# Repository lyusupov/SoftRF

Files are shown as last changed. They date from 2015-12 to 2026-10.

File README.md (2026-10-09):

# SoftRF &nbsp;&nbsp;&nbsp;&nbsp;&nbsp; (https://old.mipt.ru/drec/events/radioDay)
[ ](https://github.com/lyusupov/SoftRF/releases)&nbsp;&nbsp;&nbsp;&nbsp;&nbsp;



DIY, multi-functional, compatible, sub-1 GHz ISM band radio based proximity awareness system for general aviation.

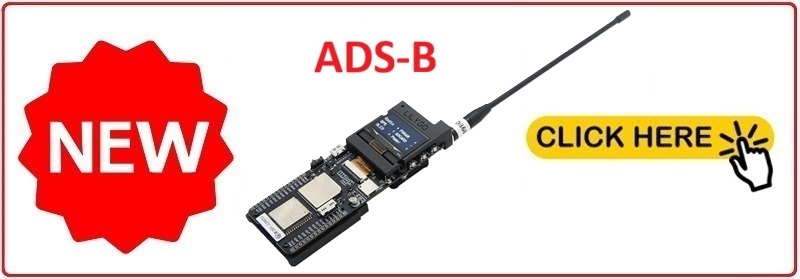
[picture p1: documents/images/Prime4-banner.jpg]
[](https://github.com/lyusupov/SoftRF/wiki/Prime-Edition-MkIV)
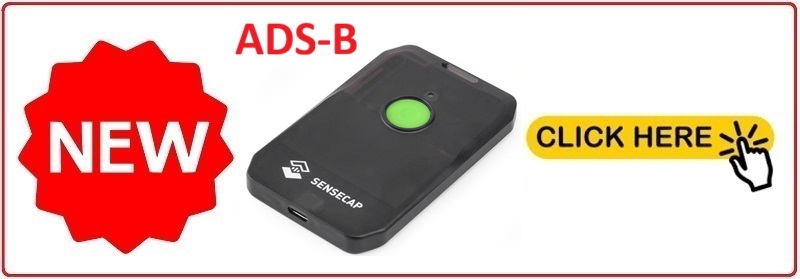
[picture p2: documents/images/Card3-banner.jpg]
[](https://github.com/lyusupov/SoftRF/wiki/Card-Edition-MkIII)
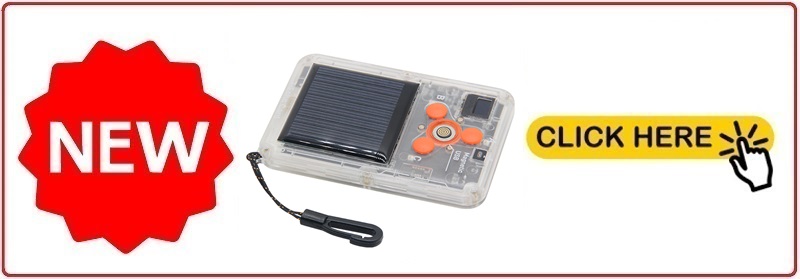
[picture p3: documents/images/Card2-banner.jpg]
[](https://github.com/lyusupov/SoftRF/wiki/Card-Edition-MkII)
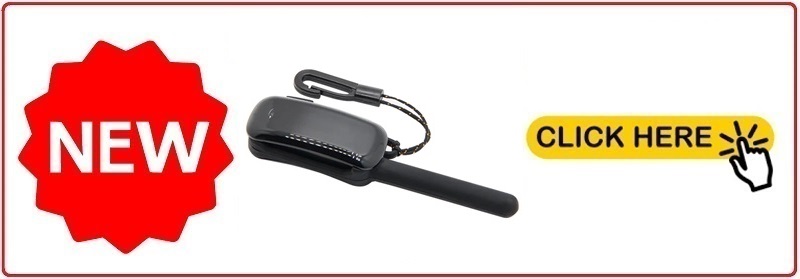
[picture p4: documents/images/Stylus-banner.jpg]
[](https://github.com/lyusupov/SoftRF/wiki/Stylus-Edition)
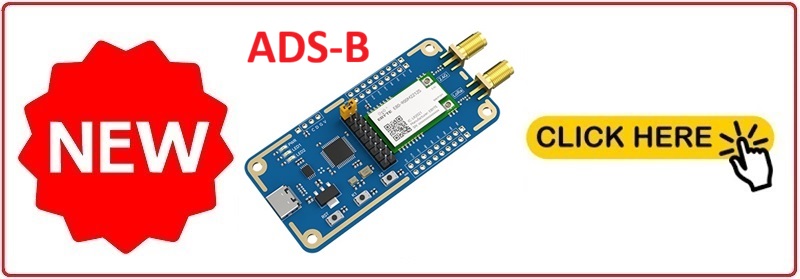
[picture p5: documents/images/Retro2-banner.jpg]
[](https://github.com/lyusupov/SoftRF/wiki/Retro-Edition-MkII)
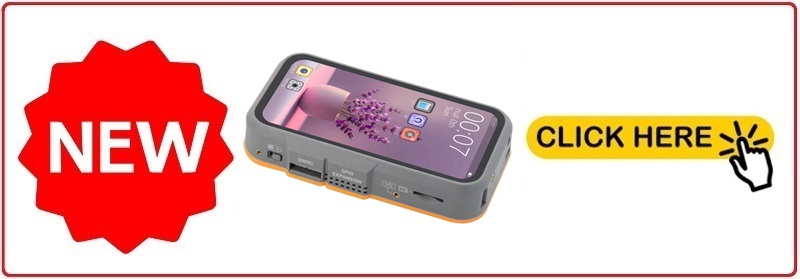
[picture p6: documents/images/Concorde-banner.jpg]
[](https://github.com/lyusupov/SoftRF/wiki/Concorde-Edition)
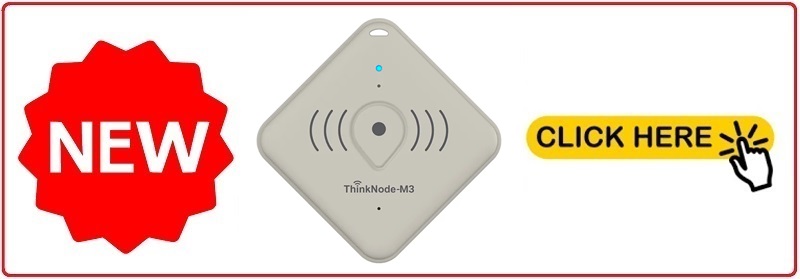
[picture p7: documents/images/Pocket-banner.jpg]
[](https://github.com/lyusupov/SoftRF/wiki/Pocket-Edition)<!--
[<img src="https://github.com/lyusupov/SoftRF/raw/master/documents/images/Airventure-banner.jpg">](https://github.com/lyusupov/SoftRF/wiki/Airventure-Edition)
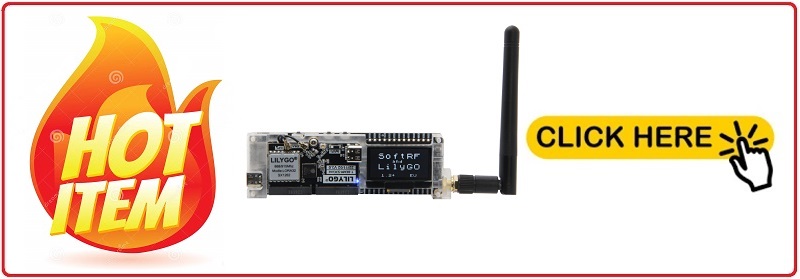
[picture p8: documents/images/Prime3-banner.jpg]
-->[](https://github.com/lyusupov/SoftRF/wiki/Prime-Edition-MkIII)
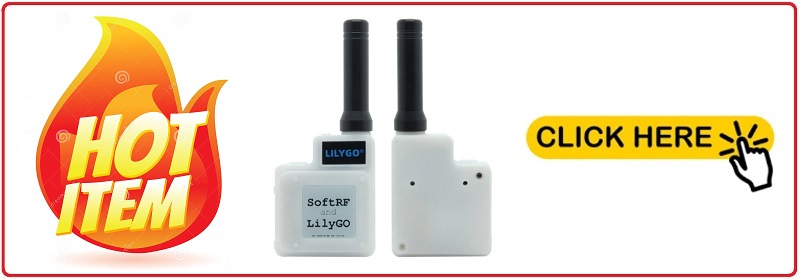
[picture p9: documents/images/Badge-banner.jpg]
[](https://github.com/lyusupov/SoftRF/wiki/Badge-Edition)<!--
[<img src="https://github.com/lyusupov/SoftRF/raw/master/documents/images/Card-banner.jpg">](https://github.com/lyusupov/SoftRF/wiki/Card-Edition)
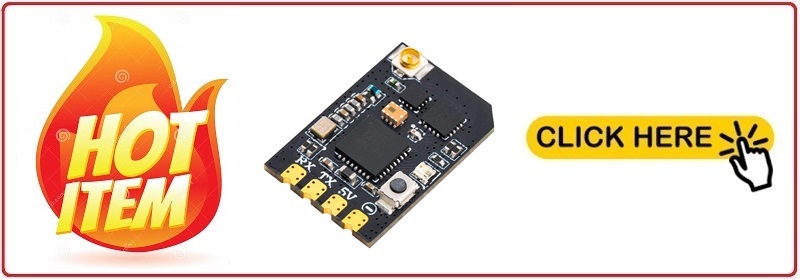
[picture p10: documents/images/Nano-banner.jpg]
-->[](https://github.com/lyusupov/SoftRF/wiki/Nano-Edition)

## Features

* **Wearable**
    * [**Badge Edition**](https://github.com/lyusupov/SoftRF/wiki/Badge-Edition)&nbsp;
    * [**Card  Mark III**](https://github.com/lyusupov/SoftRF/wiki/Card-Edition-MkIII)&nbsp;
    * [**Card  Mark II**](https://github.com/lyusupov/SoftRF/wiki/Card-Edition-MkII)&nbsp;
    * [**Card Edition**](https://github.com/lyusupov/SoftRF/wiki/Card-Edition)&nbsp;
    * [**Stylus Edition**](https://github.com/lyusupov/SoftRF/wiki/Stylus-Edition)&nbsp;
    * [**Pocket Edition**](https://github.com/lyusupov/SoftRF/wiki/Pocket-Edition)&nbsp;
    * [**Bracelet Edition**](https://github.com/lyusupov/SoftRF/wiki/Bracelet-Edition)
* **Plug-and-Play**
    * [**Dongle Edition**](https://github.com/lyusupov/SoftRF/wiki/Dongle-Edition) 
* **Portable**
    * [**Concorde Edition**](https://github.com/lyusupov/SoftRF/wiki/Concorde-Edition)&nbsp;
    * [**Airventure Edition**](https://github.com/lyusupov/SoftRF/wiki/Airventure-Edition)
    * [**Handheld Edition**](https://github.com/lyusupov/SoftRF/wiki/Handheld-Edition)
    * [**Gizmo Edition**](https://github.com/lyusupov/SoftRF/wiki/Gizmo-Edition)
    * [**Prime Mark IV**](https://github.com/lyusupov/SoftRF/wiki/Prime-Edition-MkIV) 
    * [**Prime Mark III**](https://github.com/lyusupov/SoftRF/wiki/Prime-Edition-MkIII) 
    * [**Prime Mark II**](https://github.com/lyusupov/SoftRF/wiki/Prime-Edition-MkII) 
* **Classic** 2.25 inch instrument
    * [**Standalone Edition**](https://github.com/lyusupov/SoftRF/wiki/Standalone-Edition) 
* **Wireless** 2.7 inch E-Ink **display**
    * [**SkyView Pico**](https://github.com/lyusupov/SoftRF/wiki/SkyView-Pico) 
    * [**SkyView EZ**](https://github.com/lyusupov/SoftRF/wiki/SkyView-EZ) 
* **Certified** (CE/FCC)
    * [**Badge Edition**](https://github.com/lyusupov/SoftRF/wiki/Badge-Edition)
    * [**Prime Mark III**](https://github.com/lyusupov/SoftRF/wiki/Prime-Edition-MkIII)
    * [**Card  Mark III**](https://github.com/lyusupov/SoftRF/wiki/Card-Edition-MkIII)&nbsp;
    * [**Solaris Edition**](https://github.com/lyusupov/SoftRF/wiki/Solaris-Edition)&nbsp;
    * [**Pocket Edition**](https://github.com/lyusupov/SoftRF/wiki/Pocket-Edition)&nbsp;
    * [**Handheld Edition**](https://github.com/lyusupov/SoftRF/wiki/Handheld-Edition)
    * [**Prime Mark II**](https://github.com/lyusupov/SoftRF/wiki/Prime-Edition-MkII)
    * [**Uni Edition**](https://github.com/lyusupov/SoftRF/wiki/Uni-Edition)
    * [**Mini Edition**](https://github.com/lyusupov/SoftRF/wiki/Mini-Edition)
    * [**Lego Edition**](https://github.com/lyusupov/SoftRF/wiki/Lego-Edition)
    * [**Balkan Edition**](https://github.com/lyusupov/SoftRF/wiki/Balkan-Edition)
    * [**Card Edition**](https://github.com/lyusupov/SoftRF/wiki/Card-Edition)
* can **receive ADS-B** air traffic
    * 978 UAT
        * [**Uni Edition**](https://github.com/lyusupov/SoftRF/wiki/Uni-Edition)
    * 1090 ES
        * [**ES Edition**](https://github.com/lyusupov/SoftRF/wiki/ES-Edition)
        * [**Concorde Edition**](https://github.com/lyusupov/SoftRF/wiki/Concorde-Edition)&nbsp;
        * [**Prime Mark IV**](https://github.com/lyusupov/SoftRF/wiki/Prime-Edition-MkIV) 
        * [**Card  Mark III**](https://github.com/lyusupov/SoftRF/wiki/Card-Edition-MkIII)&nbsp;
        * [**Retro Mark II**](https://github.com/lyusupov/SoftRF/wiki/Retro-Edition-MkII)&nbsp;
    * 1090 ES and/or 978 UAT
        * [**Raspberry Edition**](https://github.com/lyusupov/SoftRF/wiki/Raspberry-Edition)
* can operate **multiple protocols** at the same time
    * [**Octave Concept**](https://github.com/lyusupov/SoftRF/wiki/Octave-Concept)
    * [**Duo Concept**](https://github.com/lyusupov/SoftRF/wiki/Eco-Edition#duo-concept)
* has **flight recorder**
    * [**Prime Mark III**](https://github.com/lyusupov/SoftRF/wiki/Prime-Edition-MkIII) 
    * [**Flight Recorder**](https://github.com/lyusupov/SoftRF/wiki/Flight-Recorder)
* **Weatherproof**
    * [**Card  Mark III**](https://github.com/lyusupov/SoftRF/wiki/Card-Edition-MkIII)&nbsp; - IP66
    * [**Card  Mark II**](https://github.com/lyusupov/SoftRF/wiki/Card-Edition-MkII)&nbsp; - IP66
    * [**Card Edition**](https://github.com/lyusupov/SoftRF/wiki/Card-Edition)&nbsp; - IP65
    * [**Solaris Edition**](https://github.com/lyusupov/SoftRF/wiki/Solaris-Edition)&nbsp; - IP65
    * [**Pocket Edition**](https://github.com/lyusupov/SoftRF/wiki/Pocket-Edition)&nbsp; - IP66
    * [**Lego Edition**](https://github.com/lyusupov/SoftRF/wiki/Lego-Edition) - IP67
* **UAV** add-on
    * [**Nano Edition**](https://github.com/lyusupov/SoftRF/wiki/Nano-Edition)&nbsp;
    * [**UAV Edition**](https://github.com/lyusupov/SoftRF/wiki/UAV-Edition)
* Raspberry Pi **friendly**
    * [**Raspberry Edition**](https://github.com/lyusupov/SoftRF/wiki/Raspberry-Edition)
    * [**SkyView Pi**](https://github.com/lyusupov/SoftRF/wiki/SkyView-Pi)
* for **education** purpose
    * [**Academy Edition**](https://github.com/lyusupov/SoftRF/wiki/Academy-Edition) 
* for **amateur radio** operators
    * [**Ham Edition**](https://github.com/lyusupov/SoftRF/wiki/Ham-Edition)
* **made in** EU
    * [**Balkan Edition**](https://github.com/lyusupov/SoftRF/wiki/Balkan-Edition)

<br>

<!--
* 2-way raw data bridge between 868/915 MHz radio band and Wi-Fi ;
* standalone, battery powered, compatible proximity awareness instrument that fits typical 2.25 inches hole ;
* lightweight version to carry onboard of an UAV.
-->

<!--
[<img src="https://user-images.githubusercontent.com/5849637/128593239-cf30ef4c-1761-4dc1-874a-2be9eaacab77.jpg">](https://github.com/lyusupov/SoftRF/wiki/Badge-Edition)
-->

# Compatibility <sup>1</sup>
Type|Protocol|FLARM|OGN tracker|PilotAware|Skytraxx|SoftRF
---|---|---|---|---|---|---
Radio|FLARM AIR V7||||<p align="center"><sup>2</sup></p>|
&nbsp;|<p align="center">OGNTP</p>|||||<p align="center"><sup>3</sup></p>
&nbsp;|<p align="center">P3I</p>|||||<p align="center"><sup>3</sup></p>
&nbsp;|<p align="center">FANET+</p>|||||<p align="center"><sup>3</sup></p>
&nbsp;|<p align="center">978&nbsp;UAT<br>ADS-B</p>|||||<p align="center"><sup>4</sup></p>
&nbsp;|<p align="center">1090&nbsp;ES<br>ADS-B</p>|||<p align="center"><sup>5</sup></p>||<p align="center"><sup>5</sup></p>
&nbsp;|<p align="center">SRD&nbsp;860<br>ADS-L</p>|||||
&nbsp;|<p align="center">APRS</p>|||||<p align="center"><sup>6</sup></p>
&nbsp;|<p align="center">Remote ID</p>|||||<p align="center">
Data|FLARM NMEA|||||
&nbsp;|Garmin GDL90|||||
&nbsp;|<p align="center">MAVLINK</p>|||||
&nbsp;|<p align="center">Dump1090 &nbsp;<sup>7</sup></p>|||||

<sup>1</sup> - it is necessary for a reader to distinguish the difference between statement "**compatible**" and statement "**fully compatible**".<br>
&nbsp;&nbsp;&nbsp;&nbsp; SoftRF implements only a reasonable minimum of the protocols specs. No "bells and whistles" so far.<br>
<sup>2</sup> - FANET+ can not receive FLARM. However it is able to transmit it.<br>
<sup>3</sup> - valid for [**Prime Mark III**](https://github.com/lyusupov/SoftRF/wiki/Prime-Edition-MkIII) , [**Prime Mark II**](https://github.com/lyusupov/SoftRF/wiki/Prime-Edition-MkII) , [**Dongle**](https://github.com/lyusupov/SoftRF/wiki/Dongle-Edition) , [**Mini**](https://github.com/lyusupov/SoftRF/wiki/Mini-Edition) , [**Badge**](https://github.com/lyusupov/SoftRF/wiki/Badge-Edition) , [**Bracelet**](https://github.com/lyusupov/SoftRF/wiki/Bracelet-Edition) , [**Academy**](https://github.com/lyusupov/SoftRF/wiki/Academy-Edition) , [**Octave**](https://github.com/lyusupov/SoftRF/wiki/Octave-Concept) , [**Lego**](https://github.com/lyusupov/SoftRF/wiki/Lego-Edition) , [**Balkan**](https://github.com/lyusupov/SoftRF/wiki/Balkan-Edition) , [**Midi**](https://github.com/lyusupov/SoftRF/wiki/Midi-Edition) , [**Eco**](https://github.com/lyusupov/SoftRF/wiki/Eco-Edition) , [**Card**](https://github.com/lyusupov/SoftRF/wiki/Card-Edition) , [**Cozy**](https://github.com/lyusupov/SoftRF/wiki/Cozy-Edition) , [**Handheld**](https://github.com/lyusupov/SoftRF/wiki/Handheld-Edition) , [**Gizmo**](https://github.com/lyusupov/SoftRF/wiki/Gizmo-Edition) , [**Nano**](https://github.com/lyusupov/SoftRF/wiki/Nano-Edition) , [**Airventure**](https://github.com/lyusupov/SoftRF/wiki/Airventure-Edition) , [**Solaris**](https://github.com/lyusupov/SoftRF/wiki/Solaris-Edition) , [**Pocket**](https://github.com/lyusupov/SoftRF/wiki/Pocket-Edition) , [**Labubu**](https://github.com/lyusupov/SoftRF/wiki/Labubu-Edition) and [**Concorde**](https://github.com/lyusupov/SoftRF/wiki/Concorde-Edition) **Editions** ; valid for [**Standalone**](https://github.com/lyusupov/SoftRF/wiki/Standalone-Edition) , [**UAV**](https://github.com/lyusupov/SoftRF/wiki/UAV-Edition) and [**Uni**](https://github.com/lyusupov/SoftRF/wiki/Uni-Edition) **Editions** with optional DIY [SoftRF LoRa RF module](https://github.com/lyusupov/SoftRF/wiki/SoftRF-LoRa-module)<br>
<sup>4</sup> - [**Reception**](https://github.com/lyusupov/SoftRF/wiki/Uni-Edition#ads-b-out-remark) of traffic 'downlink' frames only. Valid for [**Uni Edition**](https://github.com/lyusupov/SoftRF/wiki/Uni-Edition) alone and for [**Standalone Edition**](https://github.com/lyusupov/SoftRF/wiki/Standalone-Edition) with optional DIY [SoftRF UAT module](https://github.com/lyusupov/UAT-test-signal#variant-2-advanced)<br>
<sup>5</sup> - Reception of traffic 'downlink' frames only. Valid for [**ES Edition**](https://github.com/lyusupov/SoftRF/wiki/ES-Edition)<br>
<sup>6</sup> - APRS is the only available with [**Ham Edition**](https://github.com/lyusupov/SoftRF/wiki/Ham-Edition)<br>
<sup>7</sup> - also known as "raw ADS-B"<br>

# Models
## By Processing Unit
Model(s)|Platform|First appearance|&nbsp;&nbsp;&nbsp;&nbsp;&nbsp;&nbsp;&nbsp;Status&nbsp;&nbsp;&nbsp;&nbsp;&nbsp;&nbsp;&nbsp;|Notes
---|:---:|:---:|:---:|---
1&nbsp;[Prime](https://github.com/lyusupov/SoftRF/wiki/Prime-Edition)<br>2&nbsp;[Standalone](https://github.com/lyusupov/SoftRF/wiki/Standalone-Edition)<br>3&nbsp;[UAV](https://github.com/lyusupov/SoftRF/wiki/UAV-Edition)<br>4&nbsp;[**WebTop&nbsp;Serial**](https://github.com/lyusupov/SoftRF/wiki/WebTop-Serial-adapter)|[Espressif<br>ESP8266](https://en.wikipedia.org/wiki/ESP8266)|Q4 2015|<!-- ![](https://via.placeholder.com/140x70/00A000/000000?text=Good) -->|[Prime](https://github.com/lyusupov/SoftRF/wiki/Prime-Edition) model is no longer supported - use [Prime MkII](https://github.com/lyusupov/SoftRF/wiki/Prime-Edition-MkII) instead.<br><!-- ESP8266 platform will be phased out through year 2020 in favour of ESP32.-->
1&nbsp;[**Prime Mark II**](https://github.com/lyusupov/SoftRF/wiki/Prime-Edition-MkII)<br>2&nbsp;[**Standalone**](https://github.com/lyusupov/SoftRF/wiki/Standalone-Edition) + [adapter](https://github.com/lyusupov/ESP32-NODEMCU-ADAPTER)<br>3&nbsp;[UAV](https://github.com/lyusupov/SoftRF/wiki/UAV-Edition)<br>4&nbsp;[**SkyView EZ**](https://github.com/lyusupov/SoftRF/wiki/SkyView-EZ)<br>5&nbsp;[Flight Recorder](https://github.com/lyusupov/SoftRF/wiki/Flight-Recorder)|[Espressif<br>ESP32](https://en.wikipedia.org/wiki/ESP32)|Q1 2018||1&nbsp;today's best platform ;<br>2&nbsp;holds [**FCC** mark](https://github.com/lyusupov/SoftRF/wiki/Prime-Edition-MkII#certificates)
1&nbsp;[**Raspberry Edition**](https://github.com/lyusupov/SoftRF/wiki/Raspberry-Edition)<br>2&nbsp;[**SkyView Pi**](https://github.com/lyusupov/SoftRF/wiki/SkyView-Pi)|[Broadcom<br>BCM283X<br>(Raspberry Pi)](https://en.wikipedia.org/wiki/Raspberry_Pi)|Q4 2018||Good for use together with RTL-SDR dongles to achieve additional 1090ES (and 978UAT) ADS-B air traffic reception.
[UAT module](https://github.com/lyusupov/UAT-test-signal#variant-2-advanced)|[Texas Instruments<br>CC1310](http://www.ti.com/product/CC1310)|Q1 2019|<!-- ![](https://via.placeholder.com/140x70/FFFF00/000000?text=In+progress) -->|Unique RF radio specs are useful for [UAT978 **ADS-B** reception](https://github.com/lyusupov/SoftRF/tree/master/software/firmware/source/UATbridge) [ [1](https://raw.githubusercontent.com/lyusupov/SoftRF/master/documents/images/uat-normal-7.jpg) , [2](https://raw.githubusercontent.com/lyusupov/SoftRF/master/documents/images/uat-normal-8.jpg) , [3](https://raw.githubusercontent.com/lyusupov/SoftRF/master/documents/images/uat-normal-6.jpg) ]
1&nbsp;[Retro](https://github.com/lyusupov/SoftRF/wiki/Retro-Edition)<br>2&nbsp;[**Dongle**](https://github.com/lyusupov/SoftRF/wiki/Dongle-Edition)<br>3&nbsp;[**Bracelet**](https://github.com/lyusupov/SoftRF/wiki/Bracelet-Edition)<br>4&nbsp;[**Retro Mark II**](https://github.com/lyusupov/SoftRF/wiki/Retro-Edition-MkII)&nbsp;|[STMicroelectronics](https://en.wikipedia.org/wiki/STMicroelectronics)<br>[STM32**F103**](https://www.st.com/en/microcontrollers-microprocessors/stm32f103.html) and<br>[STM32**L073**](https://www.st.com/en/microcontrollers-microprocessors/stm32l073rz.html)|Q3 2019|<!-- ![](https://via.placeholder.com/140x70/FFFF00/000000?text=In+progress)-->|<!-- [AcSiP **S76G**](http://www.acsip.com.tw/index.php?action=products-detail&fid1=19&fid2=&fid3=&id=41&lang=3) "3-in-1" system-in-package is doing good [ [1](https://raw.githubusercontent.com/lyusupov/SoftRF/master/documents/images/watch-1.jpg) , [2](https://raw.githubusercontent.com/lyusupov/SoftRF/master/documents/images/t-motion-4.jpg) , [3](https://raw.githubusercontent.com/lyusupov/SoftRF/master/documents/images/t-motion-5.jpg) ] .<br>As well as STM32F103C8 "**Blue Pill**" (same MCU that [STM32 OGN tracker](http://wiki.glidernet.org/stm32-ogn-tracker) uses) [ [4](https://raw.githubusercontent.com/lyusupov/SoftRF/master/documents/images/stm32_breadboard.jpg) , [5](https://raw.githubusercontent.com/lyusupov/SoftRF/master/documents/images/stm32_ognweb_1.JPG) ] . -->
[**Uni**](https://github.com/lyusupov/SoftRF/wiki/Uni-Edition)|[Texas Instruments<br>CC13x2R](http://www.ti.com/product/CC1352R)|Q2 2020|<!-- ![](https://via.placeholder.com/140x70/FFFF00/000000?text=In+progress) -->|1&nbsp;Unique RF radio specs are useful for UAT978 **ADS-B** reception ; <br>2&nbsp;holds [**FCC/CE** mark](https://github.com/lyusupov/SoftRF/wiki/Uni-Edition#certificates)
[**Mini**](https://github.com/lyusupov/SoftRF/wiki/Mini-Edition)|[Cypress<br>PSoC 4100**S**](https://en.wikipedia.org/wiki/Cypress_PSoC)|Q3 2020|<!-- ![](https://via.placeholder.com/140x40/c5f015/000000?text=May+need)<br>![](https://via.placeholder.com/140x40/c5f015/000000?text=improvements) -->|1&nbsp;good add-on candidate for modded Kobo e-Readers ;<br>2&nbsp;holds [**FCC/CE** mark](https://github.com/lyusupov/SoftRF/wiki/Mini-Edition#certificates)
1&nbsp;[**Badge**](https://github.com/lyusupov/SoftRF/wiki/Badge-Edition)<br>2&nbsp;[**Card**](https://github.com/lyusupov/SoftRF/wiki/Card-Edition)&nbsp;<br>3&nbsp;[**Cozy**](https://github.com/lyusupov/SoftRF/wiki/Cozy-Edition)<br>4&nbsp;[**Handheld**](https://github.com/lyusupov/SoftRF/wiki/Handheld-Edition)<br>5&nbsp;[**Solaris**](https://github.com/lyusupov/SoftRF/wiki/Solaris-Edition)&nbsp;<br>6&nbsp;[**Pocket**](https://github.com/lyusupov/SoftRF/wiki/Pocket-Edition)&nbsp;<br>7&nbsp;[**Card  Mark II**](https://github.com/lyusupov/SoftRF/wiki/Card-Edition-MkII)&nbsp;<br>8&nbsp;[**Card  Mark III**](https://github.com/lyusupov/SoftRF/wiki/Card-Edition-MkIII)&nbsp;<br>9&nbsp;[**Stylus**](https://github.com/lyusupov/SoftRF/wiki/Stylus-Edition)&nbsp;|[Nordic Semiconductor<br>nRF52840](https://www.nordicsemi.com/Products/Low-power-short-range-wireless/nRF52840)|Q4 2020||&nbsp;holds [**FCC/CE** mark](https://github.com/lyusupov/SoftRF/wiki/Badge-Edition#certificates)
[**ES**](https://github.com/lyusupov/SoftRF/wiki/ES-Edition)|[NXP Semiconductors<br>LPC4320](https://en.wikipedia.org/wiki/NXP_LPC#LPC4000_series)|Q2 2021||Unique RF radio specs are useful for 1090ES **ADS-B** reception [ [1](https://user-images.githubusercontent.com/5849637/140610617-7c74582e-b0d7-4610-8ac2-d51f55c9086d.png) , [2](https://raw.githubusercontent.com/lyusupov/SoftRF/master/documents/images/ES-1.jpg) ]
1&nbsp;[**Academy**](https://github.com/lyusupov/SoftRF/wiki/Academy-Edition)<br>2&nbsp;[USB2BT](https://github.com/lyusupov/SoftRF/wiki/USB-to-Bluetooth-adapter)|[Microchip&nbsp;(Atmel)<br>SAM&nbsp;D21](https://www.microchip.com/en-us/products/microcontrollers-and-microprocessors/32-bit-mcus/sam-32-bit-mcus/sam-d) <!-- and [ATmega2560](https://www.microchip.com/en-us/product/ATmega2560) -->|Q4 2021| <!-- ![](https://via.placeholder.com/140x40/c5f015/000000?text=May+need)<br>![](https://via.placeholder.com/140x40/c5f015/000000?text=improvements) -->|good for teaching students of air traffic proximity awareness
[**Octave**](https://github.com/lyusupov/SoftRF/wiki/Octave-Concept)|[ASR Microelectronics<br>ASR6601](https://asriot.readthedocs.io/en/latest/ASR6601/index.html)|Q1 2022|| **the best 'price per radio protocol' ratio** on the market
1&nbsp;[**Lego**](https://github.com/lyusupov/SoftRF/wiki/Lego-Edition)<br>2&nbsp;[**SkyView Pico**](https://github.com/lyusupov/SoftRF/wiki/SkyView-Pico)|[Raspberry Pi<br>Foundation<br>**RP2040**](https://en.wikipedia.org/wiki/RP2040)|Q1 2022||&nbsp;holds [**FCC/CE** mark](https://github.com/lyusupov/SoftRF/wiki/Lego-Edition#certificates)
[**Balkan**](https://github.com/lyusupov/SoftRF/wiki/Balkan-Edition)|[STMicroelectronics](https://en.wikipedia.org/wiki/STMicroelectronics)<br>[STM32**WLE5**](https://www.st.com/en/microcontrollers-microprocessors/stm32wle5cc.html)|Q3 2022||&nbsp;holds [**CE** mark](https://github.com/lyusupov/SoftRF/wiki/Balkan-Edition#certificates)
[**WebTop USB**](https://github.com/lyusupov/SoftRF/wiki/WebTop-USB)|[Espressif<br>ESP32-S2](https://en.wikipedia.org/wiki/ESP32#ESP32-S2)|Q4 2022||
1&nbsp;[**Standalone**](https://github.com/lyusupov/SoftRF/wiki/Standalone-Edition)&nbsp;**upgrade**<br>2&nbsp;[**Nano**](https://github.com/lyusupov/SoftRF/wiki/Nano-Edition)&nbsp;|[Espressif<br>ESP32-C3](https://en.wikipedia.org/wiki/ESP32#ESP32-C3)|Q1 2023||[RISC-V](https://en.wikipedia.org/wiki/RISC-V)
1&nbsp;[**Prime Mark III**](https://github.com/lyusupov/SoftRF/wiki/Prime-Edition-MkIII)&nbsp;<br>2&nbsp;[**SkyView Pico**](https://github.com/lyusupov/SoftRF/wiki/SkyView-Pico#alternative-hardware-option)<br>3&nbsp;[**Ham**](https://github.com/lyusupov/SoftRF/wiki/Ham-Edition)<br>4&nbsp;[**Midi**](https://github.com/lyusupov/SoftRF/wiki/Midi-Edition)<br>5&nbsp;[**Gizmo**](https://github.com/lyusupov/SoftRF/wiki/Gizmo-Edition)<br>6&nbsp;[**Airventure**](https://github.com/lyusupov/SoftRF/wiki/Airventure-Edition)<br>7&nbsp;[**Prime Mark IV**](https://github.com/lyusupov/SoftRF/wiki/Prime-Edition-MkIV)&nbsp;|[Espressif<br>ESP32-S3](https://en.wikipedia.org/wiki/ESP32#ESP32-S3)|Q1 2023||
1&nbsp;[**Standalone**](https://github.com/lyusupov/SoftRF/wiki/Standalone-Edition)&nbsp;**upgrade**<br>2&nbsp;[**Eco**](https://github.com/lyusupov/SoftRF/wiki/Eco-Edition)<br>3&nbsp;[**Duo**](https://github.com/lyusupov/SoftRF/wiki/Eco-Edition#duo-concept)|[Espressif<br>ESP32-C6](https://en.wikipedia.org/wiki/ESP32#ESP32-C6)|Q1 2024||2 [RISC-V](https://en.wikipedia.org/wiki/RISC-V) cores<br>big.LITTLE
[**Academy**](https://github.com/lyusupov/SoftRF/wiki/Academy-Edition)&nbsp; **upgrade**|[Renesas<br>RA4M1](https://en.wikipedia.org/wiki/Renesas_Electronics#The_RA_MCU_family)|Q1 2024||
Academy|[Silicon Labs](https://en.wikipedia.org/wiki/Silicon_Labs)<br>[EFx32](https://en.wikipedia.org/wiki/EFM32)|Q3 2024||
Academy|[Nanjing Qinheng Microelectronics](https://www.wch-ic.com/)<br>[CH32V307](https://www.wch-ic.com/products/CH32V307.html)|Q3 2024||[RISC-V](https://en.wikipedia.org/wiki/RISC-V)<br>IMAFC
1&nbsp;[**Standalone**](https://github.com/lyusupov/SoftRF/wiki/Standalone-Edition)&nbsp;**upgrade**<br>2&nbsp;[**SkyView Pico**](https://github.com/lyusupov/SoftRF/wiki/SkyView-Pico)&nbsp;|[Raspberry Pi<br>Foundation<br>**RP2350**](https://en.wikipedia.org/wiki/RP2350)|Q1 2025||
1&nbsp;[**Standalone**](https://github.com/lyusupov/SoftRF/wiki/Standalone-Edition)&nbsp;**upgrade**<br>2&nbsp;[**Lyra**](https://github.com/lyusupov/SoftRF/wiki/Lyra-Edition)&nbsp;|[Rockchip](https://en.wikipedia.org/wiki/Rockchip)<br>RK3506|Q3 2025||
[**Concorde**](https://github.com/lyusupov/SoftRF/wiki/Concorde-Edition)&nbsp;|[Espressif<br>ESP32-P4](https://en.wikipedia.org/wiki/ESP32#ESP32-P4)|Q3 2025||
**Academy**|[Espressif<br>ESP32-C5](https://en.wikipedia.org/wiki/ESP32#ESP32-C5)|Q3 2025||
[**Labubu**](https://github.com/lyusupov/SoftRF/wiki/Labubu-Edition)|[STMicroelectronics](https://en.wikipedia.org/wiki/STMicroelectronics)<br>[STM32**WL55**](https://www.st.com/en/microcontrollers-microprocessors/stm32wl55cc.html)|Q4 2025||
**Academy**|[Nordic Semiconductor<br>nRF54L15](https://www.nordicsemi.com/Products/nRF54L15)|Q1 2026||

## By sub-1 GHz radio
Radio|Model(s)|First appearance|&nbsp;&nbsp;&nbsp;&nbsp;&nbsp;&nbsp;&nbsp;Status&nbsp;&nbsp;&nbsp;&nbsp;&nbsp;&nbsp;&nbsp;|Notes
---|:---:|:---:|:---:|---
[Nordic Semiconductor<br>nRF905](https://infocenter.nordicsemi.com/pdf/nRF905_PS_v1.5.pdf)|1&nbsp;[Prime](https://github.com/lyusupov/SoftRF/wiki/Prime-Edition)<br>2&nbsp;[Standalone](https://github.com/lyusupov/SoftRF/wiki/Standalone-Edition)<br>3&nbsp;[UAV](https://github.com/lyusupov/SoftRF/wiki/UAV-Edition)|Q4 2015||&nbsp;
[Semtech<br>SX1276](https://www.semtech.com/products/wireless-rf/lora-transceivers/sx1276)|1&nbsp;[LoRa module](https://github.com/lyusupov/SoftRF/wiki/SoftRF-LoRa-module)<br>2&nbsp;[**Prime Mark II**](https://github.com/lyusupov/SoftRF/wiki/Prime-Edition-MkII)<br>3&nbsp;[**Raspberry Edition**](https://github.com/lyusupov/SoftRF/wiki/Raspberry-Edition)<br>4&nbsp;[**Dongle**](https://github.com/lyusupov/SoftRF/wiki/Dongle-Edition)<br>5&nbsp;[**Academy**](https://github.com/lyusupov/SoftRF/wiki/Academy-Edition)<!-- <br>5&nbsp;[**Bracelet**](https://github.com/lyusupov/SoftRF/wiki/Bracelet-Edition) -->|Q4 2017||&nbsp;
[Texas Instruments<br>CC1310](http://www.ti.com/product/CC1310)|[UAT module](https://github.com/lyusupov/UAT-test-signal#variant-2-advanced)|Q1 2019||&nbsp;
[Semtech<br>SX1231](https://www.semtech.com/products/wireless-rf/fsk-transceivers/sx1231)|[Retro](https://github.com/lyusupov/SoftRF/wiki/Retro-Edition)|Q3 2019||operates through OGN driver with OGNTP protocol only
[Semtech<br>SX1262](https://www.semtech.com/products/wireless-rf/lora-transceivers/sx1262)|1&nbsp;[**Prime Mark II**](https://github.com/lyusupov/SoftRF/wiki/Prime-Edition-MkII)<br>2&nbsp;[**Mini**](https://github.com/lyusupov/SoftRF/wiki/Mini-Edition)<br>3&nbsp;[**Badge**](https://github.com/lyusupov/SoftRF/wiki/Badge-Edition)<br>4&nbsp;[**Lego**](https://github.com/lyusupov/SoftRF/wiki/Lego-Edition)<br>5&nbsp;[**Balkan**](https://github.com/lyusupov/SoftRF/wiki/Balkan-Edition)<br>6&nbsp;[**Prime Mark III**](https://github.com/lyusupov/SoftRF/wiki/Prime-Edition-MkIII)<br>7&nbsp;[**Midi**](https://github.com/lyusupov/SoftRF/wiki/Midi-Edition)<br>8&nbsp;[**Cozy**](https://github.com/lyusupov/SoftRF/wiki/Cozy-Edition)<br>9&nbsp;[**Handheld**](https://github.com/lyusupov/SoftRF/wiki/Handheld-Edition)<br>10&nbsp;[**Gizmo**](https://github.com/lyusupov/SoftRF/wiki/Gizmo-Edition)<br>11&nbsp;[**Airventure**](https://github.com/lyusupov/SoftRF/wiki/Airventure-Edition)<br>12&nbsp;[**Lyra**](https://github.com/lyusupov/SoftRF/wiki/Lyra-Edition)&nbsp;<br>13&nbsp;[**Solaris**](https://github.com/lyusupov/SoftRF/wiki/Solaris-Edition)&nbsp;<br>14&nbsp;[**Concorde**](https://github.com/lyusupov/SoftRF/wiki/Concorde-Edition)&nbsp;<br>15&nbsp;[**Stylus**](https://github.com/lyusupov/SoftRF/wiki/Stylus-Edition)&nbsp;<br>16&nbsp;[**Card  Mark II**](https://github.com/lyusupov/SoftRF/wiki/Card-Edition-MkII)&nbsp;|Q1 2020||&nbsp;
[Texas Instruments<br>CC13x2R](http://www.ti.com/product/CC1352R)|[**Uni Edition**](https://github.com/lyusupov/SoftRF/wiki/Uni-Edition)|Q2 2020||&nbsp;
[Maxim Integrated](https://en.wikipedia.org/wiki/Maxim_Integrated)<br>[MAX2837](https://www.maximintegrated.com/en/products/comms/wireless-rf/MAX2837.html)&nbsp;and<br>[MAX5864](https://www.maximintegrated.com/en/products/analog/data-converters/analog-front-end-ics/MAX5864.html)|[**ES Edition**](https://github.com/lyusupov/SoftRF/wiki/ES-Edition)|Q2 2021||**S**oftware<br>**D**efined<br>**R**adio
[NiceRF](https://www.nicerf.com)<br>[SA868](https://www.nicerf.com/item/2w-embedded-walkie-talkie-module-sa868)|[**Ham Edition**](https://github.com/lyusupov/SoftRF/wiki/Ham-Edition)|Q3 2023||VHF or UHF "Ham Radio" bands
[Semtech<br>LR1110](https://www.semtech.com/products/wireless-rf/lora-edge/lr1110)|1&nbsp;[**Card**](https://github.com/lyusupov/SoftRF/wiki/Card-Edition)&nbsp;<br>2&nbsp;[**Pocket**](https://github.com/lyusupov/SoftRF/wiki/Pocket-Edition)&nbsp;|Q3 2024||&nbsp;
[Semtech<br>LR1121](https://www.semtech.com/products/wireless-rf/lora-connect/lr1121)&nbsp;|1&nbsp;[**Standalone**](https://github.com/lyusupov/SoftRF/wiki/Standalone-Edition)<br>2&nbsp;[**Prime Mark III**](https://github.com/lyusupov/SoftRF/wiki/Prime-Edition-MkIII)<br>3&nbsp;[**Nano**](https://github.com/lyusupov/SoftRF/wiki/Nano-Edition)&nbsp;|Q4 2024||2.1&nbsp;GHz&nbsp;S-band<br>2.4&nbsp;GHz&nbsp;ISM
Semtech&nbsp;SX1231<br><!--Semtech&nbsp;SX1280<br>-->TI&nbsp;CC1101<br>Silicon&nbsp;Labs&nbsp;Si4432<br>Silicon&nbsp;Labs&nbsp;Si4463|[**Standalone**](https://github.com/lyusupov/SoftRF/wiki/Standalone-Edition)|Q1 2025||&nbsp;
[Semtech<br>LR2021](https://www.semtech.com/products/wireless-rf/lora-plus/lr2021)&nbsp;|1&nbsp;[**Standalone**](https://github.com/lyusupov/SoftRF/wiki/Standalone-Edition)<br>2&nbsp;[**Retro Mark II**](https://github.com/lyusupov/SoftRF/wiki/Retro-Edition-MkII)&nbsp;<br>3&nbsp;[**Card  Mark III**](https://github.com/lyusupov/SoftRF/wiki/Card-Edition-MkIII)&nbsp;<br>4&nbsp;[**Prime Mark IV**](https://github.com/lyusupov/SoftRF/wiki/Prime-Edition-MkIV)&nbsp;|Q1 2026||[the radio can receive ADS-B @ 1090 MHz](https://github.com/lyusupov/SoftRF/wiki/SoftRF-LoRa-module#upgrade-with-most-recent-semtech-lr2021-radio)&nbsp;

## By GNSS chip
GNSS|Model(s)|First appearance|&nbsp;&nbsp;&nbsp;&nbsp;&nbsp;&nbsp;&nbsp;Status&nbsp;&nbsp;&nbsp;&nbsp;&nbsp;&nbsp;&nbsp;|Notes
---|:---:|:---:|:---:|---
Generic<br>NMEA|[Standalone](https://github.com/lyusupov/SoftRF/wiki/Standalone-Edition)|Q4 2016||&nbsp;
[U-blox](https://en.wikipedia.org/wiki/U-blox)<br>6/7/8/9/10|1&nbsp;[**Prime Mark II**](https://github.com/lyusupov/SoftRF/wiki/Prime-Edition-MkII)<br>2&nbsp;[Retro](https://github.com/lyusupov/SoftRF/wiki/Retro-Edition)<br>3&nbsp;[**Uni**](https://github.com/lyusupov/SoftRF/wiki/Uni-Edition)<br>4&nbsp;[**Lego**](https://github.com/lyusupov/SoftRF/wiki/Lego-Edition)<br>5&nbsp;[**Balkan**](https://github.com/lyusupov/SoftRF/wiki/Balkan-Edition)<br>6&nbsp;[**Prime Mark III**](https://github.com/lyusupov/SoftRF/wiki/Prime-Edition-MkIII)<br>7&nbsp;[**Stylus**](https://github.com/lyusupov/SoftRF/wiki/Stylus-Edition)&nbsp;|Q2 2018||&nbsp;
[Hangzhou ZhongKe](http://www.icofchina.com/)<br>AT6558|1&nbsp;[**Prime Mark II**](https://github.com/lyusupov/SoftRF/wiki/Prime-Edition-MkII)<br>2&nbsp;[**Mini**](https://github.com/lyusupov/SoftRF/wiki/Mini-Edition)<br>3&nbsp;[**Badge**](https://github.com/lyusupov/SoftRF/wiki/Badge-Edition)<br>4&nbsp;[**Prime Mark III**](https://github.com/lyusupov/SoftRF/wiki/Prime-Edition-MkIII)<br>5&nbsp;[**Ham**](https://github.com/lyusupov/SoftRF/wiki/Ham-Edition)<br>6&nbsp;[**Cozy**](https://github.com/lyusupov/SoftRF/wiki/Cozy-Edition)<br>7&nbsp;[**Handheld**](https://github.com/lyusupov/SoftRF/wiki/Handheld-Edition)<br>8&nbsp;[**Airventure**](https://github.com/lyusupov/SoftRF/wiki/Airventure-Edition)<br>9&nbsp;[**Lyra**](https://github.com/lyusupov/SoftRF/wiki/Lyra-Edition)&nbsp;<br>10&nbsp;[**Solaris**](https://github.com/lyusupov/SoftRF/wiki/Solaris-Edition)&nbsp;<br>11&nbsp;[**Pocket**](https://github.com/lyusupov/SoftRF/wiki/Pocket-Edition)&nbsp;<br>12&nbsp;[**Concorde**](https://github.com/lyusupov/SoftRF/wiki/Concorde-Edition)&nbsp;<br>13&nbsp;[**Card  Mark II**](https://github.com/lyusupov/SoftRF/wiki/Card-Edition-MkII)&nbsp;<br>14&nbsp;[**Prime Mark IV**](https://github.com/lyusupov/SoftRF/wiki/Prime-Edition-MkIV)&nbsp;|Q2 2019||&nbsp;
[Sony<br>CXD5603GF](https://www.sony-semicon.co.jp/e/products/lsi/gps/product.html)|1&nbsp;[**Dongle**](https://github.com/lyusupov/SoftRF/wiki/Dongle-Edition)<!-- <br>2&nbsp;[**Bracelet**](https://github.com/lyusupov/SoftRF/wiki/Bracelet-Edition) -->|Q4 2019||&nbsp;
[MediaTek](https://en.wikipedia.org/wiki/MediaTek)<br>MT3339|1&nbsp;[**Raspberry**](https://github.com/lyusupov/SoftRF/wiki/Raspberry-Edition)<br>2&nbsp;[**Uni**](https://github.com/lyusupov/SoftRF/wiki/Uni-Edition)<br>3&nbsp;[**Academy**](https://github.com/lyusupov/SoftRF/wiki/Academy-Edition)<br>4&nbsp;[**Lego**](https://github.com/lyusupov/SoftRF/wiki/Lego-Edition)|Q3 2020||&nbsp;
[GOKE](http://www.goke.com/en/)<br>GK9501|[**Mini**](https://github.com/lyusupov/SoftRF/wiki/Mini-Edition)|Q3 2020||&nbsp;
[UniCore](https://en.unicorecomm.com/)<br>[UC6580](https://en.unicorecomm.com/products/detail/34)|[**Midi**](https://github.com/lyusupov/SoftRF/wiki/Midi-Edition)|Q3 2023||&nbsp;
[Airoha](https://www.airoha.com/about)<br>[AG3335](https://www.airoha.com/products/p/A0Dmm0pijWW3MScb)|1&nbsp;[**Card**](https://github.com/lyusupov/SoftRF/wiki/Card-Edition)&nbsp;<br>2&nbsp;[**Card  Mark III**](https://github.com/lyusupov/SoftRF/wiki/Card-Edition-MkIII)&nbsp;|Q3 2024||&nbsp;

## By OEM
OEM|Model(s)
:---:|:---:
[LilyGO / TTGO](https://lilygo.cc/)|1&nbsp;[**Prime Mark II**](https://github.com/lyusupov/SoftRF/wiki/Prime-Edition-MkII)<br>2&nbsp;[**Prime Mark III**](https://github.com/lyusupov/SoftRF/wiki/Prime-Edition-MkIII)<br>3&nbsp;[**Dongle**](https://github.com/lyusupov/SoftRF/wiki/Dongle-Edition)<br>4&nbsp;[**SkyView EZ**](https://github.com/lyusupov/SoftRF/wiki/SkyView-EZ)<br>5&nbsp;[**Bracelet**](https://github.com/lyusupov/SoftRF/wiki/Bracelet-Edition)<br>6&nbsp;[**Badge**](https://github.com/lyusupov/SoftRF/wiki/Badge-Edition)<br>7&nbsp;[**WebTop USB**](https://github.com/lyusupov/SoftRF/wiki/WebTop-USB)<br>8&nbsp;[**Ham**](https://github.com/lyusupov/SoftRF/wiki/Ham-Edition)<br>9&nbsp;[**Eco**](https://github.com/lyusupov/SoftRF/wiki/Eco-Edition)<br>10&nbsp;[**Labubu**](https://github.com/lyusupov/SoftRF/wiki/Labubu-Edition)<br>11&nbsp;[**Concorde**](https://github.com/lyusupov/SoftRF/wiki/Concorde-Edition)<br>12&nbsp;[**Stylus**](https://github.com/lyusupov/SoftRF/wiki/Stylus-Edition)<br>13&nbsp;[**Card  Mark II**](https://github.com/lyusupov/SoftRF/wiki/Card-Edition-MkII)<br>14&nbsp;[**Prime Mark IV**](https://github.com/lyusupov/SoftRF/wiki/Prime-Edition-MkIV)
[Elecrow](http://www.elecrow.com/)|1&nbsp;[**Handheld**](https://github.com/lyusupov/SoftRF/wiki/Handheld-Edition)<br>2&nbsp;[**Gizmo**](https://github.com/lyusupov/SoftRF/wiki/Gizmo-Edition)<br>3&nbsp;[**Airventure**](https://github.com/lyusupov/SoftRF/wiki/Airventure-Edition)<br>4&nbsp;[**Solaris**](https://github.com/lyusupov/SoftRF/wiki/Solaris-Edition)<br>5&nbsp;[**Pocket**](https://github.com/lyusupov/SoftRF/wiki/Pocket-Edition)
[Heltec Automation](https://heltec.org/)|1&nbsp;[**Mini**](https://github.com/lyusupov/SoftRF/wiki/Mini-Edition)<br>2&nbsp;[**Midi**](https://github.com/lyusupov/SoftRF/wiki/Midi-Edition)<br>3&nbsp;[**Cozy**](https://github.com/lyusupov/SoftRF/wiki/Cozy-Edition)
[Waveshare Electronics](https://www.waveshare.com/)|1&nbsp;[**SkyView Pi**](https://github.com/lyusupov/SoftRF/wiki/SkyView-Pi)<br>2&nbsp;[**SkyView Pico**](https://github.com/lyusupov/SoftRF/wiki/SkyView-Pico)
[Seeed Studio](https://www.seeedstudio.com/)|1&nbsp;[**USB to Bluetooth**](https://github.com/lyusupov/SoftRF/wiki/USB-to-Bluetooth-adapter)<br>2&nbsp;[**Card**](https://github.com/lyusupov/SoftRF/wiki/Card-Edition)<br>3&nbsp;[**Card  Mark III**](https://github.com/lyusupov/SoftRF/wiki/Card-Edition-MkIII)
[Texas Instruments](http://www.ti.com)|[**Uni**](https://github.com/lyusupov/SoftRF/wiki/Uni-Edition)
[Great Scott Gadgets](https://greatscottgadgets.com/)|[**ES**](https://github.com/lyusupov/SoftRF/wiki/ES-Edition)
[Rak Wireless](https://www.rakwireless.com/en-us)|[**Lego**](https://github.com/lyusupov/SoftRF/wiki/Lego-Edition)
[Olimex](https://www.olimex.com)|[**Balkan**](https://github.com/lyusupov/SoftRF/wiki/Balkan-Edition)
[RadioMaster RC](https://radiomasterrc.com/)|[**Nano**](https://github.com/lyusupov/SoftRF/wiki/Nano-Edition)
[Ebyte](https://ebyteiot.com/)|[**Retro Mark II**](https://github.com/lyusupov/SoftRF/wiki/Retro-Edition-MkII)

<br>

# Documentation

* SoftRF overview
    * [Part 1](https://github.com/lyusupov/SoftRF/blob/master/documents/SoftRF-release-1.pdf) (PDF, December 2015)
    * [Part 2](https://github.com/lyusupov/SoftRF/raw/master/documents/SoftRF-release-2.pdf) (PDF, March 2017)
* [Prime Edition MkIII](https://github.com/lyusupov/SoftRF/wiki/Prime-Edition-MkIII) 
    * [Quick start](https://github.com/lyusupov/SoftRF/wiki/Prime-Edition-MkIII.-Quick-start)
    * [Screen pages](https://github.com/lyusupov/SoftRF/wiki/Prime-Edition-MkIII.-Screen-pages)
    * [Aircrafts database](https://github.com/lyusupov/SoftRF/wiki/Prime-Edition-MkIII.-Aircrafts-database)
    * [GNSS access](https://github.com/lyusupov/SoftRF/wiki/Prime-Edition-MkIII.-GNSS-troubleshooting)
* [Badge Edition](https://github.com/lyusupov/SoftRF/wiki/Badge-Edition) 
    * [Quick start](https://github.com/lyusupov/SoftRF/wiki/Badge-Edition.-Quick-start)
    * [Screen pages](https://github.com/lyusupov/SoftRF/wiki/Badge-Edition.-Screen-pages)
    * [Bluetooth LE](https://github.com/lyusupov/SoftRF/wiki/Badge-Edition.-Bluetooth-LE)
    * [Aircrafts database](https://github.com/lyusupov/SoftRF/wiki/Badge-Edition.-Aircrafts-database)
    * [Enclosure](https://github.com/lyusupov/SoftRF/tree/master/case/Badge)
    * [Display care](https://github.com/lyusupov/SoftRF/wiki/Badge-Edition.-Display-care)
    * [Expansion module](https://github.com/lyusupov/SoftRF/wiki/Badge-Edition.-Expansion-module)
<!-- * [Bracelet Edition](https://github.com/lyusupov/SoftRF/wiki/Bracelet-Edition) -->
* [Prime Edition MkII](https://github.com/lyusupov/SoftRF/wiki/Prime-Edition-MkII)
    * [Quick start](https://github.com/lyusupov/SoftRF/wiki/Prime-Edition-MkII.-Quick-start)
    * [Enclosure](https://github.com/lyusupov/SoftRF/tree/master/case/v5)
    * Firmware update
        * [USB](https://github.com/lyusupov/SoftRF/tree/master/software/firmware/binaries#esp32)
        * [webUI](https://github.com/lyusupov/SoftRF/wiki/Firmware-update-%28Web-method%29#esp32)
        * [programming device](https://github.com/lyusupov/SoftRF/wiki/Firmware-update-%28hardware-method%29)
* [Standalone Edition](https://github.com/lyusupov/SoftRF/wiki/Standalone-Edition) 
    * [Specifications](https://github.com/lyusupov/SoftRF/wiki/Standalone-Specifications)
    * [Shield](https://github.com/lyusupov/SoftRF/wiki/Standalone-Shield)
    * [Modules](https://github.com/lyusupov/SoftRF/wiki/Standalone-Modules)
    * [Assembly](https://github.com/lyusupov/SoftRF/tree/master/hardware)
    * [Enclosure](https://github.com/lyusupov/SoftRF/tree/master/case/v4)
    * [ESP32 adapter](https://github.com/lyusupov/ESP32-NODEMCU-ADAPTER)
    * [ESP32-C3 upgrade](https://github.com/lyusupov/SoftRF/wiki/ESP32%E2%80%90C3-upgrade-for-Standalone-Edition) 
    * [ESP32-C6 upgrade](https://github.com/lyusupov/SoftRF/wiki/ESP32%E2%80%90C6-upgrade-for-Standalone-Edition) 
* [Card Edition](https://github.com/lyusupov/SoftRF/wiki/Card-Edition)&nbsp;
    * [Quick start](https://github.com/lyusupov/SoftRF/wiki/Card-Edition.-Quick-start)
* [Ham Edition](https://github.com/lyusupov/SoftRF/wiki/Ham-Edition)
    * [Quick start](https://github.com/lyusupov/SoftRF/wiki/Ham-Edition.-Quick-start)
* [ES Edition](https://github.com/lyusupov/SoftRF/wiki/ES-Edition)
* [Eco Edition](https://github.com/lyusupov/SoftRF/wiki/Eco-Edition)
* [Duo Concept](https://github.com/lyusupov/SoftRF/wiki/Eco-Edition#duo-concept)
* [Octave Concept](https://github.com/lyusupov/SoftRF/wiki/Octave-Concept)
* [Uni Edition](https://github.com/lyusupov/SoftRF/wiki/Uni-Edition)
    * [Firmware installation](https://github.com/lyusupov/SoftRF/wiki/Uni-Edition.-Firmware-maintenance-procedures)
    * [Enclosure](https://github.com/lyusupov/SoftRF/tree/master/case/Uni)
* [Cozy Edition](https://github.com/lyusupov/SoftRF/wiki/Cozy-Edition)
    * [Quick start](https://github.com/lyusupov/SoftRF/wiki/Cozy-Edition.-Quick-start)
* [Midi Edition](https://github.com/lyusupov/SoftRF/wiki/Midi-Edition)
    * [Quick start](https://github.com/lyusupov/SoftRF/wiki/Midi-Edition.-Quick-start)
* [Mini Edition](https://github.com/lyusupov/SoftRF/wiki/Mini-Edition)
    * [Firmware installation](https://github.com/lyusupov/SoftRF/tree/master/software/firmware/binaries#cubecell)
    * [Quick start](https://github.com/lyusupov/SoftRF/wiki/Mini-Edition.-Quick-start)
    * [Enclosure](https://github.com/lyusupov/SoftRF/tree/master/case/Mini)
* [Dongle Edition](https://github.com/lyusupov/SoftRF/wiki/Dongle-Edition) 
    * [Firmware installation](https://github.com/lyusupov/SoftRF/wiki/AcSiP-S7xG-flashing-instructions)
    * [Quick start](https://github.com/lyusupov/SoftRF/wiki/Dongle-Edition.-Quick-start)
    * [Settings](https://github.com/lyusupov/SoftRF/wiki/Dongle-settings)
    * [Enclosure](https://github.com/lyusupov/SoftRF/tree/master/case/Dongle)
* [Lego Edition](https://github.com/lyusupov/SoftRF/wiki/Lego-Edition)
* [Balkan Edition](https://github.com/lyusupov/SoftRF/wiki/Balkan-Edition)
* [Academy Edition](https://github.com/lyusupov/SoftRF/wiki/Academy-Edition) 
* [UAV Edition](https://github.com/lyusupov/SoftRF/wiki/UAV-Edition)
    * [Bill of materials](https://github.com/lyusupov/SoftRF/wiki/UAV-BOM)
    * [Wiring and pin-out](https://github.com/lyusupov/ESP32-NODEMCU-ADAPTER)
    * [Enclosure](https://github.com/lyusupov/SoftRF/tree/master/case/UAV)
* [Raspberry Edition](https://github.com/lyusupov/SoftRF/wiki/Raspberry-Edition)

* SkyView
    * [EZ](https://github.com/lyusupov/SoftRF/wiki/SkyView-EZ) 
        * [Quick start](https://github.com/lyusupov/SoftRF/wiki/SkyView.-Quick-start)
        * [Settings](https://github.com/lyusupov/SoftRF/wiki/SkyView-settings)
        * [Enclosure](https://github.com/lyusupov/SoftRF/tree/master/case/SkyView)
        * [Dual boot](https://github.com/lyusupov/SoftRF/wiki/SkyView.-Dual-boot)
    * [Pi](https://github.com/lyusupov/SoftRF/wiki/SkyView-Pi)

* [WebTop USB](https://github.com/lyusupov/SoftRF/wiki/WebTop-USB)
* [WebTop Serial](https://github.com/lyusupov/SoftRF/wiki/WebTop-Serial-adapter)
    * [Quick start](https://github.com/lyusupov/SoftRF/wiki/WebTop-Serial.-Quick-Start)
* [Flight Recorder](https://github.com/lyusupov/SoftRF/wiki/Flight-Recorder)
    * [Quick start](https://github.com/lyusupov/SoftRF/wiki/Flight-Recorder.-Quick-Start)

* Software
    * Firmware
        * [Release information](https://github.com/lyusupov/SoftRF/releases) 
        * [Binary](https://github.com/lyusupov/SoftRF/tree/master/software/firmware/binaries)
        * [Settings](https://github.com/lyusupov/SoftRF/wiki/Settings)
        * [Update](https://github.com/lyusupov/SoftRF/wiki/Firmware-update-(Web-method)) (Web method)
        * [Source](https://github.com/lyusupov/SoftRF/tree/master/software/firmware/source)
* Extras
    * [Long range (LoRa) RF module](https://github.com/lyusupov/SoftRF/wiki/SoftRF-LoRa-module)
        * [Frequency deviation](https://github.com/lyusupov/SoftRF/wiki/Frequency-deviation)
    * Protocols
        * [UAT](https://github.com/lyusupov/SoftRF/tree/master/software/firmware/source/UATbridge)    
        * [OGNTP](https://github.com/lyusupov/SoftRF/wiki/OGNTP-compatibility)
        * [P3I Open (PilotAware)](https://github.com/lyusupov/SoftRF/wiki/PilotAware-compatibility)
        * [FANET (Skytraxx)](https://github.com/lyusupov/SoftRF/wiki/FANET-compatibility)
    * [Garmin GDL90 datalink](https://github.com/lyusupov/SoftRF/wiki/Garmin-GDL90-compatibility)
        * [SkyDemon](https://github.com/lyusupov/SoftRF/wiki/Garmin-GDL90-compatibility#skydemon)
        * [Avare](https://github.com/lyusupov/SoftRF/wiki/Garmin-GDL90-compatibility#avare)
        * [ForeFlight](https://github.com/lyusupov/SoftRF/wiki/Garmin-GDL90-compatibility#foreflight)
    * [Integration with airborne (Stratux, PilotAware,...) and groundstation (FlightRadar24, FlightAware,...) ADS-B receivers](https://github.com/lyusupov/SoftRF/wiki/Integration-with-RTL%E2%80%90SDR-based-ADS%E2%80%90B-receivers)
    * [Combined use of multiple SoftRF units](https://github.com/lyusupov/SoftRF/wiki/Combined-use-of-multiple-SoftRF-units) 
* Archive
    * [Prime Edition](https://github.com/lyusupov/SoftRF/wiki/Prime-Edition)
        * [Bill of materials](https://github.com/lyusupov/SoftRF/wiki/Prime-BOM)
        * [Wiring](https://github.com/lyusupov/SoftRF/wiki/Prime-Wiring)
        * [Enclosure](https://github.com/lyusupov/SoftRF/tree/master/case/v1)
    * [Retro Edition](https://github.com/lyusupov/SoftRF/wiki/Retro-Edition)
    * Applications
        * [Emulator](https://github.com/lyusupov/SoftRF/tree/master/software/app/Emulator)

# Highlights

* [**Badge Edition**](https://github.com/lyusupov/SoftRF/wiki/Badge-Edition) 



* [**Prime Edition Mark III**](https://github.com/lyusupov/SoftRF/wiki/Prime-Edition-MkIII) 



* [**Prime Edition Mark II**](https://github.com/lyusupov/SoftRF/wiki/Prime-Edition-MkII)

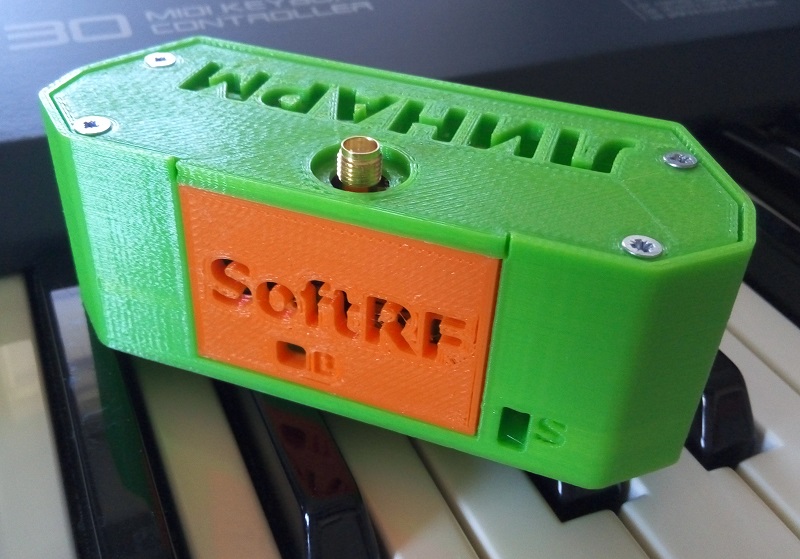
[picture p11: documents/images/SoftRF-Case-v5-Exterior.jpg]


* [**Airventure Edition**](https://github.com/lyusupov/SoftRF/wiki/Airventure-Edition)



* [**Concorde Edition**](https://github.com/lyusupov/SoftRF/wiki/Concorde-Edition)&nbsp;



* [**Card Edition Mark III**](https://github.com/lyusupov/SoftRF/wiki/Card-Edition-MkIII) 



* [**Retro Edition Mark II**](https://github.com/lyusupov/SoftRF/wiki/Retro-Edition-MkII)&nbsp;



* [**Solaris Edition**](https://github.com/lyusupov/SoftRF/wiki/Solaris-Edition)&nbsp;



* [**Pocket Edition**](https://github.com/lyusupov/SoftRF/wiki/Pocket-Edition)&nbsp;



* [**Nano Edition**](https://github.com/lyusupov/SoftRF/wiki/Nano-Edition) 



* [**Gizmo Edition**](https://github.com/lyusupov/SoftRF/wiki/Gizmo-Edition)



* [**ES Edition**](https://github.com/lyusupov/SoftRF/wiki/ES-Edition)


<!-- * [**Bracelet Edition**](https://github.com/lyusupov/SoftRF/wiki/Bracelet-Edition)

![](https://github.com/lyusupov/SoftRF/raw/master/documents/images/Bracelet-2.jpg) -->

* [**SoftRF Tool**](https://github.com/lyusupov/SoftRF/wiki/SoftRF-Configuration-Tool)



* [**Standalone Edition**](https://github.com/lyusupov/SoftRF/wiki/Standalone-Edition)





* [**Uni Edition**](https://github.com/lyusupov/SoftRF/wiki/Uni-Edition)

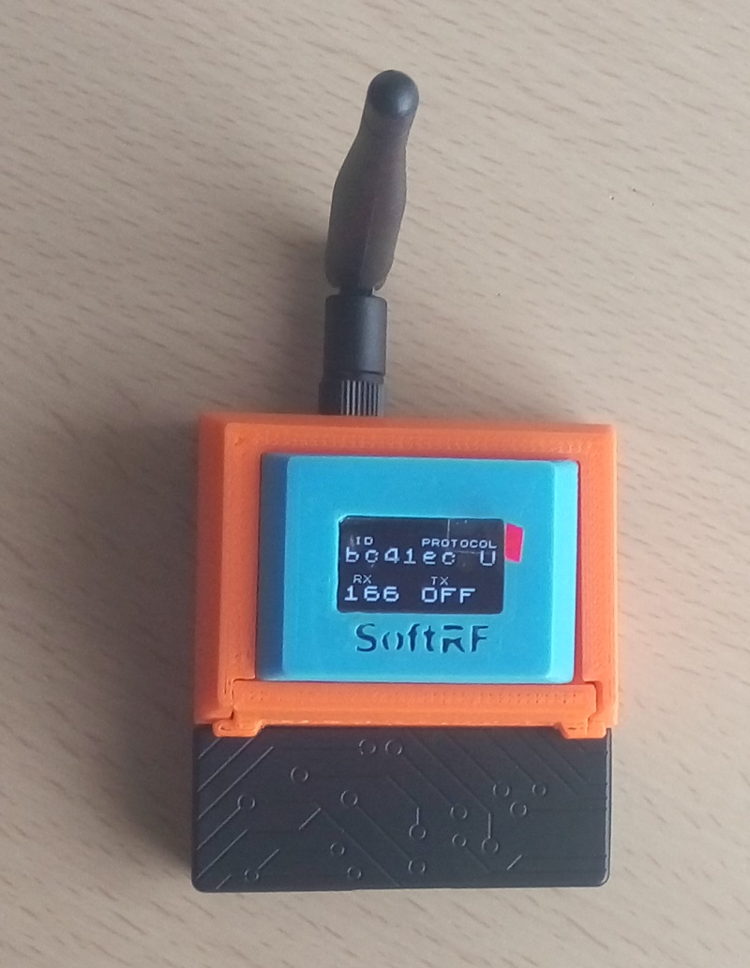
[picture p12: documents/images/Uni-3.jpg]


* [**Dongle Edition**](https://github.com/lyusupov/SoftRF/wiki/Dongle-Edition) 

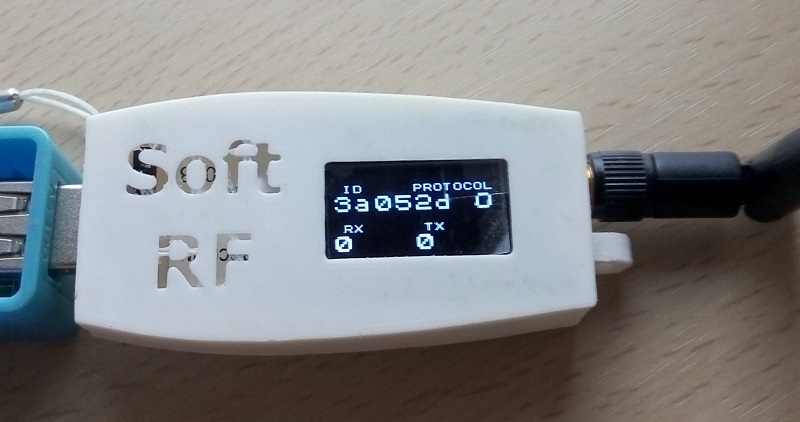
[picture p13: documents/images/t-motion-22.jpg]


* [**Ham Edition**](https://github.com/lyusupov/SoftRF/wiki/Ham-Edition)



* [**Cozy Edition**](https://github.com/lyusupov/SoftRF/wiki/Cozy-Edition)



* [**Midi Edition**](https://github.com/lyusupov/SoftRF/wiki/Midi-Edition)



* [**Mini Edition**](https://github.com/lyusupov/SoftRF/wiki/Mini-Edition)



* [**SkyView EZ**](https://github.com/lyusupov/SoftRF/wiki/SkyView-EZ) 



* [**Lego Edition**](https://github.com/lyusupov/SoftRF/wiki/Lego-Edition)



* [**Balkan Edition**](https://github.com/lyusupov/SoftRF/wiki/Balkan-Edition)



* [**Academy Edition**](https://github.com/lyusupov/SoftRF/wiki/Academy-Edition)



* [**Octave Concept**](https://github.com/lyusupov/SoftRF/wiki/Octave-Concept)



* [**UAV appliance**](https://github.com/lyusupov/SoftRF/wiki/UAV-Edition)



* [**Raspberry Edition**](https://github.com/lyusupov/SoftRF/wiki/Raspberry-Edition)



* [**Flight Recorder**](https://github.com/lyusupov/SoftRF/wiki/Flight-Recorder)

<p>&nbsp;</p>

<!--
* [**Software driven emulation**](https://github.com/lyusupov/SoftRF/wiki/Prime-Edition)

![](https://github.com/lyusupov/SoftRF/raw/master/documents/images/softrf-emulation.jpg)

![](https://github.com/lyusupov/SoftRF/raw/master/documents/images/LK8000-emu.jpg)

![](https://github.com/lyusupov/SoftRF/blob/master/case/v1/SoftRF-Case-v1-Exterior.jpg)
-->

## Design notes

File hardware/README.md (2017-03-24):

# Schematics

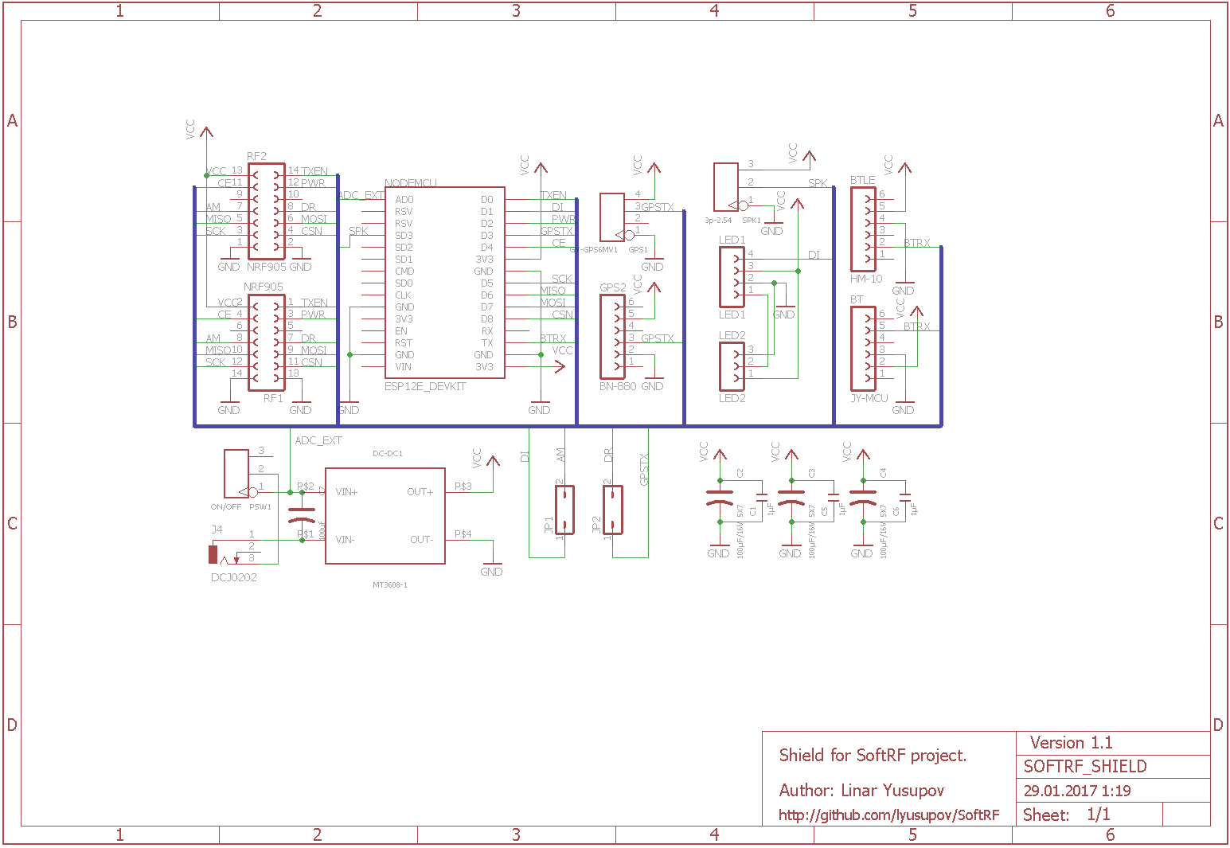
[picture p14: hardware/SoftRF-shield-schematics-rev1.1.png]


If you would like to print the schematics I would suggest to use [this PDF file](https://github.com/lyusupov/SoftRF/blob/master/hardware/SoftRF-shield-schematics-rev1.1.pdf). 

# PCB layout

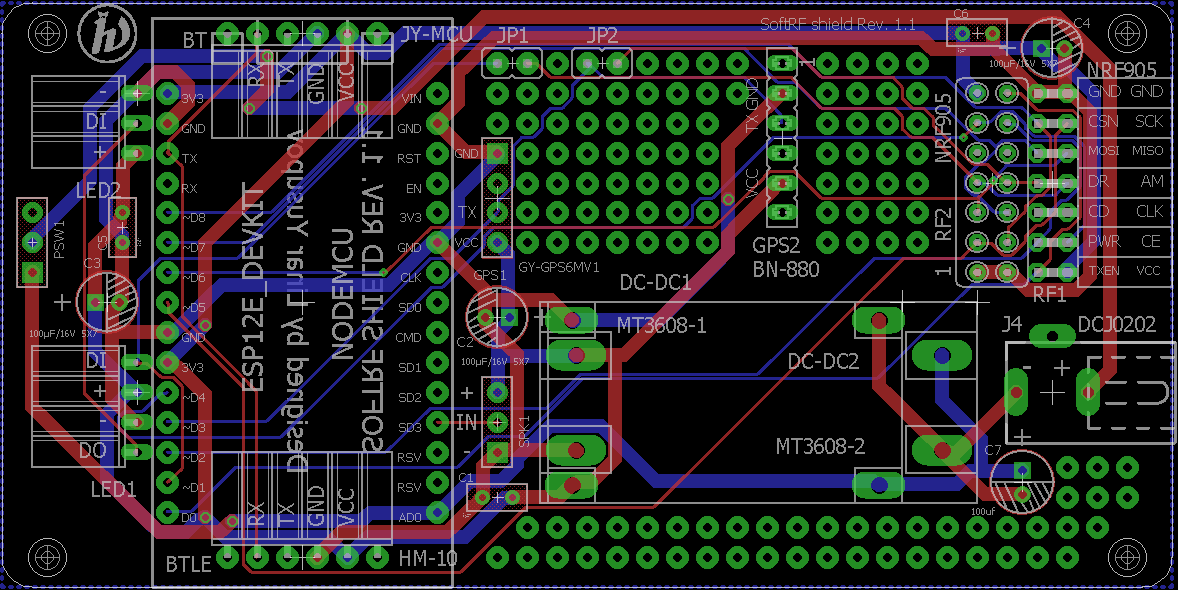
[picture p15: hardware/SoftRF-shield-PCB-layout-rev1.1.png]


# Manufacturing

Grab [this ZIP archive](https://github.com/lyusupov/SoftRF/blob/master/hardware/SoftRF-shield-PCB-Gerber-rev1.1.zip) with Gerber files then place an order for a "PCB service".
I've used [ShenZhen2U](http://www.shenzhen2u.com/) and is pretty much satisfied with price, quality and turnaroud time.

An example of PCB service order:
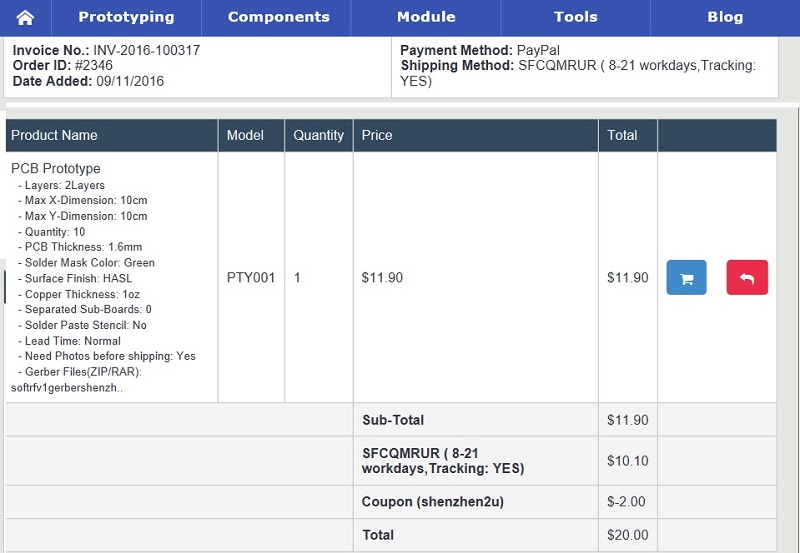
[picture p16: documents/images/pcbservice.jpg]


# Photo of the unpopulated PCB.  Top:

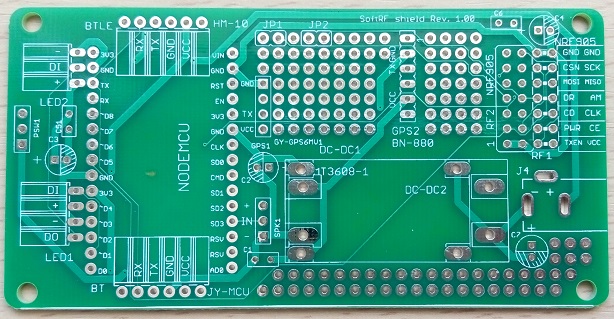
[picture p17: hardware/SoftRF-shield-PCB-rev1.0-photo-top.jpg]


# Bottom:

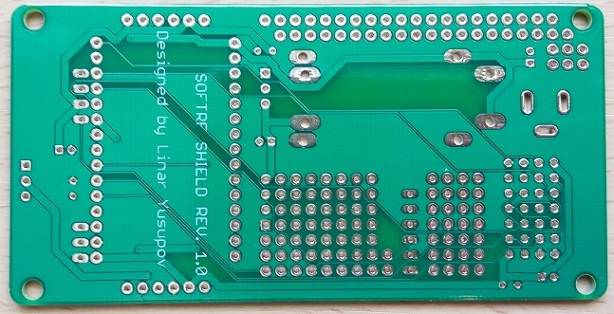
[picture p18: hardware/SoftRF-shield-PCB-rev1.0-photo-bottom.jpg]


# Soldered shield

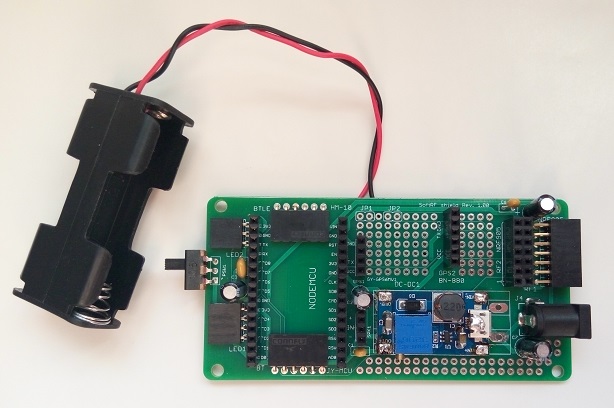
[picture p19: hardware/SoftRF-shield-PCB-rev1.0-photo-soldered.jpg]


# Partially assembled

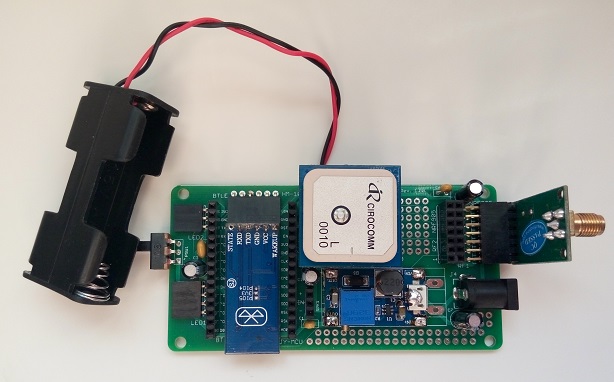
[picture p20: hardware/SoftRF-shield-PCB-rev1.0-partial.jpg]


# Complete

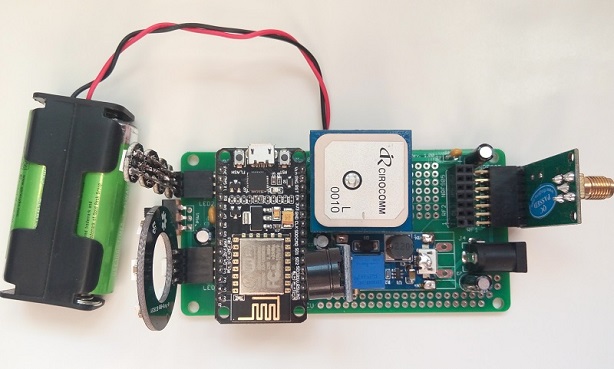
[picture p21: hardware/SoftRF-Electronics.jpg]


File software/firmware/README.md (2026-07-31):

## WebUI

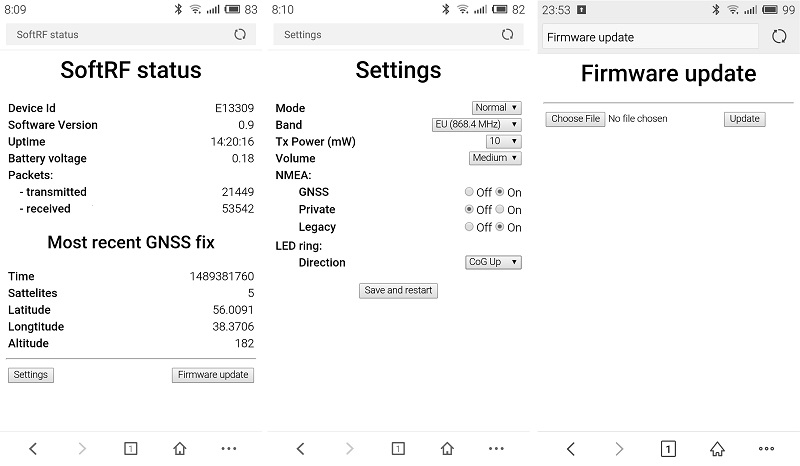
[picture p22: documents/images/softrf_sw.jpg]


## License

Copyright (C) 2016-2026 Linar Yusupov <linar.r.yusupov@gmail.com>

This program is free software: you can redistribute it and/or modify
it under the terms of the GNU General Public License as published by
the Free Software Foundation, either version 3 of the License, or
(at your option) any later version.

This program is distributed in the hope that it will be useful,
but WITHOUT ANY WARRANTY; without even the implied warranty of
MERCHANTABILITY or FITNESS FOR A PARTICULAR PURPOSE.  See the
GNU General Public License for more details.

You should have received a copy of the GNU General Public License
along with this program.  If not, see <http://www.gnu.org/licenses/>.

## Credits

 * Arduino Core for ESP8266 is developed/supported by **ESP8266 Community** (support-esp8266@esp8266.com)
 * AVR/Arduino nRF905 Library/Driver is developed by **Zak Kemble**, contact@zakkemble.co.uk
 * flarm_decode is developed by **Stanislaw Pusep**, http://github.com/creaktive
 * Arduino Time Library is developed by **Paul Stoffregen**, http://github.com/PaulStoffregen
 * "Aircraft" and MAVLink Libraries are developed by **Andy Little**
 * TinyGPS++ and PString Libraries are developed by **Mikal Hart**
 * Adafruit NeoPixel Library is developed by **Phil Burgess**, **Michael Miller** and others
 * TrueRandom Library is developed by **Peter Knight**
 * IBM LMIC framework is maintained by **Matthijs Kooijman**
 * ESP8266FtpServer is developed by **David Paiva**
 * Lib_crc is developed by **Lammert Bies**
 * OGN/ADS-L library is developed by **Pawel Jalocha**
 * NMEA library is developed by **Timur Sinitsyn**, **Tobias Simon**, **Ferry Huberts**
 * ADS-B encoder C++ library is developed by **yangbinbin** (yangbinbin_ytu@163.com)
 * Arduino Core for ESP32 is developed by **Hristo Gochkov**
 * Adafruit BMP085 library is developed by **Limor Fried** ( **Ladyada** )
 * Adafruit BMP280 library is developed by **Kevin Townsend**
 * Adafruit MPL3115A2 and LIS3DH libraries are developed by **Limor Fried** and **Kevin Townsend**
 * U8g2 monochrome LCD, OLED and eInk library is developed by **Oliver Kraus**
 * NeoPixelBus library is developed by **Michael Miller**
 * jQuery library is developed by **JS Foundation**
 * EGM96 data is developed by **XCSoar team**
 * BCM2835 and RadioHead libraries are developed by **Mike McCauley**
 * SimpleNetwork library is developed by **Dario Longobardi**
 * ArduinoJson library is developed by **Benoit Blanchon**
 * Flashrom library is part of the **flashrom.org project**
 * Arduino Core for TI CC13X0 is developed by **Energia team**
 * EasyLink library is developed by **Robert Wessels** and **Tony Cave**
 * Dump978 library is developed by **Oliver Jowett**
 * FEC library is developed by **Phil Karn**
 * AXP20X, XPowersLib, BMA423, FT5206, PCF8563 and SensorLib libraries are developed by **Lewis He**
 * GxEPD2 library is developed by **Jean-Marc Zingg**
 * Adafruit SSD1306, GFX, BusIO, INA219 and BME680 libraries are developed by **Adafruit Industries**
 * GDL90 decoder is developed by **Ryan David**
 * Sqlite3 Arduino library for ESP32 is developed by **Arundale Ramanathan**
 * FLN/OGN aircrafts data is courtesy of **FlarmNet/GliderNet**
 * ESP32 I2S WAV player example is developed by **Tuan Nha**
 * AceButton library is developed by **Brian Park**
 * Arduino Core for STM32 is developed by **Frederic Pillon**
 * Python IGC format encoder is developed by **Tobias Bieniek**
 * port of MicroPython for ESP32 is developed by **Boris Lovosevic**
 * ESP32 BT SPP library is developed by **Evandro Copercini**
 * TFT library is developed by **Bodmer**
 * STM32duino Low Power and RTC libraries are developed by **Wi6Labs**
 * Basic MAC library is developed by **Michael Kuyper**
 * LowPowerLab SPIFlash library is maintained by **Felix Rusu**
 * Arduino Core for ASR6x0x is developed by **Aaron Lee**
 * ADXL362 library is developed by **Klaas-Jan Winkel**
 * Arduino Core for nRF52 and TinyUSB library are developed by **Ha Thach**
 * Arduino-NVM library is developed by **Frank Holtz**
 * U8g2 fonts for Adafruit GFX are developed by **Oliver Kraus**
 * Adafruit SPIFlash and SleepyDog libraries are developed by **Adafruit Industries**
 * SdFat library is developed by **Bill Greiman**
 * Arduino MIDI library is developed by **Francois Best**
 * Arduino uCDB library is developed by **Ioulianos Kakoulidis**
 * libmodes library is developed by **Salvatore Sanfilippo** and **Thomas Watson**
 * Arduino Cores for Atmel SAMD and Renesas RA4 are developed by **Arduino LLC**
 * FlashStorage and ArduinoBLE libraries are developed by **Arduino LLC**
 * USB host library 2.0 for Zero/M0/SAMD is developed by **gdsports625@gmail.com**
 * Arduino Core for Raspberry Pi RP2XXX and ESP8266Audio library are developed by **Earle Philhower**
 * MPU-9250 9 DoF sensor library is developed by **Kris Winer** and **Hideaki Tai**
 * Pico PIO USB library is developed by **sekigon-gonnoc**
 * IniFile library is developed by **Steve Marple**
 * MD5 library is developed by **Vasilis Georgitzikis**
 * LibAPRS-ESP32 library is developed by **Evan Krall** and **Somkiat Nakhonthai**
 * SA818 library is developed by **Gibbon Zen**
 * OpenDroneID library is developed by **Steve Jack**
 * WiFiWebServer and Functional-Vlpp libraries are developed by **Khoi Hoang**
 * RadioLib library is developed by **Jan Gromes**
 * Arduino Core for EFR32 Series 2 is developed by **Tamas Jozsi**
 * Arduino Core for CH32 is developed by **Tianpei Lee**
 * QMA6100P library is developed by **Tristan Alderson**
 * Arduino Core for nRF54L15 is developed by **Loren Bufanu**
 * Arduino EEPROM library is developed by **Jack Christensen**
 * Adafruit SPA06-003 library is developed by **Limor Fried**

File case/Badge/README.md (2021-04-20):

# Badge enclosure 

This type of enclosure is built around **LilyGO&#174;** **T-Echo** board.<br>

**NOTICE**: This design is applicable for pre-production sample of the **T-Echo**. Other revisions may or may not match.

# Exterior

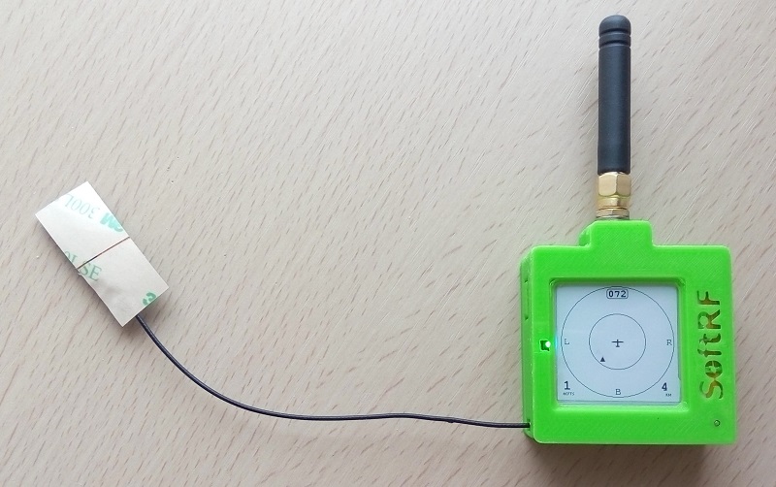
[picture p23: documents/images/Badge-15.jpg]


<br>

# Components

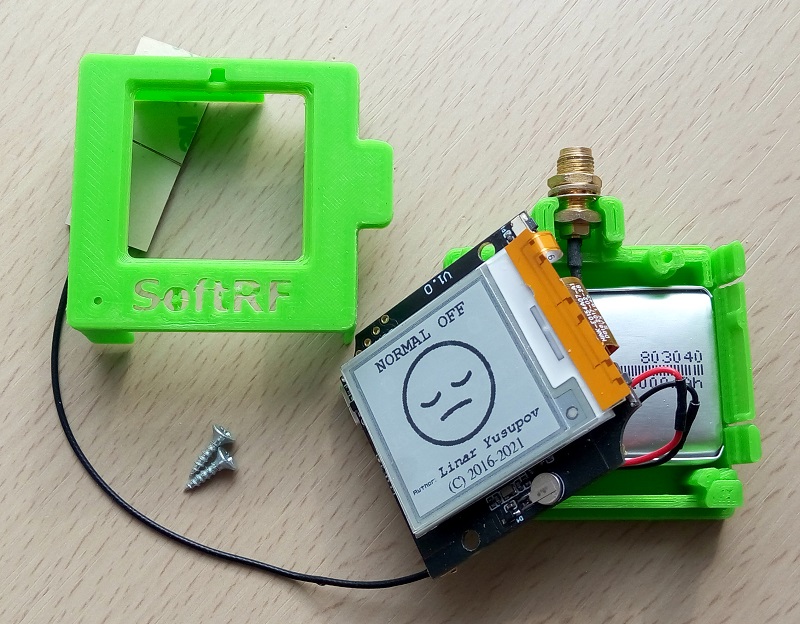
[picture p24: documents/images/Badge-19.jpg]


<br>

The enclosure is designed to fit for a 40 x 30 x 8 mm 1000 mAh Li-Po battery.

# Instructions

3D print two STL files from this folder: **Body** and **Face**. You may pick some printing advisories on [my Thingiverse page](https://www.thingiverse.com/thing:4639183).<br>
If you are unable to print the parts by yourself - you may consider to find an appropriate local 3D service provider and place an order with assistance of [Treatstock](http://www.treatstock.com) or [3DHubs](http://www.3dhubs.com/) portals.

## Assembly procedure

1) connect GNSS antenna to the board ;
2) connect SMA pigtail to the board ;
3) connect battery to the board with JST 1.25mm 2pin female plug ;
4) place the battery first ;
5) then place T-Echo board into the enclosure's main body ;
6) fasten the board with two 2.5x10 mm screws.
7) put lid on top of the assembly.

<br>

# Strap mount option

This variant of the **Body** part is designed to fit for a 20 mm wrist or neck strap.

<br>

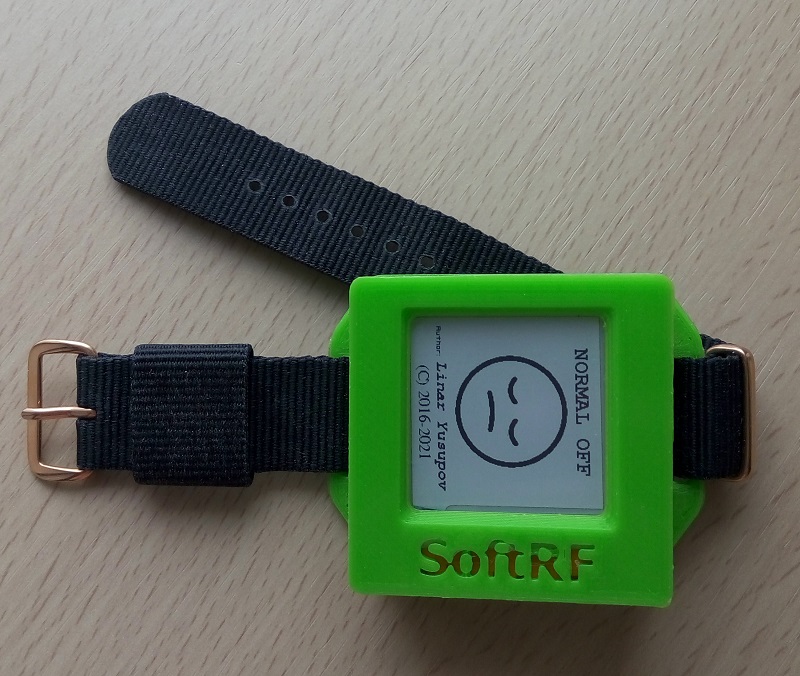
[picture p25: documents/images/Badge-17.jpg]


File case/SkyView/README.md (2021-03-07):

# SkyView enclosure 

This type of enclosure is built around [TTGO T5S](http://s.click.aliexpress.com/e/Zp4ygfQ) board.<br>

<!-- **NOTICE**: This design is applicable for revision V1.9 of T5S. Other revisions may not match. -->

# Exterior

<p>
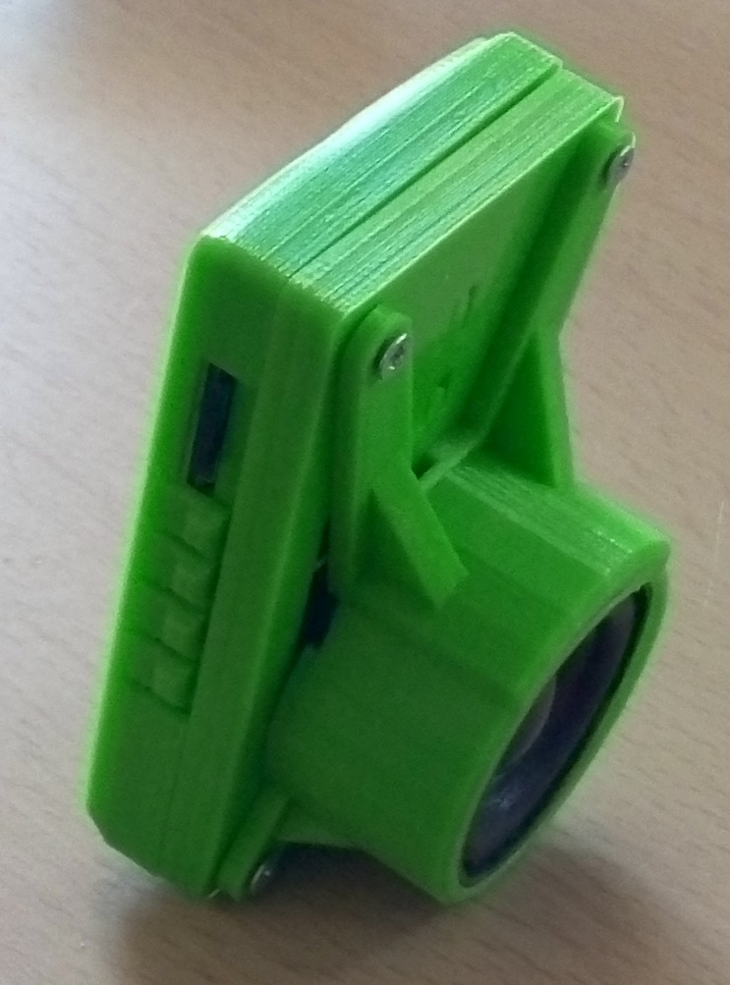
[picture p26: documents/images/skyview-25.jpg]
&nbsp;
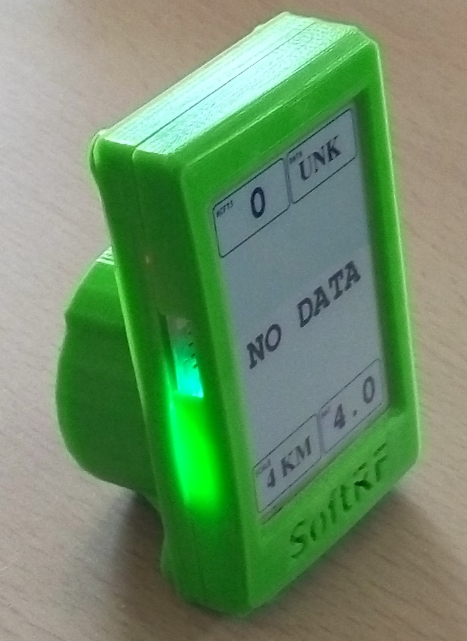
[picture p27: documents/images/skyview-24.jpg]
&nbsp;</p>

<br>

# Components

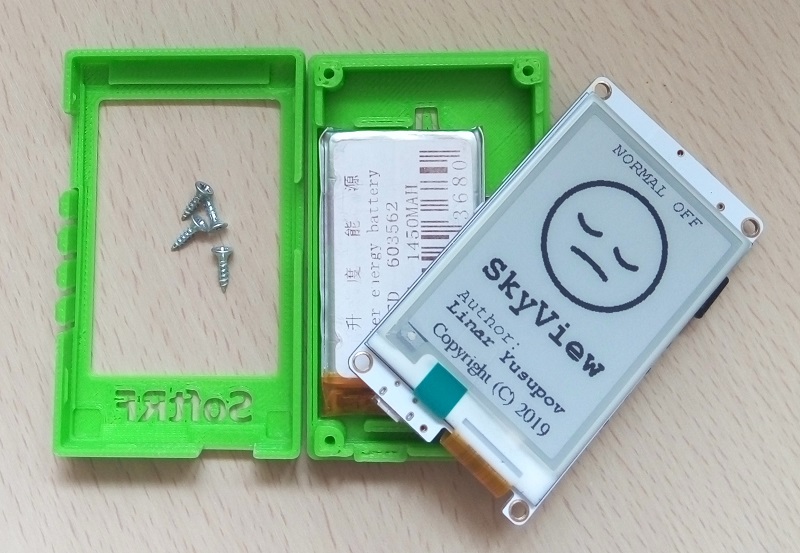
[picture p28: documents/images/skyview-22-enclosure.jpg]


<br>

# Instructions

Choose an appropriate **Body** STL file based upon your measured battery dimensions:
* **Body** is to fit for reference 62x35x6 mm battery, or
* **Body-plus** - it has +1 mm increase for height and width of battery compartment.

3D print two STL files from this folder: **Body**(-plus) and **Face**. You may pick some printing advisories on [my Thingiverse page](http://www.thingiverse.com/thing:3702447).<br>
If you are unable to print the parts by yourself - you may consider to find an appropriate local 3D service provider and place an order with assistance of [Treatstock](http://www.treatstock.com) or [3DHubs](http://www.3dhubs.com/) portals.

Fasten the T5S board to the enclosure's main body with four 2.5x10 mm screws.
Put face plate on top of the assembly.

# Speaker mount option

3D print **Speaker** STL file from this folder.<br>

Put 40 mm speaker inside the printed mount.<br>
Fasten the mount to the enclosure's main body with four 2.5x8 mm screws.

<br>

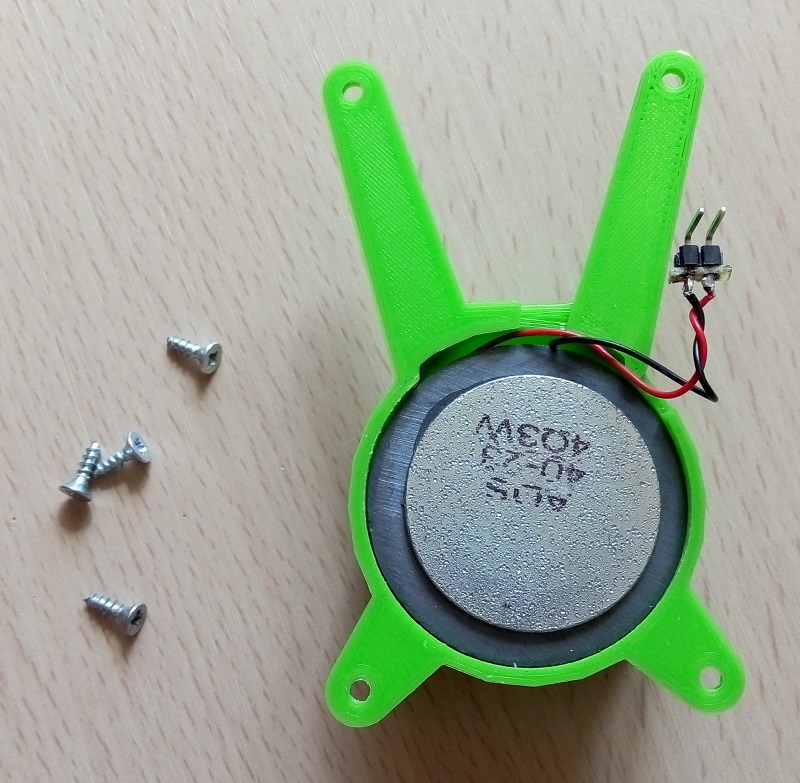
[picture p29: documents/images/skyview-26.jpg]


<br>

# Holder

<br>

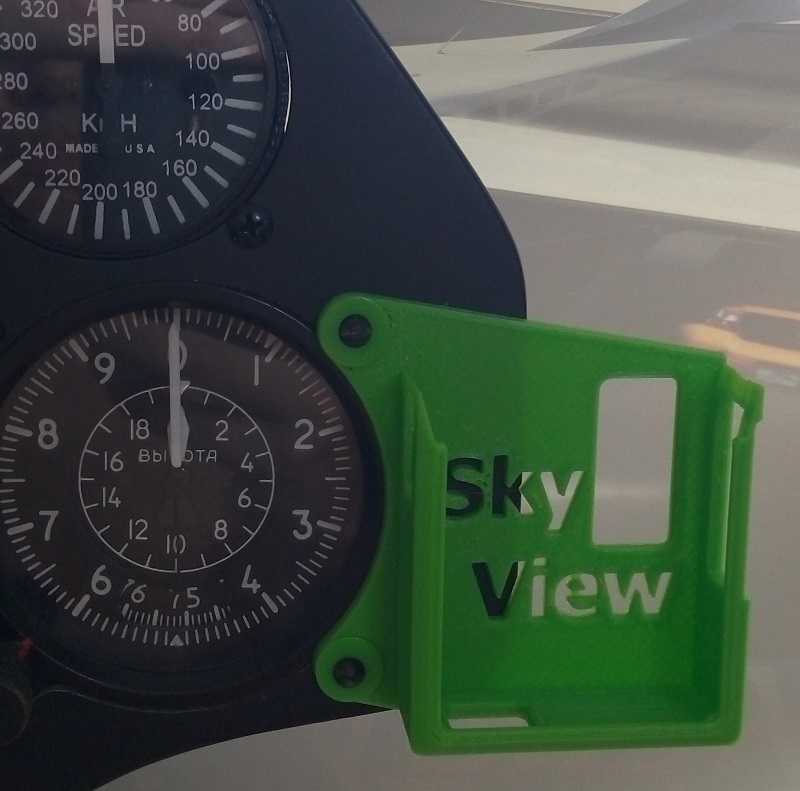
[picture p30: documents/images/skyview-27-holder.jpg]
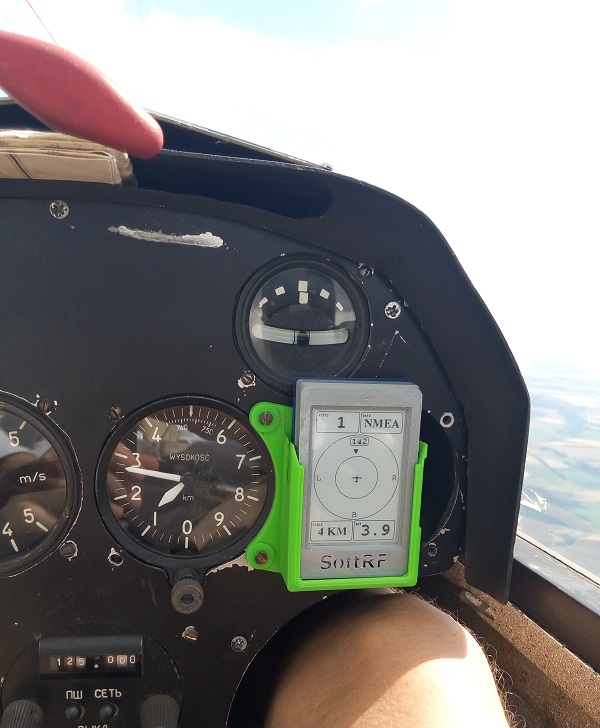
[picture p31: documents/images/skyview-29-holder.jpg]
<p>&nbsp;&nbsp;&nbsp;</p>

<br>

# GoPro mount option

3D print **GoPro** STL file from this folder.<br>
Fasten the mount to the enclosure's main body with four 2.5x8 mm screws.

<br>

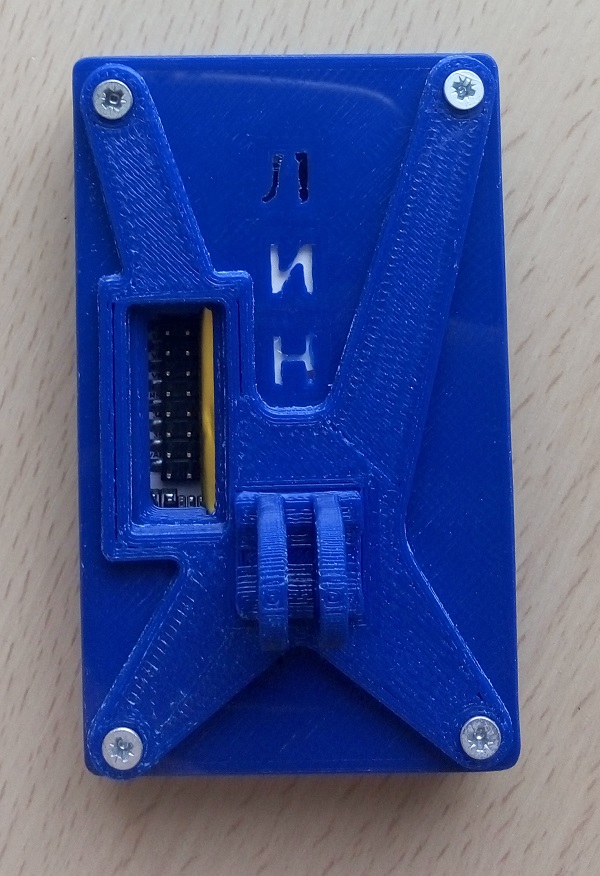
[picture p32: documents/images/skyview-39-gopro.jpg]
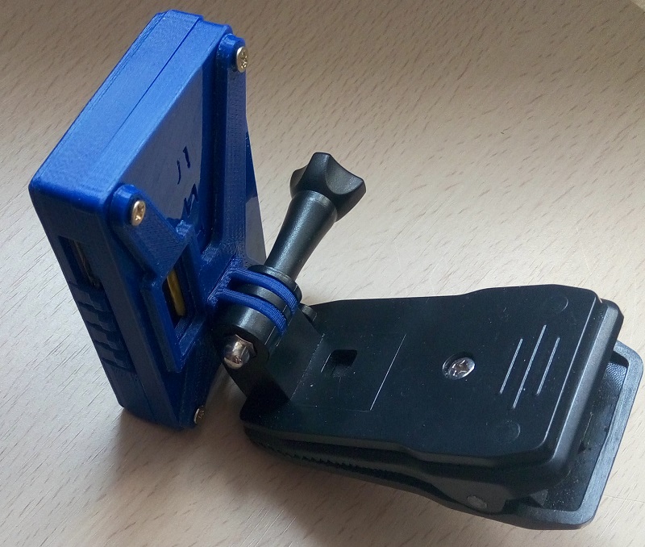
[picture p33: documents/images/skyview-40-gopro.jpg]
<p>&nbsp;&nbsp;&nbsp;</p>

<br>

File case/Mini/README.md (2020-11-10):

# Mini enclosure 

This type of enclosure is built around [Heltec CubeCell-GPS](https://s.click.aliexpress.com/e/_AaoUDH) LoRaWAN GNSS tracker board.<br>

# Exterior

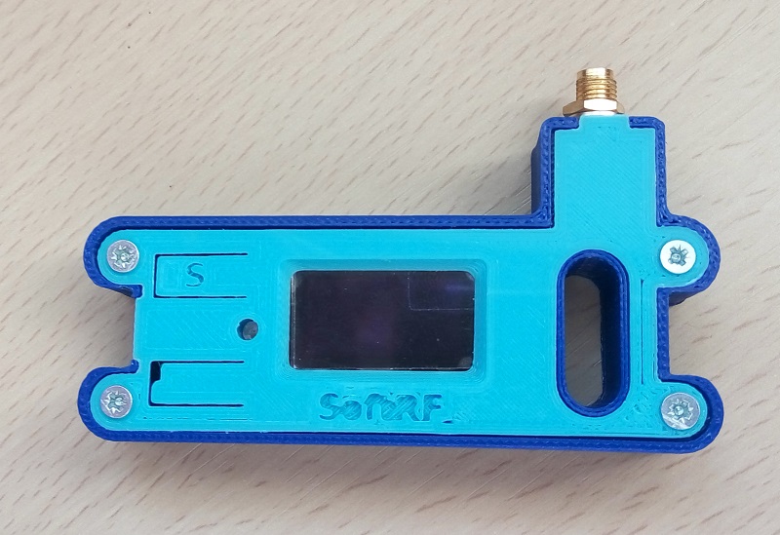
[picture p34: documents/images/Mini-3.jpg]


<br>

# Components

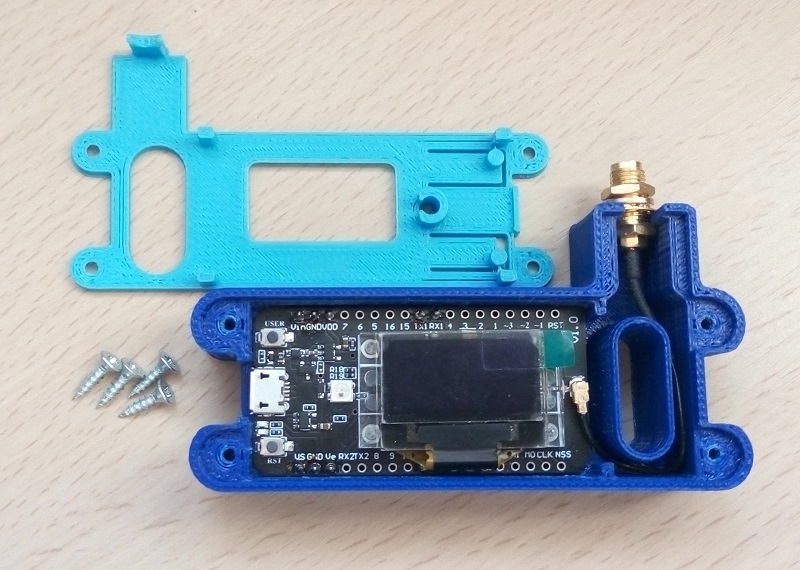
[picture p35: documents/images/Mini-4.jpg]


There are three variants of main **Body** part:
- with no pin header access (-NPH file name suffix)
- with partial pin header access (-PPH suffix)
- with full pin header access (-FPH)

The enclosure is designed to fit a 44 x 22 x 6 mm 600 mAh Li-Po battery.

# Instructions

3D print two STL files from this folder: **Body** and **Lid**. You may pick some printing advisories on [my Thingiverse page](https://www.thingiverse.com/thing:4649316).<br>
If you are unable to print the parts by yourself - you may consider to find an appropriate local 3D service provider and place an order with assistance of [Treatstock](http://www.treatstock.com) or [3DHubs](http://www.3dhubs.com/) portals.

## Assembly procedure

1) connect battery to the board with JST 1.25mm 2pin female plug ;
2) place HTCC-AB02S board into the enclosure's main body ;
3) connect with SMA pigtail ;
4) put lid on top of the assembly ;
5) fasten the lid with four 2.5x10 mm screws.

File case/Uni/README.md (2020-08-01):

# Uni enclosure 

This type of enclosure is built around [Ti SensorTag LPSTK-CC1352R](https://www.ti.com/tool/LPSTK-CC1352R) development kit.<br>

# Exterior

<!--
<p>
&nbsp;<img src="https://github.com/lyusupov/SoftRF/raw/master/documents/images/skyview-25.jpg" height="460" width="340">
&nbsp;<img src="https://github.com/lyusupov/SoftRF/raw/master/documents/images/skyview-24.jpg" height="460" width="334"></p>
-->


<br>

# Components

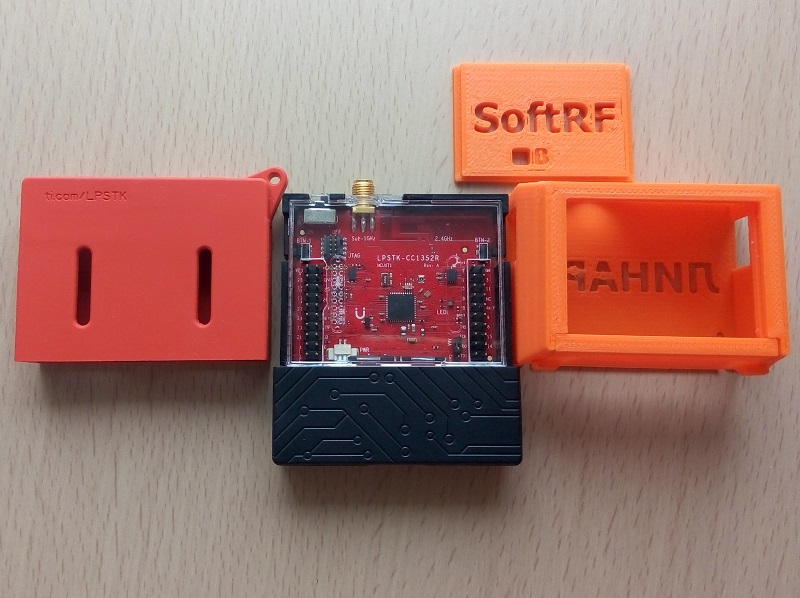
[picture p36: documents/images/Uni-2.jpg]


<br>

# Instructions

3D print two STL files from this folder: **Sleeve** and **Wall**. You may pick some printing advisories on [my Thingiverse page](https://www.thingiverse.com/thing:4558442).<br>
If you are unable to print the parts by yourself - you may consider to find an appropriate local 3D service provider and place an order with assistance of [Treatstock](http://www.treatstock.com) or [3DHubs](http://www.3dhubs.com/) portals.

Both regular and OLED faceplates for the enclosure has been borrowed from [SoftRF Prime MkII case](https://github.com/lyusupov/SoftRF/tree/master/case/v5). Use **Face** and **OLED Front** STL files from that folder.

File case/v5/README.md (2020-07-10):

# Enclosure version 5.0

This type of enclosure is built around [TTGO T-Beam](https://www.aliexpress.com/store/product/TTGO-T-Beam-ESP32-Wi-Fi-Bluetooth-ESP-32-gps-NEO/2090076_32875743018.html) LoRaWAN GNSS tracker board.

# Exterior



# Components

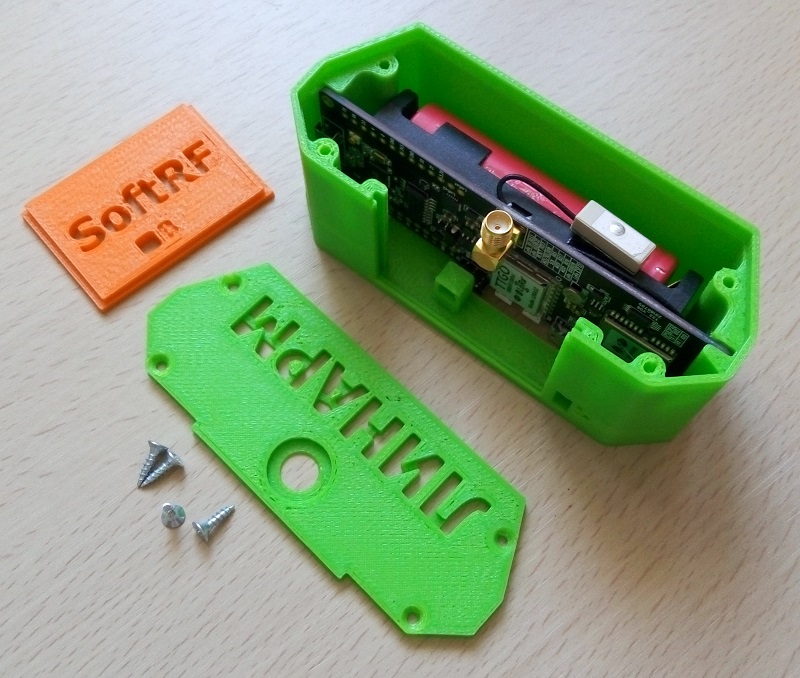
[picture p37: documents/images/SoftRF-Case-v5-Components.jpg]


# Instructions

3D print three STL files from this folder: **Body**, **Lid** and **Face**. You may pick some printing advisories on [my Thingiverse page](http://www.thingiverse.com/thing:3041339).<br>
Files that have:
* no suffix are either universal or best suited for older **V02-V07** revisions of the TTGO T-Beam board ;
* **-V08** suffix are best suited for revisions **V08** (20190423) and **V10** (20190612) of the T-Beam ;
* **-V11** suffix are best suited for most recent **V11** (20191212) revision of this board ;

If you are unable to print the parts by yourself - you may consider to find an appropriate local 3D service provider and place an order with assistance of [Treatstock](http://www.treatstock.com) or [3DHubs](http://www.3dhubs.com/) portals.

At first, insert printed face panel into front rails. Place T-Beam board into the enclosure's main body. Put lid on top of the assembly. Fasten the lid with four 2.5x10 mm screws.

# Options

## GoPro mount

Two variants of main body are available. One is with GoPro mount and another one is without it.



<br>

## Antenna protector

If you, by any reason, keep using your small T-Beam 'stock' 868 MHz antenna - you may think about to 3D print an alternative lid that has a cone 'bumper'.<br>
This little 'feature' may help for the antenna to survive if the device will experience an upside down free fall.<br> 
And it looks nicer, isn't it?



<br>

## OLED display

You may opt for 0.96" front I2C OLED display panel.<br>
Be aware that average 0.96" OLED does not perform well against sun light.<br>
Two variants of the panel are available: 
- the first design is for generic 0.96" OLED ;
- the other one is for [TTGO version](https://www.aliexpress.com/item/32922106384.html) of the display.



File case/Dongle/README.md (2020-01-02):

# Dongle enclosure 

This type of enclosure is built around LilyGO&#174; & SoftRF [**T-Motion**](https://github.com/lyusupov/SoftRF/wiki/Dongle-Edition#required) LoRaWAN GNSS tracker board.<br>

**NOTICE**: This design is applicable for revision V1.1 (pre-production sample) of the T-Motion. Other revisions may or may not match.

# Exterior

It is recommended to start with 'Slim' variant of the design.<br>
It has almost no space for 'extras'. However it gives an access to the board pin headers and BOOT button.<br>



<br>

There is an alternative design for the lid of this enclosure to fit for [0.96" OLED I<sup>2</sup>C display](https://www.aliexpress.com/item/32922106384.html)<br>



<br>

and an alternative design for main 'body' to give some space for:

- [402030 Li-Ion battery](https://www.aliexpress.com/item/32909694329.html) and/or
- [I<sup>2</sup>C BMP280 barometric pressure sensor](https://www.aliexpress.com/item/32680504702.html).



<br>

# Instructions

3D print three STL files from this folder: **Body**, **Lid** and **Cap**. You may pick some printing advisories on [my Thingiverse page](https://www.thingiverse.com/thing:4033445).<br>
If you are unable to print the parts by yourself - you may consider to find an appropriate local 3D service provider and place an order with assistance of [Treatstock](http://www.treatstock.com) or [3DHubs](http://www.3dhubs.com/) portals.

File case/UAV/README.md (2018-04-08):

# UAV enclosure

This type of enclosure is designed to match dimensions and layout of UAV version of SoftRF.



# Instructions

3D print four STL files from this folder. You may pick some printing advisories on [my Thingiverse page](http://www.thingiverse.com/thing:2121817).



At first plug your RF module into the PCB and fasten the board to bottom of the enclosure with two 2.5x6 mm screws.



Plug NodeMCU or ESP32 DevKit into the board's socket. 



Fasten cover of the enclosure with four 2.5x10 mm screws.



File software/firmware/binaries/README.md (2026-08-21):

# First-time firmware installation procedure

- [NodeMCU](https://github.com/lyusupov/SoftRF/blob/master/software/firmware/binaries/README.md#nodemcu) (ESP8266)
- [ESP32](https://github.com/lyusupov/SoftRF/blob/master/software/firmware/binaries/README.md#esp32)
- [ESP32-S3](https://github.com/lyusupov/SoftRF/blob/master/software/firmware/binaries/README.md#esp32-s3)
- [ESP32-S2](https://github.com/lyusupov/SoftRF/blob/master/software/firmware/binaries/README.md#esp32-s2)
- [ESP32-C3](https://github.com/lyusupov/SoftRF/blob/master/software/firmware/binaries/README.md#esp32-c3)
- [ESP32-C6](https://github.com/lyusupov/SoftRF/blob/master/software/firmware/binaries/README.md#esp32-c6)
- [ESP32-P4](https://github.com/lyusupov/SoftRF/blob/master/software/firmware/binaries/README.md#esp32-p4)
- [S76G](https://github.com/lyusupov/SoftRF/wiki/AcSiP-S7xG-flashing-instructions#s76g) (STM32L073)
- [CC1352R](https://github.com/lyusupov/SoftRF/wiki/Uni-Edition.-Firmware-maintenance-procedures#initial-installation)
- [CubeCell](https://github.com/lyusupov/SoftRF/blob/master/software/firmware/binaries/README.md#cubecell) (ASR650x)
- [nRF52840](https://github.com/lyusupov/SoftRF/blob/master/software/firmware/binaries/README.md#nrf52840)
- [LPC4320](https://github.com/lyusupov/SoftRF/blob/master/software/firmware/binaries/README.md#lpc4320)
- [ASR6601](https://github.com/lyusupov/SoftRF/blob/master/software/firmware/binaries/README.md#asr6601)
- [RP2040](https://github.com/lyusupov/SoftRF/blob/master/software/firmware/binaries/README.md#rp2040)
- [RP2350](https://github.com/lyusupov/SoftRF/blob/master/software/firmware/binaries/README.md#rp2350)
- [STM32WLE5](https://github.com/lyusupov/SoftRF/blob/master/software/firmware/binaries/README.md#stm32wle5)
- [STM32WL55](https://github.com/lyusupov/SoftRF/blob/master/software/firmware/binaries/README.md#stm32wl55)
- [CH32](https://github.com/lyusupov/SoftRF/blob/master/software/firmware/binaries/README.md#ch32)
- [nRF54L15](https://github.com/lyusupov/SoftRF/blob/master/software/firmware/binaries/README.md#nrf54l15)
- [E80-900MBL](https://github.com/lyusupov/SoftRF/blob/master/software/firmware/binaries/README.md#e80-900mbl) (STM32F103)

## List by Model

Model|Instructions|Firmware folder
---|:---:|:---:
[Standalone Edition](https://github.com/lyusupov/SoftRF/wiki/Standalone-Edition)|[NodeMCU](https://github.com/lyusupov/SoftRF/blob/master/software/firmware/binaries/README.md#nodemcu)<br>[ESP32-C3](https://github.com/lyusupov/SoftRF/blob/master/software/firmware/binaries/README.md#esp32-c3)<br>[ESP32-C6](https://github.com/lyusupov/SoftRF/blob/master/software/firmware/binaries/README.md#esp32-c6)<br>[RP2350](https://github.com/lyusupov/SoftRF/blob/master/software/firmware/binaries/README.md#rp2350)|[NodeMCU](https://github.com/lyusupov/SoftRF/tree/master/software/firmware/binaries/NodeMCU/SoftRF)<br>[ESP32C3](https://github.com/lyusupov/SoftRF/tree/master/software/firmware/binaries/ESP32C3/SoftRF)<br>[ESP32C6](https://github.com/lyusupov/SoftRF/tree/master/software/firmware/binaries/ESP32C6/SoftRF)<br>[RP2350](https://github.com/lyusupov/SoftRF/tree/master/software/firmware/binaries/RP2350/SoftRF)
[Prime Edition Mk3](https://github.com/lyusupov/SoftRF/wiki/Prime-Edition-MkIII)|[ESP32-S3](https://github.com/lyusupov/SoftRF/blob/master/software/firmware/binaries/README.md#esp32-s3)|[ESP32S3](https://github.com/lyusupov/SoftRF/tree/master/software/firmware/binaries/ESP32S3/SoftRF/MassStorage)
[Prime Edition Mk2](https://github.com/lyusupov/SoftRF/wiki/Prime-Edition-MkII)|[ESP32](https://github.com/lyusupov/SoftRF/blob/master/software/firmware/binaries/README.md#esp32)|[ESP32](https://github.com/lyusupov/SoftRF/tree/master/software/firmware/binaries/ESP32/SoftRF/)
[Ham Edition](https://github.com/lyusupov/SoftRF/wiki/Ham-Edition)|[ESP32-S3](https://github.com/lyusupov/SoftRF/blob/master/software/firmware/binaries/README.md#esp32-s3)|[ESP32S3](https://github.com/lyusupov/SoftRF/tree/master/software/firmware/binaries/ESP32S3/SoftRF/MassStorage)
[Midi Edition](https://github.com/lyusupov/SoftRF/wiki/Midi-Edition)|[ESP32-S3](https://github.com/lyusupov/SoftRF/blob/master/software/firmware/binaries/README.md#esp32-s3)|[ESP32S3](https://github.com/lyusupov/SoftRF/tree/master/software/firmware/binaries/ESP32S3/SoftRF/MassStorage)
[Gizmo Edition](https://github.com/lyusupov/SoftRF/wiki/Gizmo-Edition)|[Web Flasher](https://github.com/lyusupov/SoftRF/wiki/Gizmo-Edition#quick-start)|[ESP32S3](https://github.com/lyusupov/SoftRF/tree/master/software/firmware/binaries/ESP32S3/SoftRF/OTA)
[Airventure Edition](https://github.com/lyusupov/SoftRF/wiki/Airventure-Edition)&nbsp;|[Web Flasher](https://github.com/lyusupov/SoftRF/wiki/Airventure-Edition#quick-start)|[ESP32S3](https://github.com/lyusupov/SoftRF/tree/master/software/firmware/binaries/ESP32S3/SoftRF/OTA)
[Concorde Edition](https://github.com/lyusupov/SoftRF/wiki/Concorde-Edition)&nbsp;|[ESP32-P4](https://github.com/lyusupov/SoftRF/blob/master/software/firmware/binaries/README.md#esp32-p4)|[ESP32P4](https://github.com/user-attachments/files/27507018/SoftRF-P4_merged.zip) <!-- (https://github.com/lyusupov/SoftRF/tree/master/software/firmware/binaries/ESP32P4/SoftRF/Merged) -->
[Nano Edition](https://github.com/lyusupov/SoftRF/wiki/Nano-Edition)|[ESP32-C3](https://github.com/lyusupov/SoftRF/blob/master/software/firmware/binaries/README.md#esp32-c3)|[ESP32C3](https://github.com/lyusupov/SoftRF/tree/master/software/firmware/binaries/ESP32C3/SoftRF)
[Badge Edition](https://github.com/lyusupov/SoftRF/wiki/Badge-Edition)|[nRF52840](https://github.com/lyusupov/SoftRF/blob/master/software/firmware/binaries/README.md#nrf52840)|[nRF52840](https://github.com/lyusupov/SoftRF/tree/master/software/firmware/binaries/nRF52840)
[Handheld Edition](https://github.com/lyusupov/SoftRF/wiki/Handheld-Edition)|[nRF52840](https://github.com/lyusupov/SoftRF/blob/master/software/firmware/binaries/README.md#nrf52840)|[nRF52840](https://github.com/lyusupov/SoftRF/tree/master/software/firmware/binaries/nRF52840)
[Stylus Edition](https://github.com/lyusupov/SoftRF/wiki/Stylus-Edition)&nbsp;|[nRF52840](https://github.com/lyusupov/SoftRF/blob/master/software/firmware/binaries/README.md#nrf52840)|[nRF52840](https://github.com/lyusupov/SoftRF/tree/master/software/firmware/binaries/nRF52840)
[Card Edition Mk3](https://github.com/lyusupov/SoftRF/wiki/Card-Edition-MkIII)&nbsp;|[nRF52840](https://github.com/lyusupov/SoftRF/blob/master/software/firmware/binaries/README.md#nrf52840)|[nRF52840](https://github.com/lyusupov/SoftRF/tree/master/software/firmware/binaries/nRF52840)
[Card Edition Mk2](https://github.com/lyusupov/SoftRF/wiki/Card-Edition-MkII)&nbsp;|[nRF52840](https://github.com/lyusupov/SoftRF/blob/master/software/firmware/binaries/README.md#nrf52840)|[nRF52840](https://github.com/lyusupov/SoftRF/tree/master/software/firmware/binaries/nRF52840)
[Card Edition](https://github.com/lyusupov/SoftRF/wiki/Card-Edition)|[nRF52840](https://github.com/lyusupov/SoftRF/blob/master/software/firmware/binaries/README.md#nrf52840)|[nRF52840](https://github.com/lyusupov/SoftRF/tree/master/software/firmware/binaries/nRF52840)
[Cozy Edition](https://github.com/lyusupov/SoftRF/wiki/Cozy-Edition)|[nRF52840](https://github.com/lyusupov/SoftRF/blob/master/software/firmware/binaries/README.md#nrf52840)|[nRF52840](https://github.com/lyusupov/SoftRF/tree/master/software/firmware/binaries/nRF52840)
[Solaris Edition](https://github.com/lyusupov/SoftRF/wiki/Solaris-Edition)&nbsp;|[nRF52840](https://github.com/lyusupov/SoftRF/blob/master/software/firmware/binaries/README.md#nrf52840)|[nRF52840](https://github.com/lyusupov/SoftRF/tree/master/software/firmware/binaries/nRF52840)
[Pocket Edition](https://github.com/lyusupov/SoftRF/wiki/Pocket-Edition)&nbsp;|[nRF52840](https://github.com/lyusupov/SoftRF/blob/master/software/firmware/binaries/README.md#nrf52840)|[nRF52840](https://github.com/lyusupov/SoftRF/tree/master/software/firmware/binaries/nRF52840)
[Dongle Edition](https://github.com/lyusupov/SoftRF/wiki/Dongle-Edition)|[S76G](https://github.com/lyusupov/SoftRF/wiki/AcSiP-S7xG-flashing-instructions#s76g)|[S76G](https://github.com/lyusupov/SoftRF/tree/master/software/firmware/binaries/STM32/S76G)
[ES Edition](https://github.com/lyusupov/SoftRF/wiki/ES-Edition)|[LPC4320](https://github.com/lyusupov/SoftRF/blob/master/software/firmware/binaries/README.md#lpc4320)|[LPC4320](https://github.com/lyusupov/SoftRF/tree/master/software/firmware/binaries/LPC4320)
[Lego Edition](https://github.com/lyusupov/SoftRF/wiki/Lego-Edition)|[RP2040](https://github.com/lyusupov/SoftRF/blob/master/software/firmware/binaries/README.md#rp2040)|[RP2040](https://github.com/lyusupov/SoftRF/tree/master/software/firmware/binaries/RP2040/SoftRF)
[Balkan Edition](https://github.com/lyusupov/SoftRF/wiki/Balkan-Edition)|[STM32WLE5](https://github.com/lyusupov/SoftRF/blob/master/software/firmware/binaries/README.md#stm32wle5)|[STM32WLE5](https://github.com/lyusupov/SoftRF/tree/master/software/firmware/binaries/STM32/WLE5)
[Labubu Edition](https://github.com/lyusupov/SoftRF/wiki/Labubu-Edition)&nbsp;|[STM32WL55](https://github.com/lyusupov/SoftRF/blob/master/software/firmware/binaries/README.md#stm32wl55)|[STM32WL55](https://github.com/lyusupov/SoftRF/tree/master/software/firmware/binaries/STM32/WL55)
[Retro Edition MkII](https://github.com/lyusupov/SoftRF/wiki/Retro-Edition-MkII)&nbsp;|[E80-900MBL](https://github.com/lyusupov/SoftRF/blob/master/software/firmware/binaries/README.md#e80-900mbl)|[E80-900MBL](https://github.com/lyusupov/SoftRF/tree/master/software/firmware/binaries/STM32/E80)
[Uni Edition](https://github.com/lyusupov/SoftRF/wiki/Uni-Edition)|[CC1352R](https://github.com/lyusupov/SoftRF/wiki/Uni-Edition.-Firmware-maintenance-procedures#initial-installation)|[CC1352](https://github.com/lyusupov/SoftRF/tree/master/software/firmware/binaries/CC13XX/CC1352)
[Mini Edition](https://github.com/lyusupov/SoftRF/wiki/Mini-Edition)|[CubeCell](https://github.com/lyusupov/SoftRF/blob/master/software/firmware/binaries/README.md#cubecell)|[ASR650x](https://github.com/lyusupov/SoftRF/tree/master/software/firmware/binaries/ASR650x)
[Octave Concept](https://github.com/lyusupov/SoftRF/wiki/Octave-Concept)|[ASR6601](https://github.com/lyusupov/SoftRF/blob/master/software/firmware/binaries/README.md#asr6601)|[ASR6601](https://github.com/lyusupov/SoftRF/tree/master/software/firmware/binaries/ASR6601)
[Raspberry Edition](https://github.com/lyusupov/SoftRF/wiki/Raspberry-Edition)||[RaspberryPi](https://github.com/lyusupov/SoftRF/tree/master/software/firmware/binaries/RaspberryPi)
[UAV Edition](https://github.com/lyusupov/SoftRF/wiki/UAV-Edition)|[NodeMCU](https://github.com/lyusupov/SoftRF/blob/master/software/firmware/binaries/README.md#nodemcu)|[NodeMCU](https://github.com/lyusupov/SoftRF/tree/master/software/firmware/binaries/NodeMCU/SoftRF)
[Academy Edition](https://github.com/lyusupov/SoftRF/wiki/Academy-Edition)|N/A<sup>1</sup>|N/A<sup>1</sup>
[Eco Edition](https://github.com/lyusupov/SoftRF/wiki/Eco-Edition)|N/A<sup>2</sup>|N/A<sup>2</sup>

<sup>1</sup> - since primary purpose of the **Academy Edition** is education - we do not provide firmware binaries for this model. Students and a teacher are responsible to [build and install the SoftRF firmware](https://github.com/lyusupov/SoftRF/blob/master/software/firmware/source/README.md) ( [SAMD21](https://github.com/lyusupov/SoftRF/tree/master/software/firmware/source#samd21) or [RA4M1](https://github.com/lyusupov/SoftRF/edit/master/software/firmware/source#ra4m1) ) from source code by themselves ;<br>
<sup>2</sup> - users of **Eco Edition** should build and install the SoftRF firmware from source code as well.<br>
<br>

Model|Instructions|Firmware folder
---|:---:|:---:
[SkyView EZ](https://github.com/lyusupov/SoftRF/wiki/SkyView-EZ)|[ESP32](https://github.com/lyusupov/SoftRF/wiki/SkyView.-Quick-start)|[ESP32](https://github.com/lyusupov/SoftRF/tree/master/software/firmware/binaries/ESP32/SkyView)
[SkyView Pico](https://github.com/lyusupov/SoftRF/wiki/SkyView-Pico)|[RP2040](https://github.com/lyusupov/SoftRF/wiki/SkyView-Pico.-Quick-start#raspberry-pico-w)<br>[RP2350](https://github.com/lyusupov/SoftRF/wiki/SkyView-Pico.-Quick-start#raspberry-pico-w)<br>[ESP32-S3](https://github.com/lyusupov/SoftRF/wiki/SkyView-Pico.-Quick-start#banana-bpi-picow-s3)|[RP2040](https://github.com/lyusupov/SoftRF/tree/master/software/firmware/binaries/RP2040/SkyView)<br>[RP2350](https://github.com/lyusupov/SoftRF/tree/master/software/firmware/binaries/RP2350/SkyView)<br>[ESP32S3](https://github.com/lyusupov/SoftRF/tree/master/software/firmware/binaries/ESP32S3/SkyView)
[WebTop Serial](https://github.com/lyusupov/SoftRF/wiki/WebTop-Serial-adapter)|[NodeMCU](https://github.com/lyusupov/SoftRF/tree/master/software/firmware/binaries#nodemcu)|[NodeMCU](https://github.com/lyusupov/SoftRF/tree/master/software/firmware/binaries/NodeMCU/WebTop)
[WebTop USB](https://github.com/lyusupov/SoftRF/wiki/WebTop-USB)|[ESP32-S2](https://github.com/lyusupov/SoftRF/blob/master/software/firmware/binaries/README.md#esp32-s2)|[ESP32S2](https://github.com/lyusupov/SoftRF/tree/master/software/firmware/binaries/ESP32S2/WebTop)
[USB to Bluetooth](https://github.com/lyusupov/SoftRF/wiki/USB-to-Bluetooth-adapter)|[XIAO](https://github.com/lyusupov/SoftRF/wiki/USB-to-Bluetooth-adapter#quick-start)|[SAMD21](https://github.com/lyusupov/SoftRF/tree/master/software/firmware/binaries/SAMD21/USB_Bluetooth)
<br>

## NodeMCU

### Select NodeMCU COM port



### Select firmware file



### Start flashing cycle



### Wait for completion



## ESP32

1. Take ESP32 flash download tool from this location: http://www.espressif.com/en/support/download/other-tools <br>
You might also need to install:
* a [driver for the CP210X USB to UART bridge from Silicon Labs](https://www.silabs.com/products/development-tools/software/usb-to-uart-bridge-vcp-drivers) or
* [CH9102F driver](https://github.com/Xinyuan-LilyGO/CH9102_Driver)<br>
prior to first use of the ESP32 tool ;
2. Download an appropriate version of SoftRF firmware from [this location](https://github.com/lyusupov/SoftRF/tree/master/software/firmware/binaries/ESP32) and unzip the archive ;

3. Select COM port, enter partition files and addresses, select options ;<br>

   Here is an example:<br>



4. Press **START** button and wait for completion.

For some boards you may need to push **BOOT** button in order to activate flash download mode.<br>
"Stock" modules may also require to apply full flash memory erase (use **ERASE** UI "button") prior to first flashing with SoftRF's firmware.<br>
One may need to reduce BAUD rate down to 115200 bps.

<br>

## CubeCell

1. Take **CubeCellflash** for Windows <sub>_(Linux and MacOS variants are also available there)_</sub> download tool from this location: https://resource.heltec.cn/download/<br>
You might also need to install a [driver for the CP210X USB to UART bridge from Silicon Labs](https://www.silabs.com/products/development-tools/software/usb-to-uart-bridge-vcp-drivers) prior to first use of the CubeCellflash tool ;
2. Download an appropriate version of SoftRF firmware from [this location](https://github.com/lyusupov/SoftRF/tree/master/software/firmware/binaries/ASR650x) and unzip the archive ;



3. Use Windows command line tool to execute firmware flashing procedure as follows:



<br>

## nRF52840

The T-Echo board typically comes with factory pre-installed [Adafruit_nRF52_Bootloader](https://github.com/adafruit/Adafruit_nRF52_Bootloader).<br>
The Bootloader is capable to self-program an application firmware into the device. In order to simplify the firmware transfer, the bootloader emulates a "USB Mass Storage" interface.

1. Download an appropriate version of SoftRF firmware from [this location](https://github.com/lyusupov/SoftRF/tree/master/software/firmware/binaries/nRF52840/SoftRF/MassStorage) ;

2. Connect the SoftRF Badge Edition device to your PC by means of a USB cable (Type-A <-> Type-C) ;

3. Enter into Adafruit bootloader USB Mass Storage mode
   Device|Action
   ---|---
   LilyGO T-Echo<br>LilyGO T-Echo Card<br>LilyGO T-Impulse Plus<br>Heltec T114<br>Elecrow M1 and M6|double click (within 0.5 seconds) onto the SoftRF device RESET button
   Seeed T1000-E<br>Seeed X1|connect twice (within 0.5 seconds) the USB cable while holding the device button been pressed
   Elecrow M3|press and keep holding the device button for more than 20 seconds

&nbsp;&nbsp;&nbsp;&nbsp;&nbsp;&nbsp;&nbsp;&nbsp;A virtual disk with a device specific label should appear in your "File manager" afterwards.<br>

&nbsp;&nbsp;&nbsp;&nbsp;&nbsp;&nbsp;&nbsp;&nbsp;For **LilyGO T-Echo** the label is &nbsp; **TECHOBOOT** (or **NRF52BOOT**)<br>
&nbsp;&nbsp;&nbsp;&nbsp;&nbsp;&nbsp;&nbsp;&nbsp;For **LilyGO T-Echo Card**  &nbsp;&nbsp;&nbsp;&nbsp;&nbsp;&nbsp;&nbsp;&nbsp;&nbsp;&nbsp;&nbsp; **NRF52BOOT**<br>
&nbsp;&nbsp;&nbsp;&nbsp;&nbsp;&nbsp;&nbsp;&nbsp;For **LilyGO T-Impulse Plus**  &nbsp;&nbsp;&nbsp;&nbsp;&nbsp;&nbsp;&nbsp; **NRF52BOOT**<br>
&nbsp;&nbsp;&nbsp;&nbsp;&nbsp;&nbsp;&nbsp;&nbsp;For **Seeed T1000-E** &nbsp;&nbsp;&nbsp;&nbsp;&nbsp;&nbsp;&nbsp;&nbsp;&nbsp;&nbsp;&nbsp;&nbsp;&nbsp;&nbsp;&nbsp;&nbsp;&nbsp;&nbsp;&nbsp; **T1000-E**<br>
&nbsp;&nbsp;&nbsp;&nbsp;&nbsp;&nbsp;&nbsp;&nbsp;For **Seeed X1** &nbsp;&nbsp;&nbsp;&nbsp;&nbsp;&nbsp;&nbsp;&nbsp;&nbsp;&nbsp;&nbsp;&nbsp;&nbsp;&nbsp;&nbsp;&nbsp;&nbsp;&nbsp;&nbsp;&nbsp;&nbsp;&nbsp;&nbsp;&nbsp;&nbsp;&nbsp;&nbsp;&nbsp; **X1**<br>
&nbsp;&nbsp;&nbsp;&nbsp;&nbsp;&nbsp;&nbsp;&nbsp;For **Heltec T114** &nbsp;&nbsp;&nbsp;&nbsp;&nbsp;&nbsp;&nbsp;&nbsp;&nbsp;&nbsp;&nbsp;&nbsp;&nbsp;&nbsp;&nbsp;&nbsp;&nbsp;&nbsp;&nbsp;&nbsp;&nbsp;&nbsp;&nbsp;&nbsp;&nbsp; **HT-n5262**<br>
&nbsp;&nbsp;&nbsp;&nbsp;&nbsp;&nbsp;&nbsp;&nbsp;For **Elecrow M1**&nbsp;&nbsp;&nbsp;&nbsp;&nbsp;&nbsp;&nbsp;&nbsp;&nbsp;&nbsp;&nbsp;&nbsp;&nbsp;&nbsp;&nbsp;&nbsp;&nbsp;&nbsp;&nbsp;&nbsp;&nbsp;&nbsp;&nbsp;&nbsp;&nbsp;&nbsp; **ELECROWBOOT**<br>
&nbsp;&nbsp;&nbsp;&nbsp;&nbsp;&nbsp;&nbsp;&nbsp;For **Elecrow M3**&nbsp;&nbsp;&nbsp;&nbsp;&nbsp;&nbsp;&nbsp;&nbsp;&nbsp;&nbsp;&nbsp;&nbsp;&nbsp;&nbsp;&nbsp;&nbsp;&nbsp;&nbsp;&nbsp;&nbsp;&nbsp;&nbsp;&nbsp;&nbsp;&nbsp; **ELECROWBOOT** (or **ThinkNodeM3**)<br>
&nbsp;&nbsp;&nbsp;&nbsp;&nbsp;&nbsp;&nbsp;&nbsp;For **Elecrow M6** &nbsp;&nbsp;&nbsp;&nbsp;&nbsp;&nbsp;&nbsp;&nbsp;&nbsp;&nbsp;&nbsp;&nbsp;&nbsp;&nbsp;&nbsp;&nbsp;&nbsp;&nbsp;&nbsp;&nbsp;&nbsp;&nbsp;&nbsp;&nbsp; **ThinkNodeM6**<br>

4. Drag the downloaded firmware file by your pointing device (mouse, trackball,...) , then drop it into **TECHOBOOT** / **NRF52BOOT** / **T1000-E** / **X1** / **HT-n5262** / **ELECROWBOOT**  / **ThinkNodeM3** / **ThinkNodeM6** disk. Wait until the file transfer is complete.

<br>



<br>

## LPC4320

For Linux and Mac OS X users, you will need a few tools installed on your computer before you begin:

* [dfu-util](http://dfu-util.sourceforge.net/) 0.8 or newer - Used to load and run the stock HackRF One firmware from RAM. dfu-util 0.8 is recommended, as it is the most extensively tested with the HackRF One hardware and build software.
* [hackrf](https://github.com/greatscottgadgets/hackrf) - All you need is the host tools, specifically, hackrf_spiflash.

### Backup of factory firmware

```
$ hackrf_spiflash -v -r HackRF_One_factory_firmware.bin
Reading 256 bytes from 0x000000.
Reading 256 bytes from 0x000100.

< ... skipped ... >

$ ls -la HackRF_One_factory_firmware.bin
-rw-r--r-- 1 pi pi 1048576 Nov  4 10:18 HackRF_One_factory_firmware.bin
```

### Flashing

1. Download an appropriate version of SoftRF firmware from [this location](https://github.com/lyusupov/SoftRF/tree/master/software/firmware/binaries/LPC4320) ;
2. Plug the HackRF One into a PC USB slot while holding down DFU button (the button closer to antenna jack). Release the DFU button, then execute:

```
$ dfu-util -D hackrf_one_usb.dfu --reset
$ hackrf_spiflash -v -w SoftRF-firmware-v1.1-LPC4320.bin
```

### Restore of HackRF One firmware

Plug the HackRF One into a PC USB slot while holding down DFU button (the button closer to antenna jack). Release the DFU button, then execute:

```
$ dfu-util -D hackrf_one_usb.dfu --reset
$ hackrf_spiflash -v -w HackRF_One_factory_firmware.bin
```

<br>

## ASR6601

1. Download an appropriate version of SoftRF firmware from [this location](https://github.com/lyusupov/SoftRF/tree/master/software/firmware/binaries/ASR6601) ;
2. Take a copy of **tremo_loader.py** script from [ASR SDK](https://github.com/asrlora/asr_lora_6601/raw/master/build/scripts/tremo_loader.py) ;
3. Connect an appropriate USB-Serial adapter to ASR6601 MCU pins as follows:

Adapter|MCU
---|---
GND|GND
3V3|VCC
TX|GPIO16
RX|GPIO17
DTR&nbsp;<sup>3</sup>|GPIO2
RTS|RESET

<sup>3</sup> - certain USB-Serial adapters may require to **invert DTR** signal either in hardware or in the Python script.<br>

4. Plug the USB-Serial adapter into spare USB slot of your PC ;
5. Use the loader tool to read the serial number of the MCU. This is a safety action to make sure that all the connections are good ;

```
$ python tremo_loader.py --port /dev/ttyUSB0 read_sn
Connecting...
Connected
The SN is: 0c15458cc5fb3201
```

6. Write the SoftRF firmware binary into flash memory of the ASR6601.

```
$ python tremo_loader.py --port /dev/ttyUSB0 flash 0x08000000 SoftRF-firmware-v1.1-ASR6601.bin
Connecting...
Connected
('send: ', 512)
('send: ', 1024)
('send: ', 1536)
('send: ', 2048)
('send: ', 2560)
('send: ', 3072)

< ... skipped ... >

('send: ', 102400)
('send: ', 102912)
('send: ', 103228)
Download files successfully
```
<br>

## RP2040

Every RAK11310 WisBlock Core module has built-in (ROM) bootloader.<br>
The bootloader is capable to self-program an application firmware into the device. In order to simplify the firmware transfer, the bootloader emulates a "USB Mass Storage" interface.

1. Download an appropriate version of SoftRF firmware from [this location](https://github.com/lyusupov/SoftRF/tree/master/software/firmware/binaries/RP2040/SoftRF) ;

2. Plug RAK11310 WisBlock Core module into RAK5005-O WisBlock Base ;

3. Connect the RAK5005-O to your PC by means of a USB cable (Type-A <-> micro Type-B) ;

4. Press and keep holding BOOT button of RAK11310 Core module ;

5. Press and release RESET button on RAK5005-O Base ;

6. Release BOOT button of RAK11310 module. A virtual disk with **RPI-RP2** label should appear in your "File manager" afterwards ;

7. Drag the downloaded firmware file by your pointing device (mouse, trackball,...) , then drop it into **RPI-RP2** disk. Wait until the file transfer is complete.

<br>



<br>

## RP2350

1. Take an appropriate version of the SoftRF firmware from [this location](https://github.com/lyusupov/SoftRF/tree/master/software/firmware/binaries/RP2350/SoftRF) ;

2. Un-zip the firmware file been downloaded ;

3. Press and keep holding BOOT button of the Raspberry **Pico 2W** ;

4. Connect the **Pico 2W** to your PC by means of a USB cable (Type-A <-> micro Type-B) ;

5. Release BOOT button of **Pico 2W**. A virtual disk with **RPI-RP2** label should appear in your "File manager" afterwards ;

6. Drag the downloaded firmware file by your pointing device (mouse, trackball,...) , then drop it into **RPI-RP2** disk. Wait until the file transfer is complete ;



<br>

## ESP32-S2

1. Take **esptool-v4.4-win64.zip** flash tool for Windows from this location: [https://github.com/espressif/esptool/releases/tag/v4.4](https://github.com/espressif/esptool/releases/tag/v4.4) and unzip the archive ;
2. Download an appropriate version of WebTop firmware from [this location](https://github.com/lyusupov/SoftRF/tree/master/software/firmware/binaries/ESP32S2/WebTop) and unzip the archive ;
3. Connect the ESP32-S2 board into spare USB slot of your Windows PC ;
4. Press and keep holding BOOT button of the ESP32-S2 board ;
5. Press and release RESET button on the ESP32-S2 board ;
6. Release BOOT button of the ESP32-S2 board. A virtual COM port should appear in "Device Manager" afterwards ;
7. Execute **essptool.exe** utility as folows :

<br>



<br>

## STM32WLE5

1. Take pre-built **OpenOCD** tool for Windows from this location: https://gnutoolchains.com/arm-eabi/openocd/ and extract the archive ;
2. Download an appropriate version of SoftRF firmware from [this location](https://github.com/lyusupov/SoftRF/tree/master/software/firmware/binaries/STM32/WLE5) ;
3. Connect the SoftRF Balkan Edition device to your PC by means of a USB cable ;
4. Use Windows command line tool to execute firmware flashing procedure as follows:

```
C:\OpenOCD-20211118-0.11.0>.\bin\openocd.exe -f interface/cmsis-dap.cfg -c "cmsis_dap_vid_pid 0x15ba 0x0044" -c "transport select swd" -c "adapter speed 4000" -f "target/stm32wlx.cfg" -c "program SoftRF-firmware-v1.2-WLE5.bin 0x08000000"
```

Example:<br>



<br>

## STM32WL55

1. Download and install **STM32CubeProgrammer** tool for Windows from this location: https://www.st.com/en/development-tools/stm32cubeprog.html ;
2. Download an appropriate version of SoftRF firmware from [this location](https://github.com/lyusupov/SoftRF/tree/master/software/firmware/binaries/STM32/WL55) ;
3. Connect the SoftRF Labubu Edition device to your PC by means of a USB cable ;
4. Enter into Device Firmware Update (DFU) mode by
    * press device `BOOT` button ,
    * press `RST`button ,
    * release `RST`button ,
    * release `BOOT`button
6. Open up  **STM32CubeProgrammer** application
    * Select UART download mode
    * Select COM port the device is connected to
    * Select Negative pulse mode for RTS and DTR
    * Clock onto `Connect` button



<br>

7. When the device gets connectected successfully - click on the `+` sign to add the firmware binary been downloaded at Step 2



<br>

8. Click `Download` to start the device firmware update
   


<br>

## ESP32-S3

The T-Beam Supreme board typically comes with factory pre-installed [**TinyUF2** bootloader](https://github.com/adafruit/tinyuf2/tree/master/ports/espressif#readme).<br>
The Bootloader is capable to self-program an application firmware into the device. In order to simplify the firmware transfer, the bootloader emulates a "USB Mass Storage" interface.

1. Download an appropriate version of SoftRF firmware from [this location](https://github.com/lyusupov/SoftRF/tree/master/software/firmware/binaries/ESP32S3/SoftRF/MassStorage) and extract the archive ;

2. Connect the SoftRF device to your PC by means of a USB cable (Type-A <-> Type-C) ;

3. Press and release RESET button of the SoftRF device. Immediately (within 1 second) press and release the BOOT button. One should see this message on the OLED display.

&nbsp;&nbsp;&nbsp;&nbsp; For **T-Beam Supreme**:



&nbsp;&nbsp;&nbsp;&nbsp; For **T-TWR Plus**:



&nbsp;&nbsp;&nbsp;&nbsp; This white LED on the **Heltec Tracker** will start to flicker:



<br>

&nbsp;&nbsp;&nbsp;&nbsp;&nbsp;&nbsp;&nbsp;&nbsp;A virtual disk with a device specific label should appear in your "File manager" afterwards.<br>

&nbsp;&nbsp;&nbsp;&nbsp;&nbsp;&nbsp;&nbsp;&nbsp;For **T-Beam Supreme** the label is &nbsp; **TBEAMBOOT**<br>
&nbsp;&nbsp;&nbsp;&nbsp;&nbsp;&nbsp;&nbsp;&nbsp;For **T-TWR Plus** &nbsp;&nbsp;&nbsp;&nbsp;&nbsp;&nbsp;&nbsp;&nbsp;&nbsp;&nbsp;&nbsp;&nbsp;&nbsp;&nbsp;&nbsp;&nbsp;&nbsp;&nbsp;&nbsp;&nbsp;&nbsp;&nbsp;&nbsp;&nbsp;&nbsp;&nbsp;&nbsp;&nbsp;&nbsp; **TWRBOOT**<br>
&nbsp;&nbsp;&nbsp;&nbsp;&nbsp;&nbsp;&nbsp;&nbsp;For **Heltec Tracker** &nbsp;&nbsp;&nbsp;&nbsp;&nbsp;&nbsp;&nbsp;&nbsp;&nbsp;&nbsp;&nbsp;&nbsp;&nbsp;&nbsp;&nbsp;&nbsp;&nbsp;&nbsp;&nbsp;&nbsp;&nbsp;&nbsp;&nbsp;&nbsp;&nbsp; **HTBOOT**<br>

4. Drag the downloaded .uf2 firmware file by your pointing device (mouse, trackball,...) , then drop it into **TBEAMBOOT** / **TWRBOOT** / **HTBOOT** disk. Wait until the file transfer is complete.

<br>



<br>

## ESP32-C3

1. Take ESP32 flash download tool from this location: http://www.espressif.com/en/support/download/other-tools <br>

2. Download an appropriate version of SoftRF firmware from [this location](https://github.com/lyusupov/SoftRF/tree/master/software/firmware/binaries/ESP32C3/SoftRF) and unzip the archive ; <br>

3. Connect the ESP32-C3 based device to your PC by means of a USB cable ;

4. Execute the tool; Select **ESP32-C3** Chip Type, **Develop** WorkMode and **UART** LoadMode ; <br>

5. Select COM port, enter partition files and addresses, select options ; <br>

   Here is an example:<br>



6. Press **START** button and wait for completion.

"Stock" devices may also require to apply full flash memory erase (use **ERASE** UI "button") prior to first flashing with SoftRF's firmware.

<br>

## ESP32-C6

1. Take ESP32 flash download tool from this location: http://www.espressif.com/en/support/download/other-tools <br>

2. Download an appropriate version of SoftRF firmware from [this location](https://github.com/lyusupov/SoftRF/tree/master/software/firmware/binaries/ESP32C6/SoftRF) and unzip the archive ; <br>

3. Connect the ESP32-C6 based device to your PC by means of a USB cable ;

4. Execute the tool; Select **ESP32-C6** Chip Type, **Develop** WorkMode and **UART** LoadMode ; <br>

5. Select COM port, enter partition files and addresses, select options ; <br>

   Here is an example:<br>



6. Press **START** button and wait for completion.

"Stock" devices may also require to apply full flash memory erase (use **ERASE** UI "button") prior to first flashing with SoftRF's firmware.

<br>

## ESP32-P4
<!--
1. Take ESP32 flash download tool from this location: http://www.espressif.com/en/support/download/other-tools <br>

2. Download an appropriate version of SoftRF firmware from [this location](https://github.com/lyusupov/SoftRF/tree/master/software/firmware/binaries/ESP32P4/SoftRF) and unzip the archive ; <br>

3. Connect the ESP32-P4 based device to your PC by means of a USB cable ;

4. Execute the tool; Select **ESP32-P4** Chip Type, **Develop** WorkMode and **UART** LoadMode ; <br>

5. Select COM port, enter partition files and addresses, select options ; <br>

   Here is an example:<br>

![](https://github.com/lyusupov/SoftRF/raw/master/documents/images/Standalone-ESP32P4-2.jpg)

6. Press **START** button and wait for completion.

"Stock" devices may also require to apply full flash memory erase (use **ERASE** UI "button") prior to first flashing with SoftRF's firmware.  -->

1. Download an appropriate version of SoftRF firmware from [this location](https://github.com/user-attachments/files/27507018/SoftRF-P4_merged.zip) <!--(https://github.com/lyusupov/SoftRF/tree/master/software/firmware/binaries/ESP32P4/SoftRF) --> and unzip the archive ; <br>
2. Connect the ESP32-P4 based device to your PC by means of a USB cable ; <br>
3. Open up this website in Chrome or Edge browser: https://espressif.github.io/esptool-js/ ; <br>
4. Install SoftRF firmware BIN file into your ESP32-P4 device. Use this picture as an illustration.



<br>
<br>

## CH32

1. Take **WCHISPStudio** tool from [this location](https://www.wch-ic.com/downloads/WCHISPTool_Setup_exe.html) ;
2. Install the **WCHISPStudio** tool ;
3. Download an appropriate version of SoftRF firmware from [this location](https://github.com/lyusupov/SoftRF/tree/master/software/firmware/binaries/CH32/SoftRF) ;
4. Connect the CH32 based device to your PC by means of a USB cable ;
5. Press and hold **RESET** button, press and hold **BOOT0** button, release **RESET**, release **BOOT0** ;
6. Follow instructions in the operating manual for **WCHISPStudio** tool to complete the firmware installation procedure. Use this picture as an illustration.



<br>

## nRF54L15

1. Download an appropriate version of SoftRF firmware from [this location](https://github.com/lyusupov/SoftRF/tree/master/software/firmware/binaries/nRF54L15/SoftRF) and unzip the archive ;
2. Connect the nRF54L15 based device to your PC by means of a USB cable ;
3. Open up this website in Chrome or Edge browser: https://freeocd.org/ and launch the **FreeOCD WebDebugger** app ;
4. Install SoftRF firmware HEX file into your nRF54L15 device. Use this picture as an illustration.



<br>
<br>

## E80-900MBL

1. Take pre-built **OpenOCD** tool for Windows from this location: https://gnutoolchains.com/arm-eabi/openocd/ and extract the archive ;
2. Download an appropriate version of SoftRF firmware from [this location](https://github.com/lyusupov/SoftRF/tree/master/software/firmware/binaries/STM32/E80) ;
3. Connect the SoftRF Retro Edition Mark II device to your CMSIS-DAP ( "DAPLINK" ) adapter ;



4. Connect the DAPLINK adapter to your PC by means of a USB cable ;
5. Use Windows command line tool to execute firmware flashing procedure as follows:

```
C:\OpenOCD-20211118-0.11.0>.\bin\openocd.exe -f interface\cmsis-dap.cfg -f board\stm32f103c8_blue_pill.cfg -c "program SoftRF-firmware-v1.9.1-E80.bin 0x08000000 verify reset exit"
```

Example:<br>



<br>

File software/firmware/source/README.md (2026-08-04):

# SoftRF firmware build instructions

* [NodeMCU](https://github.com/lyusupov/SoftRF/tree/master/software/firmware/source#nodemcu)<br>
* [ESP32](https://github.com/lyusupov/SoftRF/tree/master/software/firmware/source#esp32)<br>
* [Raspberry Pi](https://github.com/lyusupov/SoftRF/tree/master/software/firmware/source#raspberry-pi)<br>
* [CC13X0](https://github.com/lyusupov/SoftRF/tree/master/software/firmware/source#cc13x0)<br>
* [STM32](https://github.com/lyusupov/SoftRF/tree/master/software/firmware/source#stm32)<br>
* [ASR650x](https://github.com/lyusupov/SoftRF/tree/master/software/firmware/source#asr650x)<br>
* [nRF52840](https://github.com/lyusupov/SoftRF/tree/master/software/firmware/source#nrf52840)<br>
* [SAMD21](https://github.com/lyusupov/SoftRF/tree/master/software/firmware/source#samd21)<br>
* [RP2040](https://github.com/lyusupov/SoftRF/tree/master/software/firmware/source#rp2040)<br>
* [RA4M1](https://github.com/lyusupov/SoftRF/edit/master/software/firmware/source#ra4m1)<br>
* [RP2350](https://github.com/lyusupov/SoftRF/tree/master/software/firmware/source#rp2350)<br>
* [Luckfox Lyra](https://github.com/lyusupov/SoftRF/tree/master/software/firmware/source#luckfox-lyra)<br>
* [nRF54L15](https://github.com/lyusupov/SoftRF/tree/master/software/firmware/source#nrf54l15)<br>

<br>

## NodeMCU

1. Follow [these official instructions](https://github.com/esp8266/Arduino#installing-with-boards-manager)
  to install Arduino IDE and latest Arduino ESP8266 Core
2. Become familiar with IDE and **NodeMCU** by building and uploading of a basic **Blink** sketch:<br>

    _File_ -> _Examples_ -> _ESP8266_ -> _Blink_ <br>

    then<br>

    _Sketch_ -> _Upload_

3. When you are done with the lesson, close your **Arduino** application
4. open ``<My Documents>`` (Windows) , ``<Home>`` (Linux) or ``<Documents>`` (MacOS) directory
5. create **Arduino** sub-directory
6. transfer full content of **SoftRF** and **libraries** GitHub folders into the sub-directory:

    [SoftRF](https://github.com/lyusupov/SoftRF/tree/master/software/firmware/source/SoftRF) &nbsp;&nbsp;**-->** ``<My Documents>``/Arduino/SoftRF <br>
    [libraries](https://github.com/lyusupov/SoftRF/tree/master/software/firmware/source/libraries) **-->** ``<My Documents>``/Arduino/libraries <br>

7. start **Arduino** application again
8. open **SoftRF** sketch from _File_ -> _Open_ menu
9. Select _Tools_ -> _Board_ -> _NodeMCU_ _1.0_
10. in _Tools_ -> _lwIP Variant_  -> _v2 Higher Bandwidth_
11. _Sketch_ -> _Upload_

<br>

## ESP32

1. Follow [these official instructions](https://github.com/espressif/arduino-esp32/blob/master/docs/source/installing.rst)
  to install Arduino IDE and a **certain version** of Arduino ESP32 Core<!--[**stable** Arduino ESP32 Core](https://github.com/espressif/arduino-esp32/releases/tag/1.0.5) (1.0.5)--><br>
    For **ESP32**:&nbsp;&nbsp;&nbsp;&nbsp;&nbsp;&nbsp;&nbsp;&nbsp;&nbsp;&nbsp;&nbsp;&nbsp;&nbsp;&nbsp;&nbsp;&nbsp;&nbsp;[**1.0.5**](https://github.com/espressif/arduino-esp32/releases/tag/1.0.5)<br>
    For **ESP32-S2**:&nbsp;&nbsp;&nbsp;&nbsp;&nbsp;&nbsp;&nbsp;&nbsp;&nbsp;&nbsp;&nbsp;[**2.0.9**](https://github.com/espressif/arduino-esp32/releases/tag/2.0.9)<br>
    For **ESP32-S3**:&nbsp;&nbsp;&nbsp;&nbsp;&nbsp;&nbsp;&nbsp;&nbsp;&nbsp;&nbsp;&nbsp;[**2.0.9**](https://github.com/espressif/arduino-esp32/releases/tag/2.0.9)<br>
    For **ESP32-C3**:&nbsp;&nbsp;&nbsp;&nbsp;&nbsp;&nbsp;&nbsp;&nbsp;&nbsp;&nbsp;&nbsp;[**2.0.9**](https://github.com/espressif/arduino-esp32/releases/tag/2.0.9)<br>
    For **ESP32-C6**:&nbsp;&nbsp;&nbsp;&nbsp;&nbsp;&nbsp;&nbsp;&nbsp;&nbsp;&nbsp;&nbsp;[**3.0.7**](https://github.com/espressif/arduino-esp32/releases/tag/3.0.7)<br>
    For **ESP32-P4**:&nbsp;&nbsp;&nbsp;&nbsp;&nbsp;&nbsp;&nbsp;&nbsp;&nbsp;&nbsp;&nbsp;[**3.3.8**](https://github.com/espressif/arduino-esp32/releases/tag/3.3.8)<br>
    For **ESP32-C5**:&nbsp;&nbsp;&nbsp;&nbsp;&nbsp;&nbsp;&nbsp;&nbsp;&nbsp;&nbsp;&nbsp;[**3.3.8**](https://github.com/espressif/arduino-esp32/releases/tag/3.3.8)<br>

2. Become familiar with IDE and **DoIt ESP32 DevKit** by building and uploading of a basic **Blink** sketch:<br>
```
int ledPin = 2; // use pin 14 for TTGO T-Beam rev.05 or higher   

void setup()
{
    pinMode(ledPin, OUTPUT);
    Serial.begin(115200);
}

void loop()
{
    Serial.println("Hello, world!");
    digitalWrite(ledPin, HIGH);
    delay(500);
    digitalWrite(ledPin, LOW);
    delay(500);
}
```

3. When you are done with the lesson, close your **Arduino** application
4. open ``<My Documents>`` (Windows) , ``<Home>`` (Linux) or ``<Documents>`` (MacOS) directory
5. create **Arduino** sub-directory
6. transfer full content of **SoftRF** and **libraries** GitHub folders into the sub-directory:

    [SoftRF](https://github.com/lyusupov/SoftRF/tree/master/software/firmware/source/SoftRF) &nbsp;&nbsp;**-->** ``<My Documents>``/Arduino/SoftRF <br>
    [libraries](https://github.com/lyusupov/SoftRF/tree/master/software/firmware/source/libraries) **-->** ``<My Documents>``/Arduino/libraries <br>

7. start **Arduino** application again
8. open **SoftRF** sketch from _File_ -> _Open_ menu
9. For **ESP32**:<br>
    &nbsp;&nbsp;&nbsp;&nbsp;&nbsp;&nbsp;Select _Tools_ -> _Board_ ->  _ESP32_ _Dev_ _Module_<br>
    For **ESP32-S2**:<br>
    &nbsp;&nbsp;&nbsp;&nbsp;&nbsp;&nbsp;Select _Tools_ -> _Board_ ->  _ESP32-S2_ _Dev_ _Module_<br>
    For **ESP32-S3**:<br>
    &nbsp;&nbsp;&nbsp;&nbsp;&nbsp;&nbsp;Select _Tools_ -> _Board_ ->  _ESP32-S3_ _Dev_ _Module_<br>
    For **ESP32-C3**:<br>
    &nbsp;&nbsp;&nbsp;&nbsp;&nbsp;&nbsp;Select _Tools_ -> _Board_ ->  _ESP32-C3_ _Dev_ _Module_<br>
    For **ESP32-C5**:<br>
    &nbsp;&nbsp;&nbsp;&nbsp;&nbsp;&nbsp;Select _Tools_ -> _Board_ ->  _ESP32-C5_ _Dev_ _Module_<br>
    For **ESP32-C6**:<br>
    &nbsp;&nbsp;&nbsp;&nbsp;&nbsp;&nbsp;Select _Tools_ -> _Board_ ->  _ESP32-C6_ _Dev_ _Module_<br>
    For **ESP32-P4**:<br>
    &nbsp;&nbsp;&nbsp;&nbsp;&nbsp;&nbsp;Select _Tools_ -> _Board_ ->  _ESP32-P4_ _Dev_ _Module_<br>
10. Select _Tools_ -> _Flash_ _Mode_ ->  _DIO_
11. For **ESP32**:<br>
    For **ESP32-S2**:<br>
    For **ESP32-S3**:<br>
    For **ESP32-C3**:<br>
    For **ESP32-C6**:<br>
    &nbsp;&nbsp;&nbsp;&nbsp;&nbsp;&nbsp;Select _Tools_ -> _Flash_ _Size_ ->  _4MB_<br>
    For **ESP32-C5**:<br>
    &nbsp;&nbsp;&nbsp;&nbsp;&nbsp;&nbsp;Select _Tools_ -> _Flash_ _Size_ ->  _8MB_<br>
    For **ESP32-P4**:<br>
    &nbsp;&nbsp;&nbsp;&nbsp;&nbsp;&nbsp;Select _Tools_ -> _Flash_ _Size_ ->  _16MB_<br>
12. For **ESP32**:<br>
    For **ESP32-S2**:<br>
    For **ESP32-S3**:<br>
    For **ESP32-C3**:<br>
    &nbsp;&nbsp;&nbsp;&nbsp;&nbsp;&nbsp;Select _Tools_ -> _Partition_ _Scheme_ ->  _Minimal_ _SPIFFS_<br>
    For **ESP32-C5**:<br>
    For **ESP32-C6**:<br>
    For **ESP32-P4**:<br>
    &nbsp;&nbsp;&nbsp;&nbsp;&nbsp;&nbsp;Select _Tools_ -> _Partition_ _Scheme_ ->  _No_ _FS_ _4MB_ _(2MB_ _APP_ _x2)_<br>
13. For **ESP32**:<br>
    For **ESP32-S2**:<br>
    For **ESP32-S3**:<br>
    For **ESP32-C3**:<br>
    For **ESP32-C5**:<br>
    For **ESP32-C6**:<br>
    &nbsp;&nbsp;&nbsp;&nbsp;&nbsp;&nbsp;Select _Tools_ -> _Flash_ _Frequency_ ->  _80MHz_<br>
    For **ESP32-P4**:<br>
    &nbsp;&nbsp;&nbsp;&nbsp;&nbsp;&nbsp;Select _Tools_ -> _Flash_ _Frequency_ ->  _40MHz_<br>
14. For **ESP32**:<br>
    For **ESP32-S2**:<br>
    For **ESP32-S3**:<br>
    For **ESP32-C3**:<br>
    For **ESP32-C5**:<br>
    For **ESP32-C6**:<br>
    &nbsp;&nbsp;&nbsp;&nbsp;&nbsp;&nbsp;Select _Tools_ -> _CPU_ _Frequency_ ->  _80MHz_<br>
    For **ESP32-P4**:<br>
    &nbsp;&nbsp;&nbsp;&nbsp;&nbsp;&nbsp;Select _Tools_ -> _CPU_ _Frequency_ ->  _40MHz_<br>
15. Select _Tools_ -> _PSRAM_ ->  _Enabled_
16. _Sketch_ -> _Upload_

<br>

## Raspberry Pi

Although CLI application's source code for Raspberry Edition is located [at the same place](https://github.com/lyusupov/SoftRF/tree/master/software/firmware/source)<br>
and is shared with other SoftRF platforms - build instructions for the code are different.

This build has to be done on a Raspberry Pi host.<br>
A known good Raspbian OS version that fits for this purpose is "Stretch".<br>
Make sure that basic development packages (such as: binutils, g++, GNU make & etc) are installed.<br>

1. transfer full content of **SoftRF** and **libraries** GitHub folders into a temporary build directory:

    [SoftRF](https://github.com/lyusupov/SoftRF/tree/master/software/firmware/source/SoftRF) &nbsp;&nbsp;**-->** ``<your path>``/SoftRF <br>
    [libraries](https://github.com/lyusupov/SoftRF/tree/master/software/firmware/source/libraries) **-->** ``<your path>``/libraries <br>

2. change directory on ``<your path>``/SoftRF and execute **make** as follows:<br>

```
pi@raspberrypi: $ make pi
(cd ../libraries/bcm2835/src/../ ; ./configure ; make)
checking for a BSD-compatible install... /usr/bin/install -c
checking whether build environment is sane... yes
checking for a thread-safe mkdir -p... /bin/mkdir -p
checking for gawk... no

< ... skipped ... >
```

As a result of the build, two program binaries will become created:
- **SoftRF** - the program code designed to work with Raspberry Pi's primary SPI bus (SPI 0);
- **SoftRF-aux** - the same program but to run over auxiliary SPI bus (SPI 1).

<br>

## CC13X0

[Energia](http://energia.nu/download/) IDE has to be pre-installed first.<br>

1. open ``<Home>`` directory
2. create **Energia** sub-directory
3. transfer full content of **SoftRF** and **libraries** GitHub folders into the sub-directory:

    [SoftRF](https://github.com/lyusupov/SoftRF/tree/master/software/firmware/source/SoftRF) &nbsp;&nbsp;**-->** ``<My Documents>``/Energia/SoftRF <br>
    [libraries](https://github.com/lyusupov/SoftRF/tree/master/software/firmware/source/libraries) **-->** ``<My Documents>``/Energia/libraries <br>

4. start **Energia** application
5. open **SoftRF** sketch from _File_ -> _Open_ menu
6. [install support](http://energia.nu/guide/boards/) for TI CC13XX familiy with _Tools_ -> _Board_ ->  _Boards_ _Manager..._
7. Select _Tools_ -> _Board_ ->  _LaunchPad_ _w/_ _CC1310_ _EMT_ _(48MHz)_
8. Select _Tools_ -> _Port_ ->  ``<your XDS110 port device name>``
9. Select _Tools_ -> _Programmer_ ->  _dslite_
10. try to build and upload using _Sketch_ -> _Upload_

10a. or, to build the firmware using shell prompt, do:

```
$ make cc
energia --verify --verbose-build SoftRF.ino
Picked up JAVA_TOOL_OPTIONS:
Loading configuration...
Initializing packages...
Preparing boards...
Verifying...

< ... skipped ... >
```

11a. inspect **/tmp** directory and sub-folders, take **SoftRF.ino.elf** file and use it with TI's **Uniflash** or **Flash Programmer 2**.<br>

12a. (Optional) if you want to use [**cc2538-bsl.py**](https://github.com/JelmerT/cc2538-bsl) tool to put the firmware into flash memory of CC1310 IC via **boot loader**, run **make ihex**:

```
$ make ihex

< ... skipped ... >
``` 

<br>

## STM32

You will need to have an ST-LINK/V2 USB adapter connected in order to put the firmware into your hardware's flash memory.<br>

1. Follow these official instructions [Version 1.x](https://github.com/stm32duino/Arduino_Core_STM32/tree/1.9.0#getting-started) or [Version 2.x](https://github.com/stm32duino/Arduino_Core_STM32/tree/2.4.0#getting-started)
  to install Arduino IDE and **certain version** of Arduino STM32 Core -<!-- [latest **stable** Arduino STM32 Core](https://github.com/stm32duino/Arduino_Core_STM32/releases/tag/1.9.0) (1.9.0) --><br>
    For **S76G**:&nbsp;&nbsp;&nbsp;&nbsp;&nbsp;&nbsp;&nbsp;&nbsp;&nbsp;&nbsp;&nbsp;&nbsp;&nbsp;&nbsp;&nbsp;&nbsp;&nbsp;&nbsp;&nbsp;&nbsp;&nbsp;&nbsp;&nbsp;&nbsp;&nbsp;&nbsp;&nbsp;&nbsp;&nbsp;&nbsp;&nbsp;&nbsp;&nbsp;&nbsp;[**1.9.0**](https://github.com/stm32duino/Arduino_Core_STM32/releases/tag/1.9.0)<br>
    For **STM32F103C8** "Blue Pill":&nbsp;&nbsp;&nbsp;[**1.9.0**](https://github.com/stm32duino/Arduino_Core_STM32/releases/tag/1.9.0)<br>
    For **STM32F103C8** Ebyte E80:&nbsp;&nbsp;&nbsp;[**1.9.0**](https://github.com/stm32duino/Arduino_Core_STM32/releases/tag/1.9.0)<br>
    For **STM32WLE5**:&nbsp;&nbsp;&nbsp;&nbsp;&nbsp;&nbsp;&nbsp;&nbsp;&nbsp;&nbsp;&nbsp;&nbsp;&nbsp;&nbsp;&nbsp;&nbsp;&nbsp;&nbsp;&nbsp;&nbsp;&nbsp;&nbsp;[**2.4.0**](https://github.com/stm32duino/Arduino_Core_STM32/releases/tag/2.4.0)<br>
    For **STM32WL55**:&nbsp;&nbsp;&nbsp;&nbsp;&nbsp;&nbsp;&nbsp;&nbsp;&nbsp;&nbsp;&nbsp;&nbsp;&nbsp;&nbsp;&nbsp;&nbsp;&nbsp;&nbsp;&nbsp;&nbsp;&nbsp;&nbsp;[**2.4.0**](https://github.com/stm32duino/Arduino_Core_STM32/releases/tag/2.4.0)<br>

2. open ``<My Documents>`` (Windows) , ``<Home>`` (Linux) or ``<Documents>`` (MacOS) directory
3. create **Arduino** sub-directory
4. transfer full content of **SoftRF** and **libraries** GitHub folders into the sub-directory:

    [SoftRF](https://github.com/lyusupov/SoftRF/tree/master/software/firmware/source/SoftRF) &nbsp;&nbsp;**-->** ``<My Documents>``/Arduino/SoftRF <br>
    [libraries](https://github.com/lyusupov/SoftRF/tree/master/software/firmware/source/libraries) **-->** ``<My Documents>``/Arduino/libraries <br>

5. start **Arduino** application
6. open **SoftRF** sketch from _File_ -> _Open_ menu
7. For **S76G**:<br>
    &nbsp;&nbsp;&nbsp;&nbsp;&nbsp;&nbsp;Select _Tools_ -> _Board_ ->  _Nucleo_64_<br>
    &nbsp;&nbsp;&nbsp;&nbsp;&nbsp;&nbsp;Select _Tools_ -> _Board_ _part_ _number_ ->  _Nucleo_ _L073RZ_<br>
    &nbsp;&nbsp;&nbsp;&nbsp;&nbsp;&nbsp;Select _Tools_ -> _U(S)ART_ _support_ ->  _Enabled_ _(no_ _generic_ _'Serial')_<br>
    &nbsp;&nbsp;&nbsp;&nbsp;&nbsp;&nbsp;Select _Tools_ -> _USB_ _support_ _(if available)_ ->  _CDC_ _(generic_ _'Serial'_ _supersede_ _U(S)ART)_<br>
    &nbsp;&nbsp;&nbsp;&nbsp;&nbsp;&nbsp;Select _Tools_ -> _USB_ _speed_ _(if available)_ ->  _Low/Full_ _Speed_<br>
    For **STM32WLE5**:<br>
    &nbsp;&nbsp;&nbsp;&nbsp;&nbsp;&nbsp;Select _Tools_ -> _Board_ ->  _Generic_ _STM32WL_ _series_<br>
    &nbsp;&nbsp;&nbsp;&nbsp;&nbsp;&nbsp;Select _Tools_ -> _Board_ _part_ _number_ ->  _Generic_ _WLE5CCUx_<br>
    &nbsp;&nbsp;&nbsp;&nbsp;&nbsp;&nbsp;Select _Tools_ -> _U(S)ART_ _support_ ->  _Enabled_ _(generic_ _'Serial')_<br>
    For **STM32WL55**:<br>
    &nbsp;&nbsp;&nbsp;&nbsp;&nbsp;&nbsp;Select _Tools_ -> _Board_ ->  _Generic_ _STM32WL_ _series_<br>
    &nbsp;&nbsp;&nbsp;&nbsp;&nbsp;&nbsp;Select _Tools_ -> _Board_ _part_ _number_ ->  _Generic_ _WL55CCUx_<br>
    &nbsp;&nbsp;&nbsp;&nbsp;&nbsp;&nbsp;Select _Tools_ -> _U(S)ART_ _support_ ->  _Enabled_ _(generic_ _'Serial')_<br>
    For **STM32F103C8** "Blue Pill":<br>
    &nbsp;&nbsp;&nbsp;&nbsp;&nbsp;&nbsp;Select _Tools_ -> _Board_ ->  _Generic_ _STM32F1_ _series_<br>
    &nbsp;&nbsp;&nbsp;&nbsp;&nbsp;&nbsp;Select _Tools_ -> _Board_ _part_ _number_ ->  _BluePill_ _F103CB_ _(or_ _C8_ _with_ _128k)_<br>
    &nbsp;&nbsp;&nbsp;&nbsp;&nbsp;&nbsp;Select _Tools_ -> _U(S)ART_ _support_ ->  _Enabled_ _(generic_ _'Serial')_<br>
    &nbsp;&nbsp;&nbsp;&nbsp;&nbsp;&nbsp;Select _Tools_ -> _USB_ _support_ _(if available)_ ->  _CDC_ _(no_ _generic_ _'Serial')_<br>
    &nbsp;&nbsp;&nbsp;&nbsp;&nbsp;&nbsp;Select _Tools_ -> _USB_ _speed_ _(if available)_ ->  _Low/Full_ _Speed_<br>
    For **STM32F103C8** Ebyte E80:<br>
    &nbsp;&nbsp;&nbsp;&nbsp;&nbsp;&nbsp;Select _Tools_ -> _Board_ ->  _Generic_ _STM32F1_ _series_<br>
    &nbsp;&nbsp;&nbsp;&nbsp;&nbsp;&nbsp;Select _Tools_ -> _Board_ _part_ _number_ ->  _BluePill_ _F103CB_ _(or_ _C8_ _with_ _128k)_<br>
    &nbsp;&nbsp;&nbsp;&nbsp;&nbsp;&nbsp;Select _Tools_ -> _U(S)ART_ _support_ ->  _Enabled_ _(generic_ _'Serial')_<br>
    &nbsp;&nbsp;&nbsp;&nbsp;&nbsp;&nbsp;Select _Tools_ -> _USB_ _support_ _(if available)_ ->  _None_<br>
8. Select _Tools_ -> _Optimize_ ->  _Smallest_ _(-Os_ _default)_<br>
9. Select _Tools_ -> _C_ _Runtime_ _library_ ->  _Newlib_ _Nano_ _(default)_
10. For **S76G "Dongle"**:<br>
    &nbsp;&nbsp;&nbsp;&nbsp;&nbsp;&nbsp;Select _Tools_ -> _Upload_ _method_ ->  _STM32CubeProgrammer_ _(DFU)_<br>
    &nbsp;&nbsp;&nbsp;&nbsp;&nbsp;&nbsp;Select _Tools_ -> _Port_ ->  ``<your Dongle's DFU device name>``<br>
    For **STM32WLE5**:<br>
    &nbsp;&nbsp;&nbsp;&nbsp;&nbsp;&nbsp;Select _Tools_ -> _Upload_ _method_ ->  _STM32CubeProgrammer_ _(SWD)_<br>
    &nbsp;&nbsp;&nbsp;&nbsp;&nbsp;&nbsp;Select _Tools_ -> _Port_ ->  ``<your ST-LINK/V2 port device name>``<br>
    For **STM32WL55**:<br>
    &nbsp;&nbsp;&nbsp;&nbsp;&nbsp;&nbsp;Select _Tools_ -> _Upload_ _method_ ->  _STM32CubeProgrammer_ _(Serial)_<br>
    &nbsp;&nbsp;&nbsp;&nbsp;&nbsp;&nbsp;Select _Tools_ -> _Port_ ->  ``<your Serial port device name>``<br>
    For **S76G "SkyWatch"** or **STM32F103C8** "Blue Pill" or **STM32F103C8** Ebyte E80:<br>
    &nbsp;&nbsp;&nbsp;&nbsp;&nbsp;&nbsp;Select _Tools_ -> _Upload_ _method_ ->  _STM32CubeProgrammer_ _(SWD)_<br>
    &nbsp;&nbsp;&nbsp;&nbsp;&nbsp;&nbsp;Select _Tools_ -> _Port_ ->  ``<your ST-LINK/V2 port device name>``<br>
11. try to build and upload using _Sketch_ -> _Upload_

<br>

## ASR650x

1. Follow [these official instructions](https://heltec-automation-docs.readthedocs.io/en/latest/cubecell/quick_start.html)
  to install Arduino IDE and [latest **stable** Heltec CubeCell (ASR650X) Arduino Support](https://github.com/HelTecAutomation/ASR650x-Arduino/releases/tag/V1.4.0) (1.4.0)
2. open ``<My Documents>`` (Windows) , ``<Home>`` (Linux) or ``<Documents>`` (MacOS) directory
3. create **Arduino** sub-directory
4. transfer full content of **SoftRF** and **libraries** GitHub folders into the sub-directory:

    [SoftRF](https://github.com/lyusupov/SoftRF/tree/master/software/firmware/source/SoftRF) &nbsp;&nbsp;**-->** ``<My Documents>``/Arduino/SoftRF <br>
    [libraries](https://github.com/lyusupov/SoftRF/tree/master/software/firmware/source/libraries) **-->** ``<My Documents>``/Arduino/libraries <br>

5. start **Arduino** application
6. open **SoftRF** sketch from _File_ -> _Open_ menu
7. Select _Tools_ -> _Board_ ->  _CubeCell-GPS_ _(_ _HTC-AB02S_ _)_
8. Select _Tools_ -> _LORAWAN_AT_SUPPORT_ ->  _OFF_
9. Select _Tools_ -> _LORAWAN_RGB_ ->  _DEACTIVE_
10. Select _Tools_ -> _LORAWAN_CLASS_ ->  _CLASS_A_
11. Select _Tools_ -> _LORAWAN_ADR_ ->  _OFF_
12. Select _Tools_ -> _LORAWAN_NETMODE_ ->  _ABP_
13. Select _Tools_ -> _LORAWAN_Net_Reservation_ ->  _OFF_
14. Select _Tools_ -> _LORAWAN_UPLINKMODE_ ->  _UNCONFIRMED_
15. Select _Tools_ -> _LoRaWan_ _Debug_ _Level_ ->  _None_
16. Select _Tools_ -> _LORAWAN_REGION_ ->  _REGION_EU433_
17. Select _Tools_ -> _Port_ ->  ``<your CubeCell port device name>``
18. try to build and upload using _Sketch_ -> _Upload_

<br>

## nRF52840

1. Follow [these official instructions](https://github.com/adafruit/Adafruit_nRF52_Arduino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)
  to install Arduino IDE and [latest **stable** Arduino Core for Adafruit Bluefruit nRF52 Boards](https://github.com/adafruit/Adafruit_nRF52_Arduino/releases/tag/1.3.0) (1.3.0)
2. open ``<My Documents>`` (Windows) , ``<Home>`` (Linux) or ``<Documents>`` (MacOS) directory
3. create **Arduino** sub-directory
4. transfer full content of **SoftRF** and **libraries** GitHub folders into the sub-directory:

    [SoftRF](https://github.com/lyusupov/SoftRF/tree/master/software/firmware/source/SoftRF) &nbsp;&nbsp;**-->** ``<My Documents>``/Arduino/SoftRF <br>
    [libraries](https://github.com/lyusupov/SoftRF/tree/master/software/firmware/source/libraries) **-->** ``<My Documents>``/Arduino/libraries <br>

5. start **Arduino** application
6. open **SoftRF** sketch from _File_ -> _Open_ menu
7. Select _Tools_ -> _Board_ ->  _Nordic_ _nRF52840DK_ _(PCA10056)_
8. Select _Tools_ -> _Bootloader_ ->  _0.3.2_  _SoftDevice_  _s140_  _6.1.1_
9. Select _Tools_ -> _Debug_ ->   _Level_ _0_  _(Release)_
10. Select _Tools_ -> _Port_ ->  ``<your nRF52840 port device name>``
11. try to build and upload using _Sketch_ -> _Upload_

<br>

## SAMD21

1. Follow [these official instructions](https://www.arduino.cc/en/Guide/ArduinoM0)
  to install Arduino IDE and latest Atmel SAMD Core
2. Become familiar with IDE and **Arduino M0** or **Zero** by building and uploading of a basic **Blink** sketch:<br>

    _File_ -> _Examples_ -> _01.Basics_ -> _Blink_ <br>

    then<br>

    _Sketch_ -> _Upload_

3. When you are done with the lesson, close your **Arduino** application
4. open ``<My Documents>`` (Windows) , ``<Home>`` (Linux) or ``<Documents>`` (MacOS) directory
5. create **Arduino** sub-directory
6. transfer full content of **SoftRF** and **libraries** GitHub folders into the sub-directory:

    [SoftRF](https://github.com/lyusupov/SoftRF/tree/master/software/firmware/source/SoftRF) &nbsp;&nbsp;**-->** ``<My Documents>``/Arduino/SoftRF <br>
    [libraries](https://github.com/lyusupov/SoftRF/tree/master/software/firmware/source/libraries) **-->** ``<My Documents>``/Arduino/libraries <br>

7. start **Arduino** application again
8. open **SoftRF** sketch from _File_ -> _Open_ menu
9. _Sketch_ -> _Upload_

<br>

## RP2040

1. Follow [these official instructions](https://github.com/earlephilhower/arduino-pico#installing-via-arduino-boards-manager)
  to install Arduino IDE and [latest **stable** Raspberry Pi Pico Arduino core, for all RP2040 boards](https://github.com/earlephilhower/arduino-pico/releases/tag/3.8.0) (3.8.0)
2. open ``<My Documents>`` (Windows) , ``<Home>`` (Linux) or ``<Documents>`` (MacOS) directory
3. create **Arduino** sub-directory
4. transfer full content of **SoftRF** and **libraries** GitHub folders into the sub-directory:

    [SoftRF](https://github.com/lyusupov/SoftRF/tree/master/software/firmware/source/SoftRF) &nbsp;&nbsp;**-->** ``<My Documents>``/Arduino/SoftRF <br>
    [libraries](https://github.com/lyusupov/SoftRF/tree/master/software/firmware/source/libraries) **-->** ``<My Documents>``/Arduino/libraries <br>

5. start **Arduino** application
6. open **SoftRF** sketch from _File_ -> _Open_ menu
7. For RAK11310 WisBlock Core:<br>
   &nbsp;&nbsp;&nbsp;&nbsp;&nbsp;&nbsp;Select _Tools_ -> _Board_ -> _Generic_ _RP2040_<br>
   For Raspberry Pi Pico with Waveshare modules:<br>
   &nbsp;&nbsp;&nbsp;&nbsp;&nbsp;&nbsp;Select _Tools_ -> _Board_ -> _Raspberry_ _Pi_ _Pico_<br>
8. Select _Tools_ -> _Flash_ _Size_ -> _2MB_ _(Sketch:_ _1MB,_ _FS:_ _1MB)_
9. Select _Tools_ -> _USB_ _Stack_ -> _Adafruit_ _TinyUSB_
10. try to build and upload using _Sketch_ -> _Upload_

<br>

## RA4M1

1. Follow [these official instructions](https://docs.arduino.cc/tutorials/uno-r4-wifi/r4-wifi-getting-started/)
  to install Arduino IDE and latest Renesas Core
2. Become familiar with IDE and **Arduino Uno R4 WiFi** by building and uploading of a basic **Blink** sketch:<br>

    _File_ -> _Examples_ -> _01.Basics_ -> _Blink_ <br>

    then<br>

    _Sketch_ -> _Upload_

3. When you are done with the lesson, close your **Arduino** application
4. open ``<My Documents>`` (Windows) , ``<Home>`` (Linux) or ``<Documents>`` (MacOS) directory
5. create **Arduino** sub-directory
6. transfer full content of **SoftRF** and **libraries** GitHub folders into the sub-directory:

    [SoftRF](https://github.com/lyusupov/SoftRF/tree/master/software/firmware/source/SoftRF) &nbsp;&nbsp;**-->** ``<My Documents>``/Arduino/SoftRF <br>
    [libraries](https://github.com/lyusupov/SoftRF/tree/master/software/firmware/source/libraries) **-->** ``<My Documents>``/Arduino/libraries <br>

7. start **Arduino** application again
8. open **SoftRF** sketch from _File_ -> _Open_ menu
9. _Sketch_ -> _Upload_

<br>

## RP2350

1. Follow [these official instructions](https://github.com/earlephilhower/arduino-pico#installing-via-arduino-boards-manager)
  to install Arduino IDE and [latest **stable** Raspberry Pi Pico Arduino core, for all RP2XXX boards](https://github.com/earlephilhower/arduino-pico/releases/tag/4.5.1) (4.5.1)
2. open ``<My Documents>`` (Windows) , ``<Home>`` (Linux) or ``<Documents>`` (MacOS) directory
3. create **Arduino** sub-directory
4. transfer full content of **SoftRF** and **libraries** GitHub folders into the sub-directory:

    [SoftRF](https://github.com/lyusupov/SoftRF/tree/master/software/firmware/source/SoftRF) &nbsp;&nbsp;**-->** ``<My Documents>``/Arduino/SoftRF <br>
    [libraries](https://github.com/lyusupov/SoftRF/tree/master/software/firmware/source/libraries) **-->** ``<My Documents>``/Arduino/libraries <br>

5. start **Arduino** application
6. open **SoftRF** sketch from _File_ -> _Open_ menu
7. For Raspberry Pi Pico 2W:<br>
   &nbsp;&nbsp;&nbsp;&nbsp;&nbsp;&nbsp;Select _Tools_ -> _Board_ -> _Raspberry_ _Pi_ _Pico_ _2W_<br>
8. Select _Tools_ -> _Flash_ _Size_ -> _4MB_ _(Sketch:_ _1MB,_ _FS:_ _3MB)_
9. Select _Tools_ -> _USB_ _Stack_ -> _Adafruit_ _TinyUSB_
10. Select _Tools_ -> _IP/Bluetooth_ _Stack_ -> _IPv4_ _+_ _Bluetooth_
11. try to build and upload using _Sketch_ -> _Upload_

<br>

## Luckfox Lyra

Although CLI application's source code for Lyra Edition is located [at the same place](https://github.com/lyusupov/SoftRF/tree/master/software/firmware/source)<br>
and is shared with other SoftRF platforms - build instructions for the code are different.

This build has to be done on a Luckfox Lyra host.<br>
Make sure that basic development packages (such as: binutils, g++, GNU make & etc) are installed.<br>

1. transfer full content of **SoftRF** and **libraries** GitHub folders into a temporary build directory:

    [SoftRF](https://github.com/lyusupov/SoftRF/tree/master/software/firmware/source/SoftRF) &nbsp;&nbsp;**-->** ``<your path>``/SoftRF <br>
    [libraries](https://github.com/lyusupov/SoftRF/tree/master/software/firmware/source/libraries) **-->** ``<your path>``/libraries <br>

2. change directory on ``<your path>``/SoftRF and execute **make** as follows:<br>

```
pi@raspberrypi: $ make lyra
(cd ../libraries/bcm2835/src/../ ; ./configure ; make)
checking for a BSD-compatible install... /usr/bin/install -c
checking whether build environment is sane... yes
checking for a thread-safe mkdir -p... /bin/mkdir -p
checking for gawk... no

< ... skipped ... >
```

As a result of the build, one program binary will become created:
- **SoftRF** - the program code designed to work with Luckfox Lyra's primary SPI bus;

<br>

## nRF54L15

1. Follow [these instructions](https://github.com/lolren/nrf54-arduino-core?tab=readme-ov-file#-quick-install)
  to install Arduino IDE and [nRF54L Arduino Core](https://github.com/lolren/nrf54-arduino-core/releases) (0.9.167)
2. open ``<My Documents>`` (Windows) , ``<Home>`` (Linux) or ``<Documents>`` (MacOS) directory
3. create **Arduino** sub-directory
4. transfer full content of **SoftRF** and **libraries** GitHub folders into the sub-directory:

    [SoftRF](https://github.com/lyusupov/SoftRF/tree/master/software/firmware/source/SoftRF) &nbsp;&nbsp;**-->** ``<My Documents>``/Arduino/SoftRF <br>
    [libraries](https://github.com/lyusupov/SoftRF/tree/master/software/firmware/source/libraries) **-->** ``<My Documents>``/Arduino/libraries <br>

5. start **Arduino** application
6. open **SoftRF** sketch from _File_ -> _Open_ menu
7. Select _Tools_ -> _Board_ ->  _XIAO_ _nRF54L15_ _(Nrf54L15-Clean-Implementation)_
8. Select _Tools_ -> _Upload Method_ ->  _pyOCD_ _(CMSIS-DAP)_
9. try to build and upload using _Sketch_ -> _Upload_

<br>

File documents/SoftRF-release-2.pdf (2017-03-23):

# SoftRF


# Part 2

# Multifunctional DIY IoT-based general aviation proximity awareness

system.

Linar Yusupov (linar.r.yusupov@gmail.com). March, 2017.

Revision: 2.0

# Intro

## This document is the SoftRF project development update

of the progress been made in year 2016.

## Author is taking assumption that you are already familiar

ith last release of the projet’s hite paper.

## If not, please, read this document first:

SoftRF (https://github.com/lyusupov/SoftRF/raw/master/documents/SoftRF-release-1.pdf) overview. Part 1. (https://github.com/lyusupov/SoftRF/raw/master/documents/SoftRF-release-1.pdf)

## At the end of the previous story a prototype unit were

created to pass through preliminary field testing.

# First SofRF concept Outdoor test result


Distance 100 meters

100

Packets
pass
ratio, %

0

The test was performed between two instances of SoftRF hardware.
One were acting as a transmitter and another one – as a receiver.
Received data packets were accounted toward total packets been sent.
It was revealed that there were no reception any more beyond 100 meters.
When carrier frequency was reduced from 868 MHz down to 433 MHz then the range has become better.

868 MHz

433 MHz

# First SofRF concept Signal spectrum at 868 band

## Back in the lab it was revealed that high gain of analyzer is required to achieve good signal shape at 868 MHz:

# First SofRF concept Signal spectrum at 433 band

## And low gain is sufficient at 433 MHz:


# Generic NRF905 module

## Most of these modules are targeted for domestic China market. While 433 MHz band is legal in this country but the

868/915 MHz band is not (yet).


Generic NRF905 module.
Issue #1.


There are 2 reference designs from Nordic Semiconductors specified in NRF905 datasheet. First one is for 433 MHz band and another one is for 868/915 MHz band.

Values for inductors (L) and capacitors
(C) are widely different in these designs.

## MHz referee desig is

implemented in the domestic China NRF905 module.

Generic NRF905 module.
Issue #2.


Least expensive 16 MHz crystals are in use in these modules. The crystal may have as much as 100+ PPM resonance frequency offset range.

This means that when the module is set by software to operate at 868.4 MHz – it may actually operate at 868.5 MHz.

When two modules are communicating to each other, one is on 868.4 and the partner is on 868.5 – they typically still able to talk, but the maximum operating range is deteriorating as much as twice.

Generic NRF905 module.
Issue #3.

These modules are typically shipped with low quality, ineffective, short rubber duck antenna.

Think to substitute it with a good one as soon as practicable.

Solution 1 for issues #1 and #2. Re-soldering.


## MHz referee desig a e oerted ito / MHz oe

by re-soldering of all dependent SMD components.

To get appropriate L and C values, please, refer to this Nordic
“eiodutor’s datasheet (http://infocenter.nordicsemi.com/pdf/nRF905_PS_v1.5.pdf) .
Figure 15 on page 37.

Solution 2 for issues #1 and #2. 868/915 version of NRF905 module.


## Fortuately, I’e foud out that soe

Chinese manufactures produce an export version of the module targeted for EU and US markets. A known good example is this one. (http://www.aliexpress.com/item/915M-wireless-module-NRF905-wireless-transceiver-module-including-the-antenna-to-provide-routine/32438352870.html)


As an alternative source, one may consider to use nRF905-C868 module from Montar Manufacturing, South Africa.

# Solution for issue #3 Better antenna choice


VS | or

# SoftRF Prime Edition

A Prime Edition of SoftRF
hardware is a direct successor of

## SoftRF oept that as

presented in Part 1.
It has exactly the same electrical components that the concept had, but the issues with NRF905 modules were resolved by re-soldering.
A variety of 868 MHz antennas were also purchased to
determine which one is the best.

# SoftRF Prime Edition


The Prime has also retained PCB-

## less desig ad o solderig

rule as much as possible.

A custom 3D printable plastic shell was developed to protect the electronics from environment factors.
The 3D model of this enclosure is shared at Thingiverse. (http://www.thingiverse.com/thing:2075669)

# Performance

# Operating range


### 1 Distance, km

100

Packets
pass
ratio, %

0

The test was performed between two instances of SoftRF Prime units. Power supply voltage is 3.5V. 3dB antennas are in use.
One unit is near ground, another one is elevated. Both are on line of sight.

2

50

75

# NRF905 vs RTL-SDR Rx performance


One of the test goals was to compare SoftRF receive
performance with some other of open source RF solutions.

One of these, RTL-SDR was
tested in factory configuration
ith stok atea.

## RTL-“DR as drie y Flare (https://github.com/creaktive/flare)

NRF905 software decoder
developed by Stanislaw Pusep.

Preamp gain was set at 49.6 dB.

# NRF905 vs RTL-SDR Rx performance


### 1 Distance, km

100

Packets
pass
ratio, %

0

First Prime unit was acting as a transmitter.
Second Prime and RTL-SDR were acting as receivers.

2

50

75

NRF905

RTL-SDR

# Compatibility

# Radio

SofRF does ipleet a fratio of losed FLARM™ radio protool ersio .
On the picture below you can see a field test when SoftRF Prime and LX9000/FLARM units are able to see each other.


# Radio

It was also verified that SoftRF can operate with Open Glider Network.
On this screenshot you may see that infra of OGN can receive signal from a SoftRF unit located near city of Moscow.

# Data

SofRF does ipleet a fratio of ope FLARM™ DATA protool ersio .
It is known to work with XCSoar, Cumulus, LK8000, SeeYou Mobile.


# Hardware

# Standalone Edition

Based on successful tests of the Prime and taking into account expected demands of soaring and GA societies it was decided to develop autonomous,
standalone version of SoftRF.

Standalone Edition:
- has own GNSS receiver ;
- has sart firare ;
- gives traffic alerts with LEDs and audio ;
- supplies NMEA data to
onboard flight computer by Bluetooth or Wi-Fi ;
- is self-powered.


For more detailed specifications, please, read this wiki page. (https://github.com/lyusupov/SoftRF/wiki/Standalone-Specifications)

# Shield

To keep it simple for volunteers to reproduce, it was decided to create a shield (https://github.com/lyusupov/SoftRF/wiki/Standalone-Shield) for all the electronic components. You may already know, this
approah is kid of typial for ost DIY Arduio orld solutios.

# Modules

Complete board of electronics consists of the shield itself been stuffed with numerous modules and components that are pretty cheap and easily available for purchase from different sources.
For the list of pluggable parts, please, visit this page. (https://github.com/lyusupov/SoftRF/wiki/Standalone-Modules)


# Enclosure


All the electronics is protected by a custom designed case.

Genuine design of this
enclosure is shared as well and available for download from this page on (http://www.thingiverse.com/thing:2075683) Thingiverse. (http://www.thingiverse.com/thing:2075683)

# UAV Edition

A version of SoftRF that is targeted for UAV use had also substantial progress of development through year 2016. The unit shown below is to be connected to

## UAV’s autopilot. MAVLINK . ouiatio protool is supported. At this oet, the deie is trasit-oly, ut this is ostly oly urret

firare’s liitatio.


# Firmware

# License

## Source code of SoftRF firmware was released and still maintained under GNU General Public License

version 3.

## It is distributed in the hope that it will be useful, but

WITHOUT ANY WARRANTY.

### A friendly reminder for authors who has created derivatives of SoftRF firmware since date of the first publication:

## In accordance with GNU GPL you have to keep your source code open!

# Interface

Since the SoftRF is running on a popular IoT platform, it uses pretty recent human interface method – Web over Wi-Fi. No knobs, no buttons any more. Your smartphone is the primary monitoring and configuration tool.


# Interface

The firmware is unified across all the SoftRF hardware editions.
Curret role of the uit a e seleted i “ettigs eu.
You should also set operating frequency onto which one is legal for your country.

# Software

# Emulator

While Standalone Edition is a self-contained unit which needs no support from outside, but Prime and UAV, to be effective, both need at least a trustworthy external GNSS source. Software emulator for traffic proximity alerts was developed as an alternative to firmware-based approach.
Emulator is running on an
Android tablet as a Python script and is using a built-in GNSS source to get location data and time stamp. Then it

## eulates FLARM™ radio ad

data protocols. SoftRF unit is acting as a raw data bridge

## etee the talet ad RF

Air.
On the left photo an XCSoar for Android is showing a traffic alert with assistance of SoftRF.


# Emulator

Navigation software is running on the same tablet/smartphone and is communicating to the Emulator with local UDP network packets.
No alteration of navigation software is necessary.
Recently released LK8000 for Android is also known to work with the Emulator.


# Test drive

# Test drive


At this moment five
Standalone units were
manufactured and are
currently available for
regional soaring and GA
pilots in Russia who want
to participate in free

## eeks Test Drie

program.

I plan to test-fly soon all these units by myself as
well.

# Thank you for your attention!

# Development page of this project is located at GitHub: http://github.com/lyusupov/SoftRF

# Welcome to build!

# Welcome to contribute!

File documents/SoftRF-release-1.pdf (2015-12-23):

# SoftRF

## An IoT bridge between popular radio-based general aviation proximity awareness system and Wi-Fi consumer

devices.

Linar Yusupov (linar.r.yusupov@gmail.com). December, 2015.

Revision: 1.0

# Table of contents

(Click on a link to proceed directly to this section)

## - Designs by 2015 - Concept - Areas of application - Hardware - Software

## 1) Alarm 2) Receiver 3) Transmitter 4) Cloud

# List of designs by 2015

- ADS (https://en.wikipedia.org/wiki/Automatic_dependent_surveillance_%E2%80%93_broadcast)- (https://en.wikipedia.org/wiki/Automatic_dependent_surveillance_%E2%80%93_broadcast)B (https://en.wikipedia.org/wiki/Automatic_dependent_surveillance_%E2%80%93_broadcast) - upcoming world-wide aviation industry standard.

## Operates at specific frequency 1090 MHz dedicated to

aviation ;

## - FLARM (http://flarm.com/) – most popular collision avoidance system for gliders and some powered GA aircrafts. It utilizes ISM 868/915 MHz

RF band ;
- Argus (http://github.com/lyusupov/Argus) – an open source DIY project. ISM 2.4 GHz Wi-Fi band is in use ;
- OGN Tracker (http://wiki.glidernet.org/ogn-tracker) – open project for monitoring of glider’s traffic. Operates at ISM 868 MHz band ;
- PilotAware (http://www.pilotaware.com/) – recent high range open hardware / closed source proximity awareness project. Operating band is ISM 868 MHz.

# Concept

## Idea is to:

1) Receive data packets on RF ISM 868/915 band from nearby FLARM transmitters with minimal hardware ;
2) Take raw (encrypted) payload from each packet and convert it into plain-text representation (hexadecimal) ;
3) Forward the text string to a nearby mobile device by Wi-Fi (TCP/IP) for further processing ;

## and vice versa:

1) Receive an appropriate hexadecimal text string from mobile device by Wi-Fi ;
2) Convert it into RF raw data packet ;
3) Transmit the packet on 868/915 MHz for a nearby FLARM device(s).

# Data flow

PREAMBLE | ADDRESS | PAYLOAD | CHECKSUM
01 | 12 | 23 | 34 | 45 | 56 | 67 | 78 | 89 | 9A | AB | | | 78
0x31 | 0xfa | 0xb6 | PAYLOAD | .. | ..

NRF905 frame

FLARM packet

24 bytes | 2 bytes

SoftRF hex string

“ | “
TCP/IP packet | CONTROL BLOCK | “01122334455667….78” | CHECKSUM

# Areas of application

## - A two-way bridge between FLARM and other traffic

awareness designs ;

## - Alternative to Raspberry Pi based Open Glider

Network (OGN) receiver ;

## - Wireless adapter for a smartphone or tablet to

receive (transmit) FLARM traffic information ;

## - Lightweight traffic awareness transceiver to carry

onboard an UAV.

# Bridge

## When an aircraft has both SoftRF and other design onboard – it


SoftRF

can interchange of positional data between the systems by Wi-Fi.

# OGN receiver

Generic OGN receiver does capture of radio signals from nearby flying FLARM traffic by USB DVB-T card. Upon completion of processing it sends APRS formatted messages to an OGN server by internet for visualization.

SoftRF

SoftRF is also capable to act as an OGN receiver. It delivers raw (encrypted) FLARM data to an upper-layer server by built-in Wi-Fi adapter through a nearby Wi-Fi hotspot.

# OGN receiver (cont.)


Typical OGN receiver is built from:

- specific model of USB DVB-T adapter ;
- Raspberry Pi or Pi2 microcomputer ;
- flash memory card ;
- optional Wi-Fi adapter.

and costs around 50+ € (excluding antenna).


SoftRF is also easy to build from parts. Firmware can be updated “Over-The-Air”. SoftRF based OGN receiver has very similar functionality to the Raspberry Pi ‘s one but 2-3 times less expensive.

# Wireless adapter


It this case a mobile device such as smartphone or SoftRF tablet is connected to the SoftRF by Wi-Fi.

SoftRF relays raw packets between a FLARM
equipped aircraft and the mobile device, forth
and back.

Processing and visualization of the FLARM data on the mobile device is performed entirely by software (an Android or/and iOS app).

# UAV transceiver

SoftRF may complement UAV’s built-in autopilot to add proximity awareness functionality.

One known good example of such autopilot is very popular ArduPilot (http://en.wikipedia.org/wiki/Ardupilot) open source platform. Most recent version does already have preliminary support for ADS-B.

To reduce radio interference on 2.4 GHz band with other control interfaces it makes sense to disable SoftRF’s Wi-Fi and communicate with autopilot only by wires.


My testbed for this winter season: SoftRF prototype been mounted underneath 350-class quadcopter is shown on this picture.

# Hardware

# NRF905 module


- This module is signal-level compatible with FLARM due to that they both use the same radio silicon - Nordic Semiconductor’s NRF905 ;
- It can receive and transmit on 868 MHz (Europe) and 915 MHz (North America) bands ;
- Maximum transmit power is 10 dBm (10 mW) which is compliant with both ETSI and FCC limitations.

# NodeMCU v1.0 IoT module


- NodeMCU is recent and popular open source “Internet of Things” (IoT) platform ;
- Key hardware features are:
1. built-in IEEE 802.11 b/g/n Wi-Fi ;
2. 4 Mbytes of flash memory ;
3. 13 active GPIO pins.
- Key advantages over competitors are:
1. wide open software support, to be specific: “Arduino (http://github.com/esp8266/Arduino) ESP8266 IDE”; (http://github.com/esp8266/Arduino)
2. low cost.

# Power and connectors


Power bank provides electricity to NodeMCU module through its micro-USB port.
Capacity of the bank is not a critical factor – power consumption by the SoftRF is about 0.7 Watt.


10 jumper wires are connecting NodeMCU to NRF905 module.

# Bill of materials

Item № | Item description | QTY. | Est. price per unit, € | Source(s)
1 | NRF905 module (PTR8000/8000+) | 1 | 4-5 | A, (http://www.aliexpress.com/item/NRF905-Wireless-Module-PTR8000-Wireless-Transmission-433-486-915MHz-NF905S-Fast-Shipping-Dropshipping/32487867008.html) B, (http://www.banggood.com/NRF905-NF905SE-Wireless-Transmission-Module-Compatible-PTR8000-p-950831.html) E (http://www.ebay.com/itm/NEW-NRF905-wireless-module-PTR8000-wireless-transmission-433-486-915MHz-/191177438259)
2 | NodeMCU v1.0 | 1 | 4-7 | A, (http://www.aliexpress.com/item/2015-New-product-Wireless-module-NodeMcu-Lua-Wifi-Nodemcu-WIFI-Network-Development-Board-Based-ESP8266-High/32341789414.html) E (http://www.ebay.com/itm/NodeMcu-Lua-WIFI-Internet-of-Things-Development-Board-Based-ESP8266-Module-FOZ-/151833512666)
3 | Power bank (5 Volts) and USB<->microUSB cable | 1 | 5-10 | ANY
4 | 40 pcs. female DuPont jumper wires | 1 | 1-2 | A, (http://www.aliexpress.com/item/Free-Shipping-1lot-40pcs-lot-10cm-2-54mm-1pin-femal-to-femal-jumper-wire-Dupont-cable/32329983091.html) B, (http://www.banggood.com/40-x-10cm-Female-To-Female-Dupont-Jumper-Wires-Cable-p-89717.html) E (http://www.ebay.com/itm/40pcs-10cm-2-54mm-Female-to-Female-Dupont-Wire-Jumper-Cable-1P-1P-For-Arduino-SC-/221949738581)
Total | | 4 | 14-24

# Wiring


Wire Num. | NodeMCU pin | NRF905 module
1 | D0 | TXEN
2 | D1 | DR
3 | D2 | PWR
4 | D4 | CE
5 | D5 | SCK
6 | D6 | MISO
7 | D7 | MOSI
8 | D8 | CSN
9 | 3V3 | VCC
10 | GND | GND

# Prototype


My proto is built around a GoPro action camera’s clip.

This allows me to mount the prototype
- inside a sailplane’s cockpit ;
- onto a car’s dashboard ;
- underneath a quadcopter.

Total weight is 41 gram.

# Software

# At first I would like to express my appreciation to the following people whose open source projects are in use by my SoftRF demo sketches:

- Arduino (http://github.com/esp8266/Arduino) ESP8266 IDE (http://github.com/esp8266/Arduino) from a team led by Ivan Grokhotkov ;
- Arduino (http://github.com/zkemble/nRF905/tree/master/arduino/nRF905) nRF905 (http://github.com/zkemble/nRF905/tree/master/arduino/nRF905) by Zak Kemble ;
- flarm_decode (http://github.com/creaktive/flare) by Stanislaw Pusep ;
- Arduino (http://github.com/bblanchon/ArduinoJson) JSON (http://github.com/bblanchon/ArduinoJson) by Benoit Blanchon ;
- Arduino (http://github.com/PaulStoffregen/Time) Time (http://github.com/PaulStoffregen/Time) by Paul Stoffregen ;

# Intro

# Intro (cont.)

All the following demo examples are to:

- be built on a PC together with Arduino IDE (ver. 1.6.7 is recommended) ;
- run on the SoftRF hardware specified earlier ;


- and visualized on a Wi-Fi connected Android or iOS smartphone/tablet by means of a web browser.

# Intro (cont.)

To provide adequate UI and functionality each of SoftRF demo sketches is running auxiliary services in background, such as:


☐ Wi-Fi Access point (except Demo4)
SSID: SoftRF
Password: 123456123456

☐ Web server
IP: | 192.168.4.1
Hostname: soft.local
Port: 80

☐ Network time sync (NTP) client

☐ “Over-the-air” firmware update service

Demo 1: FLARM detector.

Demo1_Alert_868.ino sketch does implement very basic traffic alert algorithm.


SoftRF is listening to the air for any valid
FLARM transmission session.

A packet is considered to be “valid” if:
1) it has specific values in “address” field ;
2) 24 bytes of payload size ;
3) valid checksum.


Reception of at least one valid FLARM packet will trigger red alarm screen.

Demo 2: Receiver.

Primarily Demo2_RX_868.ino sketch displays most; when the packet was captured.; and displays the result.; by Hiram Yaeger in 2008. In 2015 unknown author has revealed the algorithm of FLARM V6. Clayton Smith and Stanislaw Pusep have; decoder is in use by this sketch.

recently received FLARM packet in plain text hexadecimal format. It also shows time stamp

Secondarily the sketch makes an attempt to decode content of the FLARM packet’s payload

Algorithm of FLARM V4 decryption was revealed

developed implementation of the decoder for GNU Radio and Linux. Source code of Stanislaw’s

# Demo 2 (cont.)


In addition to visualization of incoming data in text representation the Demo2_RX_868.ino sketch does also supply traffic information to external hardware/software clients, namely:
1) Argus ;
2) XCSoar.

specified in Demo2_RX_868.h file.; As an example, when an XCSoar client is configured like this

IP address/port pairs of these clients are

and “FLARM View” window is opened you will be able to see a traffic map

Demo 3: Transmitter.


Demo3_TX_868.ino sketch gives an opportunity to emit user-defined data into the radio space on 868.4 MHz.

SoftRF’s web page has an input field to fill it with arbitrary hexadecimal data of 24 bytes in size.

In order to submit the data, please, press “TRANSMIT” button.

Demo 4: Put into a cloud.


Demo4_Cloud_868.ino sketch is doing simulation of OGN receiver’s behavior.

In this case SoftRF is connected to local Wi-Fi network as a client. SSID and password of the network has to be specified in Demo4_Cloud_868.h file before the sketch is being built:

#define MY_ACCESSPOINT_SSID <Your SSID>

#define MY_ACCESSPOINT_PSK <Your PASSWORD>

This demo open and maintain connection with a cloud server. When a FLARM packet is received it becomes converted into APRS format then sent to the cloud.

# Thank you for your attention!

To visit home page of this project,

# please, come to:

# http://github.com/lyusupov/SoftRF

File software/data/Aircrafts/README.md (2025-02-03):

# Aircrafts data

The data files are currently generated two times a day at 3 and 15 UTC.

Follow [**this link**](https://github.com/lyusupov/SoftRF/actions/workflows/adb.yml) to download a ZIP with these data files.

<br>



<br>

The file is located in '**Artifacts**' section.

> [!IMPORTANT]
> [Artifact download](https://docs.github.com/en/actions/writing-workflows/choosing-what-your-workflow-does/storing-and-sharing-data-from-a-workflow) is only available for registered GitHub users. Read [this ticket](https://github.com/actions/upload-artifact/issues/51) for more details.

<br>



<br>

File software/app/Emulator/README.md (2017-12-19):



<br>

Emulator is currently implemented as a background Python process being running
on an Android or Raspberry Pi host.

## List of functions:

1) The emulator takes current GNSS position, time stamp and ID to encode them into raw data packet.
Then it gives the outbound packet via Wi-Fi to SoftRF Prime for actual transmittion into air.

2) The emulator also 
 - receives inbound raw data packets from SoftRF Prime;
 - applies decoding algorithm ;
 - converts decoded data into a fraction of FLARM datalink format ; 
 - delivers the NMEA datalink strings to localy running XCSoar or LK8000 app via UDP stream.

## Prerequisites:

1) have "QPython - Python for Android" App installed from Google Play Market ;
2) "numpy" Python library has to be installed over QPython ;



3) SoftRF-Emu .py files from here: https://github.com/lyusupov/SoftRF/tree/master/software/app/Emulator
   has to be transferred into QPython scripts 'home' directory of your Tablet/Cellphone ;



4) configure your XCSoar or LK8000 data source onto UDP port number 10110.   



## Instructions:

1) set the prerequisites above up ;
2) enable your Tablet/Cellphone GNSS ;
3) connect your Tablet/Cellphone to SoftRF Wi-Fi Access Point. <br>
   Default SSID: SoftRF-XXXXXX . Default password: 12345678 . URL: http://192.168.1.1/ ;
4) put your "Prime" into "Bridge" mode ;



5) execute "Emulator.py" within QPython ;
6) if no errors appeared at step 5, launch your XCSoar or LK8000 app.

## Optional:

In addition to traditional NMEA data protocol the Emulator is able to speak in Garmin GDL90 language as well.<br>
One known good example of compatible EFB applications is "Avare".

At first, you will need to install and set up an "Avare plug-in" as follows:



"Avare" app will show the FLARM traffic on a moving map:



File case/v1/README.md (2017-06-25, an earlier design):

# Enclosure version 1.0

This type of enclosure was designed to protect PCB-less assembly of minimal SoftRF hardware
that was presented in December 2015.

# Exterior



# Interior



# Instructions

3D print three STL files from this folder then stick them together with M4 screws.
You may pick some printing advisories on [my Thingiverse page](http://www.thingiverse.com/thing:2075669).

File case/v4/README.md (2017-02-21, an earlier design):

# Enclosure version 4.0

This type of enclosure is built around "SoftRF Shield Rev.1" and fits typical 2.25 inch (58 mm) hole of an aircraft instrument panel.

# Exterior



# Instructions

3D print four STL files from this folder. You may pick some printing advisories on [my Thingiverse page](http://www.thingiverse.com/thing:2075683).

Fasten printed parts with eight 2.5x10 mm screws. PCB is secured to the shell with M3 screws and nuts. 
Battery compartment is attached to rear panel with a plastic glue. Cover keeps battery from falling out.

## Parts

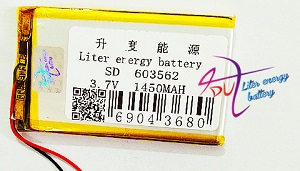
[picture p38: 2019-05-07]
documents/images/bom/lipo-1450.jpg

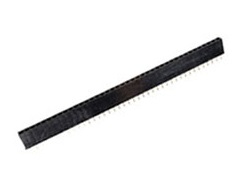
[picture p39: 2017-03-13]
documents/images/bom/f1x40.jpg

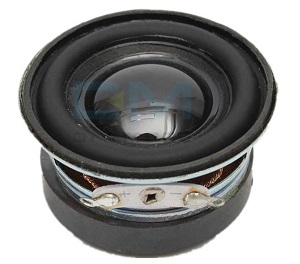
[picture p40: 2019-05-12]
documents/images/bom/speaker.jpg

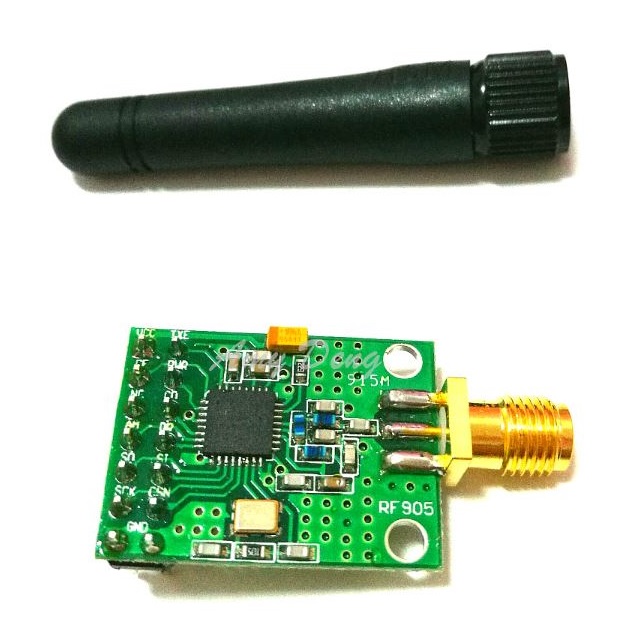
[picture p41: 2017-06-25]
documents/images/bom/nrf905.jpg

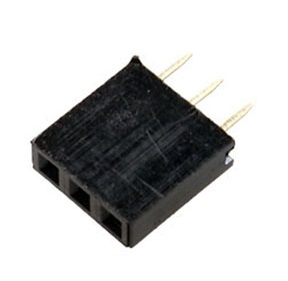
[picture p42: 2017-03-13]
documents/images/bom/f1x3.jpg

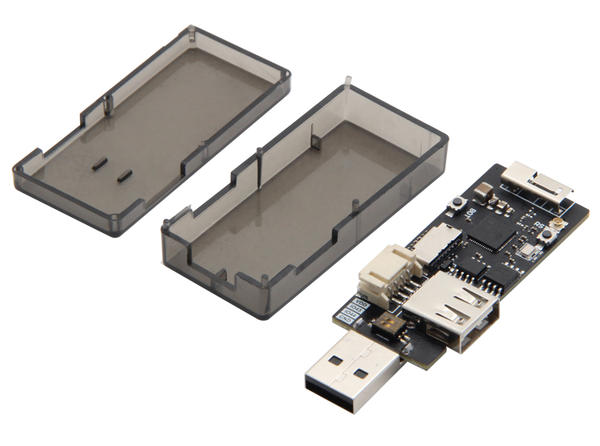
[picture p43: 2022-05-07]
documents/images/bom/t-dongle-3.jpg

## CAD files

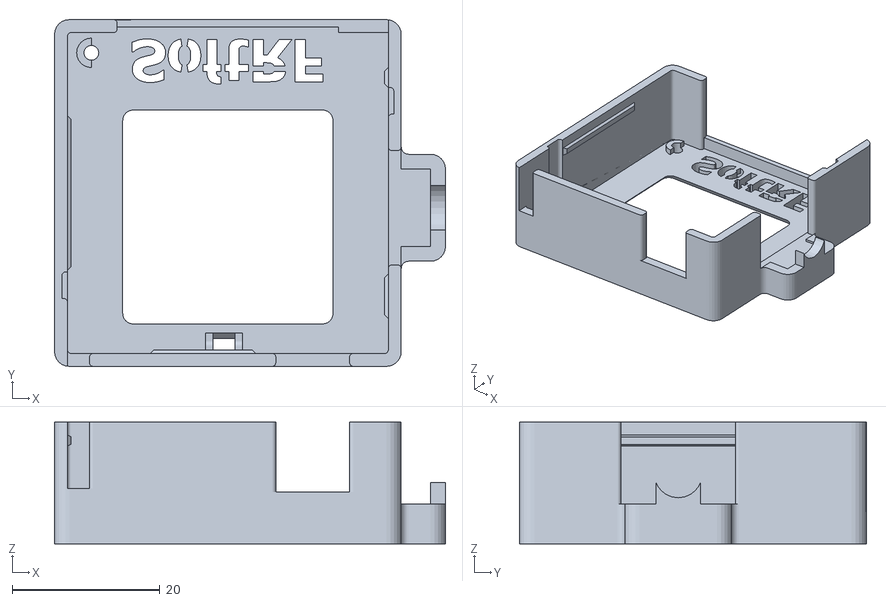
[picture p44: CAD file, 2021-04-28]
case/Badge/SoftRF-Case-Badge-Face.stl
53.0 x 47.0 x 16.5

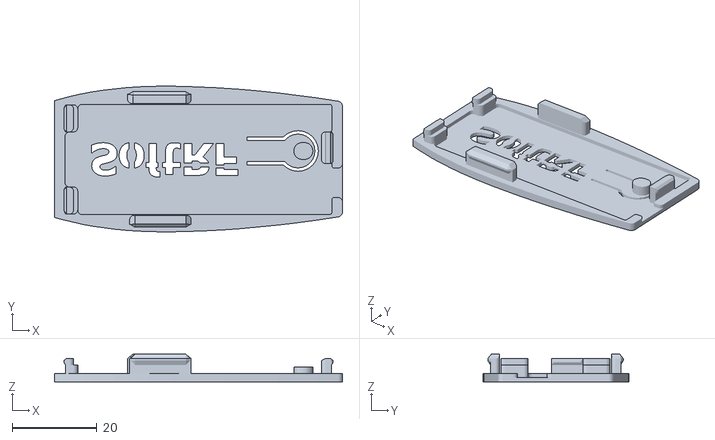
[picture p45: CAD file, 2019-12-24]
case/Dongle/SoftRF-Case-Dongle-Slim-Lid-NoPinHead.stl
68.0 x 34.4 x 6.50

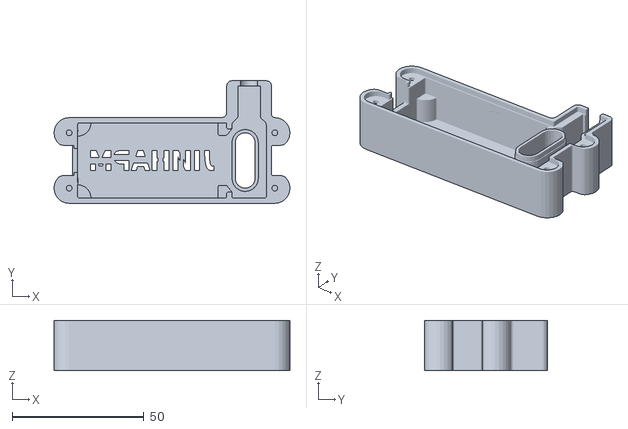
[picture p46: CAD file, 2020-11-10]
case/Mini/SoftRF-Case-Mini-Body-NPH.stl
89.5 x 46.5 x 19.0

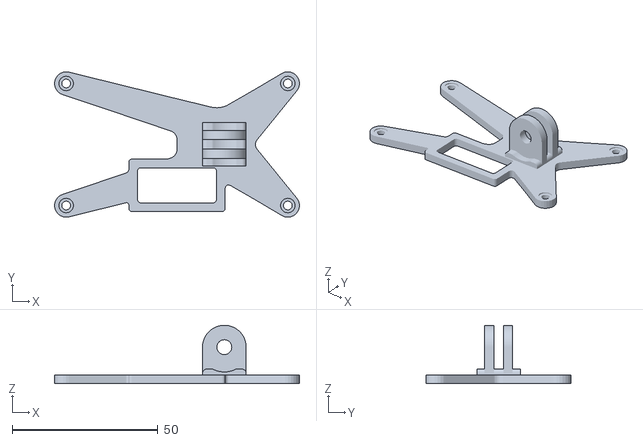
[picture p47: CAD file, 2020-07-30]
case/SkyView/SkyView-Case-EZ-GoPro.stl
84.0 x 49.8 x 20.0

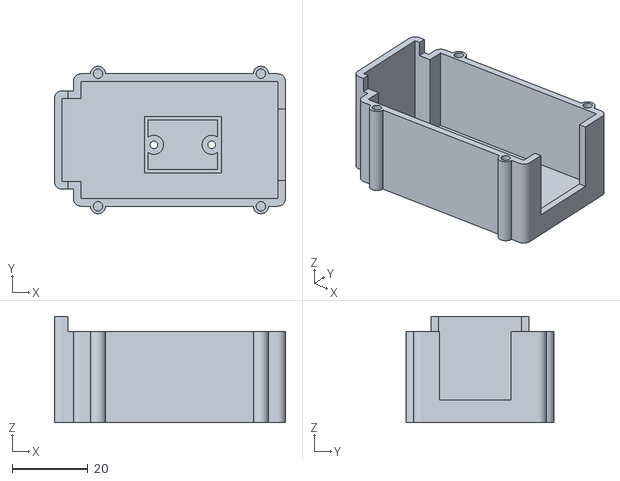
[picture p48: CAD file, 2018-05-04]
case/UAV/SoftRF-Case-UAV-Body.stl
61.0 x 39.0 x 28.0

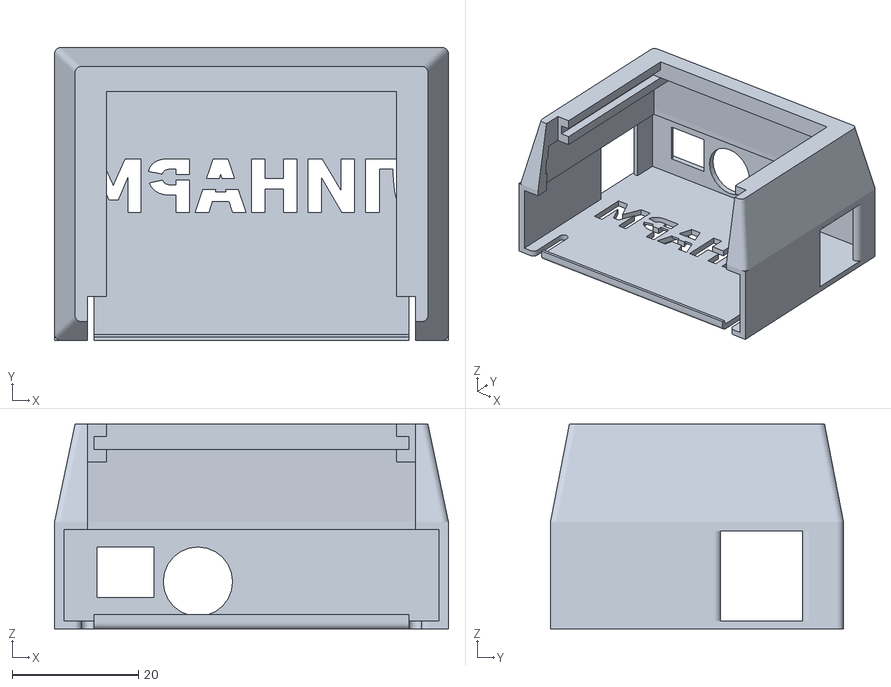
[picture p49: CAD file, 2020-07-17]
case/Uni/SoftRF-Case-Uni-Sleeve.stl
62.5 x 46.5 x 32.5

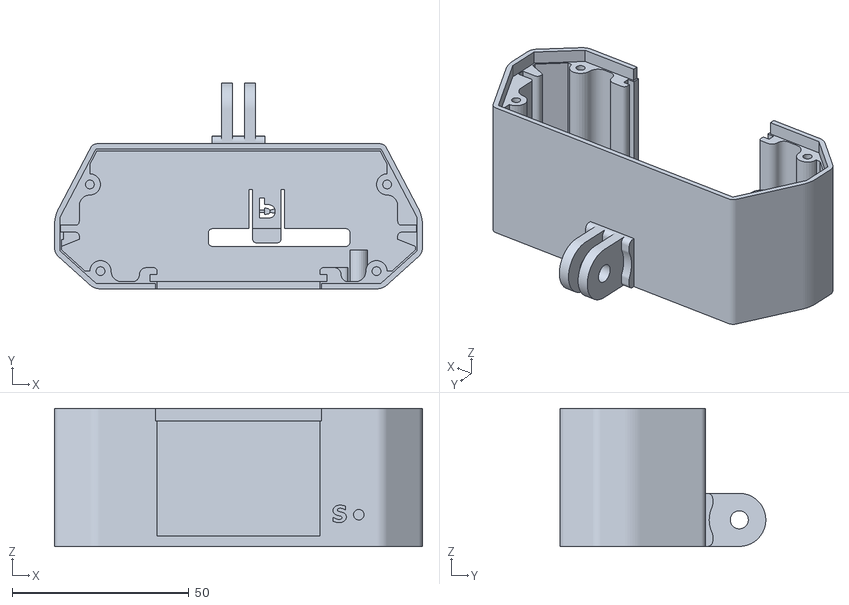
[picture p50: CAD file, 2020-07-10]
case/v5/SoftRF-Case-Prime2-Body-V11-GoPro.stl
104.0 x 58.1 x 39.0

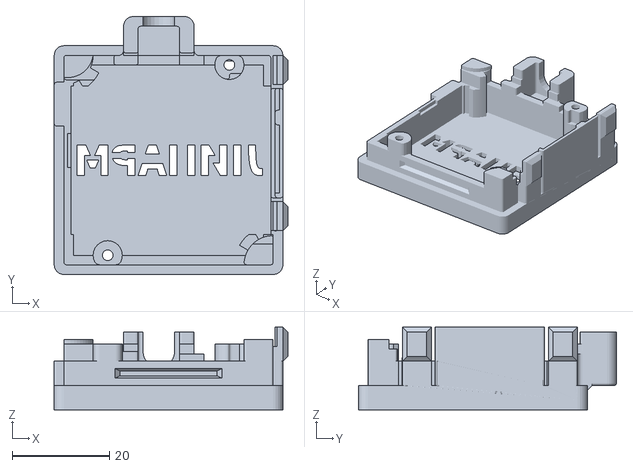
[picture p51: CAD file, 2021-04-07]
case/Badge/SoftRF-Case-Badge-Body.stl
48.0 x 53.0 x 17.0

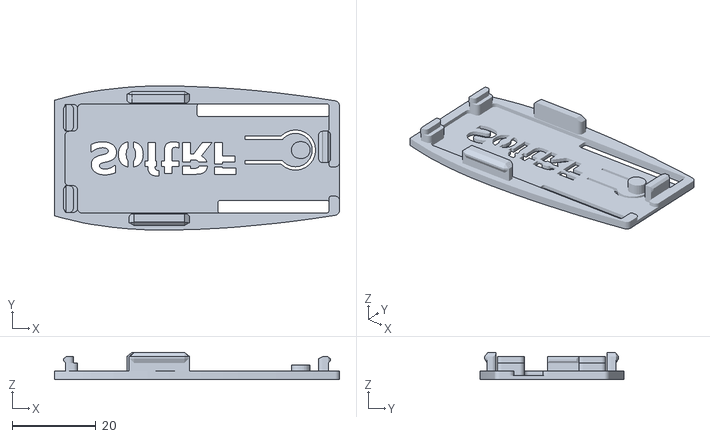
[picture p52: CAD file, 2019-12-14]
case/Dongle/SoftRF-Case-Dongle-Slim-Lid.stl
68.0 x 34.4 x 6.50

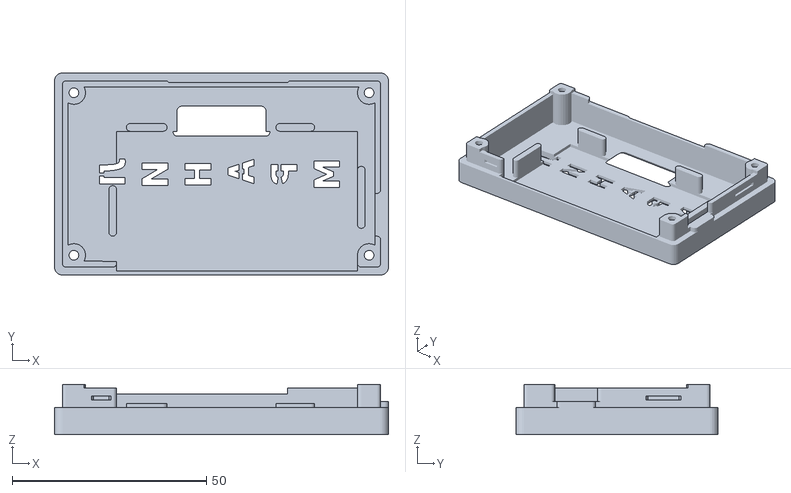
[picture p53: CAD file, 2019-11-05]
case/SkyView/SkyView-Case-EZ-Body-plus.stl
86.0 x 52.0 x 13.0

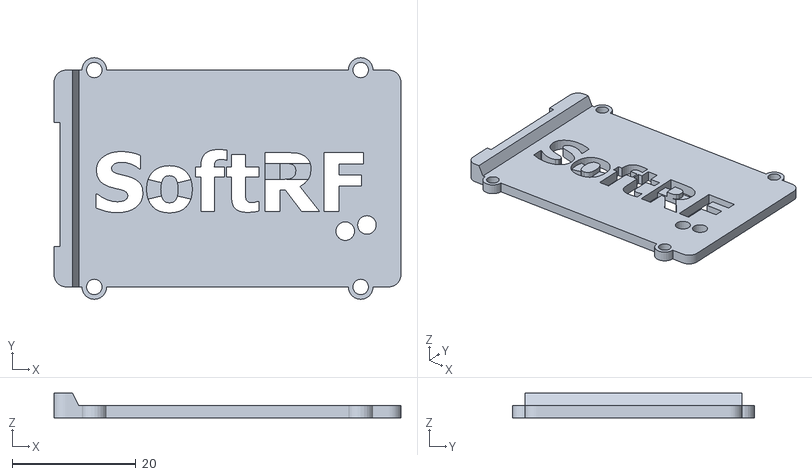
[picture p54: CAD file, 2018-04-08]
case/UAV/SoftRF-Case-UAV-Cover.stl
56.0 x 39.0 x 4.00

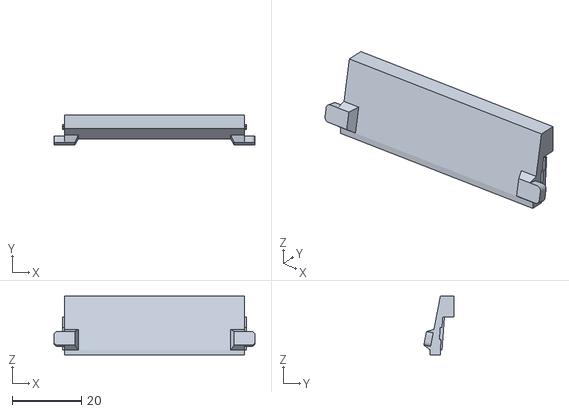
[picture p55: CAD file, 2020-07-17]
case/Uni/SoftRF-Case-Uni-Wall.stl
58.0 x 8.77 x 17.0

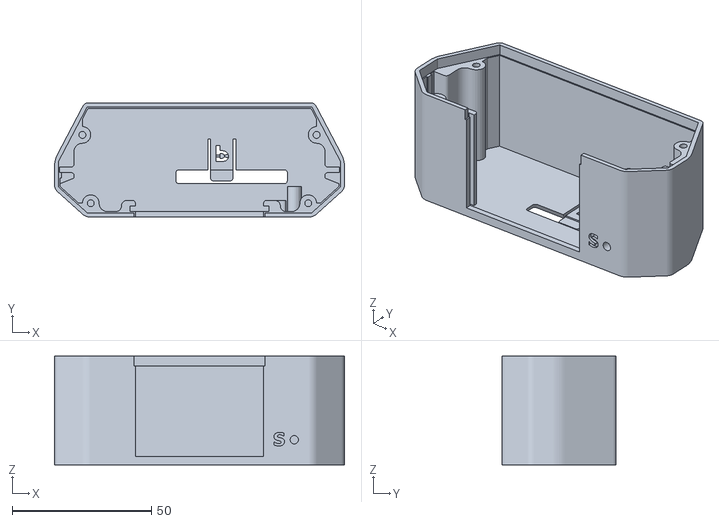
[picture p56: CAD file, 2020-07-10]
case/v5/SoftRF-Case-Prime2-Body-V11.stl
104.0 x 41.0 x 39.0

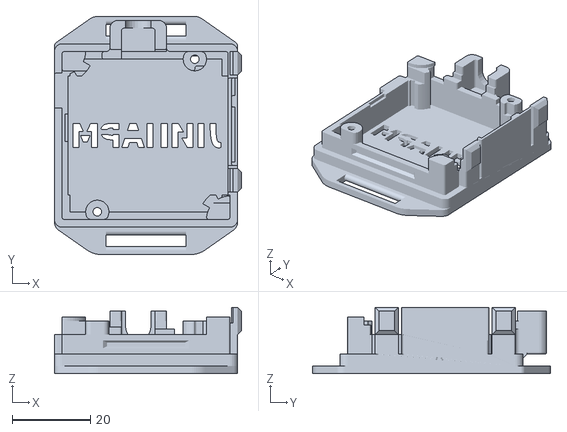
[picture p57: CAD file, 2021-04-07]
case/Badge/SoftRF-Case-Badge-Body-belt.stl
48.0 x 61.0 x 17.0

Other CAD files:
case/Mini/SoftRF-Case-Mini-Body-FPH.stl
case/Dongle/SoftRF-Case-Dongle-Cap-16mm.stl
case/Mini/SoftRF-Case-Mini-Lid.stl
case/SkyView/SkyView-Case-EZ-Body.stl
case/Dongle/SoftRF-Case-Dongle-Battery-Body.stl
case/Dongle/SoftRF-Case-Dongle-OLED-Lid.stl
case/Dongle/SoftRF-Case-Dongle-Slim-Body.stl
case/Dongle/SoftRF-Case-Dongle-Slim-Cap.stl
case/Mini/SoftRF-Case-Mini-Body-PPH.stl
case/SkyView/SkyView-Case-EZ-Face.stl
case/SkyView/SkyView-Case-EZ-Holder.stl
case/SkyView/SkyView-Case-EZ-Speaker-40mm.stl
case/v1/SoftRF-Case-v1-Face-Amica.stl
case/v1/SoftRF-Case-v1-Mid-Section.stl
case/v1/SoftRF-Case-v1-Rear-Section.stl
case/v4/SoftRF-Case-v4-Ant-Clip.stl
case/v4/SoftRF-Case-v4-Battery-Compartment.stl
case/v4/SoftRF-Case-v4-Battery-Cover.stl
case/v4/SoftRF-Case-v4-Body.stl
case/v4/SoftRF-Case-v4-Face-Plate.stl
case/v4/SoftRF-Case-v4-NRF905-A-Clip.stl
case/v4/SoftRF-Case-v4-NRF905-P-Clip.stl
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

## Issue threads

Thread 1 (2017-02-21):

garbage in GPS data

biturbo, 2017-02-21:
Hi I was just checking your code and I was not able to get a clean NMEA data out on TX (GPIO1), do you have any idea why, NMEA sentence are correct on D3 (GPIO0), I reduced the baud to 9600 on both GPIOs

here an example of data with garbage:

$GPGSV,3,2,12,02,30,309,,03,26,110,45,40,19,1¦ i’bŠÊb‚ÊŽIš²bšŠRºÊj
$GPGGA,081102.000,4735.0051,N,00NM&é’‚¢b*±1,08,1.25,430.4,M,48.0,M,,*68 $GPRMC,081118.000,A,4735.0051,N,00852.7203,EKr‚‚b‚r‚‚b’Š‚’Šîbbb
$GPGSV,æIbŠ’b‚’bš‚bš‚ÊbŽ	šb’²bŠŠ‚b¢ªb¢‚Ž)ÊbŠ’ªbš’bŠÊb‚ÊŽIš²bš‚RºÂj
$GPVTG,$PFLAU,1,1,2,1,3,-102,2,44,4*4A

lyusupov, 2017-02-21:
Due to hardware restrictions I had to use SoftwareSerial to pick data from ublox.
I suspect that SwSerial is affected by external activity such as Wi-Fi traffic.
My current choice is to limit NMEA sentences to a minimum - GxRMC and GxGGA only.
I've used "U-center" to get rid of other messages (as well as to set up "Aircraft-2g" kinematic model).

I estimate that loss of NMEA input to about not more 10%.  Which is acceptable for this moment.

biturbo, 2017-02-26:
Would it not be better to use Serial1 (GPIO2/D4) as the TX for BTRX and the Serial (GPIO3/RX) for GPSTX so you would not use SoftwareSerial, just an idea.

lyusupov, 2017-02-26:
This is the ESP8266  GPIO pins allocation map that I've taken into account:

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

With NodeMCU I am unable to manage GPIO3 for hardware serial input because this pin is connected to CP2102 through  470 Ohm resistor. See this schematic for details: https://github.com/nodemcu/nodemcu-devkit-v1.0/blob/master/NODEMCU_DEVKIT_V1.0.PDF

I saw no information on how to put CP2102 into off mode or any other mode which would leave this Tx line into 'free' state. When t is not free - 470 Ohm is too heavy load for GPS module to override.

If you suffering a lot from this "garbage" you may consider to solder yourself ESP-12 onto a PCB which would have same form factor and pinout as NodeMCU.

I earlier decided to leave this issue "AS IS" as a known compromise.

lyusupov, 2017-02-28:
An illustration that reduction of NMEA input to a minimum does help.
Ublox "factory" settings:
```
$GPGLL,,,,,155832.00,V,N*42`
$GPRMC,15583&   ▒b
                  ▒5600.54310,N,822.22946,E,155833.00,A,A*60
,10,215,20,17,47,063,*7A
$GPGSV,5,3,17,19,64,087,,22,05,025,,24,68,240,29,25,07,271,32*7E
$GPGSV,5,4,17,28,06,087,,32,19,323,,37,24,200,27,39,25,196,27*75
$GPGSV,5,5,17,42,,,▒▒▒5
                       $GPGLL,,,,,155834.00,V,N*44
$GPRMC,155835.00,V,,,,,,,280217,,,N*7C
$GPVTG,,,,,,,,,N*30
$GPGGA,155835.00,,,,,0,03,5.63,,,,,,*5A
$GPGSA,A,1,15,25,12,,,,,,,,,,5.72,5.63,1.00*01
$GPGSV,5,1,17,01,05,018,,02,7C
$GPGLL,,,,,155835.00,V,N*45
0,215,20,17,47,063,*74
$GPGSV,5,3,17,19,64,087,,22,05,025,,24,68,240,31,25,07,271,33*76
$GPGSV,5,4,17,28,06,087,,32,19,323,,37,24,200,27,39,25,196,27*75
$GPGSV,5,5,17,42,,,27*7C
$GPGLL,,,,,155836.00,V,N*46

$GPGLL,5600.54121,N,03822.22841,E,155837.00)▒A*62
$GPRMC,155838.00,A,5600.54078,N,03822.22691,E,1.194,,280217,,,A*79
$GPVTG,,T,,M,1.194,N,2.211,K,A*2E
$GPGGA,155838.00,5600.54078,N,03822.22691,E,1,03,5.62,187.5,M,12.5,M,,*59
$GPGSA,A,2,15,25,12,,,,,,,,,,5.71,5$PFLAU,1,1,2,1,1,-64,2,251,778*43
$PFLAA,1,341,-699,251,2,FCA567,,,,,1*2F
3,27,37,24,200,29,39,25,196,29*79
$GPGLL,5600.54078,N,03822.22691,E,155838.00,A,A*63
41,27,15,10,215,21*7C
$GPGSV,5,3,17,17,47,063,16,19,64,087,,22,05,025,18,24,68,240,32*7F
$GPGSV,5,4,17,25,07,271,33,28,06,087,,32,19,323,,37,24,200,28*78
$GPGSV,5,5,17,39,25,196,28*46
$GPGLL,,,,,155839.00,V,N*49
$PFLAU,1,1,2,1,1,-66,2,251,831*43
$PFLAA,1,338,-759,251,2,FCA567,,,,,1*2C
,26,15,10,215,20*7C
$GPGSV,5,3,17,17,47,063,12,19,64,087,,22,05,025,,24,68,240,31*71
$G▒▒eŪb▒b▒▒b▒▒b▒▒b▒▒▒b▒▒b▒▒b▒▒b▒ºbb▒▒b▒▒b▒▒▒bb▒▒b▒▒b▒▒▒b▒▒R▒▒j
                                                              $GPGSV,5,5,17,39,25,196,27*49
$GPGLL,,,,,155840.00,V,N*47
$GPRMC,155841.00,V,,,,,,,280217,,,N*7F
$GPVTG,,,,,,,,,N*30
$GPGGA,155841.00,,,,,0,00,99.99,,,,,,*6A
$GPGSA,A,1,,,,,,,,,,,,,99.99,99.99,99.99*30
$GPGSV,4,1,16,01,05,018,,02,09,160,,03,02,045,22,04,,,,,,,,280217,,,N*7C
!▒u025,,24,68,240,31*72
$GPGSV,4,4,16,25,07,271,32,28,06,087,,32,19,323,,39,25,196,27*75
$GPGLL,,,,,155842.00,V,N*45
,155843.00,A,A*66
,155844.00,A,A*60
2,02,09,160,,03,02,045,,04,,,25*49
$GPGSV,4,2,15,06,28,127,,12,47,270,40,14,05,341,25,15,10,215,20*72
$GPGSV,4,3,15,17,47,063,,19,64,087,5600.53860,N,03822.22878,E,1,04,11.48,189.6,M,12.5,M,,*68
$G▒▒▒,07,271,31,28,06,087,18,32,19,323,27*4F
$GPGLL,5600.53860,N,03822.22878,E,155846.00,A,A*65
00,E,155847.00,A,A*6D
```
GxGSV, GxVTG, GxGLL GxGSA are disabled. ( TinyGPS+ ignores them anyway ):

```
$GPRMC,174308.00,A,5600.56151,N,03822.26892,E,1.357,,280217,,,A*7E
$GPGGA,174308.00,5600.56151,N,03822.26892,E,1,04,4.73,151.0,M,12.5,M,,*5B
$PFLAU,1,1,2,1,1,-61,2,287,1074*77
$PFLAA,1,520,-939,287,2,FCA567,,,,,1*20
$GPRMC,174309.00,A,5600.56125,N,03822.26864,E,1.804,,280217,,,A*78
$GPGGA,174309.00,5600.56125,N,03822.26864,E,1,04,4.73,150.8,M,12.5,M,,*59
$GPRMC,174310.00,A,5600.56107,N,03822.26918,E,1.552,,280217,,,A*74
$GPGGA,174310.00,5600.56107,N,03822.26918,E,1,04,4.73,149.8,M,12.5,M,,*53
$PFLAU,1,1,2,1,1,-63,2,289,1036*7D
$PFLAA,1,470,-923,289,2,FCA567,,,,,1*21
$GPRMC,174311.00,A,5600.56106,N,03822.26912,E,1.231,,280217,,,A*7C
$GPGGA,174311.00,5600.56106,N,03822.26912,E,1,04,4.73,150.3,M,12.5,M,,*5A
$GPRMC,174312.00,A,5600.56097,N,03822.26857,E,0.800,,280217,,,A*7F
$GPGGA,174312.00,5600.56097,N,03822.26857,E,1,04,4.72,150.4,M,12.5,M,,*56
$PFLAU,1,1,2,1,1,-63,2,288,1035*7F
$PFLAA,1,470,-922,288,2,FCA567,,,,,1*21
$GPRMC,174313.00,A,5600.56029,N,03822.26670,E,0.986,,280217,,,A*7F
$GPGGA,174313.00,5600.56029,N,03822.26670,E,1,04,4.72,152.0,M,12.5,M,,*5F
$PFLAU,1,1,2,1,1,-66,2,286,1019*7A
$PFLAA,1,414,-931,286,2,FCA567,,,,,1*2F
$GPRMC,174314.00,A,5600.55992,N,03822.26567,E,1.653,,280217,,,A*71
$GPGGA,174314.00,5600.55992,N,03822.26567,E,1,04,4.72,153.0,M,12.5,M,,*56
$GPRMC,174315.00,A,5600.5597$PFLAU,1,1,2,1,1,-66,2,285,1019*79
$PFLAA,1,414,-931,285,2,FCA567,,,,,1*2C
8,N,03822.26510,E,0.968,,280217,,,A*72
$GPGGA,174315.00,5600.55978,N,03822.26510,E,1,04,4.72,154.1,M,12.5,M,,*55
$GPRMC,174316.00,A,5600.55981,N,03822.26513,E,0.772,,280217,,,A*71
$GPGGA,174316.00,5600.55981,N,03822.26513,E,1,04,4.72,153.6,M,12.5,M,,*53
$PFLAU,1,1,2,1,1,-69,2,285,1051*7A
$PFLAA,1,376,-981,285,2,FCA567,,,,,1*24
$GPRMC,174317.00,A,5600.55967,N,03822.26476,E,0.939,,280217,,,A*7B
$GPGGA,174317.00,5600.55967,N,03822.26476,E,1,04,4.72,154.2,M,12.5,M,,*5B
$GPRMC,174318.00,A,5600.55938,N,03822.26404,E,1.029,,280217,,,A*72
$GPGGA,174318.00,5600.55938,N,03822.26404,E,1,04,4.72,154.7,M,12.5,M,,*5E
$PFLAU,1,1,2,1,1,-69,2,284,1050*7A
$PFLAA,1,376,-980,284,2,FCA567,,,,,1*24
$GPRMC,174319.00,A,5600.55908,N,03822.26415,E,1.247,,280217,,,A*7A
$GPGGA,174319.00,5600.55908,N,03822.26415,E,1,04,4.71,153.6,M,12.5,M,,*59
$PFLAU,1,1,2,1,1,-69,2,285,1051*7A
$PFLAA,1,376,-981,285,2,FCA567,,,,,1*24
$GPRMC,174320.00,A,5600.55886,N,03822.26385,E,0.483,,280217,,,A*76
$GPGGA,174320.00,5600.55886,N,03822.26385,E,1,04,4.71,153.3,M,12.5,M,,*5F
$PFLAU,1,1,2,1,1,-72,2,285,1093*7E
$PFLAA,1,337,-1039,285,2,FCA567,,,,,1*1A
$GPRMC,174321.00,A,5600.55882,N,03822.26405,E,0.464,,280217,,,A*75
$GPGGA,174321.00,5600.55882,N,03822.26405,E,1,04,4.71,152.6,M,12.5,M,,*51
$GPRMC,174322.00,A,5600.55887,N,03822.26453,E,1.466,,280217,,,A*73
$GPGGA,174322.00,5600.55887,N,03822.26453,E,1,04,4.71,151.9,M,12.5,M,,*58
$PFLAU,1,1,2,1,1,-72,2,287,1093*7C
$PFLAA,1,338,-1040,287,2,FCA567,,,,,1*19
$GPRMC,174323.00,A,5600.55896,N,03822.26494,E,1.254,,280217,,,A*7E
$GPGGA,174323.00,5600.55896,N,03822.26494,E,1,04,4.71)▒▒r▒bj▒12.5,M,,*5C
$GPRMC,174324.00,A,5600.55906,N,03822.26528,E,0.804,,280217,,,A*79
$GPGGA,174324.00,5600.55906,N,03822.26528,E,1,0$PFLAU,1,1,2,1,1,-72,2,287,1094*7B
$PFLAA,1,338,-1040,287,2,FCA567,,,,,1*19
4,4.71,151.8,M,12.5,M,,*5A
$GPRMC,174325.00,A,5600.55900,N,03822.26489,E,0.684,,280217,,,A*72
$GPGGA,174325.00,5600.55900,N,03822.26489,E,1,04,4.71,152.4,M,12.5,M,,*58
$PFLAU,1,1,2,1,1,-74,2,286,1116*77
$PFLAA,1,307,-1073,286,2,FCA567,,,,,1*14
$GPRMC,174326.00,A,5600.55889,N,03822.26455,E,0.948,,280217,,,A*7F
$GPGGA,174326.00,5600.55889,N,03822.26455,E,1,04,4.71,152.5,M,12.5,M,,*5B
$GPRMC,174327.00,A,5600.55849,N,03822.26306,E,0.948,,280217,,,A*73
$GPGGA,174327.00,5600.55849,N,03822.26306,E,1,04,4.70,154.1,M,12.5,M,,*54
$PFLAU,1,1,2,1,1,-74,2,284,1115*76
$PFLAA,1,307,-1072,284,2,FCA567,,,,,1*17
$GPRMC,174328.00,A,5600.55857,N,03822.26318,E,0.694,,280217,,,A*72
$GPGGA,174328.00,5600.55857,N,03822.26318,E,1,04,4.70,154.5,M,12.5,M,,*5F
$PFLAU,1,1,2,1,1,-76,2,284,1131*72
$PFLAA,1,273,-1098,284,2,FCA567,,,,,1*11
```

lyusupov, 2017-03-02:
Fixed in https://github.com/lyusupov/SoftRF/commit/c57a812f7b8df99402bc9689fd88598591123adc

Closed 2017-03-02.

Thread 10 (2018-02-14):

Software Compile Fails

kinnonk, 2018-02-14:
Hi

Trying to compile the latest source - but getting the following errors - any ideas ?

Arduino: 1.8.5 (Windows 10), Board: "NodeMCU 1.0 (ESP-12E Module), 80 MHz, 4M (1M SPIFFS), v2 Prebuilt (MSS=536), Disabled, None, 115200"

Protocol_FANET.cpp:60: error: 'const rf_proto_desc_t {aka const RF_PROTOCOL}' has no non-static data member named 'tx_interval_min'

 };

 ^

exit status 1
'const rf_proto_desc_t {aka const RF_PROTOCOL}' has no non-static data member named 'tx_interval_min'

lyusupov, 2018-02-14:
Build options: Arduino Core for ESP8266 v2.4.0 , **lwIP v1.4 prebuilt**

lyusupov, 2018-02-14:
With Arduino 1.8.5 on **Debian** I am unable to confirm any build issues-
current build works fine to me both for NodeMCU and ESP32.

Resolution: **Unable to reproduce**.

Closed 2018-02-14.

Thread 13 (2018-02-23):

Wi-Fi stability issues when GPS module connected

ljozsa, 2018-02-23:
Hi,

I'm suffering with random Wi-Fi AP crashes when GPS module is connected. The Wi-Fi hotspot just dies within a minute or so. I don't see anything suspicious on console. I see data flowing over Bluetooth so the CPU is alive. When GPS is disconnected Wi-Fi connection seems to be much more stable.

Thanks,
L.

lyusupov, 2018-02-24:
Stand by. Advisory will follow.

lyusupov, 2018-02-24:
Some of the SoftRF builders had reported that was affected by this (or similar) issue, some - did not report...

**Abstract**: it is known fact that current Wi-Fi stack on ESP8266 is not "interrupt friendly".
This is an issue of Espressif 8266 SDK + Core (+SoftwareSerial library)

I have 4 workarounds and solutions against this to reduce the impact of this issue on the SoftRF project.
I will not give all of them right now. Let's start from intial, "least actions" approach:

Use  any USB-to-RS232 adapter and re-configure your GNSS module to supply minimum required NMEA messages. For SoftRF it is sufficient to input $GxRMC and $GxGGA only.
For reference NMEA (+"Legacy") output use my logs mentioned in this ticket:  https://github.com/lyusupov/SoftRF/issues/1

The name of the configuration utility for uBlox-8 based BN-880 modules (referenced in Standalone's BOM ) is **uCenter**. Use google for the configuration instructions. Don't forget to strore settings into GNSS's NVRAM.

Report if you still suffering of the issue when you are done.

The ticket is re-assigned back to you.

ljozsa, 2018-02-25:
Thanks for your suggestion. I have reconfigured the GPS module as you proposed and the stability is a little bit better in terms of how long's Wi-Fi alive. The hotspot no longer disappear while other communication goes on but I'm observing much higher frequency of CPU reboots. It keeps rebooting roughly every 10 minutes if the client is associated with the AP. It seems to be more stable without client connection. For the reference I'm using the V.KEL VK2828U7G5LF GPS module but this should not matter as it's the same uBlox-8 hardware.

lyusupov, 2018-02-25:
Check your NodeMCU and PCB soldering quality. Any small invisible "solder bridge" may cause increased current drain which, reported, leads to reduced stability of the NodeMCU board. Try to use another instance of the NodeMCU.

Please, provide:
- boot log taken over USB cable
- screenshot of settings
- screenshot of status

Typical use case of Standalone is:
- minimal use of Wi-Fi: few, rare sessions for configuration purpose only
- watch LED ring for warnings
- feed FLARM NMEA data wirelessly over Bluetooth for a Glide Computer

Brief list of all known workarounds and solutions for "ESP8266 Soft AP issue":
1) Wireless client mode
2) AP, Software serial, reduced NMEA input, increased baud rate
3) AP, Hardware serial
4) ESP32

You are currently using partial 2) workaround.
Solutions/workarounds 1)-3) - all of them have  some compromises.

The only currently known "no compromise" solution is to migrate onto ESP32.
But it needs more builder's actions and time spent.
So if you need "no compromises" - we may close this ticket and you proceed into transition onto ESP32.
Expect to wait until April'18 when I'll publish "gerber" files of adapter for ESP32 to sit into NodeMCU's slot.

***U7** in the  product name VK2828**U7**G5LF means - it is uBlox-7 based. You may test it by doing UBX -> MON -> VER in u-Center.

True uBlox-8 module is VK2828**U8**G5LF.
This is an example of such module: https://www.aliexpress.com/item/VK2828U8G5LF-GPS-GLONASS-UBLOX-NEO-M8N-model-aircraft-flight-control-module-compass/32647315738.html

ljozsa, 2018-02-25:
So after changing the NodeMCU board system doesn't reboot anymore, that's good. So it seems there was some hardware issue, I'll inspect the board for solder bridges. The WiFi AP crashes after longer time than before, so hypothesis with interrupt problems seems to be correct.

I'd like to try option 1). Does it require recompilation of the source code? Or is it possible to set it up somehow?

It's true that once I setup the module over WiFi for the first time there wouldn't be much use cases for the WiFi so it's not so critical. I'm using it more this time since I'm playing with the various options.

BTW I tried to switch the protocol to Legacy and my OGN receiver doesn't see it. I'm quite far away from it, so it's possible that if the OGNTP uses a different modulation, the problem can be too weak signal. Did I understand it correctly that Legacy protocol should be compatible with current FLARM's so the FLARM should see it? I haven't got a chance yet to try it against FLARM.

I'd like to also ask about FANET - is this compatible with OGN receiver? The cool feature that I like there is retransmission of the packets by participating nodes.

Thanks for info about chipsets in GPS module. Yep, you're right it's uBlox-7.

Also, please note that if the troubleshooting is too time consuming, I'd rather wait for ESP32 solution and not waste your time on ESP8266 that you'll deprecate soon.

lyusupov, 2018-02-26:
> I'd like to try option 1). Does it require recompilation of the source code?

1. follow this guidance first: https://github.com/lyusupov/SoftRF/tree/master/software/firmware/source
2. then edit https://github.com/lyusupov/SoftRF/blob/master/software/firmware/source/SoftRF/SoftRF.h
    with your SSID/PSK and re-build

> BTW I tried to switch the protocol to Legacy and my OGN receiver doesn't see it.

Update your firmware onto RC2. Release notes: https://github.com/lyusupov/SoftRF/releases

> I'd like to also ask about FANET - is this compatible with OGN receiver?

I think - no, but you'd better ask OGN guys.

> The cool feature that I like there is retransmission of the packets by participating nodes.

OGN tracker (OGNTP) does also have "retransmission".
I think it is more "marketing feature" than reality because, when:
- following "1% duty cycle rule" on 868 MHz band and
- 1 packet per second transmit rate and
- "time in the air" of every protocol

there is no a timeslot to legally transmit anything except own position.
OGN guys are using freq. hopping and interleaving to achieve retransmission,
but anyway it likely works good only for a low-scale (1-3 units flying around)

And significant remark on compatibility of SoftRF with other protocols:
It is necessary for a reader to distinguish the difference between statement "**compatible**"
and statement "**fully compatible**".
SoftRF implements only a "minimum" or "close to minimum" protocol support.
No "bells and whistles" so far.

> on ESP8266 that you'll deprecate soon.

No. There are reasons to maintain both ESP8266 and ESP32 platforms at least
until the end of year 2018.

ljozsa, 2018-03-04:
Linar, thanks a lot for all your help and explanations. I tried to compile the code myself and everything's work as expected. I think we're good to close this issue.

I'm close to completion of 5 trackers that will be put into our aeroclub's gliders so we'll see how it goes in practice.

lyusupov, 2018-04-24:
Ladislav,

If you've recently ordered some PCBs of  NODEMCU-ESP32-ADAPTER and current status is "panelization" - try (if possible) to postpone transition into "fabrication" for couple days.
There is a minor issue which affects only ESP32 I2C operations over upcoming SoftRF LoRa I2C port.

If unable - it's Ok , I will issue an errata for revision 1.0 of the adapter on how to fix it.

I will likely update gerber files on pcbs.io with revision 1.1 tomorrow or next day after tomorrow.

Drop me your e-mail address for direct feedback.

lyusupov, 2018-06-03:
Recent improvements of SoftwareSerial library give us a chance for this issue to become at least partially fixed. Coming soon...

lyusupov, 2018-06-12:
This issue have become rare but still exists.

Closed 2018-07-12.

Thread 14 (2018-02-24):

Question about LED indicators

ljozsa, 2018-02-24:
Hi,

when I power up the device I see a self test of the LED's and it seems to be working well for the LED ring. However, LED's in vertical LED bar are blinking synchronously all the time and when the test finishes, all LED's are lit with red color. How are the LED's supposed to be interconnected? Right now I have connected all plus inputs on one wire, all ground inputs on another wire and all DIN inputs on the last wire. Is that correct?

Also, after self test, the LED's in the LED ring are illuminated a little bit by RGB colors. Is it correct behavior?

What is the purpose of the LED bar? What should it indicate?

Many thanks,
L.

lyusupov, 2018-02-24:
vertical LED strip is extension of the ring.
each DO is connected to DI of the next one in sequence.

They are status LEDs. Purpose of each is indicated on the faceplate: https://github.com/lyusupov/SoftRF/blob/master/case/v4/SoftRF-Case-v4-Face-Plate.stl
Order is the same or close to that the FLARM has.

lyusupov, 2018-02-24:
> LED's in the LED ring are illuminated a little bit by RGB colors

Yes, this is intentional backlit for dark daytime or shade when it is hard to see the arrow on faceplate.

Closed 2018-02-24.

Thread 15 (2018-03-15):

No FLARM sentences

kinnonk, 2018-03-15:
Hi,

This may be an issue with the settings I am using but when connected to the Soft-RF module I get what seems to be normal NMEA sentences, but no FLARM sentences.    Consequently when I check the status of the device I see GPS fix rather than GPS fix; FLARM in XCSoar.     Am I doing something wrong - using XCSoar with GNSS and Legacy protocols switched on with Legacy/Normal mode ?

Thanks in advance for help !

Regards,

Kenny

lyusupov, 2018-03-16:
When submitting an issue, please, supply screenshots of SoftRF's:
-  status page ;
- settings page;

$PFLAU and $PFLAA FLARM NMEA sentencies are being emitted over UART/BT only when:
- SoftRF has valid GNSS fix, and
- "NMEA legacy" is enabled in settings, and
- SoftRF is receiving valid RF packets of selected radio protocol from a neighbour proximity awareness unit.

kinnonk, 2018-03-16:
Thanks Linar !

Got it sorted now - great little project by the way !

Thanks

Kenny

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

ZaxCZ, 2018-07-11:
What are the correct/recommended XCSoar settings (i.e. what driver should I use)? I keep getting "no data" in device manager, but I can see it's receiving - looks like [this](https://i.imgur.com/5fNKcUN.png) (might be a wrong baud rate, I'm not sure what format to expect, this one looked closest to something readable).

As you said, this might be caused by not having another awareness device nearby. In the next few days, I will hopefully test it with FLARM and also OGN receiver.

_I thought this was kinda related and not worth opening another ticket for, so I ask this here. Awesome work, Linar! _

lyusupov, 2018-07-11:
your report looks like a  duplicate of this https://github.com/lyusupov/SoftRF/issues/11

ZaxCZ, 2018-07-12:
Thank you, you are correct. I have set the baud rate to 38400, one stop bit, no parity bits, now I'm getting FLARM and GPS in XCSoar, however, I'm getting multiple `bad parity of decoded packet: 1` and some NMEA sentences, including my location (I have left out the GNGLL sentence in the screenshot for obvious reasons). Looks like [this](https://i.imgur.com/uqK1nxx.png).

lyusupov, 2018-07-12:
"bad parity of decoded packet" typically happens with "Legacy" protocol when SoftRF is out of time sync with GNSS date & time.

For information on GNSS module set-up read:
1. [this](https://github.com/lyusupov/SoftRF/issues/13#issuecomment-368247525)
2. and [this](https://github.com/lyusupov/SoftRF/issues/1#issuecomment-281290554)

What particular MCU do you use? and what particular GNSS module?

lyusupov, 2018-07-13:
Ok,

1. You'd better open  a separate GitHub ticket rather than re-using this one
2.  With your report I am uncertain do you test it against a FLARM or another SOFTRF unit?
If this is the second case - you have to be 100% sure that the partner instance has valid and accurate GNSS time & date. Check it"s status WebUI page. If any of partner's is more than 64 seconds out of sync - "legacy" encryption/decryption will not work properly.
3. SoftRF ignores most of NMEA sentencies except GxRMC and GxGGA. **These two are mandatory**. Use U-center and get rid of all other sentencies except these two.
4. There were no reports to me about non-compliance with V6 after this update: https://github.com/lyusupov/SoftRF/commit/2491a808dfc8ac92e9dc24fbd9012559ba30d926
5. There are plenty of active SoftRF builders/users in Czech Republic. At least two of them are GitHub users ( https://github.com/ljozsa https://github.com/jharting ) . Why don't you ask them if they have same issues you are sufferng from, directly and in your native language?

lyusupov, 2018-07-13:
Ok. Thanks! Now it makes more sense...

So,  you have NRF module plugged in, no any FLARM sources around, GNSS module got a fix, and just after that it stats to emit "bad parity" messages, right?

Ok. Check WebUI status page. See if the Radio is detected as NRF905. If not - check every soldering work you did and replace NodeMCU with another one. Same thing with the NRF module.

If WebUI says - the module is in, go to to the Settings, enable Private messages, save and restart.
Capture output of $PSRFI messages (raw packet's hexadecimal data) and copy it here in the thread, or send to me by e-mail.

Closed 2018-03-16.

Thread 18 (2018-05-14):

Size issue on ESP32 with RC3 - 102% on Heltec ESP32

GithubReinart, 2018-05-14:
Hello Linar,

thanks for your great work.

Trying out SoftRF on ESP8266 and ESP32 HW since April.
WIth RC3 I am observing size issues now when building in Arduino environment following Instruction concerning board setup and the specific libraries.
While RC2 consumed only about 86% of the maximum space for Heltec ESP32 board RC3 now uses 1337326 Bytes (102%) ... Maximum is 1310720 Bytes.

Do you have hint for basic Arduino setup or other libraries?

KInd Regards
Manfred

lyusupov, 2018-05-14:
Manfred,

Keep monitoring [official build instructions](https://github.com/lyusupov/SoftRF/tree/master/software/firmware/source) - they are typically become updated with each significant change of the procedure.
You need to switch onto "Minimal SPIFFS" partition scheme.

A warning at build time may still appear. It can be safely ignored.
For details, read [this](https://github.com/espressif/arduino-esp32/pull/1302) and [that](https://github.com/espressif/arduino-esp32/issues/1378)
In order to get rid of the annoying warning, fix your local Arduino ESP32 Core's **boards.txt** using
my [Travis CI](https://github.com/lyusupov/SoftRF/blob/master/.travis.yml) script as an example.

GithubReinart, 2018-05-14:
Hello Linar,

Thanks for the quick reply - I already set „Minimal SPIFFS“ partition scheme before sending the message.
Will also check the other information provided.

Many Thanks
Manfred

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

lyusupov, 2018-05-14:
One more comment regarding Heltec:
you will not get a picture on the Heltec's OLED until your ESP32 Core's I2C will not be updated onto "experimental" version been developed by Chuck Todd.
 Follow [these instuctions]( https://desire.giesecke.tk/index.php/2018/04/20/how-to-use-stickbreakers-i2c-improved-code/ ).

Closed 2018-05-14.

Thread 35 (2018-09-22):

No valid GNSS fix

chestnutbraun, 2018-09-22:
## Hardware

- [X]   Prime Mark II
- [ ]   Standalone
- [ ]   UAV

< photo of your hardware > (optional)
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

TTGO T-Beam Version: T22_V07 20180711

## Firmware version
1.0-rc4+ ESP32
<  screenshot of WebUI status page > (**required**)
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

## Firmware settings
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

<  screenshot of WebUI settings page > (**required**)

## Describe the bug (or ask a question)
In SoftRF I can not get a valid GNSS fix although the red LED on the board indicates GPS reception.
I then tried to update the firmware to 1.0-rc5 but the update failed. 1.0-rc4+ shows to be still the valid software version on the TTGO T-Beam
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
How can I get a valid GNSS fix in SoftRF?

## To Reproduce

## Expected behavior

lyusupov, 2018-09-22:
I see this information in your status screenshot:

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

For me it means that the firmware does not see any NMEA sentences that should normally come out of T-Beam's GNSS module.

I don't know you skills level, so I assume that it is zero. It this case I would recommend you to work with your seller of the T-Beam board. Reminder, that my firmware is not responsible for any hardware issues with particular TTGO board, see [this disclaimer](https://github.com/lyusupov/SoftRF/wiki/Prime-Edition-MkII#disclaimer) for more details.

chestnutbraun, 2018-09-22:
Dear Linar, thank you for your time looking into this. Skills level is zero, I can measure voltage with a voltmeter and can solder. I was sure that it was not your firmware and I suspected that there is no original NEO-6M installed, I have read your disclaimer before ordering the board and hoped for the best...

lyusupov, 2018-09-23:
If you need some arguments prior to asking your seller for re-send or refund, try out either of those:

1) connect T-Beam with SoftRF to a PC and TTY terminal emulation software (PuTTY, HyperTerminal for Windows or minicom for Linux). Settings are 38400, 8N1

Regular boot log should look like this:

```
Reset reason: 0
No reset reason.
Free heap size: 4349856
No reset information available.
EEPROM version: 91
SX1276 RFIC is detected.
WARNING! Barometric pressure sensor is NOT detected.
INFO: TTGO T-Beam GPS module is detected.
WiFi config changed.
new SSID:
Hostname: SoftRF-c5d804
Wait for WiFi connection.
....................
Can not connect to WiFi station. Go into AP mode.
Setting soft-AP configuration ... Ready
Setting soft-AP ... Ready
IP address: 192.168.1.1
UDP server has started at port: 12389
HTTP server has started at port: 80
$GPRMC,042829.99,V,,,,,,,220818,,,N*79
$GPGGA,042829.99,,,,,0,00,99.99,,,,,,*63
$GPRMC,042831.00,V,,,,,,,220818,,,N*70
$GPGGA,042831.00,,,,,0,00,99.99,,,,,,*6A
$GPRMC,042832.00,V,,,,,,,220818,,,N*73
$GPGGA,042832.00,,,,,0,00,99.99,,,,,,*69
$GPRMC,042843.00,V,,,,,,,220818,,,N*75
$GPGGA,042843.00,,,,,0,00,99.99,,,,,,*6F

```

2)  Go onto TTGO's GitHub pages and use their GPS.ino sketch to test your T-Beam onto basic GNSS module operation:
 https://github.com/LilyGO/TTGO-T-Beam/tree/master/GPS

3) The onboard board GNSS module delivers serial data to GPIO12 pin of the ESP32. Unfortunately, GPIO12 is not available on PCB's pads for pin header.
If you want, you may try to test if proper signals are available on Tx pad (No. 20) of the "NEO" module.
And you may trace if the signal is delivered to GPIO12 pin of the ESP32.
Use [this schematics](http://ttgobbs.com/viewthread.php?tid=17131) (not up to date but still Ok) as a reference.

lyusupov, 2018-09-23:
Regarding to failure of updating the firmware over web:

As [it was written there](https://github.com/lyusupov/SoftRF/wiki/Firmware-update-(Web-method)#esp32), if you have not succeed with web firmware update method - proceed to [first-time firmware installation procedure](https://github.com/lyusupov/SoftRF/tree/master/software/firmware/binaries#esp32).

chestnutbraun, 2018-09-23:
The boot is as attached and it ends with the line: "HTTP server has started at port: 80"

Reset reason: 0
No reset reason.
Free heap size: 4350240
No reset information available.

EEPROM version: 91
SX1276 RFIC is detected.
Hostname: SoftRF-88bd74
Wait for WiFi connection.
....................
Can not connect to WiFi station. Go into AP mode.
Setting soft-AP configuration ... Ready
Setting soft-AP ... Ready
IP address: 192.168.1.1
UDP server has started at port: 12389
HTTP server has started at port: 80

Thank you again for all your help.

lyusupov, 2018-09-23:
Ok. This is an extra confirmation of [the statement](https://github.com/lyusupov/SoftRF/issues/35#issuecomment-423763102).

The NEO module is either:
1) does not emit NMEA sentences ;
2) emits them, but on baud rate other than 9600 ;
3) emits NMEA, but they are not delivered to ESP32's GPIO12.

If I would have issue like your do, I would connect analog or DS oscilloscope to pin 20 (Tx) of "NEO" module.
If you are unable - work with LilyGO to send you a replacement board.

chestnutbraun, 2018-09-23:
Dear Linar,
now I was able to update to the latest firmware version 1.0-rc5 and now it is working!
Again thank you very much for your support!

lyusupov, 2018-09-23:
If the ticket is not pertinent any more - please, close it.

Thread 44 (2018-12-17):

RESET anomaly with ESP32 + RFM95W

bnsearle, 2018-12-17:
**ATTENTION** !

- Use this form to report bugs in released SoftRF firmware, hardware and web pages only ;
- Prior to asking a question, look into ["Closed issues"](https://github.com/lyusupov/SoftRF/issues?q=is%3Aissue+is%3Aclosed) area to see if it was answered before ;
- No any "ideas" or new feature requests, please ! New feature requests do not subject for taking into consideration unless they come from co-developers ;
- "Enhancements" of existing features are allowed only when you are ready to implement them by yourself ;

Recommended:
- screenshot or photo width - from 600 to 800 pixels ;
- aspect ratio - 4:3, 3:4, 16:9 or 9:16.
- substitute 'space' by 'x' character to mark a hardware checkbox

--------------------

## Hardware

- [ ]   Prime Mark II
- [ x]   Standalone
- [ ]   UAV

< photo of your hardware > (optional)

## Firmware version

<  screenshot of WebUI status page > (**required**)

/home/bryan/Pictures/Screenshot from 2018-12-17 17-25-38.png

## Firmware settings

<  screenshot of WebUI settings page > (**required**)
/home/bryan/Pictures/Screenshot from 2018-12-17 17-26-34.png

## Describe the bug (or ask a question)
Hardware:
ESP32 Development Board, DOIT layout, wired to Hope RFM95W. Software latest SoftRF release 1.0-rc5, date 10/12/18, compiled on Arduino 1.8.5, settings as per instructions. Normal and Legacy mode settings.

Problem:
If the RFM95W RESET is connected to the ESP32 GPIO-14 (as in Platform _ESP32.h) then after a power-up or EN button press then Radio = NONE and there are no RF traffic packets. If you then do a ‘soft’ restart i.e ‘settings/save and restart’ then we get Radio = SX1276 and packets are Tx and Rx, operation OK. However if I disconnect the RESET link then a power up or EN press work as expected.

Comments:
I would like to have the RESET connected on the PCB that I am designing that will use the WROVER module, because then there is the opportunity of introducing a protocol change ‘on the fly’ and/or the use of the watchdog feature  of the ESP32 which would enhance reliability (I think I may have seen hang-ups while soak testing, but I cannot be certain!).

## To Reproduce
see above

## Expected behavior
see above

bnsearle, 2018-12-21:
I have tried the latest version dated 20th, but it did not fix the issue for me. However I have made a fairly crude fix by inserting the following snippet in SoftRF.ino after line 164:

// crude fix for 'sx1276 not detected' issue
  if (resetInfo->reason == 0) {
     RF_Shutdown();
     delay(1000);
     ESP.restart();
  }

  /* expedite restart on WDT reset */
.
.
...... etc

This reports a detected sx1276 (on the serial monitor and web app) after the unsuccessful detection on first power-up or EN button press.

Now I have 2 units that always power-up correctly and communicate as expected - now at the full 20dBm level I see!   I have read that technically the EU limit is less than this (15?), but after antenna losses etc....

As an aside - it would be easier to debug if the NMEA stream came from the unused UART output i.e.  the UART that receives from the GPS module on GPIO22 ? I will attempt that in due course, so I can make that connection on the pcb,....

lyusupov, 2018-12-30:
The issue reported is **NOT CONFIRMED** on Standalone neither with:
* "stock" RC5 firmware binaries, nor
* firmware been built from most recent git source code.

Recommendations:
1) inspect your power and reset circits wiring ;
2) inspect your SPI bus wiring ;

**Resolution**: unable to reproduce.

Closed 2018-12-30.

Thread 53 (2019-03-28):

FEATURE-Request: Type 4 (Groundstation) FANET frames

commander-chris, 2019-03-28:
Hi,

Thank you for the terrific work!

Is it possible to implement Type 4 FANET frames ("Service", see excerpts below, from [FANET Protocol](https://github.com/3s1d/fanet-stm32/blob/master/Src/fanet/radio/protocol.txt)) into SoftRF to run a FANET groundstation (on the paragliding landing site) on a TTGO T-Beam? Would be awesome to TX current measured weather/wind conditions to the pilots in the air...

Thinking of connecting a BMP280 (or preferably a GY-91 to be able to calibrate the wind direction using a tilt compensated compass reading) and a TX-20 to the TTGO via the TTGO's I2C buses, reading the data from the sensors, and transmitting them to the pilots via FANET type 4 frames.

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

Thanks, best regards,
Chris

lyusupov, 2019-03-28:
Ticket is filed not in compliance with [the template](https://github.com/lyusupov/SoftRF/blob/master/.github/ISSUE_TEMPLATE/softrf-issue-template.md).

**Resolution**: invalid.

Closed 2019-03-28.

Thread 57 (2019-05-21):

PCB Sourcefiles

datamann, 2019-05-21:
Hi,

Is it possible to get the source files for the PCB?
I would like to make some modification to it and it would be nice to not have to redraw all from scratch.

Regards
Stig

lyusupov, 2019-05-21:
There are at least 4 different PCB design files in this project: Shield, LoRa, Adapter/UAV, UAT.
Which one?

datamann, 2019-05-22:
Hi lyusupov,

I was thinking of the PCB for the LoRa Module
https://github.com/lyusupov/SoftRF/wiki/SoftRF-LoRa-module

Regards
Stig

lyusupov, 2019-05-22:
Negative.
Your [own project](https://github.com/datamann/LoRaGPS) has nothing related to this one.
To state that it is 'all yours' you have to design your PCB from scratch.
I believe that it is fair enough.

datamann, 2019-05-22:
You're right my project is not related to SoftRf but still your PCB is great work and I will of course share my changes (if I'm able to do the changes. I am a newbie.) with you if you are intrested. I do not recall that I've stated anywhere that is't "all mine", basically nothing is mine, there are always someone who have done all I do before, in some way or another. All I do is to package all the pieces in a different way : https://aconfluence.no/display/SS/LoRaGPS

All I wanted to do was to add a 5v to 3.3v regulator. I burned out one LoRa module because my arduino nano didn't output 3.3v put 3.9v and I didn't checked it before use... bummer...

Well if I have to redraw, I will and I will send you the files anyway so you can deside for your self if you want them or not...

I have printed and bought all SoftRf parts and will build your project later. My project actually started with SoftRF but then I got sidetracked...

Regards
Stig

Closed 2019-05-22.

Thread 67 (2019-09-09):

RasPi 3 with Dragino Lora/GPS hat - SX1276 RFIC detected but no data received

mreinart, 2019-09-09:
Dear Linar,

slightly adapted template for Raspberry issue

## Hardware

- [ ]   Prime Mark II
- [ ]   Standalone
- [ ]   UAV
- [ ]   UAT module
- [ ]   SkyView
- [ ]   Flight Recorder
- [X] Raspberry PI 3
- [x] Dragino Lora/GPS HAT for RPi v1.0

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

## Firmware version

<  screenshot of WebUI status page > (**required**)
- N/A as Raspberry PI version

## Firmware settings

```
mode: normal
protocol: FANET or OGNTP
band: EU
```

<  screenshot of WebUI settings page > (**required**) - N/A as Raspberry PI version

## Describe the bug (or ask a question)

GPS data are received from Dragino hat - "`cat /dev/ttyAMA0`" or `cat /dev/ttys0` produces expected output: `$GPxxx` sentences

Receiver gets detected upon start of "`sudo ./SoftRF`" (`SX1276 RFIC detected`)

No signals received from TTGO based SoftRF device with FANET or OGNTP setting.
Same device is 'seen' by RTL-SDR based OGN receiver

## To Reproduce
start "`sudo ./SoftRF`" or commands as document in PI Examples.

## Expected behavior
`$PFLAA` and `$PFLAU` sentences for received signals

Do I miss some wiring or configuration setting?

lyusupov, 2019-09-09:
You have to manually 'pipe' Dragino's GPS standard output onto SoftRF program's standard input
**as written in [Example 1](https://github.com/lyusupov/SoftRF/wiki/Raspberry-Edition#example-1-basic-operation)**.

**Resolution:** invalid

mreinart, 2019-09-09:
Dear Linar,

thanks for the quick reply - but have done this too - this is what I meant with
> ... or commands as document in PI Examples

and how I also controlled `protocol` (`FANET/OGNT`P) and `band` settings.

e.g. `{ echo "{class:SOFTRF,protocol:FANET}" ; cat /dev/ttyS0 ; } | sudo ./SoftRF`
or `{ echo "{class:SOFTRF,protocol:OGNTP}" ; cat /dev/ttyS0 ; } | sudo ./SoftRF`
which is currently running.

recent output:
```
pi@pi0:~/srf/SoftRF/software/firmware/source/SoftRF $ { echo "{class:SOFTRF,protocol:OGNTP}" ; cat /dev/ttyS0 ; } | sudo ./SoftRF
SX1276 RFIC is detected.
$GPGGA,155142.000,4913.1702,N,00822.4818,E,1,10,0.79,105.8,M,47.9,M,,*65
$GPGLL,4913.1702,N,00822.4818,E,155142.000,A,A*59
$GPGSA,A,3,03,23,02,01,22,06,17,31,07,09,,,1.06,0.79,0.71*00
$GPGSV,3,1,12,23,75,072,24,09,64,229,37,06,55,290,26,03,44,097,37*7E
$GPGSV,3,2,12,22,25,105,11,19,23,247,,02,16,318,27,17,16,234,25*79
$GPGSV,3,3,12,07,13,176,16,01,06,154,22,31,05,029,21,26,05,065,16*75
$GPRMC,155142.000,A,4913.1702,N,00822.4818,E,0.14,18.24,090919,,,A*5C
$GPVTG,18.24,T,,M,0.14,N,0.25,K,A*00
$GPGLL,4913.1702,N,00822.4818,E,155142.000,A,A*59
$GPGSA,A,3,03,23,02,01,22,06,17,31,07,09,,,1.06,0.79,0.71*00
$GPGGA,155142.000,4913.1702,N,00822.4818,E,1,10,0.79,105.8,M,47.9,M,,*65
$GPGSV,3,1,12,23,75,072,24,09,64,229,37,06,55,290,26,03,44,097,37*7E
$GPGSV,3,2,12,22,25,105,11,19,23,247,,02,16,318,27,17,16,234,25*79
$GPGSV,3,3,12,07,13,176,16,01,06,154,22,31,05,029,21,26,05,065,16*75
$GPRMC,155142.000,A,4913.1702,N,00822.4818,E,0.14,18.24,090919,,,A*5C
```

after the initial message `SX1276 RFIC is detected.` only lines from GPS are seen.

Best regards
Manfred

lyusupov, 2019-09-09:
There were **no** reports from numerous builders of Raspberry Edition that they had any issues with bringing it up, provided that the Dragino board and Raspberry itself are fully functional.
See #60 as an example.

Inspect your hardware and work with your seller if it is defective.

mreinart, 2019-09-09:
Dear Linar,

again thanks for the quick reply.
Effectively I have 2x the same Dragino HAT and also was testing on a PI-0 - in parallel and also Hats interchanged - same behaviour.
Thus I am ruling out a basic defect of the RasPi(s) or the Draginos.
Nevertheless I will try to find in Dragino forums what might cause Lora reception issues.

Would be thankful for any hint on where in the SoftRF source I might place additional debugging to track potential issues down.

Thanks&Regards
Manfred

TexasUK, 2019-09-09:
I have exactly the same problem.

I am using a pi3 b+. To get the dragino to work required substitution of
the ttyAMA0 to ttyS0, as specified in the dragino 'how to get the board
working on a pi3' on their website.
With this change it provides the GPS sentences and works with XCSoar as a
device on the ttyS0 port, but trying to use the command '( echo
"(class:SOFTRF,protocol:LEGACY,band:EU)" ; cat /dev/ttyS0 ; ) /
sudo./SoftRF' doesn't appear to work. There are certainly no sentences
added with the SoftRF data.
(This is written on my mobile phone so some of the characters in that
command scentence aren't correct)
Hope this helps.
Daren

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

lyusupov, 2019-09-10:
Manfred,
several prerequisites must be met for the SoftRF program to start emitting $PFLAx messages.

If I would have the situation like you do, I would:

1) enable SoftRF 'private' messages:

```
pi@raspberrypi:/run/tmp/SoftRF/SoftRF $ { echo "{class:SOFTRF,nmea:{private:true}}" ; cat /dev/ttyAMA0 ; } | sudo ./SoftRF
SX1276 RFIC is detected.
$GPRMC,093352.073,A,XXXX.XXXX,N,0XXXX.v,E,000.0,237.3,250100,,,A*6D
$GPVTG,237.3,T,,M,000.0,N,000.0,K,A*08
$GPGGA,093353.073,XXXX.XXXX,N,0XXXX.XXXX,E,1,06,2.4,166.3,M,13.1,M,,0000*5C
$PSRFO,948792832,01017F0BF6E71BFB5886D9513345116DE7CC1FBC
$GPGSA,A,3,27,16,08,10,32,18,,,,,,,3.1,2.4,1.9*3D
$GPGSV,3,1,12,10,75,178,43,27,65,235,48,20,64,083,,04,55,205,42*72
$GPGSV,3,2,12,08,42,299,41,21,37,106,12,15,23,046,,32,14,165,32*71
$PSRFI,948792832,04D8C503B18300F12804FC2B071054EEF0D44433,0
$GPGSV,3,3,12,18,13,282,35,16,11,220,34,24,02,083,,11,01,298,*72
$GPRMC,093353.073,A,XXXX.XXXX,N,0XXXX.XXXX,E,000.0,237.3,250100,,,A*6C
$PFLAA,3,-19,-23,17,3,C5D804!OGN_C5D804,341,,0,00000.0,1*58
$PFLAU,1,1,2,1,3,-129,2,17,30*72
```

where each:
* **$PSRFI** message indicates data packet been received from SX1276 radio ,
* **$PSRFO** message indicates data packet been sent to SX1276 radio

2) then I would use an SDR  receiver with SDRSharp or similar software from aside to monitor frequency, spectrum and quality of transmitted frames
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
lyusupov, 2019-09-10:
SoftRF in 'normal' (default) mode generates :
* $PFLAU  on every second and
* $PSRFO on every \<RF Tx interval\> second(s)

\- but this is valid only when **SoftRF's internal NMEA/JSON parser has got a GNSS fix**.

Your GGA and RMC sentences are looking Ok for my eyes, but I suspect that SoftRF's parser doesn't think so.

You say that '_have recognized some gabled characters in the output stream.._.'
I suspect you have a conflicting process in your Raspberry system that competes for your GNSS input (/dev/ttyS0) with SoftRF.
Typically it is the built-in 'GPSD service'. But it can be some other application as well.

You have to provide **clean NMEA, '\<CR\>\<NL\>'-terminated  stream** to your SoftRF program input.
It will not operate properly otherwise.

lyusupov, 2019-09-10:
**Resolution**: unable to reproduce

mreinart, 2019-09-10:
Hello Linar,
not sure why you are so fast in declaring a reported issue close ;-).
Reproduced on
- freshly installed RaspPi Zero with Dragino LoRa/GPS hat
- freshly downloaded and compiled SoftRF sources

Will analyze tty output and NMEA parser behaviour more deeply.

Raw NMEA output from GPS:
```
$GPGLL,4913.1693,N,00822.4774,E,190042.000,A,A*5D

$GPGSA,A,3,05,30,07,09,13,02,,,,,,,2.74,1.92,1.95*0C

$GPGSV,2,1,08,30,74,177,43,07,62,068,30,05,56,292,34,09,30,090,24*77

$GPGSV,2,2,08,13,26,273,24,02,22,240,24,28,11,157,,06,03,198,*79

$GPRMC,190042.000,A,4913.1693,N,00822.4774,E,0.23,101.89,100919,,,A*6A

$GPVTG,101.89,T,,M,0.23,N,0.42,K,A*3B

$GPGGA,190043.000,4913.1693,N,00822.4775,E,1,6,1.92,124.0,M,47.9,M,,*59

$GPGLL,4913.1693,N,00822.4775,E,190043.000,A,A*5D

$GPGSA,A,3,05,30,07,09,13,02,,,,,,,2.74,1.92,1.95*0C
```
Could well be line endings are just `<LF>`s (`0x0a`) as we are on a IX platform.

Best regards
Manfred

mreinart, 2019-09-10:
Hello Linar and other participants,

digged a bit deeper and just want to communicate the solution to the question on my Raspis
In the fresh installed setup the tty GPS output contains bare Unix `\n` line endings with empty lines inbetween - meaning double `\n` (\n\n).
By placing corresponding `sed` command to generate the `<CR><LF>` (`\r\n`) sequences expected prior to piping the stream to SoftRF the desired result is achieved.

Many thanks again for swift replies.
Manfred

```
{ echo "{class:SOFTRF,protocol:FANET,band:EU,nmea:{private:true}}" ; sudo cat /dev/ttyS0 ; }  | sed "s/\$/$CR/" | sudo ./SoftRF
SX1276 RFIC is detected.
$GPGGA,192231.000,4913.1734,N,00822.4854,E,1,7,1.46,111.8,M,47.9,M,,*5A
...
$PSRFO,946668151,4107010126004691F4056FC001000300
$PFLAU,0,1,2,1,0,0,2,0,2147483647*68
$GPVTG,4.95,T,,M,0.20,N,0.36,K,A*32
$GPGGA,192232.000,4913.1734,N,00822.4854,E,1,7,1.46,111.8,M,47.9,M,,*59
...
$GPGSV,3,2,09,09,22,096,21,28,20,153,28,02,15,233,17,27,03,037,*71
$PSRFI,946668151,41071CB52E004688F40561B00300E000,-32
$PFLAA,3,8,-13,-14,3,07B51C!FAN_07B51C,315,,0,00000.0,11*57
$PFLAU,1,1,2,1,3,-58,2,-14,16*6F
$PFLAA,3,8,-13,-14,3,07B51C!FAN_07B51C,315,,0,00000.0,11*57
$PFLAU,1,1,2,1,3,-58,2,-14,16*6F
$PSRFO,946668153,4107010127004691F4056FC001000300
$PFLAA,3,8,-13,-14,3,07B51C!FAN_07B51C,315,,0,00000.0,11*57
$PFLAU,1,1,2,1,3,-58,2,-14,16*6F
```

lyusupov, 2019-09-11:
'sed' ???

Manfred,
your TTY device settings are not appropriate.

These are known good **defaults**:

```
pi@raspberrypi:/run/tmp/SoftRF/SoftRF $ stty -F /dev/ttyAMA0
speed 9600 baud; line = 0;
intr = <undef>; quit = <undef>; erase = <undef>; kill = <undef>; eof = <undef>; start = <undef>; stop = <undef>; susp = <undef>; rprnt = <undef>;
werase = <undef>; lnext = <undef>; discard = <undef>; min = 1; time = 5;
ignbrk -brkint -icrnl -imaxbel
-opost -onlcr
-isig -icanon -iexten -echo -echoe -echok -echoctl -echoke
```

mreinart, 2019-09-11:
Dear Linar,
of course you are right.
Using `sed` inbetween is/was just a quick way of massaging the NMEA stream which just differs in line separators to the expectations of the NMEA parser.
In a RasPi-Installation the problem should be fixed at the source, of course.
Thanks again
Manfred

lyusupov, 2019-09-11:
&nbsp;&nbsp;&nbsp;&nbsp;Manfred,

I've spent my own time to process your request. And it that was not a **bug** of SoftRF or it's documentation.
I believe that it is fair enough that I would expect to take your time as a compensation.

This is the list of [CONTRIBUTIONS](https://github.com/lyusupov/SoftRF/blob/master/CONTRIBUTING.md) wanted.
It would be nice if you could spend your time on 2.3 and 1.2

&nbsp;&nbsp;&nbsp;&nbsp;Regards,
&nbsp;&nbsp;&nbsp;&nbsp;Linar.

mreinart, 2019-09-11:
Dear LInra,
fair enough - will invest time in these areas.
Thanks again
Manfred

Closed 2019-09-10.

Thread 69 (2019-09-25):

EEPROM magic mismatch!

zodiac-maniac, 2019-09-25:
## Hardware

- [x]   Prime Mark II
- [x]   Standalone
- [ ]   UAV
- [ ]   Raspberry Edition
- [ ]   UAT module
- [ ]   SkyView
- [ ]   Flight Recorder

< photo of your hardware > (**required**)

## Firmware version
softRF Firmware v1.0 RC6+
<  screenshot of WebUI status page > (**required**)
Impossible
## Firmware settings
nothing special
<  screenshot of WebUI settings page > (**required**)
Impossible
## Describe the bug (or ask a question)
The t-beam Version 20190612 creates a WiFi spot.
It is possible to connect to softRF WiFi but the 192.168.1.1 is not working. Seems that a Gateway/Server does not work.
The difference to other t-beams is the magic mismatch report and I guess thats why softRF does not run. Is it possible to "repair" the eeprom?
When powering up the t-beam by USB Power and reading the serial port with serial port utility it says:
Reset reason: 0

POWERON_RESET

Free heap size: 202160

Vbat power on reset

Warning! EEPROM magic mismatch! Loading defaults...

SX1276 RFIC is detected.

WARNING! Barometric pressure sensor is NOT detected.

INFO: TTGO T-Beam GPS module (rev. 08) is detected.

Flash memory ID: EF4016

INFO: GNSS module HW version: 00040007

INFO: GNSS module FW version: 7.03 (45969)

Hostname: SoftRF-d44404

Wait for WiFi connection.

....................

Can not connect to WiFi station. Go into AP mode.

Setting soft-AP configuration ... Ready

Setting soft-AP ... Ready

IP address: 192.168.1.1

UDP server has started at port: 12389

HTTP server has started at port: 80

After that it shows the data of the GPS Module.
## To Reproduce

## Expected behavior
Normal softRF behavior...

lyusupov, 2019-09-25:
There is **NO EEPROM** in ESP32.
It is emulated by SPI flash memory area (address and size are specified in partition table)

EEPROM magic mismatch! Loading defaults.. - **is just a warning** .
It indicates that flash memory area assigned for EEPROM emulation is not initialized yet.
It is Ok because factory (or user) pre-installed firmware does not contain definitions for this memory region.

It will become initialized normally when a user will make very first 'Save and restart' operation in 'Settings' menu.

Closed 2019-09-25.

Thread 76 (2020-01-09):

SoftRF show its own deviceID as traffic

8lazo8, 2020-01-09:
## Hardware

- [ ]   Standalone
- [x]   Prime Mark II
- [ ]   Dongle
- [ ]   SkyView EZ
- [ ]   Raspberry Edition
- [ ]   UAV
- [ ]   UAT978 module
- [ ]   Flight Recorder

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

## Firmware version

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

## Firmware settings

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

## Describe the bug (or ask a question)

I am a new SoftRF user, today I went out for a test on the ground.
Next week I plan to make an in flight test.

When the Prime MKII is near to an aircraft - 2-300 meters or closer - equiped with OGN tracker periodically it seems to "receive" its own tracker ID as foreign tracker and it is listed as traffic in the Skyview and in xcsoar as well.  The phenomenon is intermittent.
It tested this with two different aircrafts.

After the aircrafts departured the "self reflection" disappeared only the real aircraft was seen on the screen.

## To Reproduce

Te be close to an OGN tracker equipped aircraft, maximum 2-300 meters.

## Expected behavior

To receive/display only the foreign aircraft deviceID but not itself.

Ben64Smith, 2020-01-09:
From memory I think paweł added rebroadcast functionality in the later versions of the OGN tracker, this is probably the cause of your issue.

8lazo8, 2020-01-09:
>
>
> From memory I think paweł added rebroadcast functionality in the later versions of the OGN tracker, this is probably the cause of your issue.

This means that the foreign aircraft rebroadcasted my deviceID?  I am pretty sure it was not SoftRF device inside.

Does this rebroadcast function has anything to do to proximity of the trackers? So its not active on larger distances? I mean I should have to receive it all the time. And it also would cause alerts.
Or in this case the self deviceID should be filtered?

lyusupov, 2020-01-09:
@Ben64Smith
Correct. I also expect that this likely happens due to re-broadcast feature of OGN tracker.
I don't remember if I have seen this with my build of STM32 OGN tracker on a breadboard.
It probably depends on particular revision of OGN firmware, settings and certain conditions to be met.

@8lazo8
Could you connect your Prime Mk2 to a PC and **capture a NMEA log on 38400,8*N1** ?
If the is a 'ghosting traffic' - we will likely see it in a PFLAA sentence.

8lazo8, 2020-01-09:
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

Yes I can do that. You need the capture when "ghosting" can be seen on the screen?

I have two Mk2-s but between them this never happened. To reproduce the phenomenon I will need to go for another field trip.
I will capture the log ASAP whichever is needed.

lyusupov, 2020-01-09:
No rush. Take it when able. ZIP , then drag and drop here.

> You need the capture when "ghosting" can be seen on the screen?

Yes.

8lazo8, 2020-01-11:
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

Hi,
Today I managed to collect logs.  After all I could not take it from the serial but I hope xcsoar NMEA dump will be good as well.
There were lots of "ghostings".
[2020-01-11_10-53.zip](https://github.com/lyusupov/SoftRF/files/4049437/2020-01-11_10-53.zip)

lyusupov, 2020-01-11:
Thanks!

I've committed https://github.com/lyusupov/SoftRF/commit/b0ddbac7e7af06a9929581df677d2e3aefa4477a and https://github.com/lyusupov/SoftRF/commit/6e4e9bb6ee95fe397c8b22baf141dc555ef2e9b2

[Build](https://github.com/lyusupov/SoftRF/tree/master/software/firmware/source#esp32) and update your **Prime MkII**(s).

Those 2 commits above should fix this issue. Please, test and confirm.

8lazo8, 2020-01-11:
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

Update has been done, will test it soon.

8lazo8, 2020-01-17:
There is IMC in the area since a week, hopefully next week it will good enough for a test.

lyusupov, 2020-01-27:
**Resolution:** fixed in https://github.com/lyusupov/SoftRF/commit/b0ddbac7e7af06a9929581df677d2e3aefa4477a and https://github.com/lyusupov/SoftRF/commit/6e4e9bb6ee95fe397c8b22baf141dc555ef2e9b2

Closed 2020-01-27.

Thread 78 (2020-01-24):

Retro STM32F1 compile error - region `FLASH' overflowed by 268 bytes

ezfox, 2020-01-24:
While following https://github.com/lyusupov/SoftRF/wiki/Retro-Edition#firmware to the letter,
to compile the Retro version for BluePill with Arduino IDE 1.8.10, i get following warning & error:

Arduino: 1.8.10 (Linux), Board: "Generic STM32F1 series, BluePill F103C8 (128k), STM32CubeProgrammer (SWD), Enabled (generic 'Serial'), CDC (no generic 'Serial'), Low/Full Speed, Smallest (-Os default), Newlib Nano (default)"

**WARNING: library nRF905 claims to run on avr, esp8266, esp32 architecture(s) and may be incompatible with your current board which runs on stm32 architecture(s).**
Multiple libraries were found for "WiFiUdp.h"
 Used: /home/user/Apps/arduino-1.8.10/libraries/WiFi
Multiple libraries were found for "SrcWrapper.h"
 Used: /home/user/.arduino15/packages/STM32/hardware/stm32/1.8.0/libraries/SrcWrapper
Multiple libraries were found for "TimeLib.h"
 Used: /home/user/Arduino/libraries/Time
Multiple libraries were found for "EEPROM.h"
 Used: /home/user/.arduino15/packages/STM32/hardware/stm32/1.8.0/libraries/EEPROM
Multiple libraries were found for "Adafruit_NeoPixel.h"
 Used: /home/user/Arduino/libraries/Adafruit_NeoPixel
Multiple libraries were found for "lib_crc.h"
 Used: /home/user/Arduino/libraries/CRC
Multiple libraries were found for "uat.h"
 Used: /home/user/Arduino/libraries/dump978
Multiple libraries were found for "aircraft.h"
 Used: /home/user/Arduino/libraries/aircraft
Multiple libraries were found for "Wire.h"
**/home/user/.arduino15/packages/STM32/tools/xpack-arm-none-eabi-gcc/9.2.1-1.1/bin/../lib/gcc/arm-none-eabi/9.2.1/../../../../arm-none-eabi/bin/ld: Retro.ino.elf section `.data' will not fit in region `FLASH'
/home/user/.arduino15/packages/STM32/tools/xpack-arm-none-eabi-gcc/9.2.1-1.1/bin/../lib/gcc/arm-none-eabi/9.2.1/../../../../arm-none-eabi/bin/ld: region `FLASH' overflowed by 268 bytes
collect2: error: ld returned 1 exit status**
 Used: /home/user/.arduino15/packages/STM32/hardware/stm32/1.8.0/libraries/Wire
Multiple libraries were found for "Adafruit_MPL3115A2.h"
 Used: /home/user/Arduino/libraries/Adafruit_MPL3115A2_Library
Multiple libraries were found for "TinyGPS++.h"
 Used: /home/user/Arduino/libraries/TinyGPSPlus
Multiple libraries were found for "ArduinoJson.h"
 Used: /home/user/Arduino/libraries/ArduinoJson
Multiple libraries were found for "IWatchdog.h"
 Used: /home/user/.arduino15/packages/STM32/hardware/stm32/1.8.0/libraries/IWatchdog
Multiple libraries were found for "adsb_encoder.h"
 Used: /home/user/Arduino/libraries/adsb_encoder
Multiple libraries were found for "lmic.h"
 Used: /home/user/Arduino/libraries/arduino-lmic
Multiple libraries were found for "mavlink.h"
 Used: /home/user/Arduino/libraries/mavlink
Multiple libraries were found for "Adafruit_BMP085.h"
 Used: /home/user/Arduino/libraries/Adafruit-BMP085-Library
Multiple libraries were found for "Adafruit_BMP280.h"
 Used: /home/user/Arduino/libraries/Adafruit_BMP280_Library
Multiple libraries were found for "SPI.h"
 Used: /home/user/.arduino15/packages/STM32/hardware/stm32/1.8.0/libraries/SPI
Multiple libraries were found for "nRF905.h"
 Used: /home/user/Arduino/libraries/nRF905
Multiple libraries were found for "egm96s.h"
 Used: /home/user/Arduino/libraries/Geoid
Multiple libraries were found for "U8x8lib.h"
 Used: /home/user/Arduino/libraries/U8g2
Multiple libraries were found for "freqplan.h"
 Used: /home/user/Arduino/libraries/OGN
**exit status 1
Error compiling for board Generic STM32F1 series.**

The more verbose output i attached here as a text file:
[verbose.txt](https://github.com/lyusupov/SoftRF/files/4108800/verbose.txt)

lyusupov, 2020-01-24:
Report is filed not in compliance with the [template](https://github.com/lyusupov/SoftRF/blob/master/.github/ISSUE_TEMPLATE/softrf-issue-template.md).

**Resolution**: invalid.

Closed 2020-01-24.

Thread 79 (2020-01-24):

Retro STM32F1 compile error - region `FLASH' overflowed by 268 bytes

ezfox, 2020-01-24:
**ATTENTION** !

- Use this form to report bugs in released SoftRF firmware, hardware and web pages only ;
- Issue reports from anonymous users will be most likely invalidated. Reasons for that are well explained [here](https://berthub.eu/articles/posts/anonymous-help/) ;
- Prior to asking a question, look into ["Closed issues"](https://github.com/lyusupov/SoftRF/issues?q=is%3Aissue+is%3Aclosed) area to see if it was answered before ;
- No any "ideas" or new feature requests, please ! New feature requests do not subject for taking into consideration unless they come from co-developers ;
- "Enhancements" of existing features are allowed only when you are ready to implement them by yourself ;

Recommended:
- screenshot or photo width - from 600 to 800 pixels ;
- aspect ratio - 4:3, 3:4, 16:9 or 9:16.
- substitute 'space' by 'x' character to mark a hardware checkbox

--------------------

## Hardware

- [ ]   Standalone
- [ ]   Prime Mark II
- [ ]   Dongle
- [ ]   SkyView EZ
- [ ]   Raspberry Edition
- [ ]   UAV
- [ ]   UAT978 module
- [ ]   Flight Recorder
- [X] Retro (STM32F103C8T6 & RFM95W)

< photo of your hardware > (**required**)
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

## Firmware version
STM32 1.8.0
(https://github.com/stm32duino/Arduino_Core_STM32/releases/tag/1.8.0)

<  screenshot of WebUI status page > (**required**)
N/A (Compile Fails, so no WebUI available)

## Firmware settings
N/A

<  screenshot of WebUI settings page > (**required**)
N/A (Compile Fails, so no WebUI available)

## Describe the bug (or ask a question)
While following https://github.com/lyusupov/SoftRF/wiki/Retro-Edition#firmware to the letter,
to compile the Retro version for BluePill with Arduino IDE 1.8.10, i get following warning & error:

Arduino: 1.8.10 (Linux), Board: "Generic STM32F1 series, BluePill F103C8 (128k), STM32CubeProgrammer (SWD), Enabled (generic 'Serial'), CDC (no generic 'Serial'), Low/Full Speed, Smallest (-Os default), Newlib Nano (default)"

**WARNING: library nRF905 claims to run on avr, esp8266, esp32 architecture(s) and may be incompatible with your current board which runs on stm32 architecture(s).**
Multiple libraries were found for "WiFiUdp.h"
 Used: /home/user/Apps/arduino-1.8.10/libraries/WiFi
Multiple libraries were found for "SrcWrapper.h"
 Used: /home/user/.arduino15/packages/STM32/hardware/stm32/1.8.0/libraries/SrcWrapper
Multiple libraries were found for "TimeLib.h"
 Used: /home/user/Arduino/libraries/Time
Multiple libraries were found for "EEPROM.h"
 Used: /home/user/.arduino15/packages/STM32/hardware/stm32/1.8.0/libraries/EEPROM
Multiple libraries were found for "Adafruit_NeoPixel.h"
 Used: /home/user/Arduino/libraries/Adafruit_NeoPixel
Multiple libraries were found for "lib_crc.h"
 Used: /home/user/Arduino/libraries/CRC
Multiple libraries were found for "uat.h"
 Used: /home/user/Arduino/libraries/dump978
Multiple libraries were found for "aircraft.h"
 Used: /home/user/Arduino/libraries/aircraft
Multiple libraries were found for "Wire.h"
**/home/user/.arduino15/packages/STM32/tools/xpack-arm-none-eabi-gcc/9.2.1-1.1/bin/../lib/gcc/arm-none-eabi/9.2.1/../../../../arm-none-eabi/bin/ld: Retro.ino.elf section `.data' will not fit in region `FLASH'
/home/user/.arduino15/packages/STM32/tools/xpack-arm-none-eabi-gcc/9.2.1-1.1/bin/../lib/gcc/arm-none-eabi/9.2.1/../../../../arm-none-eabi/bin/ld: region `FLASH' overflowed by 268 bytes
collect2: error: ld returned 1 exit status**
 Used: /home/user/.arduino15/packages/STM32/hardware/stm32/1.8.0/libraries/Wire
Multiple libraries were found for "Adafruit_MPL3115A2.h"
 Used: /home/user/Arduino/libraries/Adafruit_MPL3115A2_Library
Multiple libraries were found for "TinyGPS++.h"
 Used: /home/user/Arduino/libraries/TinyGPSPlus
Multiple libraries were found for "ArduinoJson.h"
 Used: /home/user/Arduino/libraries/ArduinoJson
Multiple libraries were found for "IWatchdog.h"
 Used: /home/user/.arduino15/packages/STM32/hardware/stm32/1.8.0/libraries/IWatchdog
Multiple libraries were found for "adsb_encoder.h"
 Used: /home/user/Arduino/libraries/adsb_encoder
Multiple libraries were found for "lmic.h"
 Used: /home/user/Arduino/libraries/arduino-lmic
Multiple libraries were found for "mavlink.h"
 Used: /home/user/Arduino/libraries/mavlink
Multiple libraries were found for "Adafruit_BMP085.h"
 Used: /home/user/Arduino/libraries/Adafruit-BMP085-Library
Multiple libraries were found for "Adafruit_BMP280.h"
 Used: /home/user/Arduino/libraries/Adafruit_BMP280_Library
Multiple libraries were found for "SPI.h"
 Used: /home/user/.arduino15/packages/STM32/hardware/stm32/1.8.0/libraries/SPI
Multiple libraries were found for "nRF905.h"
 Used: /home/user/Arduino/libraries/nRF905
Multiple libraries were found for "egm96s.h"
 Used: /home/user/Arduino/libraries/Geoid
Multiple libraries were found for "U8x8lib.h"
 Used: /home/user/Arduino/libraries/U8g2
Multiple libraries were found for "freqplan.h"
 Used: /home/user/Arduino/libraries/OGN
**exit status 1
Error compiling for board Generic STM32F1 series.**

The more verbose output i attached here as a text file:
[verbose.txt](https://github.com/lyusupov/SoftRF/files/4109510/verbose.txt)

## To Reproduce
- Follow the Guide from https://github.com/lyusupov/SoftRF/tree/master/software/firmware/source#stm32
- Watch compile process failing with above error

## Expected behavior
- Compile should finish sucessfully

lyusupov, 2020-01-24:
Your report is generally not applicable, because:
1) issues has to be filed against [**released SoftRF firmware** source code](https://github.com/lyusupov/SoftRF/releases/tag/1.0-rc7).
RC7 is known to be fine when built against AC/STM32 [1.7.0](https://github.com/stm32duino/Arduino_Core_STM32/releases/tag/1.7.0)
2) **I no longer process issues that comes from anonymous GitHub users**:
https://berthub.eu/articles/posts/anonymous-help/

Build of **development version** of source code is not guaranteed at any particular time, see this: https://github.com/lyusupov/SoftRF/issues/29#issuecomment-419092549

So, to save some flash memory space, either:
- build RC7 against AC 1.7.0 (or 1.6.1) , and/or
- disable USB CDC in Arduino build options, and/or
- disable pressure sensor that you don't have. Example: https://github.com/lyusupov/SoftRF/blob/master/software/firmware/source/SoftRF/Platform_STM32.h#L222

**Resolution:** invalid

Closed 2020-01-24.

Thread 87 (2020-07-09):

Prime Mark II,  1.0-rc8 , GNSS not detected when OLED attached

bluefix, 2020-07-09:
--------------------

## Hardware

- [ ]   Standalone
- [x]   Prime Mark II
- [ ]   Dongle
- [ ]   SkyView EZ
- [ ]   Raspberry Edition
- [ ]   UAV
- [ ]   UAT978 module
- [ ]   Flight Recorder

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

## Firmware version
SoftRF-ESP32 FW.REV: 1.0-rc8

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

## PROBLEM

**when OLED (21, 22) is attached, GNSS is not detected during boot**

**power button cannot suspend or shut down**

**no change if BMP280 (pins 2, 13) is attached, or not**

**without OLED boot is successful and device is sending proper legacy packages.**

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

## boot log with OLED and BMP280

SoftRF-ESP32 FW.REV: 1.0-rc8 DEV.ID: b582f404
Copyright (C) 2015-2020 Linar Yusupov. All rights reserved.

Reset reason: 0
POWERON_RESET
Free heap size: 210784
Vbat power on reset

EEPROM version: 94
SX1276 RFIC is detected.
BMP280 barometric pressure sensor is detected.
Temperature = 25.58 *C
Pressure = 100387.64 Pa
Approx altitude = 78.34 m

INFO: TTGO T-Beam rev. 016 is detected.
Flash memory ID: 684016
Hostname: SoftRF-82f404
Wait for WiFi connection.
....................
Can not connect to WiFi station. Go into AP mode.
Setting soft-AP configuration ... Ready
Setting soft-AP ... Ready
IP address: 192.168.1.1
UDP server has started at port: 12389
HTTP server has started at port: 80
$PFLAU,0,0,0,1,0,,0,,,*4F
$PGRMZ,256,f,3*1A
$PFLAU,0,0,0,1,0,,0,,,*4F
$PGRMZ,255,f,3*19
$PFLAU,0,0,0,1,0,,0,,,*4F
$PGRMZ,255,f,3*19
$PFLAU,0,0,0,1,0,,0,,,*4F
$PGRMZ,256,f,3*1A
$PFLAU,0,0,0,1,0,,0,,,*4F
$PGRMZ,255,f,3*19
$PFLAU,0,0,0,1,0,,0,,,*4F
$PGRMZ,255,f,3*19
$PFLAU,0,0,0,1,0,,0,,,*4F
$PGRMZ,256,f,3*1A
$PGRMZ,254,f,3*18
$PFLAU,0,0,0,1,0,,0,,,*4

## boot log with BMP280 only

SoftRF-ESP32 FW.REV: 1.0-rc8 DEV.ID: b582f404
Copyright (C) 2015-2020 Linar Yusupov. All rights reserved.

Reset reason: 0
POWERON_RESET
Free heap size: 210784
Vbat power on reset

EEPROM version: 94
SX1276 RFIC is detected.
BMP280 barometric pressure sensor is detected.
Temperature = 25.97 *C
Pressure = 100382.73 Pa
Approx altitude = 78.75 m

INFO: TTGO T-Beam rev. 08 is detected.
Flash memory ID: 684016
INFO: GNSS module HW version: 00040007
INFO: GNSS module FW version: 7.03 (45969)
Hostname: SoftRF-82f404
Wait for WiFi connection.
....................
Can not connect to WiFi station. Go into AP mode.
Setting soft-AP configuration ... Ready
Setting soft-AP ... Ready
IP address: 192.168.1.1
UDP server has started at port: 12389
HTTP server has started at port: 80
$GPRMC,142858.00,A,5230.38022,N,01314.25021,E,2.366,,090720,,,A*73
$GPGGA,142858.00,5230.38022,N,01314.25021,E,1,06,2.06,72.2,M,42.4,M,,*65
$GPGSA,A,3,11,08,32,10,22,27,,,,,,,3.86,2.06,3.27*00
$PFLAU,0,1,2,1,0,,0,,,*4C
$PGRMZ,257,f,3*1B
$GPRMC,142910.00,A,5230.37194,N,01314.25861,E,1.083,,090720,,,A*7A
$GPGGA,142910.00,5230.37194,N,01314.25861,E,1,06,1.66,72.5,M,42.4,M,,*65
$GPGSA,A,3,11,08,32,10,22,27,,,,,,,3.35,1.66,2.90*00
$GPRMC,142911.00,A,5230.37097,N,01314.25885,E,1.460,,090720,,,A*7A
$PFLAU,0,1,2,1,0,,0,,,*4C
$PGRMZ,257,f,3*1B

lyusupov, 2020-07-09:
> INFO: TTGO T-Beam rev. 016 is detected.

There is **NO** such thing as T-Beam rev 16, but there **IS** TTGO LoRa that has rev 16.

Your board is misdetected so incorrect GNSS Rx/Tx pins have been selected.

The reason for that is likely that you've eneterd SLEEP mode proir to this boot.
NEVER user SLEEP when OLED is connected - **'Noname' OLED has known hardware issue that it blocks I2C bus access when switched into 'power save' mode**.

T-Beam V10 does not function properly when access to AXP192 over I2C is blocked.
And we see this happened in your log.

**Solution**: NEVER use SLEEP mode with your Prime Mk2 with OLED. Use full POWER OFF instead.
Be patient to keep holding power button AT LEAST 7 SECONDS to execute 'power off' sequence.

lyusupov, 2020-07-09:
**Known issues** section of [**Release notes**](https://github.com/lyusupov/SoftRF/releases/tag/1.0-rc8) has been updated.

**Resolution**: deferred

lyusupov, 2020-07-09:
And one more notice for you to concern:

Neither BMP280 nor OLED are offically supported components of [**Prime Mk II**](https://github.com/lyusupov/SoftRF/wiki/Prime-Edition-MkII).
 I<sup>2</sup>C bus feature is a 'privilege' of [**Standalone Edition**](https://github.com/lyusupov/SoftRF/wiki/Standalone-Edition) & [**LoRa**](https://github.com/lyusupov/SoftRF/wiki/SoftRF-LoRa-module) builders.

So filing of an  I<sup>2</sup>C device issue onto a **Prime Mk II** is not allowed here.

Closed 2020-08-02.

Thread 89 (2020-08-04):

SoftRF show its own deviceID as traffic - this time Legacy protocol

BeenThereScrewedUp, 2020-08-04:
## Hardware

- [ ]   Standalone
- [x]   Prime Mark II
- [ ]   Dongle
- [ ]   SkyView EZ
- [ ]   Raspberry Edition
- [ ]   UAV
- [ ]   UAT978 module
- [ ]   Flight Recorder

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

## Firmware version

Firmware SoftRF-firmware-v1.0-rc8-ESP32 after critical fix is used.

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

## Firmware settings

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

## Describe the bug (or ask a question)

During flight and on the ground, the unit picks up its own device ID as traffic. This happened without the unsupported TTGO OLED display as well.
I have no idea how the device can pick up its own radio transmission - i got this behaviour at 5000' AGL as well as during approaches and on the ground. If it picks up its own ID this continues for a minute or two and the stops for some time. Inside my office this does not occur. I even got a warning with the device sitting on my porch (lat/long substituted by 1234) - see serial log below:

SoftRF-ESP32 FW.REV: 1.0-rc8 DEV.ID: b224821c
Copyright (C) 2015-2020 Linar Yusupov. All rights reserved.

Reset reason: 0
POWERON_RESET
Free heap size: 210596
Vbat power on reset

EEPROM version: 94
SX1276 RFIC is detected.
WARNING! Barometric pressure sensor is NOT detected.
INFO: TTGO T-Beam rev. 08 is detected.
Flash memory ID: 684016
INFO: GNSS module HW version: 00040007
INFO: GNSS module FW version: 7.03 (45969)
Hostname: SoftRF-24821c
Wait for WiFi connection.
....................
Can not connect to WiFi station. Go into AP mode.
Setting soft-AP configuration ... Ready
Setting soft-AP ... Ready
IP address: 192.168.1.1
UDP server has started at port: 12389
HTTP server has started at port: 80
...
$GPRMC,132506.00,A,1234.93358,N,01234.80473,E,0.121,,040820,,,A*7F
$GPGGA,132506.00,1234.93358,N,01234.80473,E,1,09,1.07,0.9,M,45.7,M,,*5F
$GPGSA,A,3,11,01,22,32,08,03,28,21,27,,,,1.70,1.07,1.32*05
$PFLAU,0,1,2,1,0,,0,,,*4C
$GPRMC,132507.00,A,1234.93362,N,01234.80473,E,0.217,,040820,,,A*71
$GPGGA,132507.00,1234.93362,N,01234.80473,E,1,09,1.07,0.8,M,45.7,M,,*56
$GPGSA,A,3,11,01,22,32,08,03,28,21,27,,,,1.70,1.07,1.32*05
$PFLAA,3,0,0,0,2,24821C!FLR_24821C,0,,0,0.0,8*77
$PFLAU,1,1,2,1,3,-122,2,0,0,24821C*2E
$GPRMC,132508.00,A,1234.93369,N,01234.80472,E,0.267,,040820,,,A*73
$GPGGA,132508.00,1234.93369,N,01234.80472,E,1,09,1.07,0.8,M,45.7,M,,*53
$GPGSA,A,3,11,01,22,32,08,03,28,21,27,,,,1.70,1.07,1.32*05
$PFLAA,3,0,0,0,2,24821C!FLR_24821C,0,,0,0.0,8*77
$PFLAU,1,1,2,1,3,-122,2,0,0,24821C*2E
$GPRMC,132509.00,A,1234.93379,N,01234.80481,E,0.504,,040820,,,A*7D
$GPGGA,132509.00,1234.93379,N,01234.80481,E,1,09,1.07,0.7,M,45.7,M,,*50
$GPGSA,A,3,11,01,22,32,08,03,28,21,27,,,,1.70,1.07,1.32*05
$PFLAA,3,0,0,0,2,24821C!FLR_24821C,0,,0,0.0,8*77
...

## To Reproduce

For me - just use the device outside or in the aircraft.

## Expected behavior

The device ID should be filtered out just like in closed issue #76 were the handling was fixed in Protocol_OGNTP.cpp

JEK58, 2020-08-04:
I had the same problem a few times but could not reproduce it.

lyusupov, 2020-08-04:
Report from anonymous user.

**Resolution**: invalid

BeenThereScrewedUp, 2020-08-04:
You can close it - but the error persists. Too bad for all the other users.  I will fix it myself.

Closed 2020-08-04.

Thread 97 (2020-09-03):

BME280 connected to pins 21/22 block AXP192 chip communication

OskarPepryk, 2020-09-03:
## Hardware

- [ ]   Standalone
- [x]   Prime Mark II
- [ ]   Dongle
- [ ]   SkyView EZ
- [ ]   Raspberry Edition
- [ ]   UAV
- [ ]   UAT978 module
- [ ]   Flight Recorder

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

## Firmware version

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

## Firmware settings

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

## Describe the bug (or ask a question)

When I connect the BME280 to pins 21/22 it is detected correctly but there is no voltage (0 volts) in status page and the device is impossible to shutdown using the soft power button.

## To Reproduce

Connect BME280 to gpio 21/22. Turn on the device. Note the incorrect voltage and that you can't turn the board off no matter how long you press the power button.

## Expected behavior

The AXP192 should continue to work. I know that the baros aren't 'officially' supported but this seems like an oversight.

## Proposed solution

I worked out the solution. During ESP32 baro setup routine Wire was called with pins 21/22. It collides with Wire1 already running on those pins and breaks any devices (AXP192) that worked with Wire1.

I fixed this issue in [my fork ](https://github.com/OskarPepryk/SoftRF/tree/bmp280_fix) by changing BMP280 library to a newer one that supports custom Wire addresses but works with either BMP280 or BME280. I went with BME280 because that's my sensor. Unfortunately I cannot test the issue with other barometric sensors. Probably all of them need a library that can be called with Wire1.

lyusupov, 2020-09-03:
Show me a sentence in [**Prime Mark II**](https://github.com/lyusupov/SoftRF/wiki/Prime-Edition-MkII) description or BOM where it is written that it has support for BME280 sensor.

Neither barometric pressure sensor nor OLED are offically supported components of [**Prime Mk II**](https://github.com/lyusupov/SoftRF/wiki/Prime-Edition-MkII).
Utilizing of I<sup>2</sup>C bus feature is a 'privilege' of [**Standalone Edition**](https://github.com/lyusupov/SoftRF/wiki/Standalone-Edition) & [**LoRa**](https://github.com/lyusupov/SoftRF/wiki/SoftRF-LoRa-module) builders.

So filing of an  I<sup>2</sup>C device issue onto the **Prime Mk II** is not allowed here.

**Resolution**: invalid

Closed 2020-09-03.

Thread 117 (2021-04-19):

Flattened battery and bricked T-Beam

freedomfpv, 2021-04-19:
## Hardware

- [ ]   Standalone
- [x]   Prime Mark II
- [ ]   Uni
- [ ]   Dongle
- [ ]   Mini
- [ ]   SkyView EZ
- [ ]   Raspberry Edition
- [ ]   UAV
- [ ]   UAT978 module
- [ ]   Flight Recorder

< photo of your hardware > (**required**)
Unable, as has been thrown away

## Firmware version
RC-9
<  screenshot of WebUI status page > (**required*)

## Firmware settings
Unable, as has been thrown away
<  screenshot of WebUI settings page > (**required**)

## Describe the bug
TTGO T-Beam V1.1 was accidentally left switched on for about a day, this brought the battery voltage down to 1 volt, and bricked the T-Beam. It was still recognised when plugged into a computer, but no lights came on when plugged in or a charged battery was inserted. It also did not emit a WiFi signal.

## To Reproduce
Leave a T-Beam v1.1 running on battery power with firmware version RC9

## Expected behavior
Device auto power off once a minimum voltage was reached.

lyusupov, 2021-04-19:
* incomplete issue report ;
* anonymous user ;
* [disclaimer](https://github.com/lyusupov/SoftRF/wiki/Prime-Edition-MkII#disclaimer)

**Resolution**: unable to reproduce

Closed 2021-04-19.

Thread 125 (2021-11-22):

wrong chip id 0xafd8

kolod1am, 2021-11-22:
## Hardware

- [ ]   Standalone
- [ ]   Badge
- [x]   Prime Mark II
- [ ]   Dongle
- [ ]   Bracelet
- [ ]   Uni
- [ ]   Mini
- [ ]   SkyView EZ
- [ ]   Raspberry Edition
- [ ]   UAV
- [ ]   UAT978 module
- [ ]   Flight Recorder

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

```
~/.local/bin/esptool.py --chip esp32 -p /dev/ttyUSB0 flash_id
esptool.py v3.2
Serial port /dev/ttyUSB0
Connecting....
Chip is ESP32-D0WDQ6-V3 (revision 3)
Features: WiFi, BT, Dual Core, 240MHz, VRef calibration in efuse, Coding Scheme None
Crystal is 40MHz
MAC: 24:0a:c4:f7:e8:80
Uploading stub...
Running stub...
Stub running...
Manufacturer: 68
Device: 4016
Detected flash size: 4MB
Hard resetting via RTS pin...
```

## Firmware version

SoftRF-firmware-v1.0.bin

## Firmware settings

Does not apply.

## Describe the bug

After writing SoftRF to the board, no WiFi SSID appears, no bluetooth device can be scanned. No wonder, as reading from ttyUSB0 gains:
```
rst:0x10 (RTCWDT_RTC_RESET),boot:0x13 (SPI_FAST_FLASH_BOOT)
wrong chip id 0xafd8
wrong chip id 0xafd8
wrong chip id 0xafd8
wrong chip id 0xafd8
wrong chip id 0xafd8
wrong chip id 0xafd8
wrong chip id 0xafd8
wrong ch�ets Jul 29 2019 12:21:46
```
and running.

The board came with Meshtastic. It boots and the bluetooth device appears in smartphone. So I know that the board is operational. I wonder where message "wrong chip id" comes from as I cannot find it in SoftRF source code nor in the binary.

## To Reproduce
~/.local/bin/esptool.py --chip esp32 -p /dev/ttyUSB0  write_flash 0x00000 ESP32/SoftRF-firmware-v1.0.bin

This is what esptool reported:
```
~/.local/bin/esptool.py --chip esp32 -p /dev/ttyUSB0  write_flash 0x00000 ESP32/SoftRF-firmware-v1.0.bin
flash 0x00000 ESP32/SoftRF-firmware-v1.0.bin
esptool.py v3.2
Serial port /dev/ttyUSB0
Connecting....
Chip is ESP32-D0WDQ6-V3 (revision 3)
Features: WiFi, BT, Dual Core, 240MHz, VRef calibration in efuse, Coding Scheme None
Crystal is 40MHz
MAC: 24:0a:c4:f7:e8:80
Uploading stub...
Running stub...
Stub running...
Configuring flash size...
Flash will be erased from 0x00000000 to 0x00085fff...
Compressed 548672 bytes to 394555...
Wrote 548672 bytes (394555 compressed) at 0x00000000 in 34.8 seconds (effective 126.0 kbit/s)...
Hash of data verified.
```

## Expected behavior
SoftRF boots to operational state.

lyusupov, 2021-11-22:
Reporter is trying to flash **ESP32** SoC with firmware binary been built for **ESP8266** SoC.
* [ESP32 binaries location](https://github.com/lyusupov/SoftRF/tree/master/software/firmware/binaries/ESP32/SoftRF)
* [ESP32 firmware installation instructions](https://github.com/lyusupov/SoftRF/blob/master/software/firmware/binaries/README.md#esp32)

**Resolution:** invalid

kolod1am, 2021-11-22:
Many thanks for your guidance. I have got ESP32 binary from [ESP32 binaries location](https://github.com/lyusupov/SoftRF/tree/master/software/firmware/binaries/ESP32/SoftRF), unzipped the archive and did separate esptool write_flash command for each line in firmware.txt. In my case it was:
```
~/.local/bin/esptool.py --chip esp32 -p /dev/ttyUSB0  write_flash 0xe000  boot_app0.bin
~/.local/bin/esptool.py --chip esp32 -p /dev/ttyUSB0  write_flash 0x1000  bootloader_dio_80m.bin
~/.local/bin/esptool.py --chip esp32 -p /dev/ttyUSB0  write_flash 0x8000  SoftRF.ino.partitions.bin
~/.local/bin/esptool.py --chip esp32 -p /dev/ttyUSB0  write_flash 0x10000 SoftRF.ino.bin
```

Now SoftRF is up and running. I can see its WiFi ESSID.

Closed 2021-11-22.

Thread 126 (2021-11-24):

Very fast battery drain when powered off - LilyGO® T-Echo Badge Version

b8fly, 2021-11-24:
**ATTENTION** !

- Use this form to report bugs in released SoftRF firmware, hardware and web pages only ;
- Issue reports from anonymous users will be most likely invalidated. Reasons for that are well explained [here](https://berthub.eu/articles/posts/anonymous-help/) ;
- Prior to asking a question, look into ["Closed issues"](https://github.com/lyusupov/SoftRF/issues?q=is%3Aissue+is%3Aclosed) area to see if it was answered before ;
- No any "ideas" or new feature requests, please ! New feature requests do not subject for taking into consideration unless they come from co-developers ;
- "Enhancements" of existing features are allowed only when you are ready to implement them by yourself ;

Recommended:
- screenshot or photo width - from 600 to 800 pixels ;
- aspect ratio - 4:3, 3:4, 16:9 or 9:16.
- substitute 'space' by 'x' character to mark a hardware checkbox

--------------------

## Hardware

- [ ]   Standalone
- [x]   Badge
- [ ]   Prime Mark II
- [ ]   Dongle
- [ ]   Bracelet
- [ ]   Uni
- [ ]   Mini
- [ ]   SkyView EZ
- [ ]   Raspberry Edition
- [ ]   UAV
- [ ]   UAT978 module
- [ ]   Flight Recorder

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

## Firmware version

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

## Firmware settings

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

## Describe the bug
When powered off (Normal Off Screen) the T-Echo completely drains battery very fast (in days).
(Is this normal and expected behavior? If I do not use the fully charged device for a few days the battery is drained totally and I have first to recharge it before use.)

## To Reproduce
Fully charge the device. Shut off and wait a few days.

## Expected behavior
With a sleep current as documented of 0.25mA the expected discharging time of the powered off device should be around 140 days (850mAh battery). So the drawn current of the device seems to be much higher (maybe around 5mA did not measure it precisely).

lyusupov, 2021-11-28:
Inspect, if this resistor is soldered on your particular T-Echo board.

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

b8fly, 2021-11-28:
Thanks for coming back to me. On my T-Echo board there seems to be no such resistor..
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
.

lyusupov, 2021-11-28:
Your board has Rw missing but R37 is installed.

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

You can try to fix your issue with soldering a 'bridge' over Rw pads.

b8fly, 2021-11-28:
Thank you for your research.
A normal bridge (simple wire - no resistor) will solve the problem? Did I understand that correctly? I don't know if I can do this without destroying the board.
I will probably simply put a switch between the battery and the board.
Thanks again for solving the problem an keep up the great work!

lyusupov, 2021-12-05:
T-Echo with Zetta Device ZD25WQ16B flash memory chip are the only affected.

**Resolution:** fixed

T-Echo firmware binaries were updated in this commit: https://github.com/lyusupov/SoftRF/commit/97fe84ade91bdd47c4ef62efd31fb4731fe61832

Closed 2021-11-24.

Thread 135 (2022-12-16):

T-Beam Turns On When Connecting Charger

micheal813, 2022-12-16:
I'm powering the T-Beam with a 18650 lipo. I turn off the device and connect a charger via usb. When I do, the device powers back on.

Can you make it so that if the power is off, and a battery is inserted, that it does not turn back on when connecting power via usb to charge?

Thank you.

cdeerinck, 2022-12-16:
After you connect to USB, just hold down the power button to turn the software off.  I have no idea if the charging will continue to occur at that point.  If it does, you have your solution.  If it does not, then the controller is being used to assist in the recharge, so your answer would be that it can't happen.  It would be nice for you to test that, and report back here.

micheal813, 2022-12-16:
Yes, if I hold the power button, it will turn back off. It also continues charging. I just thought it would be more convenient if you did not have to turn it back off when connecting a charger.

Thank you.

lewisxhe, 2022-12-17:
This is set by the PMU. By default, when connecting USB, it will automatically power on by default. It cannot be changed

micheal813, 2022-12-17:
Ok. I didn't know that. Thank you for responding.

lyusupov, 2022-12-17:
* report is filed not in compliance with the [template](https://github.com/lyusupov/SoftRF/blob/master/.github/ISSUE_TEMPLATE/softrf-issue-template.md) ;
* anonymous user

**Resolution**: invalid

Closed 2022-12-17.

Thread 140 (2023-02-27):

Wrong WiFi Password Prime Edition MkII

jhonny001, 2023-02-27:
## Hardware

- [ ]   Standalone
- [ ]   Badge
- [X]   Prime Mark II
- [ ]   Dongle
- [ ]   SkyView EZ
- [ ]   Uni
- [ ]   Mini
- [ ]   Bracelet
- [ ]   Academy
- [ ]   Lego
- [ ]   Balkan
- [ ]   Raspberry Edition
- [ ]   UAV
- [ ]   WebTop Serial
- [ ]   UAT978 module
- [ ]   Flight Recorder

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

## Firmware version

[SoftRF-firmware-v1.2-ESP32] (I can't log in to show a SoftRF screenshot neither the LCD is working)

## Firmware settings

Stock settings. This is a fresh install on a new board. I can't provide a screenshot as I have no access to WiFi or BT.

## Describe the bug
The WiFi password is reported to be incorrect. (Password "12345678"). I tried from different devices (2 Android and one Windows laptop) the three of them reported password is incorrect.

## To Reproduce
Fresh install in LILYGO board TTGO T-BEAM V11 with SX1262 and M8N GPS module. FW SoftRF-firmware-v1.2-ESP32.  Try to connect using WiFi.

## Expected behavior
Connect to the WiFi hotspot to configure.

lyusupov, 2023-02-27:
* [Disclaimer](https://github.com/lyusupov/SoftRF/wiki/Prime-Edition-MkII#disclaimer)

**Resolution**: unable to reproduce

lyusupov, 2023-02-27:
https://groups.google.com/g/openglidernetwork/c/G2kAqVuqpKg

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

jhonny001, 2023-02-27:
Hi Linar, thank you very much for the support. Could you please grant me access to the Google Groups thread so I can check how Doug fixed the issue? Cheers,

Closed 2023-02-27.

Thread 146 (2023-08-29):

GNSS not responding on commands or send NMEA sentences

drucknase, 2023-08-29:
## Hardware

- [ ]   Standalone
- [ ]   Badge
- [ ]   Prime Mark II
- [x]   Dongle
- [ ]   SkyView EZ
- [ ]   Uni
- [ ]   Mini
<!-- - [ ]   Bracelet -->
- [ ]   Academy
- [ ]   Lego
- [ ]   ES Edition
- [ ]   Balkan
- [ ]   Raspberry Edition
- [ ]   UAV
- [ ]   WebTop Serial
- [ ]   WebTop USB
- [ ]   UAT978 module
- [ ]   Flight Recorder

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

## Firmware version

`SoftRF-STM32 FW.REV: 1.3 DEV.ID: 3a4e074c
Copyright (C) 2015-2023 Linar Yusupov. All rights reserved.

Reset reason: 6
EXT_SYS
Free heap size: 6276
No reset information available

WARNING! User defined settings are not initialized yet. Loading defaults...
SX127x RFIC is detected.
WARNING! Barometric pressure sensor is NOT detected.

TTGO T-Motion (S76G) Power-on Self Test

Built-in components:
RADIO   : PASS
CLK SRC : TCXO
GNSS    : FAIL

External components:
DISPLAY : N/A
BMx280  : N/A

Power-on Self Test is complete.

Data output device(s):
NMEA   - USB CDC
GDL90  - NULL
D1090  - NULL

$PFLAU,0,0,0,1,0,,0,,,*4F
$PSRFH,4E074C,1,0,0,34*44
$PFLAU,0,0,0,1,0,,0,,,*4F
$PSRFH,4E074C,1,0,0,34*44
$PFLAU,0,0,0,1,0,,0,,,*4F
$PSRFH,4E074C,1,0,0,34*44
$PFLAU,0,0,0,1,0,,0,,,*4F
$PSRFH,4E074C,1,0,0,34*44
$PFLAU,0,0,0,1,0,,0,,,*4F
$PSRFH,4E074C,1,0,0,34*44
$PFLAU,0,0,0,1,0,,0,,,*4F
$PSRFH,4E074C,1,0,0,34*44
$PFLAU,0,0,0,1,0,,0,,,*4F
$PSRFH,4E074C,1,0,0,34*44
$PFLAU,0,0,0,1,0,,0,,,*4F
$PSRFH,4E074C,1,0,0,34*44
$PFLAU,0,0,0,1,0,,0,,,*4F
$PSRFH,4E074C,1,0,0,34*44
$PFLAU,0,0,0,1,0,,0,,,*4F
$PSRFH,4E074C,1,0,0,37*47
$PFLAU,0,0,0,1,0,,0,,,*4F
$PSRFH,4E074C,1,0,0,37*47
$PFLAU,0,0,0,1,0,,0,,,*4F
$PSRFH,4E074C,1,0,0,37*47
$PFLAU,0,0,0,1,0,,0,,,*4F
$PSRFH,4E074C,1,0,0,37*47
$PFLAU,0,0,0,1,0,,0,,,*4F
$PSRFH,4E074C,1,0,0,37*47
$PFLAU,0,0,0,1,0,,0,,,*4F
$PSRFH,4E074C,1,0,0,34*44
$PFLAU,0,0,0,1,0,,0,,,*4F
`

## Firmware settings

just after flashing software (**required**)

## Describe the bug
the GNSS does not respond to commands. I tried also with own software, so after sending a command via serial interface, the GNSS chip (CXD5603) dows not respond. No NMEA output. Only 1 sec impuls can be observed on PB5.
Didn't find the same problem in the closed issues

## To Reproduce
I have two out of five T-Motion boards which show the same behavior.

## Expected behavior
get respond from GNSS chip including NMEA sentences

lyusupov, 2023-08-29:
* anonymous user
* your boot log contains the following message:

```
Built-in components:
RADIO : PASS
CLK SRC : TCXO
GNSS : FAIL
```

which is clear indication that your GNSS issue has nothing to do with the **SoftRF** firmware.
Read the [**Disclaimer**](https://github.com/lyusupov/SoftRF/wiki/Dongle-Edition#disclaimer) against hardware issues then go work with your seller / supplier.

**Resolution**: invalid

Closed 2023-08-29.

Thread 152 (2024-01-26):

Standalone version problem

legacy60000, 2024-01-26:
**ATTENTION** !

- Use this form to report bugs in an [**Official Release**](https://github.com/lyusupov/SoftRF/releases) of SoftRF firmware, hardware and web pages only ;
- Issue reports from anonymous users will be most likely invalidated. Reasons for that are well explained [here](https://berthub.eu/articles/posts/anonymous-help/) ;
- Prior to asking a question, look into ["Closed issues"](https://github.com/lyusupov/SoftRF/issues?q=is%3Aissue+is%3Aclosed) area to see if it was answered before ;
- No any "ideas" or new feature requests, please ! New feature requests do not subject for taking into consideration unless they come from co-developers ;
- "Enhancements" of existing features are only allowed when you are ready to implement them by yourself. See [CONTRIBUTING](https://github.com/lyusupov/SoftRF/blob/master/CONTRIBUTING.md) list for details ;

Recommended:
- screenshot or photo width - from 600 to 800 pixels ;
- aspect ratio - 4:3, 3:4, 16:9 or 9:16.
- substitute 'space' by 'x' character to mark a hardware checkbox

--------------------

## Hardware

- [x]   Standalone
- [ ]   Badge
- [ ]   Prime Mark III
- [ ]   Prime Mark II
- [ ]   Dongle
- [ ]   SkyView EZ
- [ ]   SkyView Pico
- [ ]   Uni
- [ ]   Ham
- [ ]   Midi
- [ ]   Mini
<!-- - [ ]   Bracelet -->
- [ ]   Academy
- [ ]   Lego
- [ ]   ES Edition
- [ ]   Balkan
- [ ]   Raspberry Edition
- [ ]   UAV
- [ ]   WebTop Serial
- [ ]   WebTop USB
- [ ]   UAT978 module
- [ ]   Flight Recorder

< photo of your hardware > (**required**)
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
## Firmware version

<  screenshot of WebUI and/or [**SoftRF Tool**](https://github.com/lyusupov/SoftRF/wiki/SoftRF-Configuration-Tool) status page > (**required**)

## Firmware settings

<  screenshot of WebUI and/or [**SoftRF Tool**](https://github.com/lyusupov/SoftRF/wiki/SoftRF-Configuration-Tool) settings page > (**required**)

## Describe the bug
After startup (changing colors etc..) the LED ring stays in kinda white dimmed state and buzzer stays continuesly on. After gps lock it goes to boot loop. No effect by removing the LED ring and led bar or anyway varying with HW pieces.

Checks done:
- Erased NODEMCU before flashing FW
- Used several different HW pieces
- Power checked twice 3,30V
- Flashed different versions of FW V1.0,V1.1...1.4

## To Reproduce

## Expected behavior

legacy60000, 2024-01-26:
Additional tryouts:

Removed the node mcu from shield:

Suplied 5v for LED ring - nil change
Tryed different manufacturer of LED ring - nil change
Went through all versions of FW - nil change

lyusupov, 2024-02-11:
Works fine to me.

<hr>

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

<hr>

<br>
<br>

**Resolution**: unable to reproduce

<br>

Closed 2024-02-11.

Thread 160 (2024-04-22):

LilyGo T-Echo - Badge - Unintended Power-On Problem

MollyBe, 2024-04-22:
When the device is placed inside a bag, there's a risk of accidental button presses leading to the device turning on and unnecessarily draining the battery. It would be beneficial to enhance the button functions to mitigate this issue.

Current layout:
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

Recommended layout:
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

lyusupov, 2024-04-22:
* report is filed not in compliance with the [template](https://github.com/lyusupov/SoftRF/blob/master/.github/ISSUE_TEMPLATE/softrf-issue-template.md) ;
* anonymous user ;
* report has nothing to do with SoftRF firmware - read [**Disclaimer**](https://github.com/lyusupov/SoftRF/wiki/Badge-Edition#disclaimer)

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

<br>
<br>

**Resolution**: invalid

Closed 2024-04-22.

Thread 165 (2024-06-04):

NMEA LK8EX1 messages missing on MIDI edition

diveinstructor, 2024-06-04:
**ATTENTION** !

- Use this form to report bugs in an [**Official Release**](https://github.com/lyusupov/SoftRF/releases) of SoftRF firmware, hardware and web pages only ;
- Issue reports from anonymous users will be most likely invalidated. Reasons for that are well explained [here](https://berthub.eu/articles/posts/anonymous-help/) ;
- Prior to asking a question, look into ["Closed issues"](https://github.com/lyusupov/SoftRF/issues?q=is%3Aissue+is%3Aclosed) area to see if it was answered before ;
- No any "ideas" or new feature requests, please ! New feature requests do not subject for taking into consideration unless they come from co-developers ;
- "Enhancements" of existing features are only allowed when you are ready to implement them by yourself. See [CONTRIBUTING](https://github.com/lyusupov/SoftRF/blob/master/CONTRIBUTING.md) list for details ;

Recommended:
- screenshot or photo width - from 600 to 800 pixels ;
- aspect ratio - 4:3, 3:4, 16:9 or 9:16.
- substitute 'space' by 'x' character to mark a hardware checkbox

--------------------

## Hardware

- [ ]   Standalone
- [ ]   Badge
- [ ]   Prime Mark III
- [ ]   Prime Mark II
- [ ]   Dongle
- [ ]   SkyView EZ
- [ ]   SkyView Pico
- [ ]   Uni
- [ ]   Ham
- [x]   Midi
- [ ]   Mini
<!-- - [ ]   Bracelet -->
- [ ]   Academy
- [ ]   Lego
- [ ]   ES Edition
- [ ]   Balkan
- [ ]   Raspberry Edition
- [ ]   UAV
- [ ]   WebTop Serial
- [ ]   WebTop USB
- [ ]   UAT978 module
- [ ]   Flight Recorder

< photo of your hardware > (**required**)
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

## Firmware version
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

## Firmware settings
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

## Describe the bug
Despite an installed BME280 baro sensor the NMEA message LK8EX1 is not transmitted

## To Reproduce
Testing with SoftRF app or capturing BLE NMEA messages

## Expected behavior
Transmission of LK8EX1 sentences in the NMEA (BLE) messages.

lyusupov, 2024-06-04:
* [anonymous user](https://berthub.eu/articles/posts/anonymous-help/) ;
* LK8EX1 message is currently inactive intentionally for all the ESP32-XX devices -

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

<br>
<br>

**Resolution**: invalid

Closed 2024-06-04.

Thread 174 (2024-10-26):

T-Echo (badge, v1.5.1) doesn't turn off

jorisrobijn, 2024-10-26:
## Hardware

- [ ]   Standalone
- [x]   Badge
- [ ]   Prime Mark III
- [ ]   Prime Mark II
- [ ]   Dongle
- [ ]   SkyView EZ
- [ ]   SkyView Pico
- [ ]   Uni
- [ ]   Ham
- [ ]   Midi
- [ ]   Mini
<!-- - [ ]   Bracelet -->
- [ ]   Academy
- [ ]   Lego
- [ ]   ES Edition
- [ ]   Balkan
- [ ]   Raspberry Edition
- [ ]   UAV
- [ ]   WebTop Serial
- [ ]   WebTop USB
- [ ]   UAT978 module
- [ ]   Flight Recorder

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

## Firmware version

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

## Firmware settings

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

## Describe the bug
When pressing the lower button for a long time, softrf attempts to shut down with it's "POWER OFF   SCREEN SAVER"  message. However immediately after that, it restarts.
Also when the battery is empty, the power off results in restarting, draining the battery to 2.6 V before it finally stops. I guess some hardware protection then refuses to power the device.
It is worth noting that the meshtastic software that was on this device before did manage to shut it down.

## To Reproduce

Install mentioned firmware, try to power off by pressing button long.

## Expected behavior

Power off when pressing button long

lyusupov, 2024-10-26:
The **MODE** button works fine to me with 1.5.1 firmware.

> softrf attempts to shut down with it's "POWER OFF SCREEN SAVER" message

One is likely activating the touch sensor to get this message:
https://github.com/lyusupov/SoftRF/wiki/Badge-Edition.-Display-care#long-term-storage

This is not a regular power off procedure...

> It is worth noting that the meshtastic software that was on this device before did manage to shut it down.

**It is responsibility of a user to revert a T-Echo device into SoftRF & LilyGO factory conditions** after use of an alternative firmware.

[**Release 1.5.1 Notes**](https://github.com/lyusupov/SoftRF/releases/tag/1.5.1)<br>
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

One could try to apply:
1) [**Meshtastic factory erase procedure**](https://meshtastic.org/docs/getting-started/flashing-firmware/nrf52/nrf52-erase/), and/or
2) [**revert nRF52840 bootloader into factory default state**](https://github.com/Xinyuan-LilyGO/T-Echo/tree/main/bootloader)

<br>

**Resolution**: unable to reproduce

Closed 2024-10-26.

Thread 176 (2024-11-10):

Unable to install SoftRF on Card Edition

ubx, 2024-11-10:
**ATTENTION** !

- Use this form to report bugs in an [**Official Release**](https://github.com/lyusupov/SoftRF/releases) of SoftRF firmware, hardware and web pages only ;
- Issue reports from anonymous users will be most likely invalidated. Reasons for that are well explained [here](https://berthub.eu/articles/posts/anonymous-help/) ;
- Prior to asking a question, look into ["Closed issues"](https://github.com/lyusupov/SoftRF/issues?q=is%3Aissue+is%3Aclosed) area to see if it was answered before ;
- No any "ideas" or new feature requests, please ! New feature requests do not subject for taking into consideration unless they come from co-developers ;
- "Enhancements" of existing features are only allowed when you are ready to implement them by yourself. See [CONTRIBUTING](https://github.com/lyusupov/SoftRF/blob/master/CONTRIBUTING.md) list for details ;

Recommended:
- screenshot or photo width - from 600 to 800 pixels ;
- aspect ratio - 4:3, 3:4, 16:9 or 9:16.
- substitute 'space' by 'x' character to mark a hardware checkbox

--------------------

## Hardware

- [ ]   Standalone
- [ ]   Badge
- [ ]   Prime Mark III
- [ ]   Prime Mark II
- [ ]   Dongle
- [ ]   SkyView EZ
- [ ]   SkyView Pico
- [ ]   Uni
- [ ]   Ham
- [ ]   Midi
- [ ]   Mini
<!-- - [ ]   Bracelet -->
- [ ]   Academy
- [ ]   Lego
- [ ]   ES Edition
- [ ]   Balkan
- [ ]   Raspberry Edition
- [ ]   UAV
- [ ]   WebTop Serial
- [ ]   WebTop USB
- [ ]   UAT978 module
- [ ]   Flight Recorder
- [X]  Card Edition

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

## Firmware version
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

## Firmware settings
N/A

## Describe the bug
Following the [Card Edition Quick Start Installation](https://github.com/lyusupov/SoftRF/wiki/Card-Edition.-Quick-start#installation), after copying the SoftRF firmware binary into the Card Edition (T1000-E volume) and turning on the power of the SoftRF unit by pressing and releasing the button, the expected 4 tones do not play, and the green LED remains dark.

Restoring the T1000-E device with the Meshtastic firmware firmware-tracker-t1000-e-2.5.11.8e2a3e5.uf2 shows that the device is functioning correctly, i.e., Meshtastic runs as expected.

## To Reproduce
Follow the [Card Edition. Quick start Installation](https://github.com/lyusupov/SoftRF/wiki/Card-Edition.-Quick-start#installation).

## Expected behavior
The T1000-E device should be accessible via the SoftRF Tool and/or XCSoar.

lyusupov, 2024-11-10:
None of upcoming
* [**Eco**](https://github.com/lyusupov/SoftRF/wiki/Eco-Edition)
* [**Card**](https://github.com/lyusupov/SoftRF/wiki/Card-Edition)
* [**Cozy**](https://github.com/lyusupov/SoftRF/wiki/Cozy-Edition)

**Editions** are listed in the current version of [**Issue Template**](https://github.com/lyusupov/SoftRF/blob/1d9aff0b6bc99fa482a936258e7ff919ff7d378d/.github/ISSUE_TEMPLATE/softrf-issue-template.md)

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

<br>
<br>

This means that reporting of an issue on any of these Editions is not applicable yet.

<br>

**Resolution**: invalid

Closed 2024-11-10.

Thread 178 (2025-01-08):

WifiKey is not acceped

denis-robel, 2025-01-08:
**ATTENTION** !

- Use this form to report bugs in an [**Official Release**](https://github.com/lyusupov/SoftRF/releases) of SoftRF firmware, hardware and web pages only ;
- Issue reports from anonymous users will be most likely invalidated. Reasons for that are well explained [here](https://berthub.eu/articles/posts/anonymous-help/) ;
- Prior to asking a question, look into ["Closed issues"](https://github.com/lyusupov/SoftRF/issues?q=is%3Aissue+is%3Aclosed) area to see if it was answered before ;
- No any "ideas" or new feature requests, please ! New feature requests do not subject for taking into consideration unless they come from co-developers ;
- "Enhancements" of existing features are only allowed when you are ready to implement them by yourself. See [CONTRIBUTING](https://github.com/lyusupov/SoftRF/blob/master/CONTRIBUTING.md) list for details ;

Recommended:
- screenshot or photo width - from 600 to 800 pixels ;
- aspect ratio - 4:3, 3:4, 16:9 or 9:16.
- substitute 'space' by 'x' character to mark a hardware checkbox

--------------------

## Hardware

- [ ]   Standalone
- [ ]   Badge
- [x]   Prime Mark III
- [ ]   Prime Mark II
- [ ]   Dongle
- [ ]   SkyView EZ
- [ ]   SkyView Pico
- [ ]   Uni
- [ ]   Ham
- [ ]   Card
- [ ]   Cozy
- [ ]   Midi
- [ ]   Mini
<!-- - [ ]   Bracelet -->
- [ ]   Academy
- [ ]   Lego
- [ ]   ES Edition
- [ ]   Balkan
- [ ]   Raspberry Edition
- [ ]   UAV
- [ ]   WebTop Serial
- [ ]   WebTop USB
- [ ]   UAT978 module
- [ ]   Flight Recorder

T-Beam supreme
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

## Firmware version

1.6

can't make a screenshot of web ui

## Firmware settings

can't access the settingspage

## Describe the bug

I'm not able to connect with SoftRF wifi.
I tried several different devices (phone, tablet computer ) with different OS (Linux, Android, SailfishOS) without success.

When I enter the wifi key 12345678 I always get the error that key is not accepted / wrong.

I tried different SoftRF versions 1.2+ and 1.6 with the same result. Do I need a inserted battery for wifi?

Via USB I can connect with xcsoar successfully and a data stream will be transferred.

## To Reproduce

## Expected behavior
Wifi will connect.

lyusupov, 2025-01-08:
Duplicates https://github.com/lyusupov/SoftRF/issues/140

**Resolution**: duplicate

Closed 2025-01-08.

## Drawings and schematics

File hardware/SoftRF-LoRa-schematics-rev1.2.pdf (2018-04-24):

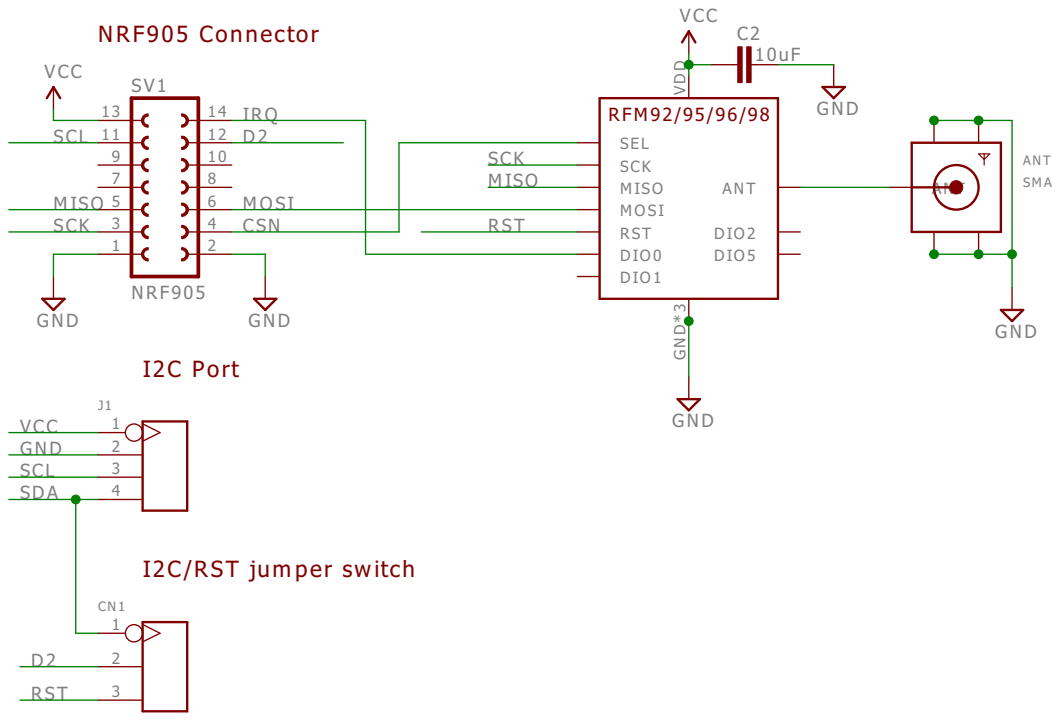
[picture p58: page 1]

SoftRF RFM95 Breakout Board
Author: Linar Yusupov http://github.com/lyusupov/SoftRF

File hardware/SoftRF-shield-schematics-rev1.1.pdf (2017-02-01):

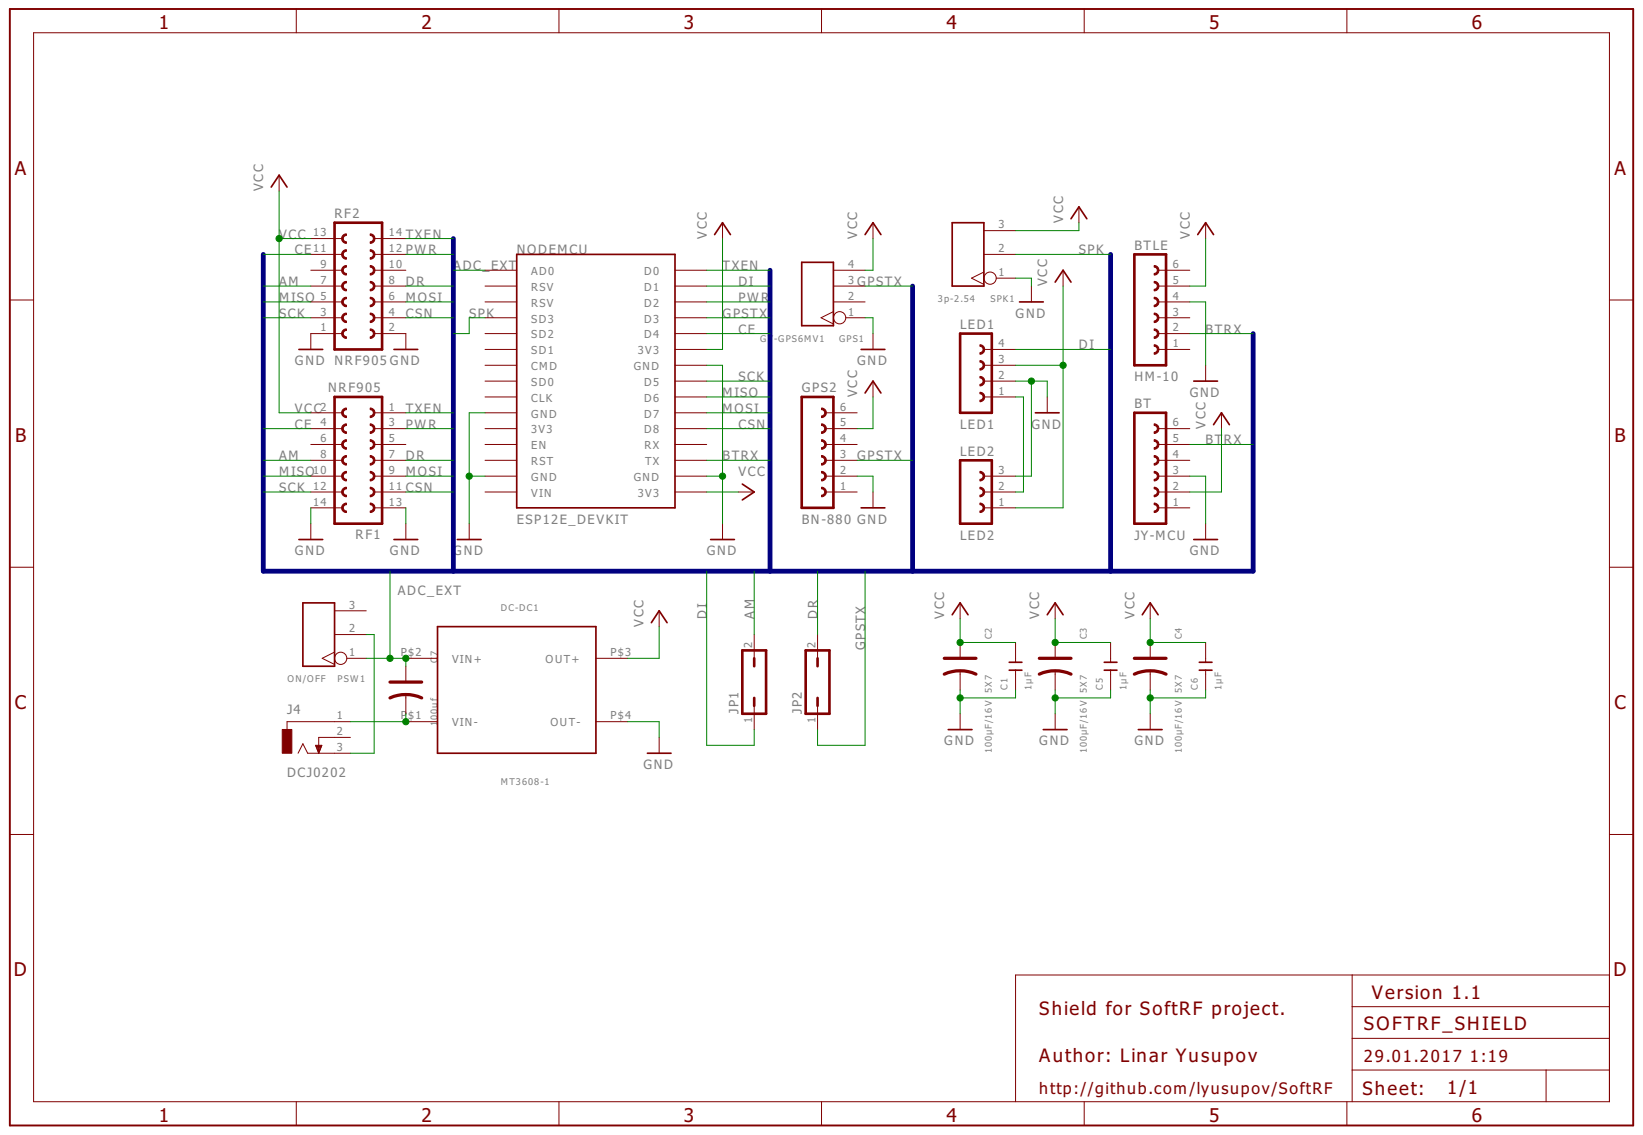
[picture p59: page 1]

Shield for SoftRF project. Author: Linar Yusupov

http://github.com/lyusupov/SoftRF

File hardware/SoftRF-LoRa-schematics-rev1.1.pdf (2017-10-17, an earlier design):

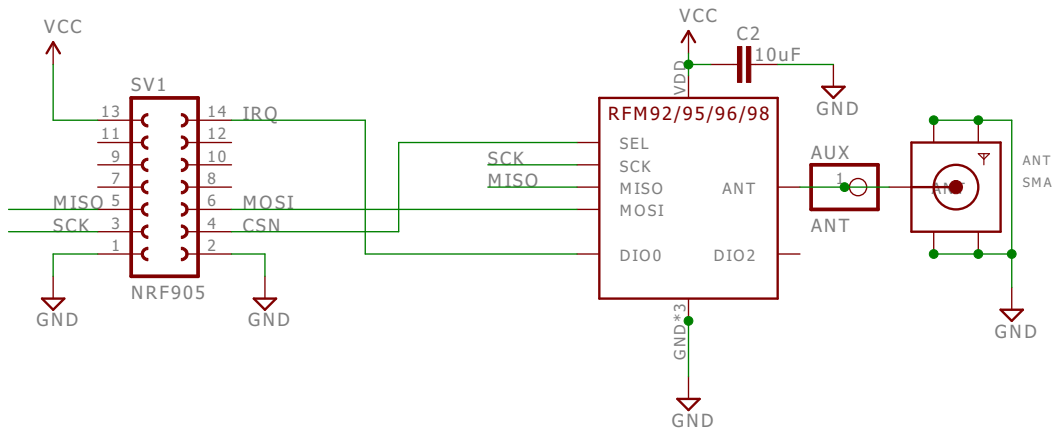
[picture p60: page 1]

SoftRF RFM95 Breakout Board
Author: Linar Yusupov http://github.com/lyusupov/SoftRF

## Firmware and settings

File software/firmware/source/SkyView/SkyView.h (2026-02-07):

/*
 * SkyView.h
 * Copyright (C) 2019-2026 Linar Yusupov
 *
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
 * You should have received a copy of the GNU General Public License
 * along with this program.  If not, see <http://www.gnu.org/licenses/>.
 */

#ifndef SKYVIEW_H
#define SKYVIEW_H

#define SKYVIEW_FIRMWARE_VERSION  "0.14"
#define SKYVIEW_USB_FW_VERSION    0x0014
#define SKYVIEW_IDENT             "SkyView"
#define SOFTRF_IDENT              "SoftRF"

#define DEFAULT_AP_SSID           "SoftRF-abc123"
#define DEFAULT_AP_PSK            "12345678"

#define MY_ACCESSPOINT_SSID       ""
#define MY_ACCESSPOINT_PSK        ""

#define RELAY_DST_PORT            12390
#define RELAY_SRC_PORT            (RELAY_DST_PORT - 1)

/* SoftRF serial output defaults */
#define SERIAL_OUT_BR             38400
#define SERIAL_OUT_BITS           SERIAL_8N1

#define DATA_TIMEOUT              2000 /* 2.0 seconds */

#define MAX_FILENAME_LEN          64
#define WAV_FILE_SUFFIX           ".wav"
#define VOICE1_SUBDIR             "voice1/"
#define VOICE2_SUBDIR             "voice2/"
#define VOICE3_SUBDIR             "voice3/"

typedef struct hardware_info {
    byte  model;
    byte  revision;
    byte  soc;
    byte  display;
    byte  storage;
    byte  rtc;
    byte  imu;
    byte  mag;
    byte  pmu;
    byte  audio;
    byte  touch;
    byte  haptic;
    byte  camera;
} hardware_info_t;

typedef struct IODev_ops_struct {
  const char name[16];
  void (*setup)();
  void (*loop)();
  void (*fini)();
  int (*available)(void);
  int (*read)(void);
  size_t (*write)(const uint8_t *buffer, size_t size);
} IODev_ops_t;

enum
{
	SOFTRF_MODEL_UNKNOWN,
	SOFTRF_MODEL_STANDALONE,
	SOFTRF_MODEL_PRIME,
	SOFTRF_MODEL_UAV,
	SOFTRF_MODEL_PRIME_MK2,
	SOFTRF_MODEL_RASPBERRY,
	SOFTRF_MODEL_UAT,
	SOFTRF_MODEL_SKYVIEW,
	SOFTRF_MODEL_RETRO,
	SOFTRF_MODEL_SKYWATCH,
	SOFTRF_MODEL_DONGLE,
	SOFTRF_MODEL_OCTAVE,
	SOFTRF_MODEL_UNI,
	SOFTRF_MODEL_WEBTOP_SERIAL,
	SOFTRF_MODEL_MINI,
	SOFTRF_MODEL_BADGE,
	SOFTRF_MODEL_ES,
	SOFTRF_MODEL_BRACELET,
	SOFTRF_MODEL_ACADEMY,
	SOFTRF_MODEL_LEGO,
	SOFTRF_MODEL_WEBTOP_USB,
	SOFTRF_MODEL_PRIME_MK3,
	SOFTRF_MODEL_BALKAN,
	SOFTRF_MODEL_HAM,
	SOFTRF_MODEL_MIDI,
	SOFTRF_MODEL_ECO,
	SOFTRF_MODEL_INK,
	SOFTRF_MODEL_CARD,
	SOFTRF_MODEL_COZY,
	SOFTRF_MODEL_NEO,
	SOFTRF_MODEL_HANDHELD,
	SOFTRF_MODEL_GIZMO,
	SOFTRF_MODEL_NANO,
	SOFTRF_MODEL_DECENT,
	SOFTRF_MODEL_LYRA,
	SOFTRF_MODEL_AIRVENTURE,
	SOFTRF_MODEL_SOLARIS,
	SOFTRF_MODEL_POCKET,
	SOFTRF_MODEL_LABUBU,
	SOFTRF_MODEL_CONCORDE,
};

enum
{
	HW_REV_UNKNOWN,
	HW_REV_DEVKIT,
	HW_REV_T5S_1_9,
	HW_REV_T5S_2_8,
	HW_REV_T8_1_8,
	HW_REV_T5_1,
	HW_REV_PICO,
	HW_REV_PICO_W,
	HW_REV_PICO_2,
	HW_REV_PICO_2W,
	HW_REV_BPI,
	HW_REV_TDISPLAY_P4_TFT,
	HW_REV_TDISPLAY_P4_AMOLED,
};

enum
{
	DISPLAY_NONE,
	DISPLAY_EPD_2_7,
	DISPLAY_OLED_2_4,
	DISPLAY_EPD_4_7,
	DISPLAY_TFT_7_0,
	DISPLAY_TFT_4_05,
	DISPLAY_AMOLED_4_1,
};

enum
{
	ADAPTER_WAVESHARE_PI_HAT_2_7,    /* GDEW027W3  */
	ADAPTER_WAVESHARE_PI_HAT_2_7_V2, /* GDEY027T91 */
	ADAPTER_WAVESHARE_ESP8266,
	ADAPTER_WAVESHARE_ESP32,
	ADAPTER_WAVESHARE_PICO_2_7,      /* GDEW027W3  */
	ADAPTER_WAVESHARE_PICO_2_7_V2,   /* GDEY027T91 */
	ADAPTER_TTGO_T5S,
	ADAPTER_TTGO_T5S_V2,             /* reserved for update on GDEY027T91 */
	ADAPTER_NODEMCU,
	ADAPTER_OLED,
	ADAPTER_TTGO_T5_4_7,
	ADAPTER_MIPI_DSI,
};

enum
{
	CON_NONE,
	CON_SERIAL_MAIN,
	CON_SERIAL_AUX,
	CON_USB,
	CON_WIFI_UDP,
	CON_WIFI_TCP,
	CON_BLUETOOTH_SPP,
	CON_BLUETOOTH_LE,
};

enum
{
	B4800,
	B9600,
	B19200,
	B38400,
	B57600,
	B115200,
	B2000000,
};

enum
{
	PROTOCOL_NONE,
	PROTOCOL_NMEA, /* FTD-12 */
	PROTOCOL_GDL90,
	PROTOCOL_MAVLINK_1,
	PROTOCOL_MAVLINK_2,
	PROTOCOL_D1090,
	PROTOCOL_UATRADIO,
};

enum
{
	UNITS_METRIC,
	UNITS_IMPERIAL,
	UNITS_MIXED,    // almost the same as metric, but all the altitudes are in feet
};

enum
{
	VIEW_MODE_RADAR,
	VIEW_MODE_TABLE,
	VIEW_MODE_TEXT,
	VIEW_MODE_STATUS,
};

enum
{
	DIRECTION_TRACK_UP,
	DIRECTION_NORTH_UP,
};

/*
 * 'Radar view' scale factor (outer circle diameter)
 *
 * Metric and Mixed:
 *  LOWEST - 20 KM diameter (10 KM radius)
 *  LOW    - 10 KM diameter ( 5 KM radius)
 *  MEDIUM -  4 KM diameter ( 2 KM radius)
 *  HIGH   -  2 KM diameter ( 1 KM radius)
 *
 * Imperial:
 *  LOWEST - 10 NM diameter (  5 NM radius)
 *  LOW    -  5 NM diameter (2.5 NM radius)
 *  MEDIUM -  2 NM diameter (  1 NM radius)
 *  HIGH   -  1 NM diameter (0.5 NM radius)
 */
enum
{
	ZOOM_LOWEST,
	ZOOM_LOW,
	ZOOM_MEDIUM,
	ZOOM_HIGH,
};

enum
{
	ID_REG,
	ID_TAIL,
	ID_MAM,
	ID_TYPE,
};

enum
{
	VOICE_OFF,
	VOICE_1,
	VOICE_2,
	VOICE_3,
};

enum
{
	ANTI_GHOSTING_OFF,
	ANTI_GHOSTING_AUTO,
	ANTI_GHOSTING_2MIN,
	ANTI_GHOSTING_5MIN,
	ANTI_GHOSTING_10MIN,
};

enum
{
	POWER_SAVE_NONE = 0,
	POWER_SAVE_WIFI = 1,
	POWER_SAVE_GNSS = 2,
};

enum
{
	TRAFFIC_FILTER_OFF,
	TRAFFIC_FILTER_500M,
	TRAFFIC_FILTER_1500M,
};

enum
{
	DB_NONE,
	DB_AUTO,
	DB_FLN,
	DB_OGN,
	DB_ICAO,
};

enum
{
	ROTATE_0,
	ROTATE_90,
	ROTATE_180,
	ROTATE_270,
};

enum
{
	STORAGE_NONE,
	STORAGE_FLASH,
	STORAGE_CARD,
	STORAGE_FLASH_AND_CARD,
};

enum
{
	RTC_NONE,
	RTC_PCF8563
};

enum
{
	IMU_NONE,
	ACC_BMA423,
	ACC_ADXL362,
	ACC_QMA6100P,
	ACC_SC7A20H,
	IMU_MPU6886,
	IMU_MPU9250,
	IMU_BNO080,
	IMU_ICM20948,
	IMU_QMI8658,
	IMU_BHI260AP,
};

enum
{
	MAG_NONE,
	MAG_AK8963,
	MAG_AK09916,
	MAG_IIS2MDC,
	MAG_QMC6310U,
	MAG_QMC6310N,
	MAG_BMM150,
};

enum
{
	AUDIO_NONE,
	AUDIO_PWM, /* or PDM */
	AUDIO_MAX98357,
	AUDIO_NS4168,
	AUDIO_ES8311,
};

enum
{
	TOUCH_NONE,
	TOUCH_FT5206,
	TOUCH_TTP223,
	TOUCH_FT6336,
	TOUCH_GT911,
	TOUCH_JD9365TG, /* HI8561 */
	TOUCH_GT9895,
};

enum
{
	HAPTIC_NONE,
	HAPTIC_DRV2605,
	HAPTIC_AW86224,
};

enum
{
	CAMERA_NONE,
	CAMERA_OV5647,
	CAMERA_OV2710,
};

extern hardware_info_t hw_info;
extern bool screen_saver;

extern void shutdown(const char *);
extern void Input_loop(void);

#endif /* SKYVIEW_H */

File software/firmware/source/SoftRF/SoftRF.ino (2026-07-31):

/*
 * SoftRF(.ino) firmware
 * Copyright (C) 2016-2026 Linar Yusupov
 *
 * Author: Linar Yusupov, linar.r.yusupov@gmail.com
 *
 * Web: http://github.com/lyusupov/SoftRF
 *
 * Credits:
 *   Arduino core for ESP8266 is developed/supported by ESP8266 Community (support-esp8266@esp8266.com)
 *   AVR/Arduino nRF905 Library/Driver is developed by Zak Kemble, contact@zakkemble.co.uk
 *   flarm_decode is developed by Stanislaw Pusep, http://github.com/creaktive
 *   Arduino Time Library is developed by Paul Stoffregen, http://github.com/PaulStoffregen
 *   "Aircraft" and MAVLink Libraries are developed by Andy Little
 *   TinyGPS++ and PString Libraries are developed by Mikal Hart
 *   Adafruit NeoPixel Library is developed by Phil Burgess, Michael Miller and others
 *   TrueRandom Library is developed by Peter Knight
 *   IBM LMIC and Semtech Basic MAC frameworks for Arduino are maintained by Matthijs Kooijman
 *   ESP8266FtpServer is developed by David Paiva
 *   Lib_crc is developed by Lammert Bies
 *   OGN/ADS-L library is developed by Pawel Jalocha
 *   NMEA library is developed by Timur Sinitsyn, Tobias Simon, Ferry Huberts
 *   ADS-B encoder C++ library is developed by yangbinbin (yangbinbin_ytu@163.com)
 *   Arduino Core for ESP32 is developed by Hristo Gochkov
 *   ESP32 BT SPP library is developed by Evandro Copercini
 *   Adafruit BMP085 library is developed by Limor Fried ( Ladyada )
 *   Adafruit BMP280 library is developed by Kevin Townsend
 *   Adafruit MPL3115A2 and LIS3DH libraries are developed by Limor Fried and Kevin Townsend
 *   U8g2 monochrome LCD, OLED and eInk library is developed by Oliver Kraus
 *   NeoPixelBus library is developed by Michael Miller
 *   jQuery library is developed by JS Foundation
 *   EGM96 data is developed by XCSoar team
 *   BCM2835 and RadioHead libraries are developed by Mike McCauley
 *   SimpleNetwork library is developed by Dario Longobardi
 *   ArduinoJson library is developed by Benoit Blanchon
 *   Flashrom library is part of the flashrom.org project
 *   Arduino Core for TI CC13X0 and CC13X2 is developed by Robert Wessels
 *   EasyLink library is developed by Robert Wessels and Tony Cave
 *   Dump978 library is developed by Oliver Jowett
 *   FEC library is developed by Phil Karn
 *   PCF8563, AXP20X, XPowersLib and SensorLib libraries are developed by Lewis He
 *   Arduino Core for STM32 is developed by Frederic Pillon
 *   TFT library is developed by Bodmer
 *   STM32duino Low Power and RTC libraries are developed by Wi6Labs
 *   Basic MAC library is developed by Michael Kuyper
 *   LowPowerLab SPIFlash library is maintained by Felix Rusu
 *   Arduino Core for ASR6x0x is developed by Aaron Lee (HelTec Automation)
 *   ADXL362 library is developed by Klaas-Jan Winkel
 *   Arduino Core for nRF52 and TinyUSB library are developed by Ha Thach
 *   Arduino-NVM library is developed by Frank Holtz
 *   AceButton library is developed by Brian Park
 *   GxEPD2 library is developed by Jean-Marc Zingg
 *   Adafruit GFX, BusIO, INA219 and BME680 libraries are developed by Adafruit Industries
 *   U8g2 fonts for Adafruit GFX are developed by Oliver Kraus
 *   Adafruit SPIFlash and SleepyDog libraries are developed by Adafruit Industries
 *   SdFat library is developed by Bill Greiman
 *   Arduino MIDI library is developed by Francois Best (Forty Seven Effects)
 *   Arduino uCDB library is developed by Ioulianos Kakoulidis
 *   Arduino Cores for Atmel SAMD and Renesas RA4 are developed by Arduino LLC
 *   FlashStorage library is developed by Arduino LLC
 *   USB host library 2.0 for Zero/M0/SAMD is developed by gdsports625@gmail.com
 *   Arduino Core for RP2XXX and ESP8266Audio library are developed by Earle Philhower
 *   MPU-9250 9 DoF sensor library is developed by Kris Winer and Hideaki Tai
 *   Pico PIO USB library is developed by sekigon-gonnoc
 *   IniFile library is developed by Steve Marple
 *   MD5 library is developed by Vasilis Georgitzikis
 *   LibAPRS-ESP32 library is developed by Evan Krall and Somkiat Nakhonthai
 *   SA818 library is developed by Gibbon Zen
 *   OpenDroneID library is developed by Steve Jack
 *   WiFiWebServer and Functional-Vlpp libraries are developed by Khoi Hoang
 *   RadioLib library is developed by Jan Gromes
 *   Arduino Core for EFR32 Series 2 is developed by Tamas Jozsi
 *   ArduinoBLE library is developed by Arduino LLC
 *   Arduino Core for CH32 is developed by Tianpei Lee
 *   QMA6100P library is developed by Tristan Alderson
 *   Arduino Core for nRF54L15 is developed by Loren Bufanu
 *   Arduino EEPROM library is developed by Jack Christensen
 *   Adafruit SPA06-003 library is developed by Limor Fried
 *
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
 * This program is distributed in the hope that it will be useful,
 * but WITHOUT ANY WARRANTY; without even the implied warranty of
 * MERCHANTABILITY or FITNESS FOR A PARTICULAR PURPOSE.  See the
 * GNU General Public License for more details.
 *
 * You should have received a copy of the GNU General Public License
 * along with this program.  If not, see <http://www.gnu.org/licenses/>.
 */

#include "src/system/OTA.h"
#include "src/system/Time.h"
#include "src/driver/LED.h"
#include "src/driver/GNSS.h"
#include "src/driver/RF.h"
#include "src/driver/Sound.h"
#include "src/driver/EEPROM.h"
#include "src/driver/Battery.h"
#include "src/protocol/data/MAVLink.h"
#include "src/protocol/data/GDL90.h"
#include "src/protocol/data/NMEA.h"
#include "src/protocol/data/D1090.h"
#include "src/system/SoC.h"
#include "src/driver/WiFi.h"
#include "src/ui/Web.h"
#include "src/driver/Baro.h"
#include "src/TTNHelper.h"
#include "src/TrafficHelper.h"
#include "src/system/Recorder.h"

#if defined(ENABLE_AHRS)
#include "src/driver/AHRS.h"
#endif /* ENABLE_AHRS */

#if !defined(SERIAL_FLUSH)
#define SERIAL_FLUSH() Serial.flush()
#endif

#define DEBUG 0
#define DEBUG_TIMING 0

#define isTimeToDisplay() (millis() - LEDTimeMarker     > 1000)
#define isTimeToExport()  (millis() - ExportTimeMarker  > 1000)

ufo_t ThisAircraft;

hardware_info_t hw_info = {
  .model    = DEFAULT_SOFTRF_MODEL,
  .revision = 0,
  .soc      = SOC_NONE,
  .rf       = RF_IC_NONE,
  .gnss     = GNSS_MODULE_NONE,
  .baro     = BARO_MODULE_NONE,
  .display  = DISPLAY_NONE,
  .storage  = STORAGE_NONE,
  .rtc      = RTC_NONE,
  .imu      = IMU_NONE,
  .mag      = MAG_NONE,
  .pmu      = PMU_NONE,
  .audio    = AUDIO_NONE,
  .touch    = TOUCH_NONE,
  .haptic   = HAPTIC_NONE,
  .camera   = CAMERA_NONE,
};

unsigned long LEDTimeMarker = 0;
unsigned long ExportTimeMarker = 0;

void setup()
{
  rst_info *resetInfo;

  hw_info.soc = SoC_setup(); // Has to be very first procedure in the execution order

  resetInfo = (rst_info *) SoC->getResetInfoPtr();

  Serial.println();
  Serial.print(F(SOFTRF_IDENT "-"));
  Serial.print(SoC->name);
  Serial.print(F(" FW.REV: " SOFTRF_FIRMWARE_VERSION " DEV.ID: "));
  Serial.println(String(SoC->getChipId(), HEX));
  Serial.println(F("Copyright (C) 2015-2026 Linar Yusupov. All rights reserved."));

  SERIAL_FLUSH();

  if (resetInfo) {
    Serial.println(""); Serial.print(F("Reset reason: ")); Serial.println(resetInfo->reason);
  }
  Serial.println(SoC->getResetReason());
  Serial.print(F("Free heap size: ")); Serial.println(SoC->getFreeHeap());
  Serial.println(SoC->getResetInfo()); Serial.println("");

  SERIAL_FLUSH();

  EEPROM_setup();

  SoC->Button_setup();

  ThisAircraft.addr = SoC->getChipId() & 0x00FFFFFF;

  hw_info.rf = RF_setup();

  delay(100);

  hw_info.baro = Baro_setup();
#if defined(ENABLE_AHRS)
  hw_info.imu = AHRS_setup();
#endif /* ENABLE_AHRS */
  hw_info.display = SoC->Display_setup();

#if !defined(EXCLUDE_MAVLINK)
  if (settings->mode == SOFTRF_MODE_UAV) {
    if (hw_info.model == SOFTRF_MODEL_STANDALONE) {
      Serial.begin(57600);
    }
    MAVLink_setup();
    ThisAircraft.aircraft_type = AIRCRAFT_TYPE_UAV;  
  }  else
#endif /* EXCLUDE_MAVLINK */
  {
    hw_info.gnss = GNSS_setup();
    ThisAircraft.aircraft_type = settings->aircraft_type;
  }
  ThisAircraft.protocol = settings->rf_protocol;
  ThisAircraft.stealth  = settings->stealth;
  ThisAircraft.no_track = settings->no_track;

  Battery_setup();
  Traffic_setup();

  SoC->swSer_enableRx(false);

  LED_setup();

  WiFi_setup();

  if (SoC->USB_ops) {
     SoC->USB_ops->setup();
  }

  if (SoC->Bluetooth_ops) {
     SoC->Bluetooth_ops->setup();
  }

  OTA_setup();
  Web_setup();
  NMEA_setup();

#if defined(ENABLE_TTN)
  TTN_setup();
#endif

  delay(1000);

  /* expedite restart on WDT reset */
  if (resetInfo->reason != REASON_WDT_RST) {
    LED_test();
  }

  Sound_setup();
  SoC->Sound_test(resetInfo->reason);

  switch (settings->mode)
  {
  case SOFTRF_MODE_TXRX_TEST:
  case SOFTRF_MODE_WATCHOUT:
    Time_setup();
    break;
  case SOFTRF_MODE_BRIDGE:
    break;
  case SOFTRF_MODE_NORMAL:
  case SOFTRF_MODE_UAV:
  default:
    SoC->swSer_enableRx(true);
    break;
  }

  Recorder_setup();

  SoC->post_init();

  SoC->WDT_setup();
}

void loop()
{
  // Do common RF stuff first
  RF_loop();

  switch (settings->mode)
  {
#if !defined(EXCLUDE_TEST_MODE)
  case SOFTRF_MODE_TXRX_TEST:
    txrx_test();
    break;
#endif /* EXCLUDE_TEST_MODE */
#if !defined(EXCLUDE_MAVLINK)
  case SOFTRF_MODE_UAV:
    uav();
    break;
#endif /* EXCLUDE_MAVLINK */
#if !defined(EXCLUDE_WIFI)
  case SOFTRF_MODE_BRIDGE:
    bridge();
    break;
#endif /* EXCLUDE_WIFI */
#if !defined(EXCLUDE_WATCHOUT_MODE)
  case SOFTRF_MODE_WATCHOUT:
    watchout();
    break;
#endif /* EXCLUDE_WATCHOUT_MODE */
  case SOFTRF_MODE_NORMAL:
  default:
    normal();
    break;
  }

  // Show status info on tiny OLED display
  SoC->Display_loop();

  // battery status LED
  LED_loop();

  // Handle DNS
  WiFi_loop();

  // Handle Web
  Web_loop();

  // Handle OTA update.
  OTA_loop();

  Recorder_loop();

  SoC->loop();

  if (SoC->Bluetooth_ops) {
    SoC->Bluetooth_ops->loop();
  }

  if (SoC->USB_ops) {
    SoC->USB_ops->loop();
  }

  if (SoC->UART_ops) {
     SoC->UART_ops->loop();
  }

  Battery_loop();

  SoC->Button_loop();

  Time_loop();

  yield();
}

void shutdown(int reason)
{
  SoC->WDT_fini();

  SoC->swSer_enableRx(false);

  Recorder_fini();

  Sound_fini();

  NMEA_fini();

  Web_fini();

  if (SoC->Bluetooth_ops) {
     SoC->Bluetooth_ops->fini();
  }

  if (SoC->USB_ops) {
     SoC->USB_ops->fini();
  }

  WiFi_fini();

  if (settings->mode != SOFTRF_MODE_UAV) {
    GNSS_fini();
  }

  SoC->Display_fini(reason);

  Baro_fini();

  RF_Shutdown();

  SoC->Button_fini();

  SoC_fini(reason);
}

void normal()
{
  bool success;

  Baro_loop();

#if defined(ENABLE_AHRS)
  AHRS_loop();
#endif /* ENABLE_AHRS */

  GNSS_loop();

  ThisAircraft.timestamp = now();
  if (isValidFix()) {
    ThisAircraft.latitude  = gnss.location.lat();
    ThisAircraft.longitude = gnss.location.lng();
    ThisAircraft.altitude  = gnss.altitude.meters();
    ThisAircraft.course    = gnss.course.deg();
    ThisAircraft.speed     = gnss.speed.knots();
    ThisAircraft.hdop      = (uint16_t) gnss.hdop.value();
    ThisAircraft.geoid_separation = gnss.separation.meters();

#if !defined(EXCLUDE_EGM96)
    /*
     * When geoidal separation is zero or not available - use approx. EGM96 value
     */
    if (ThisAircraft.geoid_separation == 0.0) {
      ThisAircraft.geoid_separation = (float) LookupSeparation(
                                                ThisAircraft.latitude,
                                                ThisAircraft.longitude
                                              );
      /* we can assume the GPS unit is giving ellipsoid height */
      ThisAircraft.altitude -= ThisAircraft.geoid_separation;
    }
#endif /* EXCLUDE_EGM96 */

    RF_Transmit(RF_Encode(&ThisAircraft), true);
  }

  success = RF_Receive();

#if DEBUG
  success = true;
#endif

  if (success && isValidFix()) ParseData();

#if defined(ENABLE_TTN)
  TTN_loop();
#endif

  if (isValidFix()) {
    Traffic_loop();
  }

  if (isTimeToDisplay()) {
    if (isValidFix()) {
      LED_DisplayTraffic();
    } else {
      LED_Clear();
    }
    LEDTimeMarker = millis();
  }

  Sound_loop();

  if (isTimeToExport()) {
    NMEA_Export();
    GDL90_Export();
    D1090_Export();

    ExportTimeMarker = millis();
  }

  // Handle Air Connect
  NMEA_loop();

  ClearExpired();
}

#if !defined(EXCLUDE_MAVLINK)
void uav()
{
  bool success = false;

  PickMAVLinkFix();

  MAVLinkTimeSync();
  MAVLinkSetWiFiPower();

  hw_info.gnss = get_num_heartbeats() > 0 ? GNSS_MODULE_MAV : GNSS_MODULE_NONE;

  ThisAircraft.timestamp = now();

  if (isValidMAVFix()) {
    ThisAircraft.latitude  = the_aircraft.location.gps_lat / 1e7;
    ThisAircraft.longitude = the_aircraft.location.gps_lon / 1e7;
    ThisAircraft.altitude  = the_aircraft.location.gps_alt / 1000.0;
    ThisAircraft.course    = the_aircraft.location.gps_cog;
    ThisAircraft.speed     = (the_aircraft.location.gps_vog / 100.0) / _GPS_MPS_PER_KNOT;
    ThisAircraft.hdop      = the_aircraft.location.gps_hdop;
    ThisAircraft.pressure_altitude = the_aircraft.location.baro_alt;

#if !defined(EXCLUDE_EGM96)
    /*
     * When geoidal separation is not available - use approx. EGM96 value
     */
    ThisAircraft.geoid_separation = (float) LookupSeparation(
                                              ThisAircraft.latitude,
                                              ThisAircraft.longitude
                                              );
#endif /* EXCLUDE_EGM96 */

    RF_Transmit(RF_Encode(&ThisAircraft), true);
  }

  success = RF_Receive();

  if (success && isValidMAVFix()) ParseData();

  if (isTimeToExport() && isValidMAVFix()) {
    MAVLinkShareTraffic();
    ExportTimeMarker = millis();
  }

  ClearExpired();
}
#endif /* EXCLUDE_MAVLINK */

#if !defined(EXCLUDE_WIFI)
void bridge()
{
  bool success;

  size_t tx_size = Raw_Receive_UDP(&TxBuffer[0]);

  if (tx_size > 0) {
    RF_Transmit(tx_size, true);
  }

  success = RF_Receive();

  if(success)
  {
    size_t rx_size = RF_Payload_Size(settings->rf_protocol);
    rx_size = rx_size > sizeof(fo.raw) ? sizeof(fo.raw) : rx_size;

    memset(fo.raw, 0, sizeof(fo.raw));
    memcpy(fo.raw, RxBuffer, rx_size);

    if (settings->nmea_p) {
      StdOut.print(F("$PSRFI,"));
      StdOut.print((unsigned long) now());    StdOut.print(F(","));
      StdOut.print(Bin2Hex(fo.raw, rx_size)); StdOut.print(F(","));
      StdOut.println(RF_last_rssi);
    }

    Raw_Transmit_UDP();
  }

  if (isTimeToDisplay()) {
    LED_Clear();
    LEDTimeMarker = millis();
  }
}
#endif /* EXCLUDE_WIFI */

#if !defined(EXCLUDE_WATCHOUT_MODE)
void watchout()
{
  bool success;

  success = RF_Receive();

  if (success) {
    size_t rx_size = RF_Payload_Size(settings->rf_protocol);
    rx_size = rx_size > sizeof(fo.raw) ? sizeof(fo.raw) : rx_size;

    memset(fo.raw, 0, sizeof(fo.raw));
    memcpy(fo.raw, RxBuffer, rx_size);

    if (settings->nmea_p) {
      StdOut.print(F("$PSRFI,"));
      StdOut.print((unsigned long) now());    StdOut.print(F(","));
      StdOut.print(Bin2Hex(fo.raw, rx_size)); StdOut.print(F(","));
      StdOut.println(RF_last_rssi);
    }
  }

  if (isTimeToDisplay()) {
    LED_Clear();
    LEDTimeMarker = millis();
  }
}
#endif /* EXCLUDE_WATCHOUT_MODE */

#if !defined(EXCLUDE_TEST_MODE)

unsigned int pos_ndx = 0;
unsigned long TxPosUpdMarker = 0;

void txrx_test()
{
  bool success = false;
#if DEBUG_TIMING
  unsigned long baro_start_ms, baro_end_ms;
  unsigned long tx_start_ms, tx_end_ms, rx_start_ms, rx_end_ms;
  unsigned long parse_start_ms, parse_end_ms, led_start_ms, led_end_ms;
  unsigned long export_start_ms, export_end_ms;
  unsigned long oled_start_ms, oled_end_ms;
#endif
  ThisAircraft.timestamp = now();

  if (TxPosUpdMarker == 0 || (millis() - TxPosUpdMarker) > 4000 ) {
    ThisAircraft.latitude  = pgm_read_float( &txrx_test_positions[pos_ndx][0]);
    ThisAircraft.longitude = pgm_read_float( &txrx_test_positions[pos_ndx][1]);
    pos_ndx = (pos_ndx + 1) % TXRX_TEST_NUM_POSITIONS;
    TxPosUpdMarker = millis();
  }
  ThisAircraft.altitude = TXRX_TEST_ALTITUDE;
  ThisAircraft.course   = TXRX_TEST_COURSE;
  ThisAircraft.speed    = TXRX_TEST_SPEED;
  ThisAircraft.vs       = TXRX_TEST_VS;

#if DEBUG_TIMING
  baro_start_ms = millis();
#endif
  Baro_loop();
#if DEBUG_TIMING
  baro_end_ms = millis();
#endif

#if defined(ENABLE_AHRS)
  AHRS_loop();
#endif /* ENABLE_AHRS */

#if DEBUG_TIMING
  tx_start_ms = millis();
#endif
  RF_Transmit(RF_Encode(&ThisAircraft), true);
#if DEBUG_TIMING
  tx_end_ms = millis();
  rx_start_ms = millis();
#endif
  success = RF_Receive();
#if DEBUG_TIMING
  rx_end_ms = millis();
#endif

#if DEBUG_TIMING
  parse_start_ms = millis();
#endif
  if (success) ParseData();
#if DEBUG_TIMING
  parse_end_ms = millis();
#endif

#if defined(ENABLE_TTN)
  TTN_loop();
#endif

  Traffic_loop();

#if DEBUG_TIMING
  led_start_ms = millis();
#endif
  if (isTimeToDisplay()) {
    LED_DisplayTraffic();
    LEDTimeMarker = millis();
  }
#if DEBUG_TIMING
  led_end_ms = millis();
#endif

  Sound_loop();

#if DEBUG_TIMING
  export_start_ms = millis();
#endif
  if (isTimeToExport()) {
#if defined(USE_NMEALIB)
    NMEA_Position();
#endif
    NMEA_Export();
    GDL90_Export();
    D1090_Export();
    ExportTimeMarker = millis();
  }
#if DEBUG_TIMING
  export_end_ms = millis();
#endif

#if DEBUG_TIMING
  oled_start_ms = millis();
#endif
//  SoC->Display_loop();
#if DEBUG_TIMING
  oled_end_ms = millis();
#endif

#if DEBUG_TIMING
  if (baro_start_ms - baro_end_ms) {
    Serial.print(F("Baro start: "));
    Serial.print(baro_start_ms);
    Serial.print(F(" Baro stop: "));
    Serial.println(baro_end_ms);
  }
  if (tx_end_ms - tx_start_ms) {
    Serial.print(F("TX start: "));
    Serial.print(tx_start_ms);
    Serial.print(F(" TX stop: "));
    Serial.println(tx_end_ms);
  }
  if (rx_end_ms - rx_start_ms) {
    Serial.print(F("RX start: "));
    Serial.print(rx_start_ms);
    Serial.print(F(" RX stop: "));
    Serial.println(rx_end_ms);
  }
  if (parse_end_ms - parse_start_ms) {
    Serial.print(F("Parse start: "));
    Serial.print(parse_start_ms);
    Serial.print(F(" Parse stop: "));
    Serial.println(parse_end_ms);
  }
  if (led_end_ms - led_start_ms) {
    Serial.print(F("LED start: "));
    Serial.print(led_start_ms);
    Serial.print(F(" LED stop: "));
    Serial.println(led_end_ms);
  }
  if (export_end_ms - export_start_ms) {
    Serial.print(F("Export start: "));
    Serial.print(export_start_ms);
    Serial.print(F(" Export stop: "));
    Serial.println(export_end_ms);
  }
  if (oled_end_ms - oled_start_ms) {
    Serial.print(F("OLED start: "));
    Serial.print(oled_start_ms);
    Serial.print(F(" OLED stop: "));
    Serial.println(oled_end_ms);
  }
#endif

  // Handle Air Connect
  NMEA_loop();

  ClearExpired();
}

#endif /* EXCLUDE_TEST_MODE */

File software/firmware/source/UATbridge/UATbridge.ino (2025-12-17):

/*
 * UATbridge(.ino) firmware
 * Copyright (C) 2019-2026 Linar Yusupov
 *
 * Author: Linar Yusupov, linar.r.yusupov@gmail.com
 *
 * Web: http://github.com/lyusupov/SoftRF
 *
 *
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
 * You should have received a copy of the GNU General Public License
 * along with this program.  If not, see <http://www.gnu.org/licenses/>.
 */

#include "src/system/SoC.h"
#include "src/system/Time.h"
#include "src/driver/LED.h"
#include "src/driver/GNSS.h"
#include "src/driver/RF.h"
#include "src/driver/EEPROM.h"
#include "src/driver/Baro.h"
#include "src/TrafficHelper.h"
#include "src/driver/Battery.h"

#include "EasyLink.h"
#include "src/protocol/radio/UAT978.h"

#include <uat.h>
#include <fec/char.h>
#include <fec.h>
#include <uat_decode.h>

//#define DEBUG_UAT

#define isValidFix()      isValidGNSSFix()

EasyLink_RxPacket rxPacket;
extern EasyLink myLink;
extern FreqPlan RF_FreqPlan;

ufo_t ThisAircraft;

hardware_info_t hw_info = {
  .model    = DEFAULT_SOFTRF_MODEL,
  .revision = 0,
  .soc      = SOC_NONE,
  .rf       = RF_IC_NONE,
  .gnss     = GNSS_MODULE_NONE,
  .baro     = BARO_MODULE_NONE,
  .display  = DISPLAY_NONE,
  .storage  = STORAGE_NONE,
  .rtc      = RTC_NONE,
  .imu      = IMU_NONE,
  .mag      = MAG_NONE,
  .pmu      = PMU_NONE,
};

#if defined(DEBUG_UAT)
#include <xdc/std.h>

#include <xdc/runtime/System.h>
#include <xdc/runtime/Memory.h>
#include <xdc/runtime/Types.h>

#include <ti/sysbios/BIOS.h>
#include <ti/sysbios/knl/Task.h>
#include <ti/sysbios/utils/Load.h>
#include <ti/sysbios/hal/Hwi.h>

static void printUtilization()
{
    xdc_UInt i;
    Memory_Stats memStat;
    Hwi_StackInfo hwiStackStat;
    Load_Stat loadStat;
    Task_Handle tsk;
    float idleLoad;
    uint32_t idleLoadInt, idleLoadFrac;

    /* collect current stats */
    Load_update();

    /* use time NOT spent in idle task for Total CPU Load */
    Load_getTaskLoad(Task_getIdleTask(), &loadStat);
    idleLoad = 100.0 - 100.0*(float)loadStat.threadTime/(float)loadStat.totalTime;
    idleLoadInt = idleLoad;
    idleLoadFrac = 10.0*idleLoad - 10.0*idleLoadInt;

    Serial.write("Total CPU Load: ");
    Serial.print(idleLoadInt);
    Serial.print(".");
    Serial.println(idleLoadFrac);
    Serial.println("");
#if 0
    /* collect stats on all statically Created tasks */
    Serial.println("Task info:");
    for (i = 0; i < Task_Object_count(); i++) {
        tsk = Task_Object_get(NULL, i);
        printTaskInfo(tsk);
    }

    /* collect stats on all dynamically Created tasks */
    tsk = Task_Object_first();
    while (tsk) {
        printTaskInfo(tsk);
        tsk = Task_Object_next(tsk);
    }
    Serial.println("");
#endif
    Hwi_getStackInfo(&hwiStackStat, TRUE);
    Serial.print(F("Hwi stack usage: "));
    Serial.print(hwiStackStat.hwiStackPeak);
    Serial.print("/");
    Serial.println(hwiStackStat.hwiStackSize);
    Serial.println("");

    Memory_getStats(NULL, &memStat);
    Serial.print(F("Heap usage: "));
    Serial.print(memStat.totalSize - memStat.totalFreeSize);
    Serial.print("/");
    Serial.println(memStat.totalSize);
}
#endif /* DEBUG_UAT */

static bool UAT_Receive_Sync()
{
  // rxTimeout is in Radio time and needs to be converted from miliseconds to Radio Time
  rxPacket.rxTimeout = EasyLink_ms_To_RadioTime(2000);

  // Turn the receiver on immediately
  rxPacket.absTime = EasyLink_ms_To_RadioTime(0);

  EasyLink_Status status = myLink.receive(&rxPacket);

  if (status == EasyLink_Status_Success) {

#if defined(DEBUG_UAT)
    Serial.print("Packet received with length ");
    Serial.print(rxPacket.len);
    Serial.print(" RSSI ");
    Serial.print(rxPacket.rssi);
#if 0
    Serial.println(" and value:");
    Serial.println(Bin2Hex((byte *) rxPacket.payload, rxPacket.len));
#else
    Serial.println();
#endif
#endif

    rx_packets_counter++;

    return(true);
  } else {
#if defined(DEBUG_UAT)
    Serial.print("Error receiving packet with status code: ");
    Serial.print(status);
    Serial.print(" (");
    Serial.print(myLink.getStatusString(status));
    Serial.println(")");
#endif
    return(false);
  }
}

static bool UAT_receive_complete  = false;
static bool UAT_receive_active    = false;

void UAT_Receive_callback(EasyLink_RxPacket *rxPacket_ptr, EasyLink_Status status)
{
  UAT_receive_active = false;

  if (status == EasyLink_Status_Success) {
    memcpy(&rxPacket, rxPacket_ptr, sizeof(rxPacket));
    UAT_receive_complete  = true;
  }
}

static bool UAT_Receive_Async()
{
  bool success = false;
  EasyLink_Status status;

  if (!UAT_receive_active) {
    status = myLink.begin(EasyLink_Phy_Custom);

#if defined(DEBUG_UAT)
    if (status != EasyLink_Status_Success) {
      Serial.println(F("myLink.begin(EasyLink_Phy_Custom) failure."));
    }
#endif

    status = myLink.receive(&UAT_Receive_callback);

    if (status == EasyLink_Status_Success) {
      UAT_receive_active = true;
    }
  }

  if (UAT_receive_complete == true) {

    success = true;
    UAT_receive_complete = false;

    rx_packets_counter++;
  }

  return success;
}

#define UAT_Receive UAT_Receive_Async

void setup() {
  hw_info.soc = SoC_setup(); // Has to be very first procedure in the execution order

  Serial.begin(STD_OUT_BR, SERIAL_OUT_BITS);

  Serial.println();
  Serial.print(F(SOFTRF_IDENT "-"));
  Serial.print(SoC->name);
  Serial.print(F(" FW.REV: " SOFTRF_FIRMWARE_VERSION " DEV.ID: "));
  Serial.println(String(SoC->getChipId(), HEX));
  Serial.println(F("Copyright (C) 2015-2026 Linar Yusupov. All rights reserved."));
  Serial.flush();

  EEPROM_setup();

  settings->mode = SOFTRF_MODE_BRIDGE;

  SoC->Button_setup();

  ThisAircraft.addr = SoC->getChipId() & 0x00FFFFFF;

  hw_info.display = SoC->Display_setup();

  hw_info.rf = RF_setup();

#if defined(DEBUG_UAT)
  Serial.print(F("SPI radio ID: "));
  Serial.println(hw_info.rf);
#endif

  if ( hw_info.rf != RF_IC_CC13XX ||
      (hw_info.rf == RF_IC_CC13XX && settings->rf_protocol != RF_PROTOCOL_ADSB_UAT)) {
    init_fec();
  }

  hw_info.gnss = GNSS_setup();

  Serial.print(F("Protocol: "));
  Serial.println(
    settings->rf_protocol == RF_PROTOCOL_LEGACY ? legacy_proto_desc.name :
    settings->rf_protocol == RF_PROTOCOL_OGNTP  ? ogntp_proto_desc.name  :
    settings->rf_protocol == RF_PROTOCOL_P3I    ? p3i_proto_desc.name    :
    settings->rf_protocol == RF_PROTOCOL_FANET  ? fanet_proto_desc.name  :
    "UNK"
  );

  Serial.print(F("GNSS: "));
  Serial.println(GNSS_name[hw_info.gnss]);

  Battery_setup();

  LED_setup();

  /*
   * Display 'U' (UAT) on OLED for Rx only modes.
   * Indicate Tx protocol otherwise
   */
  ThisAircraft.protocol = settings->rf_protocol;

  Serial.print(hw_info.rf == RF_IC_CC13XX ? F("Single") : F("Dual"));
  Serial.println(F(" radio bridge mode."));

  RF_loop();

  Serial.println(F("Listening..."));

  SoC->post_init();

  SoC->WDT_setup();
}
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

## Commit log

2022-10-08 ESP32 and nRF52: avoid to transmit empty data packets over Bluetooth LE
2022-10-10 WLE5: enable STM32 SUBGHZ HAL in Actions CI build [skip ci]
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2022-10-19 ESP32-S3: IMU (over SPI) probing sequence [skip ci]
2022-10-20 ESP32-S3: update of IMU probing logic [skip ci]
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2022-10-22 mention STM32WLE5 support on the front page [skip ci]
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2022-10-24 WebUI: ESP32-Sx USB data output options [skip ci]
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2022-10-26 ESP32-S3: OLED display splash screen fix [skip ci]
2022-10-27 WLE5: support for RFO_LP use case [skip ci]
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2022-11-02 ESP32: compute maximum sketch space applicable for Wi-Fi OTA firmware upgrade [skip ci]
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2022-11-04 SoftRF Release 1.2 firmware binaries for ESP32, nRF52840 and CC1352R [skip ci]
2022-11-14 ESP32-S3: 32768 Hz XTAL RTC init procedure by Lewis [skip ci]
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2022-11-18 expand 'G load' OLED display feature on ADXL362 (SensorTag) and QMI8658 (T-Beam) target hardware [skip ci]
2022-11-19 CC13x2: make use of new ADXL362 library [skip ci]
    [SoftRF.ino]
2022-11-25 WebTop USB: add support for FT232, CP210X and CH340 Setial-to-USB adapters [skip ci]
    [Platform_ESP32.cpp]
2022-11-25 a copy of USB Host function from WebTop (ESP32-S2) to Prime Mk3 (ESP32-S3) [skip ci]
    [Platform_ESP32.cpp, SoftRF.ino]
2022-11-28 misc. update of 'firmware binaries' page [skip ci]
    [Platform_ESP32.cpp]
2022-12-02 WebTop: misc. USB scan cleanup [skip ci]
    [Platform_ESP32.cpp]
2022-12-02 ESP32-S3 Host: show connection status of a USB device in WebUI [skip ci]
    [Platform_ESP32.cpp]
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2022-12-05 WebTop: split of ESP32 SoC Ids [skip ci]
    [Platform_ESP32.cpp, WebHelper.cpp]
2022-12-19 (inactive) RF Tx power limiter for wearable models [skip ci]
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2023-01-28 SX1262: trade of 2mA increase of Rx active current for 3dB increase in sensitivity [skip ci]
2023-01-30 Prime Mk3: use BOOT (GPIO0) button to flip traffic info pages [skip ci]
2023-01-30 Prime Mk2 and Mk3: suppress numerous GSA sentences output unless 'NMEA TCP' setting (SkyDemon use case) is selected [skip ci]
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2023-01-31 show current and total traffic counters on OLED 'text' page [skip ci]
2023-02-03 ESP32-S3: binaries of the TinyUF2 bootloader for new LilyGO T-Beam [skip ci]
2023-02-04 SoftRF firmware binary in UF2 format for ESP32-S3 target(s) [skip ci]
2023-02-09 SoftRF: boot sequence is doing good on ESP32-C3 (RISC-V) target [skip ci]
2023-02-09 ESP32-C3 upgrade for Standalone Edition: bringup of Wi-Fi, GNSS, SX12xx radio, BMP280 sensor, LED ring, buzzer and BLE is complete
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2023-02-16 push Standalone ESP32-C3 upgrade page up on top [skip ci]
2023-02-17 ESP32-C3: brought nRF905 radio back on [skip ci]
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2023-02-23 a fix for #139 [skip ci]
    [View_Text_EPD.cpp]
2023-02-28 ESP32-S3: RTC probing is compatible with HYM8563 [skip ci]
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2023-03-11 bringup of SkyView on ESP32-C3 target is complete [skip ci]
    [EEPROMHelper.cpp, Platform_ESP32.cpp, Platform_ESP32.h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]
2023-03-11 bringup of SkyView on RP2040 target is complete [skip ci]
    [EEPROMHelper.cpp, SkyView.h]
2023-03-13 SkyView: misc. RP2040 port cleanup [skip ci]
    [SkyView.h]
2023-03-14 SkyView: RPi CI build fix
    [Platform_RPi.cpp]
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2023-03-17 RP2040: PIO USB CDC Host function for SkyView [skip ci]
    [EEPROMHelper.cpp, GDL90Helper.cpp, NMEAHelper.cpp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]
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2023-03-24 RP2040: misc. update of SkyView WebUI [skip ci]
    [WebHelper.cpp]
2023-03-25 further cleanup of SkyView for RP2040 [skip ci]
    [SkyView.ino, SoftRF.ino, WebHelper.cpp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]
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2023-03-27 SkyView: screen rotation feature [skip ci]
    [EEPROMHelper.cpp, WebHelper.cpp]
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2023-03-28 SkyView EZ: swap Up and Down buttons when screen is rotated at 180 degrees
    [Platform_ESP32.cpp, WiFiHelper.cpp]
2023-03-28 fix against regression of ESP8266 build
    [WiFiHelper.cpp]
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2023-03-31 RP2040: Bluetooth SPP data routing on Pico W [skip ci]
    [WiFiHelper.cpp]
2023-04-01 RP2040: misc. improvements and fixes
    [BluetoothHelper.cpp, EEPROMHelper.cpp, WebHelper.cpp]
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2023-04-03 RP2040: UDP transmit logic [skip ci]
    [WiFiHelper.cpp]
2023-04-04 bringup of WebTop on Pico W [skip ci]
    [BluetoothHelper.cpp, SkyWatch.ino, WebHelper.cpp]
2023-04-05 Prime3: flip OLED screen over upon power up (or reset) when device is upside down. Use of built-in IMU to trigger this event.
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2023-04-07 Wi-Fi STA: fix against regression of proper hostname setting on ESP32-XX platform [skip ci]
    [WiFiHelper.cpp]
2023-04-10 shorten ESP32 BLE 'firmware id' string [skip ci]
2023-04-10 activate OLED 'text' page for SensorTag taarget [skip ci]
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2023-04-11 SoftRF Release 1.3 firmware binaries for ESP32, ESP32-S3, nRF52840, S76G and CC1352R [skip ci]
2023-04-12 SoftRF Release 1.3 firmware binaries for ESP32-C3, ESP8266 and ASR650x [skip ci]
2023-04-13 SoftRF Release 1.3 firmware binaries for RP2040 and STM32WLE5 [skip ci]
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2023-04-18 RP2040: update of Bluetooth SPP driver [skip ci]
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2023-04-25 postpone micro-SD FAT filesystem mount until first actual use [skip ci]
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2023-05-01 RP2040: HM-10 compatible Bluetooth LE 'peripheral' role for Pico W [skip ci]
2023-05-01 RP2040: HM-10 compatible Bluetooth LE 'central' role for SkyView Pico [skip ci]
    [BluetoothHelper.cpp, WebHelper.cpp]
2023-05-02 SkyView Pico BLE 'central': validated with genuine HM-10 module as well [skip ci]
    [BluetoothHelper.cpp]
2023-05-02 RP2040: use 16 bit BLE UUIDs like genuine HM-10 does [skip ci]
    [BluetoothHelper.cpp]
2023-05-03 RP2040: filter out unwanted empty BLE frames [skip ci]
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2023-05-05 an illustration for SkyView Pico wiki [skip ci]
    [SkyView.h]
2023-05-05 SkyView Pi: support for Waveshare 2.7 inch e-Paper HAT V2 adapter (uses GDEY027T91 display) [skip ci]
    [Platform_RPi.cpp]
2023-05-06 RP2040: Bluetooth SPP 'master' - 'connect by name' method [skip ci]
    [BluetoothHelper.cpp]
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2023-05-08 RP2040: made SkyView Pico compatible with HC-05 BT SPP data source [skip ci]
    [BluetoothHelper.cpp]
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2023-05-12 SkyView Pico: fix for EPD detect logic [skip ci]
2023-05-12 SkyView EZ: update of EPD detect logic [skip ci]
    [Platform_ESP32.cpp]
2023-05-12 SkyView: print version number on boot screen [skip ci]
    [Platform_ESP32.cpp]
2023-05-13 RP2040: report battery charge level over BLE [skip ci]
2023-05-13 SkyView Pico: support for Waveshare UPS-B voltage monitor [skip ci]
2023-05-15 ESP32: use of 16-bit HM-10 BLE UUIDs [skip ci]
    [BluetoothHelper.cpp]
2023-05-17 SkyView: BPI-PicoW-S3 pins mapping [skip ci]
    [EEPROMHelper.cpp, Platform_ESP32.cpp, Platform_ESP32.h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]
2023-05-17 bringup of SkyView on ESP32-S3 target is complete [skip ci]
    [Platform_ESP32.cpp, Platform_ESP32.h]
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2023-05-18 SkyView for ESP32-S3: buttons assignment [skip ci]
    [Platform_ESP32.cpp]
2023-05-18 SkyView on ESP32-S3: support for Waveshare UPS-B voltage monitor [skip ci]
    [Platform_ESP32.cpp]
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2023-05-19 SkyView for ESP32-S3: PDM audio output over I2S0 [skip ci]
    [Platform_ESP32.cpp, Platform_ESP32.h]
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2023-05-22 RP2040: PWM audio output for SkyView Pico [skip ci]
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2023-05-24 SkyView: indicate on e-paper display when battery voltage value is not available [skip ci]
    [BatteryHelper.h, View_Radar_EPD.cpp]
2023-05-24 SkyView Pico: make the V2 version of Waveshare e-Paper Pico adapter to be the default one for RP2040 and ESP32-S3 targets [skip ci]
    [EEPROMHelper.cpp]
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2023-05-25 update of PFLAA 'Aircraft Type' field format after both LK8000 and XCSoar have fixed that issue
    [EEPROMHelper.cpp, NMEAHelper.cpp]
2023-05-27 RP2040: activate Wi-Fi power saving feature for SkyView Pico [skip ci]
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2023-05-29 fix against regression of GitHub Actions CI build for Raspberry Pi (BCM) target
2023-05-30 RP2040: SkyView Pico status LED logic [skip ci]
2023-05-30 ESP32-S3: SkyView Pico status LED logic [skip ci]
    [Platform_ESP32.cpp, Platform_ESP32.h]
2023-05-31 few illustrations for SkyView Pico's wiki [skip ci]
    [Platform_ESP32.h]
2023-06-01 WAV voice files for SkyView Pico [skip ci]
    [Platform_ESP32.h]
2023-06-02 SkyView: print connection settings into boot console [skip ci]
    [Platform_ESP32.cpp]
2023-06-02 ESP32-S3: GDEY027T91 display detect logic [skip ci]
    [Platform_ESP32.cpp]
2023-06-02 ESP32-S3: a workaround for GDEY027T91
    [Platform_ESP32.cpp]
2023-06-05 SkyView: let UART to be default input across all the platforms [skip ci]
    [EEPROMHelper.cpp]
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2023-06-06 RP2040: further cleanup of BT SPP re-connect procedure [skip ci]
    [BluetoothHelper.cpp]
2023-06-06 RP2040: less CYW43 SPI/DMA-intensive AP clients counting [skip ci]
2023-06-07 RP2040: use of Adafruit_TinyUSB_Arduino 2.2.1 in Host mode with CDC, CP210X and FT2XX data source devices [skip ci]
2023-06-07 ESP32-S3: few more SkyView boot log messages [skip ci]
    [Platform_ESP32.cpp]
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2023-06-10 SkyView Pico: misc. cleanup of voice alert feature [skip ci]
    [Platform_ESP32.cpp]
2023-06-12 RP2040: ext. I2S DAC experiments [skip ci]
    [SkyView.ino]
2023-06-15 ESP32-S3: ext. I2S audio DAC function [skip ci]
    [Platform_ESP32.cpp, Platform_ESP32.h]
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2023-07-01 inactivate UC6580 GNSS driver for certain platforms [skip ci]
2023-07-06 ESP32-S3: wake SkyView Pico up by RTC GPIO input signal [skip]
    [Platform_ESP32.cpp, Platform_ESP32.h]
2023-07-07 ESP32-S3: make CS4344 external I2S DAC (Waveshare Pico-Audio Rev. 2.1) to be default one for SkyView Pico[skip ci]
    [Platform_ESP32.h]
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2023-07-18 fix against regression of SkyWatch/WebTop build
    [TFTHelper.cpp]
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2023-07-19 use assigned USB PID for the Midi [skip ci]
2023-07-19 SkyView Pico: remap of 'Mode' button from left to center [skip ci]
    [Platform_ESP32.cpp]
2023-07-20 SkyView Pico: an illustration of Banana board with WaevShare 2.7 inch e-Paper display [skip ci]
    [Platform_ESP32.cpp]
2023-07-24 ESP32: fix for a build with Arduino Core 1.0.5
2023-07-24 ESP32-Sx/C3: transition onto Arduino Core 2.0.11 (2.0.10 was broken)
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2023-08-05 RP2040: Actions CI transition on Arduino Core 3.3.2 [skip ci]
2023-08-07 firmware binaries of SkyView 0.13 for ESP32 targets [skip ci]
2023-08-08 firmware binaries of SkyView 0.13 for ESP32-S3 target [skip ci]
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2023-09-21 SkyView for ESP32 and ESP32-S3: maintenance update of 0.13 firmware binaries [skip ci]
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2023-09-22 ESP32: use explicit max. battery charge current setting for T-Beam v1.2 [skip ci]
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2023-10-06 activate APRS-over-LoRa option for certain STM32 targets [skip ci]
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2023-10-11 fix for ESP32 SQLite3 build failure with Arduino Core 3.0-alpha
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2023-10-12 use of proper UF2 'Family ID' for ESP32-C6 [skip ci]
2023-10-17 Midi: ext. I2C air pressure sensor is doing good [skip ci]
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2023-10-19 more Credits to libraries developers [skip ci]
    [SkyView.ino, SoftRF.ino, WebHelper.cpp]
2023-11-02 WebTop: a copy of UC6580 GNSS driver from SoftRF [skip ci]
    [Platform_ESP32.h]
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2023-11-07 SoftRF Release 1.4 firmware binaries for ESP32, ESP32-S3, nRF52840 and CC1352R [skip ci]
2023-11-08 SoftRF Release 1.4 firmware binaries for RP2040, ESP32-C3, ESP8266 and ASR650x [skip ci]
2023-11-09 SoftRF Release 1.4 firmware binaries for S76G and STM32WLE5 [skip ci]
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2023-12-07 ESP32-S3: work around Linux build issue with AC 3.0-alpha3
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2023-12-14 Ham: a JSON setting to apply R22 ADC workaround to a certain T-TWR V2.0 boards
2024-01-18 Ham: a test for build of SA868 'Open Edition' driver [skip ci]
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2024-01-22 Ham: SA868 radio probing and init with 'Open Edition' driver [skip ci]
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2024-02-02 ESP32-C6: update of the source code build instructions [skip ci]
2024-02-05 use ESP32-C6 package variant info when able [skip ci]
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2024-03-20 RA4M1: bringup of USB CDC, buzzer and (battery voltage) ADC
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2024-04-11 More credits to developers of libraries [skip ci]
    [SoftRF.ino]
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2024-04-12 SoftRF Release 1.5 firmware binaries for ESP32, ESP32-S3 and nRF52840 [skip ci]
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2024-04-12 an attempt to fix ESP32-H2 build with Core 3.0.0-rc1
2024-04-12 an attempt to fix ESP32-Sx build with Core 2.0.15
2024-04-12 2nd attempt to fix ESP32-Sx build with Core 2.0.15
    [Platform_ESP32.cpp]
2024-04-12 3rd attempt to fix ESP32-Sx build with Core 2.0.15
    [Platform_ESP32.cpp]
2024-04-16 SoftRF Release 1.5 firmware binaries for STM32WLE5, ESP32-C3, ESP8266 and ASR650x [skip ci]
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2024-04-18 WebTop: update for 'white list' of USB VIDs and PIDs [skip ci]
    [Platform_ESP32.cpp]
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2024-05-08 apply FANET settings to RadioLib driver [skip ci]
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2024-05-20 Current state is good enough to qualify it as Maintenance Update 1.5.1 [skip ci]
2024-05-20 Maintenance Update 1.5.1 firmware binaries for ESP32, ESP32-S3, S76G and nRF52840 [skip ci]
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2024-05-24 [nRF52] add support for ICM-20948 IMU sensor [skip ci]
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2024-05-31 [ESP32-S3] LilyGO T3-S3-EPD board pins map [skip ci]
    [BluetoothHelper.cpp]
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2024-06-04 [nRF52] update of ICM-20948 IMU sensor init logic [skip ci]
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2024-06-07 [ESP32-S3] build of audio component with Core 3.0.x [skip ci]
    [Platform_ESP32.h]
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2024-06-28 LilyGO T3-C6 GPIOs are sorted out by pin headers [skip ci]
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2024-07-25 a build trigger of BME280 sensor as an auxiliary for BHI260AP hub driver [skip ci]
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2024-10-11 [CH32] one more VID/PID pair for WebTop USB [skip ci]
    [Platform_ESP32.cpp]
2024-10-14 [nRF52] AG3335, LR1110, battery voltage ADC, LED, button (sleep/wakeup) and buzzer in the Card Edition are doing Ok
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2024-10-16 select default aircraft type for Card [skip ci]
    [SoftRF.ino]
2024-10-21 [AG3335] leave RTC voltage in ON state while in sleep to speed up further TTFF [skip ci]
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2024-10-21 an attempt to fix ESP32-C6 build
    [Platform_ESP32.cpp]
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2024-11-13 more Credits to developers of Cores and Libraries [skip ci]
    [SoftRF.ino]
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2024-11-14 SoftRF Release 1.6 firmware binaries for ESP32, ESP32-S3 and nRF52840 [skip ci]
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2024-11-21 SoftRF Release 1.6 firmware binaries for RP2040, ESP32-C3 and ESP32-C6 [skip ci]
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2025-01-22 a fix for build of Pico-PIO-USB library with Pico SDK 2
    [Platform_RP2XXX.h]
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2025-01-22 [RP2350] change for name suffix of some WebTop's platform dependent files [skip ci]
    [Platform_RP2XXX.cpp, Platform_RP2XXX.h]
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2025-03-14 [RP2XXX] pinmap of Pico W / 2W adapter to Standalone Edition [skip ci]
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2025-03-18 [ESP32-S3] a fix against regression of RGB LED color on Ham Edition
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2025-04-07 [RP2350] release 0.14 of SkyView firmware binaries for Pico 2W with Waveshare e-Paper 2.7 adapter [skip ci]
    [SkyView.h]
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2025-04-09 SoftRF Release 1.7 firmware binaries for ESP32, ESP32-S3, CC1352R and nRF52840 [skip ci]
2025-04-11 SoftRF Release 1.7 firmware binaries for RP2350, CH32V307, ESP32-C3 and ESP32-C6 targets [skip ci]
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2025-04-22 add RadioHead 1.143 library [skip ci]
    [SoftRF.ino]
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2025-04-24 [ESP32-C6] build SkyView with NimBLE 2.x [skip ci]
    [BluetoothHelper.cpp]
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2025-04-30 one more VID/PID pair for WebTop USB [skip ci]
    [Platform_ESP32.cpp, SkyView.h]
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2025-05-16 [RP2350] update of SoftRF firmware build instructions for Pico 2W [skip ci]
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2025-06-02 [nRF53] a method to identify target board by bootloader's signature [skip ci]
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2025-06-11 Current state is good enough to qualify it as Maintenance Update 1.7.1 [skip ci]
2025-06-11 Maintenance Update 1.7.1 firmware binaries for ESP32-S3, ESP32-C3 and nRF52840 [skip ci]
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2025-06-20 [ESP32-P4] specify JEDEC ID of built-in 16 MB flash memory [skip ci]
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2025-06-25 [ESP32-P4] add an I/O map for SkyView [skip ci]
    [Platform_ESP32.h]
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2025-07-08 [RPi] a test of driver for WS281X RGB LED (NeoPixel) ring in use by Standalone Edition [skip ci]
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2025-07-11 [ESP32-P4] add an I/O map for Waveshare SX1262-L76K HAT with Espressif EVB [skip ci]
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2025-07-15 [RK35] bring up of Luckfox Lyra together with adapter to Standalone Edition - WebUI, SPI radio, IIC air pressure sensor and PWM buzzer are doing good [skip ci]
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2025-08-18 [ESP32-P4] an update of I/O map for SkyView [skip ci]
    [Platform_ESP32.h, SkyView.h]
2025-08-19 [ESP32-P4] an update of SkyView build infra [skip ci]
    [EEPROMHelper.cpp, EthernetHelper.cpp, Platform_ESP32.cpp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]
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2025-08-22 a fix for #190 [skip ci]
    [WebHelper.cpp]
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2025-08-25 [ESP32-C5] bring up of WebTop on C5 dev. kit [skip ci]
    [Platform_ESP32.h]
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2025-09-01 [ESP32-S3] play a short melody with Airventure Edition at very first GNSS fix
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2025-09-10 an update of RadioLib [skip ci]
    [WebHelper.cpp]
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2025-10-10 [ESP32-P4] bring up of MIPI DSI [skip ci]
    [Platform_ESP32.cpp]
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2025-10-20 [nRF52] add an I/O map for M3 [skip ci]
    [TFTHelper.cpp]
2025-10-20 [ESP32-P4] build with proto of gesture events handler [skip ci]
    [TFTHelper.cpp]
2025-10-20 [ESP32-P4] add build infra for SkyView 'radar screen' [skip ci]
    [TFTHelper.cpp]
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2025-10-29 [ESP32-P4] more of LVGL stuff [skip ci]
    [TFTHelper.cpp]
2025-10-30 [nRF52] use of M3 specific value for battery voltage multiplier [skip ci]
2025-10-30 [nRF52] add definition for a couple of T-Echo Plus specific GPIO pins [skip ci]
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2025-11-04 [ESP32-P4] add I/O pins map assigned to SX1262 radio in recent 7.0 inch CrowPanel [skip ci]
2025-11-04 [ESP32-P4] add TFT and AMOLED display profiles for LilyGO T-Display-P4 [skip ci]
    [Platform_ESP32.cpp, Platform_ESP32.h]
2025-11-05 [ESP32-P4] apply own display profile to each board [skip ci]
    [Platform_ESP32.cpp, Platform_ESP32.h]
2025-11-05 [ESP32-P4] some of board specific actions have been sorted out [skip ci]
    [Platform_ESP32.cpp, Platform_ESP32.h]
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2025-11-12 [ESP32-P4] add some build infra for USB Host feature [skip ci]
    [Platform_ESP32.cpp, Platform_ESP32.h]
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2025-11-14 [nRF52] an update of M3 RF switch logic [skip ci]
    [Platform_ESP32.cpp]
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2025-11-24 add few illustrations for the Badge wiki [skip ci]
    [Platform_ESP32.cpp]
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2025-11-25 [ESP32-P4] apply a filter for LVGL v8 API [skip ci]
    [Platform_ESP32.cpp, TFTHelper.cpp]
2025-11-27 [nRF52] include Ti DRV2605 ERM/LRA haptic driver activation into POST of T-Echo Plus [skip ci]
2025-11-28 [nRF52] prevent millis() rollover in a long term run for Solaris Edition [skip ci]
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2025-12-02 [ESP32-C3] get rid of some useless debug in UAV (MAVLINK V1) mode [skip ci]
2025-12-03 [LR1121] an update of RF switch table for Nano Edition [skip ci]
2025-12-04 [ESP32-P4] start to fill Mode-S ring buffer when a reader is ready [skip ci]
    [Platform_ESP32.cpp]
2025-12-08 [nRF52] fix against regression of build with Arduino Core for Zephyr OS
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2025-12-10 [STM32WL55] blink with red LED on every RF packet transmit [skip ci]
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2025-12-11 [STM32WL55] add an illustration for the Wiki [skip ci]
    [SkyView.h]
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2025-12-16 Current state is good enough to qualify it as Release 1.8 [skip ci]
2025-12-16 SoftRF Release 1.8 firmware binaries for ESP32, ESP32-S3, ESP32-C3, CC1352R, nRF52840, ASR650x, S76G, STM32WLE5 and STM32WL55 [skip ci]
2025-12-17 Copyright extension onto year 2026 [skip ci]
    [BaroHelper.cpp, BatteryHelper.h, BluetoothHelper.cpp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]
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2026-01-06 [WebTop] add two more of aircraft types [skip ci]
    [WebHelper.cpp]
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2026-01-28 [ESP32-P4] an update of SkyView I/O map [skip ci]
    [Platform_ESP32.cpp, Platform_ESP32.h]
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2026-02-04 [ESP32-P4] T-Display-P4 power circuits have been sorted out [skip ci]
    [Platform_ESP32.cpp]
2026-02-04 [ESP32-P4] bring up of SkyView on LilyGO T-Display-P4 [skip ci]
    [EEPROMHelper.cpp, Platform_ESP32.cpp, WebHelper.cpp]
2026-02-05 [ESP32-P4] bring up of MIPI DSI display on LilyGO T-Display-P4 [skip ci]
    [Platform_ESP32.cpp, TFTHelper.cpp]
2026-02-05 [ESP32-P4] permit use of DSI display sizes other than 7 inch [skip ci]
    [Platform_ESP32.cpp, TFTHelper.cpp]
2026-02-06 [LR2021] apply PPM (OOK) signal detection threshold [skip ci]
    [Platform_ESP32.cpp, WebHelper.cpp]
2026-02-07 an update of SkyView hardware info structure [skip ci]
    [BatteryHelper.h, Platform_ESP32.cpp, Platform_ESP32.h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]
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2026-02-09 [ESP32-P4] migrate screen layout from landscape to portrait [skip ci]
    [TFTHelper.cpp]
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2026-02-12 [ESP32-P4] an update of 4.1 inch AMOLED display descriptor [skip ci]
    [Platform_ESP32.cpp]
2026-02-12 [ESP32-P4] activate I2S audio playback on LilyGO T-Display-P4 @ POST sequence [skip ci]
2026-02-13 [ESP32-P4] flip DSI screen page on BOOT button press [skip ci]
    [Platform_ESP32.cpp]
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2026-04-20 an update of SensorLib library with a driver for QMC6309H [skip ci]
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2026-04-23 [ESP32-P4] bring up of voice traffic alert feature with Concorder Edition [skip ci]
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2026-04-28 [ESP32-P4] use of Concorde Edition with High-Speed USB RTL-SDR dongle as 1090 MHz ADS-B traffic receiver [skip ci]
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2026-04-30 [nRF54] add flush of UART Tx buffer to expedite output of u-blox GNSS control sentence [skip ci]
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2026-05-06 [ESP32-P4] sync up WebTop and SkyView with SoftRF [skip ci]
    [Platform_ESP32.cpp]
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2026-05-07 Current state is good enough to qualify it as Release 1.9 [skip ci]
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2026-05-08 SoftRF Release 1.9 firmware binaries for ESP32, ESP32-C3 and ESP8266 [skip ci]
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2026-05-13 SoftRF Release 1.9 firmware binaries for RP2040, STM32 WL55 and WLE5 [skip ci]
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2026-05-25 [ESP32-S3] 5th attempt to fix build with Core 3.3.8
    [Platform_ESP32.h]
2026-05-25 [ESP32-S3] 6th attempt to fix build with Core 3.3.8
    [Platform_ESP32.cpp, Platform_ESP32.h]
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2026-06-16 [ESP32-S3] add an I/O map for Lierda AM36 PK02 DK [skip ci]
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2026-06-23 [STM32] fix IIC de-init loop in SoC->fini() with Retro Mk.II [skip ci]
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2026-06-26 Current state is good enough to qualify it as Maintenance Update 1.9.1 [skip ci]
2026-06-26 Maintenance Update 1.9.1 firmware binary for STM32F103 ( Ebyte E80-900MBL-02 ) [skip ci]
2026-06-27 [LR2021] add DIO and RF switch logic for Nano Edition Mk.II [skip ci]
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2026-07-02 [WebTop] D1090 data I/O. Proper UDP transmit (port 47909) has been verified by ADSB Receiver app for Android [skip ci]
    [D1090Helper.cpp]
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2026-07-06 add I/O maps for Heltec T1 and RC32 [skip ci]
    [D1090Helper.cpp, NMEAHelper.cpp, WebHelper.cpp]
2026-07-07 [nRF52] add descriptor for Zetta Device ZD25WQ32C QSPI flash [skip ci]
    [D1090Helper.cpp]
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2026-07-09 sync-up some of WebTop logic with SoftRF one [skip ci]
    [Platform_ESP32.cpp]
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2026-07-13 [WebTop] data transit of ForeFlight GDL90 ID (0x65) message [skip ci]
    [GDL90Helper.cpp]
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2026-07-15 [STM32] increase UART Tx buffer size for better match with MAX_TRACKING_OBJECTS value and NMEA / GDL90 / D1090 message size [skip ci]
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2026-07-20 [nRF52] a fix against regression of T1000-E IMU sensor detect logic [skip ci]
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2026-07-28 [nRF52] re-assign T-Impulse Plus user input sensing from button to touch [skip ci]
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2026-07-31 [nRF52] add Adafruit LIS3DH library [skip ci]
    [SoftRF.ino]
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2026-08-07 [nRF52] an update of power init logic for TEC, TIP and X1 [skip ci]
2026-08-08 [LR2021] add an RF switch map for LilyGO module V0.3 [skip ci]
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2026-08-13 [nRF52] bring up of SPA06 air pressure sensor in Seeed X1 [skip ci]
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2026-08-17 [LR2021] an update of RF switch table for LilyGO T-Display P4 [skip ci]
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2026-08-20 [nRF52] give 30 ms delay for 3.3V power supply circuit of X1 to settle down [skip ci]
2026-08-21 Current state is good enough to qualify it as Maintenance Update 1.9.2 [skip ci]
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2026-09-07 [ESP32-P4] reduce memory space allocated by camera module when able [skip ci]
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2026-09-25 [ESP32] permit build of LR2021 radio driver fot upgraded T-Beam Classic target [skip ci]
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2026-10-06 an update of RF switch table for T-LR2021 V0.3 radio module [skip ci]
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2026-10-08 [ESP32] add illustrations for Prime Mk.2 upgrade with lilyGO T-LR2021 radio module [skip ci]
2026-10-08 Current state is good enough to qualify it as Maintenance Update 1.9.4 [skip ci]
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2026-10-12 [ESP32-S3] an update of Elecrow M5 I/O map with data specific to V2 variant of the device [skip ci]
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2026-10-13 [ESP32-S3] add GNSS PPS signal processing logic for M5 V2 [skip ci]
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2026-10-16 [ESP32-P4] an update of I/O map for LilyGO T-Display P4 [skip ci]
2026-10-17 [ESP32-P4] a test of external radio module connected to T-Display P4 [skip ci]
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2026-10-20 [ESP32-P4] one more update of I/O map for LilyGO T-Display P4 [skip ci]
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2026-10-24 [RP2XX0] a fix for SkyView and WebTop builds with Pico Core 6.3.1
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2026-10-31 [nRF52] an update of mode button assignment for Card Edition Mark II [skip ci]
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2026-11-03 [ESP32] a fix against build regression for C5, C6, H2 and P4 targets
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2026-11-07 [ESP32-S3] turn on T-Beam 1W cooling fan when radio temperature exceeds 50 degrees of Celsius [skip ci]
